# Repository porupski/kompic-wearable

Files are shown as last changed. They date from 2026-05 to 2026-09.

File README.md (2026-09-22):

# Kompic̄ &nbsp;·&nbsp; Mk1b

**Compact Open Multisensor Platform & Apparatus**

*/ˈkompitɕ/* — Croatian for "little computer" (and the word you'd only use for an actual friend, not a stranger).

A fully open-source, offline-first, ML-capable wrist-mounted sensor platform. The hardware collects. The firmware infers. You own everything.

> **Internal hardware version:** `iv8.0` — tracked in the docs to keep the PCBs matched across revisions.

Page: [https://porupski.github.io/kompic-wearable/](https://porupski.github.io/kompic-wearable/)

---

## What it is

Kompic̄ is a wrist-mounted sensor platform built around an **ESP32-S3** (dual-core, 8 MB PSRAM, 16 MB flash) with a sensor suite denser than any open-source watch, and enough on-device compute to run real neural networks on that data — sleep staging, sound classification, sensor fusion — all locally, all offline, all inspectable.

Currently on its second hardware revision, **Mk1b (`iv8.0`)**: all ten I²C sensors bring up clean, the AMOLED display and touch panel run a working LVGL interface, and GPS streams live fixes.

It is **not** a companion in the AI sense and **not** a phone accessory. It runs standalone. BLE is a capability, not a requirement. There is no cloud, no subscription, no account.

### Philosophy

- **Open source** — hardware (KiCad), firmware, ML models, and case design. Everything inspectable, modifiable, forkable.
- **Offline first** — works fully standalone. No phone, no cloud, no subscription.
- **Raw data access** — PPG waveforms, IMU streams, mic audio, environmental readings. Not just processed metrics.
- **ML-native** — the compute surplus exists specifically to run on-device inference.

---

## Hardware at a glance

| Domain | Detail |
|---|---|
| MCU | ESP32-S3 dual-core Xtensa LX7 @ 240 MHz, 8 MB PSRAM, 16 MB flash |
| Storage | MicroSD (128 GB+) |
| Connectivity | BLE 5.x |
| Display | 2.06" rectangular AMOLED, 45.6 × 37.3 mm glass, QSPI |
| PCBs | Two 1.0 mm 4-layer boards: main board + skin-facing daughter board |
| Case | Two-piece SLM titanium (Ti-6Al-4V), ~48 × 40 × 12 mm |
| Weight | 33 g watch body, 56 g with straps |
| Power | ~300 mAh LiPo, USB-C charging, fuel gauge |

### Sensor suite

| Sensor | Part | Measures |
|---|---|---|
| ❤️ Optical HR / SpO2 | MAX30101 | Heart rate, HRV, blood oxygen, PPG waveforms |
| 🏃 IMU | LSM6DSV16X | Accel, gyro, on-chip decision trees |
| 🔋 Fuel gauge | MAX17048G | Battery state-of-charge, cell voltage |
| 🌡️ Skin temperature | TMP117 | High-precision skin temp trending |
| 🧭 Magnetometer | LIS3MDLTR | Compass heading, magnetic anomaly |
| 🛰️ GPS | u-blox M10S | Position, velocity, atomic time sync |
| 🌍 Environmental | BME688 | Temp, pressure, humidity, VOC / air quality |
| 💡 Ambient light | VEML6030 | Lux level, display brightness |
| 🎤 MEMS microphone | MSM261DGT003 | Audio capture, noise level, sound classification |
| 📳 Haptics | ELV1411A + DRV2605L | Vibration patterns, alerts, smart wake |
| 🔦 Flashlight | White LED + BC847C driver | Utility light |
| 🚦 Status LED | RGB LED | Notification / mode indicator |

---

## Repository layout

```

kompic-wearable/
├── hardware/    KiCad schematics, PCB layout, production files   [CERN-OHL-S v2]
├── firmware/    ESP32-S3 dual-core firmware, ML models           [GPLv3]
├── case/        Onshape / 3D-printable case models               [CC BY-SA 4.0]
└── docs/        Documentation site (GitHub Pages) + images       [CC BY-SA 4.0]

```

---

## Project status

In active development. Hardware bring-up and verification underway for **Mk1b (`iv8.0`)**.

| Area | Status |
|---|---|
| Circuit + PCB | Mk1 done (schematics, power tree, KiCad source) - needs update to Mk1b |
| Fabrication + assembly | Mk1 done (JLCPCB process, BOM, production files) - needs update to Mk1b |
| Manual assembly | Planned |
| 3D models + case | Planned ([View on Onshape](https://cad.onshape.com/documents/2e7ed980a6b60d585006763f/w/61a5aff226ec4b8dea793e41/e/49d622626b42dd5951f83a04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)) |
| Firmware | In progress (I²C drivers, LVGL 9 display + touch UI, GPS UBX/NMEA parsing) |

Check the Development page for info on current stage of the project.

Documentation: **[https://porupski.github.io/kompic-wearable/](https://porupski.github.io/kompic-wearable/)**

---

## Author & License

Hardware, firmware, case, and webpage design by **Ivan Porupski**, 2026.

## License

Kompic̄ is released under three copyleft licenses, one per kind of material. All three keep the project open and require attribution — anyone may use, modify, build on, and even sell derivatives, **provided they keep their version equally open and credit the original author.**

| Part of the project | License | What it means in one line |
|---|---|---|
| **Hardware** (`/hardware`) | [CERN-OHL-S v2](https://ohwr.org/cern_ohl_s_v2.txt) | Make/modify/sell boards freely; distributed modifications must publish their full design files under the same license. |
| **Firmware** (`/firmware`) | [GPLv3](https://www.gnu.org/licenses/gpl-3.0.html) | Run/modify/redistribute freely; distributed modifications must publish full source under GPLv3. |
| **Docs & 3D / case** (`/docs`, `/case`) | [CC BY-SA 4.0](https://creativecommons.org/licenses/by-sa/4.0/) | Reuse/remix freely with credit; shared derivatives stay under CC BY-SA. |

GitHub displays **GPL-3.0** as the repository's headline license; the per-folder breakdown above is authoritative. See [`LICENSING.md`](LICENSING.md) for details.

**Copyright © 2026 Ivan Porupski.** Each contributor retains copyright on their own contributions; the whole project remains under the copyleft licenses above.

There is no separate commercial license and no contributor license agreement (CLA). Contributions are accepted under the same licenses as the files they touch (inbound = outbound).

---

## Contributing

Contributions are welcome. By submitting a contribution you agree it is licensed under the same license that already covers the file(s) you are changing (see table above). Keep copyright and license notices intact.

---

## Disclaimer

Kompic̄ is **not a medical device** and is not intended to diagnose, treat, or prevent any condition. All work with these electronics and lithium batteries is done at your own risk. The author and contributors are not liable for any direct, indirect, incidental, or consequential damages.

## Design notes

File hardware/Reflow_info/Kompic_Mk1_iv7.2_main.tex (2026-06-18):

\documentclass[11pt,a4paper]{article}
\usepackage[margin=20mm]{geometry}
\usepackage{graphicx}
\usepackage{booktabs}
\usepackage{array}
\usepackage{xcolor}
\usepackage{colortbl}
\usepackage{enumitem}
\usepackage{fancyhdr}
\usepackage{titlesec}
\usepackage{hyperref}
\usepackage{float}
\usepackage{eurosym}

% Colors
\definecolor{danger}{RGB}{180,30,30}
\definecolor{warning}{RGB}{200,120,0}
\definecolor{safe}{RGB}{30,120,30}
\definecolor{headerblue}{RGB}{30,60,110}
\definecolor{lightgray}{RGB}{240,240,240}
\definecolor{rowalt}{RGB}{248,248,248}

% Header/footer
\pagestyle{fancy}
\fancyhf{}
\fancyhead[L]{\small\textbf{Kompic Mk1 PCB iv7.2 — Reflow \& Assembly Reference}}
\fancyhead[R]{}
\fancyfoot[C]{\thepage}
\renewcommand{\headrulewidth}{0.4pt}

% Section styling
\titleformat{\section}{\Large\bfseries\color{headerblue}}{}{0em}{}[\vspace{-0.5em}\rule{\textwidth}{0.4pt}]
\titleformat{\subsection}{\large\bfseries}{}{0em}{}
\titleformat{\subsubsection}{\normalsize\bfseries}{}{0em}{}

% Danger/warning boxes
\newcommand{\dangerbox}[1]{\par\noindent\colorbox{danger!10}{\parbox{\dimexpr\textwidth-2\fboxsep}{%
\textcolor{danger}{\textbf{WARNING:}} #1}}\par\vspace{0.5em}}

\newcommand{\notebox}[1]{\par\noindent\colorbox{headerblue!8}{\parbox{\dimexpr\textwidth-2\fboxsep}{%
\textcolor{headerblue}{\textbf{NOTE:}} #1}}\par\vspace{0.5em}}

\setlength{\parindent}{0pt}
\setlength{\parskip}{0.4em}

\begin{document}

% ============================================================
% TITLE
% ============================================================
\begin{center}
{\LARGE\bfseries\color{headerblue} Kompic Mk1 PCB — Reflow \& Assembly Reference}\\[0.3em]
{\large by Ivan Porupski, 2026}
\end{center}

% ============================================================
% PAGE 1 — QUICK REFERENCE
% ============================================================
\section*{PAGE 1 — QUICK REFERENCE {\small(keep visible during reflow)}}

\subsection*{Step-by-Step Procedure}

\begin{enumerate}[nosep]
\item Verify baked paste on all pads; smear thin flux (NC-559-ASM) across pad areas — flux QFN/WSON center pads too. For the MEMS mic, flux pads \textbf{before} placing, keep flux out of the top port.
\item Place all ICs and connectors onto flux + baked paste (tweezers, magnification). \textbf{All parts go on now — single reflow pass.}
\item Photograph the populated board; \textbf{attach thermocouple} to board edge with kapton tape.
\item Place board on \textbf{cold} hot plate, run the profile below. Hands off once heating starts; let the cycle finish before handling.
\end{enumerate}

\subsubsection*{Reflow Profile}

\begin{figure}[H]
\centering
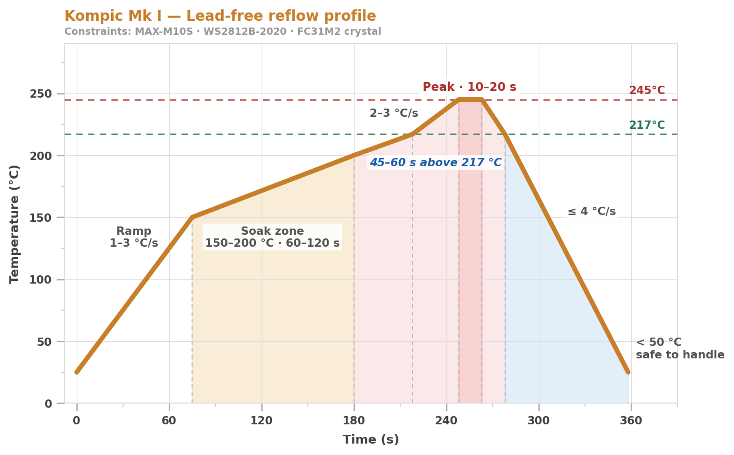
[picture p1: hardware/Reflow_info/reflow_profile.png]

\caption{\small Target reflow profile — binding constraints from MAX-M10S, WS2812B-2020, FC31M2 crystal.}
\end{figure}

\vspace{-0.5em}
\begin{table}[H]
\centering
\begin{tabular}{@{}ll@{}}
\toprule
\textbf{Phase} & \textbf{Target} \\
\midrule
Ramp to preheat & 1--3°C/s, 60--90s to reach 150°C \\
Soak & 150--200°C hold, 60--120s \\
Ramp to peak & 2--3°C/s \\
\rowcolor{danger!10} \textbf{Peak} & \textbf{245°C, hold 10--20s} \\
\rowcolor{danger!10} \textbf{Above 217°C total} & \textbf{45--60s} \\
Cooling & $\leq$ 4°C/s, hot plate off, natural cool \\
Safe to handle & Below 50--60°C \\
\bottomrule
\end{tabular}
\end{table}

\clearpage

\subsubsection*{During Heating — Rules}
\begin{itemize}[nosep]
\item \textbf{Hands off once heating starts.} No tapping, no nudging, no adjusting.
\item Below 217°C: if a part visibly shifts, you may carefully reposition with tweezers. This is a rescue, not routine.
\item Above 217°C (solder liquid): \textbf{\textcolor{danger}{DO NOT TOUCH ANYTHING.}} Surface tension self-centers parts.
\item If board gets bumped above 180°C: \textbf{let the cycle finish.} Never pull board off hot plate. Fix damage after cool-down.
\item Operate hot plate buttons with stable grip, controlled press, steady hand.
\end{itemize}

\subsubsection*{After Cooling}
\begin{enumerate}[nosep]
\item Visual inspection under magnification — every IC, every QFN edge, every pad
\item Compare against pre-reflow photo — check for shifted/rotated parts
\item Multimeter: resistance on every power rail to GND (3.2V, 1.8V, 5V, SYS, VBUS)
\item If all clear $\rightarrow$ initial power-on (see Page 2)
\item If short found $\rightarrow$ find and fix bridge before applying any power
\end{enumerate}

\subsection*{Floor Life — Bag Opening (all parts, single reflow)}

All MSL parts are placed in one pass, so open all moisture-sensitive bags on reflow day and reflow within their floor-life windows. Bake any part whose window was exceeded before placing.

\begin{table}[H]
\centering
\begin{tabular}{@{}llll@{}}
\toprule
\textbf{Part} & \textbf{MSL} & \textbf{Floor Life} & \textbf{Bake Recovery} \\
\midrule
ESP32-S3-WROOM-1U & 3 & $\sim$1 week at $<$30°C, $<$60\% RH & 125°C / 24hr \\
\rowcolor{danger!10} MAX-M10S & \textbf{4} & 72hr at $<$30°C, $<$60\% RH & 192hr @ 40°C, RH $<$5\% \\
\rowcolor{danger!10} VEML6030 & \textbf{4} & 72hr at $<$30°C, $<$60\% RH & 192hr @ 40°C, RH $<$5\% \\
\bottomrule
\end{tabular}
\end{table}

\dangerbox{Single reflow pass only. The board carries bottom-side components (notably the USB-C connector) that prevent a clean second hot-plate cycle — there is no second pass for any part. Every IC, including the MAX-M10S, must be placed and reflowed together. Plan placement so nothing is missed.}

% ============================================================
% PAGE 2 — BRING-UP SEQUENCE
% ============================================================
\newpage
\section*{PAGE 2 — BRING-UP SEQUENCE}

\subsection*{Initial Power-On}

\textbf{Current-limited LiPo test:}
\begin{itemize}[nosep]
\item 4$\times$ 200$\Omega$ 250mW resistors in parallel (= 50$\Omega$, 1W) in series with LiPo positive
\item Dead short draws 74mA max — nothing smokes
\item Measure voltage across board: $\sim$3.7V = no short, $\sim$0V = short present
\item ESP32 will NOT boot through this resistor (needs 300mA+) — this is shorts-only testing
\item Remove resistors for actual boot testing
\end{itemize}

\textbf{With USB power meter arrives:}
\begin{itemize}[nosep]
\item Power via USB-C through meter
\item Watch current draw in real time
\item BQ25619 boots first, brings up SYS rail, TPS62840 produces 3.2V
\item Normal idle current (no firmware): expect tens of mA
\item If current spikes to 1A+ immediately: unplug, find the short
\end{itemize}

\notebox{The TPS62840 is VSET-programmable. A 3.3V rail is possible; this board deliberately uses a \textbf{3.2V} rail, set by a \textbf{100k} VSET resistor (instead of 172k for 3.3V). All 3.3V-domain parts remain within spec at 3.2V.}

\subsection*{Verification Sequence}

\begin{enumerate}[nosep]
\item Check 3.2V rail with multimeter — TPS62840 working?
\item Check 1.8V rail — XC6206 working?
\item Connect USB-C, check if ESP32 enumerates as USB CDC device
\item If ESP32 alive $\rightarrow$ I2C bus scan on bus 1 and bus 2
\item Every device should respond at expected address:
\end{enumerate}

\textbf{Bus 1:} 0x10 (VEML6030), 0x1C (LIS3MDLTR), 0x48 (TMP117), 0x51 (PCF85063), 0x57 (MAX30101), 0x5A (CST9217), 0x6B (LSM6DSV16X), 0x76 (BME688)

\textbf{Bus 2:} 0x5A (DRV2605), 0x6A (BQ25619)

\notebox{The MAX-M10S GPS is \textbf{not on I2C} by default — it communicates over \textbf{UART1} (GPS-TX $\rightarrow$ GPIO17, GPS-RX $\rightarrow$ GPIO18). Verify it by opening the UART and confirming NMEA/UBX traffic, not via an I2C scan. (The M10S DDC/I2C interface at 0x42 exists as an option but is unused on this board.)}

\begin{enumerate}[nosep,start=6]
\item Missing I2C device = suspect bad solder joint on that IC
\item Open UART1 (GPIO17/18) and confirm the M10S streams NMEA/UBX — GPS solder-joint check
\item Test 5V boost (BQ25619 PMID) — enable via I2C, confirm 5V on rail
\end{enumerate}

% ============================================================
% PAGE 3 — HIDDEN PAD IC VERIFICATION
% ============================================================
\newpage
\section*{PAGE 3 — HIDDEN PAD IC VERIFICATION}

These ICs have pads entirely underneath — you cannot visually inspect joints.

\begin{table}[H]
\centering
\renewcommand{\arraystretch}{1.3}
\begin{tabular}{@{}p{3.2cm}p{3cm}p{8cm}@{}}
\toprule
\textbf{Part} & \textbf{Package} & \textbf{Verification Method} \\
\midrule
BQ25619 & WQFN-24 (4$\times$4mm) & Highest risk. Check I2C response @ 0x6A. Measure SYS rail voltage. Check for bridges between perimeter pads and center GND. \\
MAX-M10S & LCC-18 & Castellated + bottom pads. Verify by opening UART1 (GPIO17/18) and confirming NMEA/UBX output. No second reflow available — get it right first pass. \\
BME688 & LGA-8 & I2C response @ 0x76. Read chip ID register. \\
LSM6DSV16X & LGA-14 & I2C response @ 0x6B. Read WHO\_AM\_I register. \\
LIS3MDLTR & LGA-12 & I2C response @ 0x1C. Read WHO\_AM\_I register. \\
MSM261DGT003 & MEMS mic & No I2C — test by reading PDM data. Clock on GPIO47, data on GPIO48. \\
TMP117 & WDFN-6-EP (2$\times$2mm) & I2C response @ 0x48. Read temperature register ($\sim$room temp). \\
PCF85063ATL & DFN-10 & I2C response @ 0x51. Read seconds register (should increment). \\
\bottomrule
\end{tabular}
\end{table}

\dangerbox{For all hidden-pad ICs: before reflow, don't add extra paste on top of JLCPCB stencil paste. Just flux. Excess paste under QFN/LGA causes bridges.}

% ============================================================
% PAGE 4 — SOLDER & CONSUMABLES
% ============================================================
\newpage
\section*{PAGE 4 — SOLDER \& CONSUMABLES}

\subsection*{What's On The Board}

JLCPCB assembles 0402 passives using SAC305 lead-free paste at 255$\pm$5°C (economic assembly). No passive has a peak temp limit below 260°C — no concern.

JLCPCB also applies SAC305 solder paste to ALL remaining pads via stencil (verify in their gerber viewer that paste layer apertures exist for IC pads). Paste is baked (not reflowed) before shipping. Builder reflows these pads on the hot plate at 245°C in a single pass.

Solder jumpers are pre-connected with cuttable traces — no soldering needed during assembly. Cut trace to change default state.

\subsection*{Your Consumables}

\begin{table}[H]
\centering
\renewcommand{\arraystretch}{1.3}
\begin{tabular}{@{}p{3.5cm}p{3.5cm}p{1.8cm}p{5.5cm}@{}}
\toprule
\textbf{Item} & \textbf{Alloy} & \textbf{Melting} & \textbf{Use On This Board} \\
\midrule
NC-559-ASM flux & — & — & \textcolor{safe}{\textbf{YES}} — apply to baked paste, rework \\
Sn99.3/Cu0.7 wire 0.8mm & Lead-free & 227°C & \textcolor{safe}{\textbf{YES}} — hand solder, rework, bridges \\
SAC305 syringe paste & Sn96.5/Ag3.0/Cu0.5 & 217°C & \textcolor{safe}{\textbf{YES}} — backup paste, rework touch-up \\
Sn62.8/Pb36.8/Ag0.4 paste & \textcolor{danger}{\textbf{LEADED}} & 181°C & \textcolor{danger}{\textbf{DO NOT USE ON THIS BOARD}} \\
\bottomrule
\end{tabular}
\end{table}

\dangerbox{The board arrives with SAC305 (lead-free) paste from JLCPCB. Mixing leaded paste with lead-free creates a mixed alloy with unpredictable melting point (181--217°C range). Joints form weak grain boundaries and fail as intermittent connections. \textbf{Keep all solder on this board lead-free.}}

\notebox{Sn99.3/Cu0.7 wire and SAC305 paste are not identical alloys (wire has no silver, paste has 3\% silver). This is fine — the small composition difference is negligible during rework. Both are lead-free, both melt in the 217--227°C range.}

% ============================================================
% PAGE 5 — PRACTICE RUN
% ============================================================
\newpage
\section*{PAGE 5 — PRACTICE RUN \& TEMPERATURE CALIBRATION}

\subsection*{Before Your First Real Reflow}

\textbf{You must do at least one practice run.} Use a bare scrap board or one of your spare JLCPCB boards (no components).

\subsubsection*{Equipment Needed}
\begin{itemize}[nosep]
\item K-type thermocouple + reader ($\sim$\euro{}5--10) — \textbf{non-negotiable for 245°C ceiling with parts that die at 250°C}
\item Kapton tape to attach thermocouple to board surface
\end{itemize}

\subsubsection*{Procedure}
\begin{enumerate}[nosep]
\item Tape thermocouple tip flat against board surface, near center
\item Run your full reflow profile using hot plate buttons
\item Log thermocouple reading at each phase vs hot plate display reading
\item Calculate offset (e.g., hot plate says 245°C but board surface is actually 252°C $\rightarrow$ set hot plate to 238°C)
\item Run again with corrected settings, verify board surface hits 245°C $\pm$3°C
\item Note your hot plate button settings for each phase — these are your calibrated numbers
\end{enumerate}

\subsubsection*{What You're Calibrating}
\begin{itemize}[nosep]
\item Hot plate display accuracy (could be $\pm$10--15°C off)
\item Ramp rates (how fast does your specific plate heat and cool)
\item Cooling behavior (does it cool faster or slower than 4°C/s naturally)
\item Your button-pressing rhythm for each phase transition
\end{itemize}

\dangerbox{Without this calibration, you are guessing. A hot plate that reads 10°C low means you're actually hitting 255°C when you think you're at 245°C — and your M10S and WS2812B are over spec. With no second reflow available, a botched first pass is expensive — calibrate first.}

% ============================================================
% PAGE 6 — DAUGHTER PCB
% ============================================================
\newpage
\section*{PAGE 6 — DAUGHTER PCB REFLOW}

The daughter PCB (small round board) ships attached to the main PCB but should be reflowed separately.

\subsection*{Components on Daughter PCB}
\begin{itemize}[nosep]
\item MAX30101EFD+T (OLGA-14, 3.3$\times$5.6mm) — face down, HR/SpO2
\item TMP117AIDRVR (WDFN-6-EP, 2$\times$2mm) — skin temperature
\item DRV2605LDGSR (VSSOP-10) — haptic driver
\item Associated 0402 passives (JLCPCB assembled)
\end{itemize}

\subsection*{Profile}
Same as main board: 245°C peak, 45--60s above 217°C, $\leq$4°C/s cooling.

\subsection*{Risk Level}
Lower than main board. No MSL 4 parts, no WS2812B, no crystal. All three ICs tolerate 260°C. The 245°C profile gives generous margin. This is a straightforward reflow.

\subsection*{Inter-Board Connection}
After both PCBs are individually verified working, connect with 12 silicone wires (hand soldered to pads on each board).

% ============================================================
% PAGE 7 — REWORK PROCEDURES
% ============================================================
\newpage
\section*{PAGE 7 — REWORK PROCEDURES}

\subsection*{Solder Bridges (most common issue)}

\textbf{Method:} Soldering iron + flux + solder wick
\begin{itemize}[nosep]
\item Apply flux to bridged area
\item Press wick onto bridge with iron tip
\item Wick absorbs excess solder
\item Localized — only the affected pins experience thermal stress
\item This is always the first thing to try
\end{itemize}

\subsection*{Misaligned / Shifted IC}

\textbf{If visible pads} (castellated, gull-wing): reflow individual pins with iron, nudge into alignment with tweezers while last pin is still molten.

\textbf{If hidden pads} (QFN, LGA): must remove entirely. Use hot air rework station (controlled temp, focused nozzle). Pre-heat board on hot plate to 150°C, then hot air at 300--350°C on the IC until it lifts. Clean pads with wick + flux. Re-paste with SAC305 syringe, place new part, reflow locally.

\dangerbox{\textbf{Exception: MAX-M10S} — u-blox prohibits hot air. If M10S must be removed: pre-heat board on hot plate to 150°C, then use iron to release each castellated pad individually. Slow and tedious but possible for an LCC-18. Clean, re-paste, reflow locally.}

\subsection*{Dead IC (confirmed bad after electrical test)}

Same removal procedure as misaligned. Replace with spare from your doubles order. Localized rework only.

\dangerbox{There is \textbf{no second full reflow} on this board — bottom-side components (USB-C and others) prevent a clean second hot-plate cycle. All rework is \textbf{localized} (iron or focused hot air on the single failed part), never a whole-board re-reflow. Keep whole-board thermal cycles to the single production pass.}

% ============================================================
% PAGE 8 — COMPLETE COMPONENT REFLOW SPECS
% ============================================================
\newpage
\section*{PAGE 8 — COMPLETE COMPONENT REFLOW SPECIFICATIONS}

\subsection*{Binding Constraints Summary}

\begin{table}[H]
\centering
\begin{tabular}{@{}lll@{}}
\toprule
\textbf{Constraint} & \textbf{Value} & \textbf{Set By} \\
\midrule
Peak temperature & 245°C & MAX-M10S, WS2812B-2020 \\
Time above 217°C & 45--60s & MAX-M10S $\cap$ WS2812B-2020 \\
Time at peak ($\geq$240°C) & 10--20s & FC31M2 crystal \\
Max cooling rate & 4°C/s & MAX-M10S \\
\bottomrule
\end{tabular}
\end{table}

\subsection*{Full Component Table}

{\small
\begin{table}[H]
\centering
\renewcommand{\arraystretch}{1.15}
\begin{tabular}{@{}clllll@{}}
\toprule
\textbf{\#} & \textbf{Part} & \textbf{Package} & \textbf{MSL} & \textbf{Peak} & \textbf{Key Constraints} \\
\midrule
\rowcolor{danger!8}
1 & MAX-M10S-00B & LCC-18 & \textbf{4} & \textbf{245°C} & No hot air. Single reflow. No cleaning. \\
\rowcolor{danger!8}
2 & VEML6030 & — & \textbf{4} & 260°C & 72hr floor life. Bake if exposed. \\
\rowcolor{warning!8}
3 & ESP32-S3-WROOM-1U & Module & \textbf{3} & 235--250°C & Single reflow. Bake if open $>$1wk. \\
\rowcolor{danger!8}
4 & WS2812B-2020 & 2$\times$2mm & — & \textbf{245°C} & J-STD-020C. \\
5 & FC31M2-32.768kHz & SMD3215 & — & 260°C & 10s at peak. Cooling $\leq$6°C/s. \\
6 & Johanson 2450AT18A100E & Chip ant. & — & 260°C & 3 reflow cycles max. \\
7 & LSM6DSV16X & LGA-14 & — & 235--255°C & J-STD-020 (ST TN0018). \\
8 & LIS3MDLTR & LGA-12 & — & J-STD & J-STD-020. \\
9 & PCF85063ATL & DFN-10 & — & 260°C & Standard NXP. \\
10 & BME688 & LGA-8 & \textbf{1} & 260°C & 50$\mu$m min solder standoff. \\
11 & MSM261DGT003 & MEMS & — & 260°C & 5 reflow cycles OK. \\
12 & MAX30101EFD+T & OLGA-14 & — & 260°C & Max temp only stated. \\
13 & BQ25619RTWR & WQFN-24 & — & 260°C* & Assumed, TI QFN. \\
14 & TMP117AIDRVR & WDFN-6-EP & — & 260°C* & Assumed, TI WDFN. \\
15 & DRV2605LDGSR & VSSOP-10 & — & 260°C* & Assumed, TI VSSOP. \\
16 & TPD2E001DRLR & SOT-553 & — & 260°C* & Assumed, TI SOT. \\
17 & BSS138W & SOT-323 & — & 260°C* & Assumed, standard MOSFET. \\
18 & USB-C JS16T & 16-pin & — & 260$\pm$5°C & 60s $>$217°C, 5s $>$250°C. \\
\bottomrule
\end{tabular}
\end{table}
}
{\footnotesize *Not stated in datasheet — standard package assumption.}

\subsection*{MSL Handling Reference}

\begin{table}[H]
\centering
\begin{tabular}{@{}lll@{}}
\toprule
\textbf{MSL} & \textbf{Floor Life} & \textbf{Bake Recovery} \\
\midrule
1 & Unlimited & None needed \\
3 & $\sim$168hr (1 week) at $<$30°C, $<$60\% RH & 125°C / 24hr \\
4 & Per bag label ($\sim$72hr) at $<$30°C, $<$60\% RH & 192hr @ 40°C, RH $<$5\% \\
\bottomrule
\end{tabular}
\end{table}

\vfill

\subsection*{Notes}
\begin{itemize}[nosep]
\item Single reflow pass — bottom-side components (USB-C, etc.) preclude a second whole-board cycle. All parts, including MAX-M10S, go on together.
\item MAX-M10S communicates over \textbf{UART1} (GPIO17 TX / GPIO18 RX), not I2C. DDC/I2C @ 0x42 is available but unused.
\item All 0402 passives assembled and reflowed by JLCPCB at 255$\pm$5°C — their process, no passives at risk.
\item JLCPCB applies SAC305 solder paste to all remaining pads via stencil. Paste baked before shipping.
\item Pre-soldered 0402s re-melt during builder's reflow — board must be level and flat.
\item All solder on this board must be \textbf{lead-free}. Do not use leaded paste or wire.
\item Paste: SAC305 (Sn96.5/Ag3.0/Cu0.5), no-clean. Rework wire: Sn99.3/Cu0.7, 0.8mm. Flux: NC-559-ASM no-clean.
\item Core rail is \textbf{3.2V} via TPS62840 with a 100k VSET resistor (3.3V available with 172k; 3.2V chosen).
\item Boards are \textbf{1.0mm 4-layer}.
\end{itemize}

\vfill
\begin{center}\footnotesize
Kompic Mk1 — Reflow \& Assembly Reference \\
Revision iv7.0 \\
Ivan Porupski, 2026
\end{center}

\end{document}

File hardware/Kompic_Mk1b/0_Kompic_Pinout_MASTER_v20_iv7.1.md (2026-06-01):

# Smartwatch PCB — Unified Pinout (MASTER)
**ESP32-S3-WROOM-1U-N16R8 | CO5300 2.06" AMOLED + CST9217 Touch**
**Session v20 — 31 May 2026 — internal ref iv7.1**
*Single source of truth. Reconciled against the working bench driver (ground
truth), the current KiCad symbols/footprint, and the SLPIN/OLED_EN power
decision. Supersedes the dead Session-9 pinout and the wrong vendor display
schematic.*

---

# PART 1 — ESP32-S3 GPIO ASSIGNMENT

## Change history baked into this rev

| Signal | Old pin | Pin | Reason |
|---|---|-----|---|
| QSPI_CS | 46 | **10** | Working sketch drives CS on GPIO10 (FSPICS0 IOMUX) |
| MAX_INT | 10 | **7** | Displaced by CS; must stay on a clean RTC pin to wake |
| TimePulse | 7 | **46** | Gave up its RTC pin to MAX_INT; 1PPS needs no wake |
| TP-RST (touch) | 44 → 5 → **44** | **44** | Net back to 44 (east); freed GPIO5 for SCL_bus2 pairing |
| SCL_bus2 | 5 → 44 → **5** | **5** | Now west, paired beside SDA_bus2 (IO4) for routing |
| OLED_EN | 45 | **dropped** | Panel powered down via QSPI SLPIN (0x10), no GPIO |
| QSPI_TE | unwired | **45** | Reclaims the pin OLED_EN vacated |

> **Routing note (this rev):** SCL_bus2 and TP-RST were exchanged so both I2C
> buses sit as contiguous pairs — **bus 2 on IO4(SDA)/IO5(SCL), west edge**;
> **bus 1 on IO1(SDA)/IO2(SCL), east edge**. TP-RST (a driven output) takes the
> east boot-log pin GPIO44, which is boot-tolerant for a reset line.

> ⚠️ **OLED_EN drop is PROVISIONAL pending current measurement.** SLPIN
> (0x28 DISPOFF → 0x10 SLPIN) confirmed on the bench to blank the panel and
> wake cleanly, but panel sleep current was NOT yet measured (no meter on
> hand). If SLPIN standby current is too high for the battery budget, a
> hardware kill (FET on the panel supply, driven by a GPIO) returns — and TE
> loses GPIO45.

## Master Pinout Table

| GPIO | KiCad Label | Signal | IOMUX | RTC Wake | Boot Behavior |
|---|---|---|---|---|---|
| 0  | IO0  | DRV_EN | — | ✓ | **Strap (boot-mode), internal pull-UP only DURING reset.** Pull-up releases after boot — does NOT sustain enable at runtime. Drive as FW output. Jumper alt: pull EN at the DRV directly, freeing this pin. |
| 1  | IO1  | SDA (bus1) | — | ✓ | Clean. 5.1k→3V3. East edge |
| 2  | IO2  | SCL (bus1) | — | ✓ | Clean. 5.1k→3V3. East edge (paired with IO1) |
| 3  | IO3  | QSPI-RESET (DISP_RST) | — | — | **Strap: JTAG source-select. NO internal ESP pull.** No external resistor present — panel-side holds RST defined; FW drives it as output. Watch only the pre-init boot window if a cold-boot display fault ever appears. |
| 4  | IO4  | SDA_bus2 | — | ✓ | Clean. 5.1k→3V3. West edge |
| 5  | IO5  | SCL_bus2 | — | ✓ | Clean. 5.1k→3V3. West edge (paired with IO4). (was TP-RST) |
| 6  | IO6  | TP-INT_3V3 (touch INT) | — | ✓ | Clean. **Wake: tap.** West edge |
| 7  | IO7  | MAX_INT | — | ✓ | Clean. **Wake: PPG FIFO.** (was TimePulse) |
| 8  | IO8  | LSM_INT1 | — | ✓ | Clean. **Wake: raise-to-wake** |
| 9  | IO9  | QSPI-I2 (D2) | FSPIHD | ✓ | Clean. North edge |
| 10 | IO10 | QSPI_CS | FSPICS0 | ✓ | Clean. North edge. (was MAX_INT) |
| 11 | IO11 | QSPI-I0 (D0/MOSI) | FSPID | ✓ | Clean. North edge |
| 12 | IO12 | QSPI-CLK | FSPICLK | ✓ | Clean. North edge |
| 13 | IO13 | QSPI-I1 (D1/MISO) | FSPIQ | ✓ | Clean. North edge |
| 14 | IO14 | QSPI-I3 (D3) | FSPIWP | ✓ | Clean. North edge |
| 15 | IO15 | RTC_INT | — | ✓ | Clean. **Wake: alarm** |
| 16 | IO16 | BQ_BUTTON | — | ✓ | Clean. **Wake: button + ship-mode exit.** Dual-wire to BQ25619 QON |
| 17 | IO17 | M10-TX (→GPS RX) | U1TXD | ✓ | Clean |
| 18 | IO18 | M10-RX (←GPS TX) | U1RXD | ✓ | Clean |
| 19 | IO19 | D- | USB | — | Reserved (fixed USB) |
| 20 | IO20 | D+ | USB | — | Reserved (fixed USB) |
| 21 | IO21 | EC_SigA (encoder A) | — | ✓ | Clean. North edge. Crown encoder; wake-capable (bonus) |
| 35–37 | — | PSRAM (octal) | — | — | Unavailable (N16R8) |
| 38 | IO38 | SD_CLK | — | — | Clean (no RTC). East edge |
| 39 | IO39 | SD_CMD | — | — | Clean (no RTC). East edge |
| 40 | IO40 | SD_DAT0 | — | — | Clean (no RTC). East edge |
| 41 | IO41 | GPIO_FLASHLIGHT | — | — | Clean (MTDI), ext pull-down. East edge |
| 42 | IO42 | Sig_LED_Din (WS2812) | — | — | Clean (MTMS). East edge |
| 43 | TXD0 | EC_SigB (encoder B) | — | — | **Boot-log out ~3ms** — one spurious edge at boot, FW ignores pre-init. East edge |
| 44 | RXD0 | TP-RST_3V3 (touch reset) | — | — | **Boot-log RX.** Driven reset output — boot-log blip harmless. East edge. (was SCL_bus2) |
| 45 | IO45 | QSPI_TE | — | — | **Strap (VDD_SPI), internal pull-DOWN → LOW.** Panel-driven, NO external pull-up. Panel unpowered at boot → strap reads LOW correctly. North edge. (was OLED_EN) |
| 46 | IO46 | TimePulse | — | — | **Strap (boot-msg), internal pull-DOWN → LOW.** No pull-up at all; 1PPS idles low, GPS gated at boot → strap OK. North edge. (was QSPI_CS) |
| 47 | IO47 | Mic_CLK | — | — | Clean (no RTC), 3.3V domain on R8. North edge |
| 48 | IO48 | Mic_Dout | — | — | Clean (no RTC), 3.3V domain on R8. North edge |

## Physical edge grouping (footprint: antenna at SW, part rot 180°)

- **West (pads 1–14):** GND, 3V3, EN, SDA_bus2(4), SCL_bus2(5), TP-INT(6),
  MAX_INT(7), RTC_INT(15), BQ_BUTTON(16), M10-TX(17), M10-RX(18), LSM_INT1(8),
  D-(19), D+(20). → **I2C bus 2 paired here.**
- **North (pads 15–26):** QSPI-RESET(3), TimePulse(46), QSPI block (9,10,11,12,
  13,14), EC_SigA(21), Mic_CLK(47), Mic_Dout(48), QSPI_TE(45).
- **East (pads 27–40):** DRV_EN(0), SD(38/39/40), FLASHLIGHT(41), WS2812(42),
  EC_SigB(43/TXD0), TP-RST(44/RXD0), SCL(2), SDA(1), GND. → **I2C bus 1 paired
  here; encoder B + touch reset cluster here.**

## IOMUX

| Peripheral | GPIOs | Note |
|---|---|---|
| Display QSPI (SPI2/FSPI) | 9, 10, 11, 12, 13, 14 | CS on FSPICS0 (10) — full IOMUX |
| GPS UART (UART1) | 17, 18 | U1TXD / U1RXD direct IOMUX |

## Sleep Wake Sources (RTC GPIO, ≤21)

| GPIO | Signal | Trigger | Priority |
|---|---|---|---|
| 6  | TP-INT_3V3 | Tap to wake | Required |
| 7  | MAX_INT | PPG FIFO during sleep HR | Required |
| 8  | LSM_INT1 | Raise to wake | Required |
| 15 | RTC_INT | Alarm wake | Required |
| 16 | BQ_BUTTON | Button + ship-mode exit | **Required** |
| 21 | EC_SigA | Crown turn (optional) | Nice-to-have |

## Strapping / Boot-Sensitive Pin Audit

| GPIO | Strap role | Required @reset | Our signal | Idle state | OK? |
|---|---|---|---|---|-----|
| 0  | Boot mode | HIGH (int pull-up, boot-only) | DRV_EN | FW-driven output | ✓ |
| 3  | JTAG src  | none — NO int pull | QSPI_RESET | held by panel + FW output | ✓ |
| 45 | VDD_SPI | LOW (int pull-down) | QSPI_TE | LOW (no ext pull, panel off) | ✓ |
| 46 | Boot msg  | LOW (int pull-down) | TimePulse | LOW (no pull, GPS gated) | ✓ |
| 43 | U0TXD | boot-log out ~3ms | EC_SigB | — | ✓ blip harmless |
| 44 | U0RXD | boot-log RX | TP-RST (output) | driven | ✓ blip harmless on reset line |

## Signals NOT on a GPIO (poll / I2C / test pad only)

BQ_INT (poll via I2C bus 2 — no GPIO), BQ_STAT, SD_Cd, M10S_RST,
LSM_INT2, LIS_INT, LIS_DRDY, TMP_ALRT, VEML_INT.

## Critical Warnings

⚠️ **GPIO45 (QSPI_TE): NEVER add an external pull-up.** VDD_SPI strap, must
read LOW at reset. Panel drives TE but is unpowered at ESP boot, so the
internal pull-down sets the strap. An external pull-up breaks VDD_SPI
(flash/PSRAM voltage) selection.

⚠️ **GPIO46 (TimePulse): NEVER add an external pull-up.** Boot-msg strap,
must read LOW at reset. Currently has no pull at all — keep it that way.

⚠️ **GPIO0 (DRV_EN): internal pull-up is boot-only.** It does NOT hold the
haptic enabled at runtime — the pull-up releases after the ROM bootloader.
Drive GPIO0 as a firmware output to control DRV_EN, or use the jumper to pull
EN at the DRV directly (which frees this ESP pin).

⚠️ **GPIO3 (QSPI_RESET): JTAG-source strap, NO internal ESP pull, and NO
external resistor on this design.** RST is held defined by the panel side;
firmware drives GPIO3 as an output. Confirmed working from cold boot after
extended shelf storage. Only revisit if a cold-boot display fault appears.

⚠️ **GPIO7 (MAX_INT) is a wake source — keep it on a clean RTC pin.** Do not
relocate to 38–48 (no RTC, cannot wake).

⚠️ **NEVER put an I2C line on GPIO43 or GPIO44 (boot-log pins).** The ~3ms
boot-log activity would corrupt a live bus transaction. Only boot-tolerant
signals (encoder lines, driven resets) belong on 43/44 — which is exactly why
TP-RST (not SCL_bus2) lives on 44.

---

# PART 2 — AMOLED DISPLAY CONNECTOR

**CO5300 2.06" (PY206-W38-V2) | 24-pin Conn_02x12 (OK-14F024-04 receptacle)**
Traced from the PHYSICAL breakout (vendor schematic was wrong for this panel).
14 named pins; remainder GND / 3V3 / NC.

> ⚠️ Supersedes the old J1 (Conn_02x12_Counter_Clockwise). KiCad J1 redrawn
> to this layout — Side B numbered 24→13 (descending) to match the physical
> connector, so each table row shows the two pins that sit across from each
> other.

## Connector — physically opposite pins per row

| Side A pin | Signal | GPIO | ‖ | Side B pin | Signal | GPIO |
|:---:|---|:----:|:-:|:---:|---|:----:|
| 1  | QSPI_RESET (RST) | **3** | ‖ | 24 | GND | — |
| 2  | GND | — | ‖ | 23 | QSPI-I0 (D0/MOSI) | **11** |
| 3  | +3V3 | — | ‖ | 22 | GND | — |
| 4  | NC | — | ‖ | 21 | QSPI-CLK | **12** |
| 5  | +3V3 | — | ‖ | 20 | GND | — |
| 6  | +3V3 | — | ‖ | 19 | QSPI-I3 (D3) | **14** |
| 7  | GND | — | ‖ | 18 | NC | — |
| 8  | TP-RST_3V3 (touch reset) | **44** | ‖ | 17 | QSPI-I2 (D2) | **9** |
| 9  | TP-INT_3V3 (touch INT) | **6** | ‖ | 16 | QSPI_CS | **10** |
| 10 | SDA (bus1) | **1** | ‖ | 15 | QSPI-I1 (D1/MISO) | **13** |
| 11 | SCL (bus1) | **2** | ‖ | 14 | +3V3 | — |
| 12 | +3V3 | — | ‖ | 13 | QSPI_TE | **45** |

## Panel power — 3V3 ONLY

This panel has **no separate VBAT / boost-input pin**. Panel runs entirely
from **+3V3** (the multiple 3V3 pins above). There is no SYS/VBAT rail to the
display. The old "VBAT min 3.5V" note from the vendor schematic does NOT apply
to this panel — ignore it.

- Bench-confirmed working on 3V3.
- Watch for brownout at max brightness (boost works harder from 3V3 than from
  a higher rail) — first suspect if display glitches under high load.

## Power control — NO hardware enable pin

No OLED_EN pin exists on this panel. Display power-down is firmware-only:

- **Sleep:** `0x28` DISPOFF → `0x10` SLPIN (shuts OLED boost + source drivers)
- **Wake:** `0x11` SLPOUT → full re-init (COLMOD 0x77 etc.) → `0x29` DISPON → repaint

> ⚠️ Provisional until sleep current is measured (see Part 1 warning).

## Controller / interface facts (from working driver)

- Driver IC: **CO5300AF-51**, QSPI via SPI2/FSPI IOMUX.
- **COLMOD 0x77 (RGB888) mandatory** — RGB565 QIO lane mapping is broken on
  CO5300; pixels packed as 3 bytes R,G,B.
- Commands: instruction `0x02` (1-wire). Pixels: `0x32` (4-wire QIO), addr 0x003C00.
- Panel native 410 × 502, column offset 22.
- Touch: **CST9217**, I2C bus 1 @ **0x5A**, reg 0xD000, ACK 0xAB, 400kHz.

## Remaining verification

1. Connector mechanical position on the FPC ribbon edge — still tape-measure;
   refine via Onshape scan-and-trace (per display measurement workflow).
2. Confirm SLPIN sleep current once a meter is available (gates OLED_EN drop).

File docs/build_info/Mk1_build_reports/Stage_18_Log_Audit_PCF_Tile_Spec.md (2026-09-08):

# Stage 18 -- Log Audit, PCF I2C Contention, LVGL Tile Spec (Mk1b prep)

**Date:** 2026-08-27
**Board:** iv7.1 (Mk1 bench). Mk1b in fabrication; assembly plan documented below.
**Firmware baseline:** `iv7.1.f0.4.20` -> target `0.4.21+`.
**Status:** CLOSED 2026-08-28 at fw `0.4.24`. Log audit + PCF fix + tile spec + gesture + Mk1b delta plan + battery-management scoping all landed. Power refinement continues in Stage 19.

---

## 1. Session goals

The bench pipeline is now data-collection-ready. Real 5-min protocol runs
and PPG tuning wait a moment while three lighter items land:

**A. Log-level audit pass.** Apply `docs/build_info/reference_files/LOG_LEVEL_POLICY.md`
across the firmware. Move per-tick / per-row `ESP_LOGI` inside recording
loops down to `ESP_LOGD` so `LOGLEVEL WARN` on battery is genuinely quiet
without losing milestone events.

**B. PCF85063 I2C mutex timeout root-cause.** Stage 17 bench log showed
five sequential `W (321858) PCF85063: I2C mutex timeout` lines while
`TEMP_DUMP` was polling sensors on bus 0. The PCF driver's retry cadence
fights the sensor sweep. Understand the contention and pick a fix.

**C. LVGL tile mapping spec (Stage 17 §3.5).** Text-only, but weighted
toward Mk1b bring-up sequencing. The GPS coordinate tile is the day-1
must-have; the rest of the tile tree slots around it.

**Not in scope this stage:**
- Actual data collection (§A/B of Stage 18 rundown -- rolled forward).
- LVGL widget code (need panel to iterate against).
- Wrist-raise gesture (§3.4 -- next stage).

---

## 2. Plan

### 2.1 Log-level audit

Grep every ESP-IDF component for `ESP_LOGI` inside a `while ()` or
`for (;;)` block. Reclassify per the policy:

- Milestone events (mode entry / exit, session open / close) stay `INFO`.
- Per-tick / per-second status prints move to `DEBUG`.
- Retry / fallback paths move to `WARN`.
- `ERROR` reserved for operations that cannot complete.

Track the audit as a checklist in §4.1.

### 2.2 PCF85063 mutex contention

Read `pcf85063.c` and the RTC task's polling loop. Understand:

- What mutex is being taken (`g_i2c_mutex` on bus 0)?
- What holds it long enough to time out the PCF read (2000 ms suggests
  a long-sweep loop like `TEMP_DUMP` doing per-sensor reads back-to-back)?
- Is the PCF task's polling cadence too tight?

Candidate fixes in §4.2. Pick one, patch, log.

### 2.3 LVGL tile mapping spec + Mk1b bring-up plan

Deliver two artefacts in this document (§5):

1. **Tile tree.** Each tile: name, purpose, source data, primary widgets,
   how the encoder navigates to it.
2. **Mk1b assembly + firmware bring-up ordering.** GPS is the day-1
   target. Every intermediate flash checkpoint listed so the trip pack
   is a straight-line assembly + flash sequence.

---

## 3. Mk1b assembly plan (context)

Recorded here so future sessions do not lose the sequencing.

Ivan's plan for Mk1b once boards arrive:

1. **Reflow phase A:** all top-side components EXCEPT GPS, USB connector,
   and bottom-side components (DRV2605, SD holder). GPS chip is a
   single-unit, super-sensitive part saved for last -- see project memory
   `project-gps-chip-scarcity`.
2. **Bring-up A:** connect USB via test pads (not the connector). Verify
   every subsystem passes -- especially the **screen** (CO5300 QSPI +
   CST9217 touch). Screen was the Stage-16 blocker on iv7.1 and is the
   Mk1b acceptance gate. Also verify voltage rails, RTC, sensors, LSM,
   button, encoder, RGB, mic. Sensor suite must reach the same reliability
   iv7.1 currently shows.
3. **GPS pad check:** DMM probe the GPS footprint pads for +3V3, GND,
   TX/RX before soldering the chip. Any short kills the chip.
4. **Reflow phase B:** solder GPS, USB connector, then flip and solder
   the bottom components (DRV2605, SD, any other bottom-side parts).
5. **Bring-up B:** verify GPS UART traffic, DRV auto-cal (Stage 17
   retry helps here), SD mount.
6. **Trip pack.** From this point Ivan can iterate firmware only during
   travel; hardware is sealed.

For the firmware side, Mk1b bring-up needs:

- The `15_amoled_touch_test.ino` sketch, verbatim, as the first
  post-reflow-A flash. Confirms the receptacle footprint fix.
- The current iv7.1 ESP-IDF baseline (fw `0.4.20+`) with the display
  driver wired.
- A minimum-viable GPS tile that shows `lat, lon, fix, sats, HDOP`.
  This is the trip-ready deliverable.

---

## 4. Results

_(fill during session)_

### 4.1 Log audit checklist

Per-tick / per-second `ESP_LOGI` reclassified to `ESP_LOGD`:

- [x] `fc_modes_ppg_bcg.c:248` -- `[PPG_BCG] t=Xs bcg_bpm=...` (1 Hz status).
- [x] `fc_modes_lsm.c:144,148` -- `[BCG] t=Xs BPM=...` (1 Hz status).
- [x] `fc_modes_lsm.c:222` -- `STEPS t=Xs count=...` (1 Hz status).
- [x] `fc_modes_lsm.c:503` -- `[TAP-HB]` heartbeat (500 ms).
- [x] `fc_battery_test.c:328` -- `BLACKBOX #N` (per-sample).
- [x] `fc_battery_test.c:479` -- `BATT_TEST #N` (per-sample).

Deliberately kept at `INFO` (milestone / one-shot):

- `[BCG] active`, `[BCG] CSV closed`, `[BCG] exit -> STANDBY`.
- `[PPG_BCG] session start`, `start: pc_sync=YES ...`, `CSV closed`, `exit`.
- `STEPS session start`, `STEPS session end`.
- `MLC_COLLECT: LABEL_PICK phase`, `MLC label -> N`, `RECORDING label=N`,
  `MARK #N`, `RECORDING end`, `LABEL_PICK exit`, `mode exit`.
- `TAP_DBG start`, `[TAP-HOST] #N`, `[TAP-CHIP] SINGLE/DOUBLE cnt=N`,
  `[TAP-DBG] exit`.
- `shutdown watcher armed`, `shutdown commit at N ms`, `shutdown warn
  phase started`, `shutdown aborted`, `shutdown FIRE`, `shutdown warm-up`.
- All sensor-driver init / mode-config lines (BME, LSM, MAX, TMP, VEML,
  LIS, PCF, BQ). None fire inside a loop.
- `mode -> X (top)` from `field_capture.c` -- one line per encoder detent,
  a legit user action.

Effect on `LOGLEVEL WARN` (battery-only default): the recording loops
(BCG, PPG+BCG, STEPS, TAP heartbeat) go silent. Mode entry / exit
milestones still print at INFO. Only true warnings / errors survive at
WARN. Chatter drop is ~10x on the 5-min protocol.

### 4.2 PCF I2C mutex timeout root cause + fix

**Trace.** `task_rtc_fn` in `pcf85063.c` polls at 1 Hz and takes
`g_i2c_mutex` with a 50 ms timeout. `TEMP_DUMP` in `fc_cli.c` holds the
same mutex for the LSM die-temp read + MAX die-temp read each 500 ms
tick. Each read is a multi-register I2C transaction (~5-10 ms). The
window between mutex releases is not always <50 ms, so the RTC task
misses every second or third tick during `TEMP_DUMP` and every ~2 s
during a MULTI_LED PPG sweep.

**Fix.** Bumped the RTC task's mutex timeout to 300 ms (matches the
rest of the PCF driver, which already uses 300 ms for user-facing
reads) and dropped the miss log to `ESP_LOGD`. Rationale: a 300 ms
window is longer than any realistic bus-0 transaction, so a true
timeout still surfaces; expected contention during heavy sensor
sweeps stops spamming the console.

**Not fixed.** The underlying "TEMP_DUMP holds the bus per read" is
still there; it just no longer trips the timeout. If Stage 18 or later
adds heavier per-tick sensor sweeps, revisit -- either bump the PCF
timeout further, or teach `TEMP_DUMP` to release the mutex between
sensor reads (5x `take`/`release` per tick instead of 1x for 500 ms).

---

## 5. LVGL tile mapping spec (Stage 17 §3.5)

Documented here for Mk1b bring-up. No code lands until Mk1b hardware
arrives and the screen sketch verifies the footprint fix.

### 5.1 Top-level tile tree

Encoder rotation moves across top-level tiles horizontally. Encoder
click enters the tile (opens its detail view). Long-press-back or
double-tap-Z returns to top level.

| # | Tile | Purpose | Data source | Mk1b priority |
|--:|:---|:---|:---|:---|
| 0 | Home / clock | Big RTC time + date + battery %; icon strip for status | `broker_rtc`, `broker_battery` | Day 1 |
| 1 | **GPS** | lat, lon, fix status, sats, HDOP, altitude | `broker_gps` (`broker_gps_data_t` from `max_m10s`)| **Day 1** |
| 2 | Steps | Big step counter, session graph | `broker_steps` | Day 2 |
| 3 | Health | HR + SpO2 + skin temp (from PPG+BCG or standalone reads) | `broker_hr`, `broker_skin` | Day 2 |
| 4 | Environment | Air temp, RH, pressure, lux | `broker_env`, `broker_light` | Day 2 |
| 5 | Compass | Heading, calibration status | `broker_mag` | Day 2 |
| 6 | Motion / IMU | Acc / gyro live plot; tap counters | `broker_imu` | Day 3 |
| 7 | Recording | Enter FCM_* modes (MIC, PPG_BCG, MOT, ENV, LSM sub-menu, ...) | `field_capture` state | Day 3 |
| 8 | Settings | Brightness, log level, sync state, ship mode confirmation | `nvs_cfg` + system state | Day 3 |
| 9 | Flashlight | Torch on/off, brightness (encoder while active) | `flashlight` | Day 3 |

**Mk1b bring-up order.** Day 1 = tile 0 + tile 1. That is the trip
deliverable: the operator can see the time, battery level, and current
GPS coordinates. Day 2 onwards fills in the rest.

### 5.2 GPS tile spec (Day-1 deliverable)

The GPS tile has **two view modes**. Encoder click cycles between them
while the tile is open.

#### 5.2a "Under the hood" view (default when the tile opens)

Technical diagnostic view -- everything the operator needs to trust
the fix.

**Widgets:**

- Header: title "GPS" + fix status icon (red / yellow / green).
- Big rows: `lat`, `lon` with sign, six decimal digits.
- Sub-row: `alt` (metres), `sats N`, `HDOP D.D`, PDOP if the driver
  exposes it.
- Footer: last-fix age in seconds.
- **Raw console** at the bottom (scrolling text box, ~4 lines). Shows
  the last few NMEA / UBX sentences pulled by `max_m10s`. Mirrors the
  "raw console" pattern from the earlier prototype's GPS bring-up
  workflow -- the operator watches the sentences flow to confirm the
  antenna is actually receiving.

**Data update rate.** 1 Hz for the parsed values via `broker_gps_read()`.
The raw console appends per sentence, ring-buffered to the last N
lines (target N = 8; measure at bring-up).

**States:**

- `SEARCHING` -- broker `has_fix=false`, `sats > 0`. Yellow icon,
  "waiting" in the footer, sat count updates live.
- `LOCKED` -- broker `has_fix=true`. Green icon, lat / lon rows show
  values, footer prints "fix age Xs".
- `STALE` -- `has_fix=true` but `last_update_ms` older than
  `BROKER_GPS_TIMEOUT_MS`. Grey icon, values greyed out, footer
  "stale N s".

#### 5.2b "Photo" view

Commemorative photo shot. **The moment fixes; the numbers must survive
being photographed under sunlight and being cropped.**

**Layout:**

- Pure black background across the whole screen (LVGL: OLED off-pixel
  = zero draw; no dithering).
- **Very large white lat / lon** as the dominant elements, sized to
  fill the screen width to within the panel bezel. Each line one row.
  Six decimal digits, sign always shown, monospace face (LVGL Montserrat
  or the built-in mono) so digits don't jitter as they update.
- Time + date row above the lat / lon block, noticeably smaller
  (~30-40 %% of the coord row height). Format `YYYY-MM-DD HH:MM:SS UTC`.
- Nothing else -- no fix icon, no battery, no HDOP. Anything that
  photographs poorly is off. The idea is that the photo IS the proof;
  the numbers must be big and clean.

**Data update rate.** 1 Hz. No animation, no fade, no throb -- solid
white on solid black so the camera sensor does not have to hunt for
focus / exposure.

**Fix required?** No. The tile renders "no fix" in the coord positions
if the receiver is still searching. The intent is that Ivan opens the
tile only when he has a fix (he can confirm via the under-the-hood
view first), so the "no fix" case is rare and does not need a nice
fallback layout.

#### 5.2c Testing

Under a metal ceiling the antenna gets nothing. Bring-up outside once
the trip pack is sealed; interim testing may use `max_m10s` in "sim"
mode if the driver exposes one (verify at bring-up time). For photo
view specifically, verify: max coord font size on the CO5300 panel,
antialiasing quality, sunlight readability with the panel at full
brightness.

### 5.2d Plan B: fallback GPS tile on the Waveshare devboard

Documented so the pivot is a single day of firmware work if Mk1b
turns up with another screen fault. Waveshare ESP32-S3 dev board with
its built-in touchscreen, plus the (working) GPS module Ivan already
has soldered on the earlier prototype. Photo view only -- no
under-the-hood console, no other tiles. Deliverable: still a working
commemorative GPS photo. Details tracked in project memory
`project-photo-gps-plan-b`.

### 5.3 Home tile spec (Day-1 deliverable)

**Widgets:**

- Very large time (HH:MM in centred bold, ~120 pt).
- Below: date `YYYY-MM-DD`, day of week.
- Right edge: vertical status strip -- battery %%, USB / charging icon,
  GPS-fix dot, SD-card dot.

**Data update rate.** 1 Hz.

### 5.4 Encoder + tap-Z navigation

- **Encoder rotate** in top-level: move between tiles (horizontal
  swipe emulation).
- **Encoder click** in top-level: enter the tile (open the detail
  view). In a detail view: mode-specific action (start recording,
  reset counter, ...).
- **Tap-Z double** (LSM chip event): return to top level.
- **Button single click** in tiles: reserved for tile-local action.
- **Button hold 4 s**: ship mode (unchanged from Stage 17).

### 5.5 Refresh + performance targets

- LVGL tick: 5 ms.
- Tile-refresh cadence: 200 ms (matches broker poll cadence).
- No LVGL redraw during recording sessions to keep the SD write path
  fast (recording modes call `lvgl_port_lock` before entering to
  suspend the refresh task; unlock on exit).

### 5.6 What is NOT in Mk1b Day-1 scope

- Real-time signal plots (BCG waveform, PPG waveform). Day 2 at
  earliest.
- Notifications overlay (`ui_notif_overlay.h` exists but no producer
  wired). Day 3.
- Blue-light overlay (Day 2 tunable).
- Fusion / dead-reckoning overlay on GPS. Post-trip.

---

## 6. Next steps

**Immediate (Ivan bench, fw 0.4.21):**

- Flash and confirm: `LOGLEVEL WARN` on battery keeps the console
  quiet during a `FCM_PPG_BCG` session. Mode entry / exit lines still
  print. `LOGLEVEL INFO` restores per-second status.
- Verify `TEMP_DUMP` no longer prints five `PCF85063: I2C mutex
  timeout` lines in a row. A single occasional DEBUG log during a
  MULTI_LED sweep is expected and now hidden at INFO+.

**Rolls forward to a future stage:**

- Actual 5-min protocol run + PPG PA / SR tuning (was Stage 18 §A/B in
  the rundown; parked at Ivan's request).
- Wrist-raise gesture (§3.4 from Stage 17).
- LVGL tile *implementation* -- gated on Mk1b arrival.
- BQ25619 real telemetry -- gated on Mk1b hardware.

**Wrap** when Ivan is happy with the bench behaviour: run
`python docs/build_info/reference_files/make_archive.py stage-18-audit-tiles`
and close the stage.

---

## 7. Second batch (0.4.22) -- wrist gesture + Mk1b prep

Landed while Ivan verified `0.4.21` on the bench (2026-08-27 evening).

### 7.1 §3.4 wrist gesture wire-up

`lsm6dsv16x.c::task_imu_fn` now runs a simple LPF-on-Z-axis wrist detector:

- Every 20 ms tick, `s_az_lpf_g = 0.8 * s_az_lpf_g + 0.2 * (accel_z / 9.81)`.
  ~200 ms time constant -- fast enough for a wrist raise, slow enough to
  reject taps.
- Hysteresis bands: `>= +0.55 g` -> `WRIST_RAISE`, `<= -0.35 g` -> `WRIST_DOWN`.
  Between the bands the state is sticky (no publish).
- Publishes to `g_imu_gesture` via `data_broker.h`. Two counters
  (`s_gesture_changes`, `s_gesture_last_ms`) surface via new public
  accessors (`lsm6dsv16x_gesture_az_lpf_g`, `..._change_count`,
  `..._last_change_ms`) so the CLI can display + tune.

New CLI verb `GESTURE` in `fc_cli.c` dumps:

```
[GESTURE] current=WRIST_RAISE (1)  az_lpf=0.912 g  changes=4  last_change_age=1230 ms
```

Bench test convention: component side up = RAISE, upside down = DOWN.
Physical watch orientation on Mk1b may want a different axis -- adjust the
`WRIST_*_ON_G` thresholds in `lsm6dsv16x.c` after Mk1b bring-up if needed.
No `rgb_policy` coupling (deferred per Stage 17 §4.11).

### 7.2 AMOLED sketch audit (Mk1b bring-up)

`firmware/arduino/15_amoled_touch_test/15_amoled_touch_test.ino` reviewed
against every relevant memory rule -- all pass:

- Pin annotations line-by-line vs master pinout v20; TOUCH_RST 5 -> 44
  delta explicitly called out (GPIO5 is SCL_bus2 for BQ).
- Ship-mode handler present -- double-click on GPIO16 enters
  `enter_ship_mode()` via BQ25619 (matches `feedback-sketches-need-shipmode`).
- USB CDC guard note explicitly documents why `ARDUINO_USB_MODE == 1` is
  not needed (no TinyUSB use in this sketch -- matches `feedback-tinyusb-guard`).
- CO5300 driver details preserved from the standalone breakout: COLMOD
  0x77, instruction 0x02 for commands, opcode 0x32 for pixel writes.
- DISP_RST on GPIO3 (JTAG strap) noted as safe per master pinout v20.

**No sketch changes needed.** It flashes verbatim as the first post-
reflow-A verification on Mk1b.

### 7.3 iv7.1 -> Mk1b firmware delta plan

New reference at
`docs/build_info/reference_files/IV71_TO_MK1B_FIRMWARE_DELTA.md`. Ten
sections covering version bump, pin diffs, display + LVGL uncomment,
GPS enable, tile registry seed, rgb_policy note, shutdown, BQ, Day-1
bring-up checklist, and post-trip cleanup items.

Highlights:

- **Vbat ADC** moves off GPIO18 (iv7.1 prototype override, ADC2_CH7)
  onto whatever the Mk1b schematic wires (ADC1_CH8 default). Frees
  GPIO18 for its intended master-pinout use: GPS UART RX. See memory
  `project-vbat-on-gpio18`.
- **Display + LVGL** already exists as commented-out block in
  `main.c` (lines 32-34 and 115-124). Uncomment + wire tile registry.
- **GPS enable** in `boot_tasks.c` line 59 is a single un-comment;
  `max_m10s_init()` and `task_gps_fn()` are already implemented and
  the UART pins (TX=17, RX=18, PPS=46) match master pinout v20.

Version target for Mk1b line: `0.5.0` (fresh minor to make audit
grepping easy).

### 7.4 Firmware version

`0.4.21` -> `0.4.22`.

## 8. Third batch (0.4.23) -- bench findings from 0.4.22

### 8.1 GESTURE stuck at NONE (root cause)

`task_imu_fn` short-circuits when `broker_imu_get_enabled()` is false.
At boot only RTC / battery / haptic were always-on; the IMU task
looped without ever calling `gesture_update`, so `s_az_lpf_g` stayed
0.0. Fix: `boot_hw_init.c` now enables `broker_imu` alongside the
other always-on brokers. Cost is one 50 Hz I2C burst on bus 0 --
negligible next to any sensor mode and required for the gesture to
publish continuously.

### 8.2 GESTURE UX -- live log on every change

Ivan asked for a live monitor without polling `GESTURE` by hand. Added
an `ESP_LOGI(TAG, "[GESTURE] %s -> %s (az_lpf=%+.2f g)")` inside
`gesture_update` on every hysteresis transition. Naturally rate-limited
by the hysteresis + LPF -- flipping the board fires one line, not
spam. The `GESTURE` CLI dump is kept for one-shot inspection.

### 8.3 ws2812 mutex fix (RMT race)

`E rmt: rmt_tx_enable(768): channel not in init state` in a burst of
three pairs on `ppgbcg` entry. Root cause: `rgb_policy`'s esp_timer
callback (Core 0) and the field_capture task (Core 1) both call
`ws2812_push` beneath `ws2812_set_color`. Without serialisation, one
caller's `rmt_enable -> rmt_transmit -> rmt_tx_wait_all_done -> rmt_disable`
sequence gets tangled with the other's. Fix: added `s_tx_mutex` in
`ws2812.c` created in `ws2812_init()`, taken at the top of `ws2812_push`
with a 50 ms timeout and released at the bottom. Zero API change,
zero mode-code change.

### 8.4 "Unplug USB and re-hold" message wrong on uptime-cap fire

`fc_shutdown.c::watcher_ship_mode` is called from both the user 4 s
hold AND the 15 min autonomous uptime-cap fire. The old warn said
"unplug USB and re-hold to actually ship" -- correct for the user
path, misleading for the uptime cap (nobody held anything). Rewrote
to "Unplug USB to actually ship" -- neutral to both triggers. Same
recording-abort + LED-off behaviour otherwise.

### 8.5 GPS tile spec extended -- two view modes

Under Stage 18 §5.2, the GPS tile is now specified as two-mode:

- **Under-the-hood view** (default) -- fix status icon + lat/lon +
  alt + sats + HDOP + last-fix age + a scrolling raw-console pane at
  the bottom showing the last N NMEA / UBX sentences from `max_m10s`.
  Diagnostic view Ivan trusts before committing to a photo.
- **Photo view** -- pure black background, very large white lat/lon
  filling the screen width, smaller time+date row above. Nothing else.
  The output is meant to be photographed as commemorative proof of
  when + where the picture was taken.

Encoder click cycles between the two while the GPS tile is open.

### 8.6 Plan B for GPS-photo tile (fallback)

Documented in project memory `project-photo-gps-plan-b`. If Mk1b
turns up with another screen fault, Ivan pivots to a Waveshare ESP32-S3
touchscreen devboard running the (still working) GPS module from the
earlier prototype. Photo view only. Shelved unless triggered.

### 8.7 Firmware version

`0.4.22` -> `0.4.23`.

**Bench checklist for `0.4.23`:**

- Boot: expect `[GESTURE] NONE -> WRIST_RAISE (az_lpf=+0.9x g)` within
  a second (bench prototype sits component-side-up).
- Flip it: expect `[GESTURE] WRIST_RAISE -> WRIST_DOWN (az_lpf=-0.9x g)`.
- Flip back to raise, then park at 45 deg -- state should stay
  `WRIST_RAISE` (hysteresis holds it).
- `mode -> ppgbcg` (click): expect NO burst of `rmt:` errors before
  the "session start" line.
- Wait 15 min tethered: shutdown-fire message reads "Unplug USB to
  actually ship" instead of the old "and re-hold" wording.

---

## 9. Fourth batch (0.4.24) -- gesture polarity, BATT_TEST regression, RGB idle real-off

### 9.1 Gesture polarity flipped

Bench 2026-08-27: screen-up on the table reads `az_lpf ~ -0.9 g`, not
`+0.9 g`. Ivan's bench iv7.1 mounts the LSM with Z pointing away from
the panel face. Flipped `WRIST_RAISE_ON_G` to `-0.55 f` and
`WRIST_DOWN_ON_G` to `+0.35 f`, and swapped the comparison direction
in `gesture_update()`. Mk1b's enclosure may want the polarity flipped
again -- retune with the live `[GESTURE]` log after first bring-up.
Two-line change; no behavioural risk.

### 9.2 BATT_TEST regression fix

`0.4.23` enabled `broker_imu` at boot to make the gesture publish
continuously. That broke the "sensors default parked" assumption in
`run_battery_test_mode()`. Fix: call `park_all_modal_sensors()` at
BATT_TEST entry. The batt_test CSV now shows `sensors_on=0xC0`
(BAT + RTC only) as intended.

### 9.3 RGB idle -> real OFF

`rgb_policy.c::paint_scaled` now caches the last RGB and skips the
`ws2812_set_color` call when unchanged. Big win in the OFF phase
(25 s+ since activity): the previous code fired an RMT transmit every
50 ms writing `(0,0,0)` -- 20 pointless wakes/second. Now the phase
paints once on entry and stays silent. Same optimisation kicks in
during the solid preview (0..5 s) where colour does not change per
tick. Only the pulse and fade phases keep the tick active.

### 9.4 Firmware version

`0.4.23` -> `0.4.24`.

---

## 10. Battery-management roadmap

Ivan reports 2-3 hr runtime; wants double digits. Current baseline
average draw is roughly 70-150 mA depending on activity -- expected
wearable-idle should be 5-15 mA. This section is the map from where
we are to where we want to be, in dependency order.

### 10.1 Where we already are

| In place | Where |
|:---|:---|
| DFS 40..240 MHz + light-sleep | `boot_pm.c` |
| Modal sensors parked by default | `boot_hw_init.c` + `wake_sensors_for_mode()` |
| Recording mode wakes only what it needs | `fc_common.c::wake_sensors_for_mode()` |
| SD unmounts between rows in BATT_TEST | `run_battery_test_mode()` |
| VBUS-aware PM lock | `run_battery_test_mode()` (batt-test only) |
| RMT PM lock scoped per-transmit | `ws2812.c::ws2812_push()` |
| ws2812 skips repeat colours (Stage 18 §9.3) | `rgb_policy.c::paint_scaled()` |
| Boot uptime cap forces ship after 15 min | `fc_shutdown.c::SHDN_MAX_UPTIME_MS` |
| `BATT_TEST` mode + `BLACKBOX` telemetry logger | `fc_battery_test.c` |
| `PM_DUMP` CLI | `fc_cli.c` (needs `CONFIG_PM_PROFILING=y`) |

### 10.2 Unknown drainers -- measure before cutting

None of the below is worth guessing at. Overnight `BATT_TEST` run
produces the ground truth. The plan:

1. Ivan flashes `0.4.24`.
2. `BATT_TEST ON` + `REBOOT` + unplug USB.
3. Walk away. Wake up to a `/sd/data/battery/batt_XXXX.csv` with ~8600
   rows if the pack ran a full 24 h at 10 s cadence, fewer if it
   died earlier.
4. Plot `vbat_adc_mv` vs `t_ms` -- discharge curve. Plot `idle_pct`
   vs `t_ms` -- tells us how much of each 10 s window the CPU spent
   in light-sleep. High `idle_pct` (> 90 %%) means we are already
   close to the floor. Low `idle_pct` (< 50 %%) means something is
   keeping a PM lock and we can hunt it.
5. Also plot `cpu_mhz` -- if it hangs at 240 MHz, DFS is being
   defeated by a lock somewhere.

### 10.3 Likely culprits after 10.2 measurements

**If `idle_pct` is high but runtime is still short:**
- The floor is set by hardware quiescent -- LSM6DSV16X active+gyro,
  MAX30101 shutdown vs stop, VEML6030 active, BME688 continuous.
- Fix: audit each sensor's parked-state power draw against datasheet.
  Some drivers may not be putting the chip in real shutdown when the
  broker "disables" them.

**If `idle_pct` is low:**
- Something is holding a PM lock. `PM_DUMP` at various times reveals
  which one. Candidates in rough likelihood order:
  - `rgb_policy` esp_timer (fires every 50 ms) -- but the tick itself
    is short; only a lock issue if the timer callback grabs one.
  - USB-Serial-JTAG driver holding `NO_LIGHT_SLEEP` when nothing is
    plugged. `usb_serial_jtag_is_connected()` should be false; verify.
  - RMT (WS2812) rejigged in `0.4.10` but check again with `PM_DUMP`.
  - I2C0 / I2C1 drivers -- polling tasks (RTC, LSM, MAG, BME, VEML)
    each fire I2C which takes brief CPU-max locks.

### 10.4 Then, targeted cuts (in dependency order)

- **CPU freq cap** during idle STANDBY: DFS should already handle
  this, but if it does not, add an explicit `esp_pm_configure` pass
  to lower `CPU_MAX` during idle.
- **LSM ODR reduction**: the driver forces 240 Hz HP accel for tap.
  For non-recording idle, drop to 12.5 Hz. Wake back up on tap or
  on entering a mode that needs high ODR.
- **MAX30101 real shutdown**: the driver has `max30101_set_shutdown`
  -- confirm it is called on `broker_hr_set_enabled(false)`. Even in
  SpO2 mode the LEDs eat 20+ mA if the chip is not truly shut down.
- **Poll cadences**: BME688 and VEML6030 at their default rates each
  wake the CPU every few hundred ms. Slow them down when parked.
- **BME688 forced mode instead of continuous** when just showing air
  temperature (no gas conductivity).
- **Encoder pullups** left enabled in idle -- fine when the switch
  is open; on the ALPS EC05E in a detent position, one line is
  grounded, so a pull-up sources current continuously. Estimate
  ~10 uA; not a real problem. Leave alone.

### 10.5 "Battery test + BCG (no PPG)" mode -- design sketch

Ivan asked whether we can do a combined test: sleep -> read one BCG
sample burst -> log -> sleep. The physics:

- BCG needs ~1..15 Hz spectral energy. Detection wants at least 25 Hz
  samples so we can HP filter without aliasing.
- To sleep between samples we need bursts, not continuous streaming.
  Wake, capture 5 s of accel at 25 Hz (125 samples, ~10 s including
  wake latency), sleep 60 s, repeat. Every hour we get 60 samples.
- Beat detection on 5 s bursts is possible but noisy -- HR variance
  depends on posture, breathing, motion. Acceptable for "am I still
  alive over 12 hours" but not for HRV work.

Whether this is worth building depends on 10.2 measurements: if the
current baseline BCG-continuous drain is already close to the
"burst + sleep" projection (limited by MCU + LSM shutdown / wakeup
overhead), the burst mode buys little. Defer until after the drain
curve is in hand.

### 10.6 SD card power impact

Direct answer to Ivan's "is SD storage the problem": **not usually**,
if we play the cards right. The BATT_TEST loop already unmounts
between samples -- the card is inactive most of the time. During
recordings the card is mounted continuously and burst-writes; the
card typically pulls 50-100 mA during a write (~10 ms per row at
1 KB) and drops to ~2 mA between. So per-row fsync at 200 Hz would
be a disaster (card never sleeps); the current 1 Hz fsync in
`FCM_PPG_BCG` is fine.

For very long unattended sessions (hours): consider unmounting the
card between batches (BATT_TEST already does this). Never leave the
card mounted while the whole system is meant to be idle.

### 10.7 Tonight (overnight drain)

Single command sequence:

```
BATT_TEST ON
REBOOT
```

Then unplug USB, put the pack on the desk, walk away. The device
wakes at 10 s cadence, samples, writes, sleeps. Cyan LED blip on
each sample confirms it is alive. Wake up in the morning, plug the
USB back in, run `BATT_TEST OFF` + `REBOOT`, pull the SD card, and
plot `vbat_adc_mv` and `idle_pct` vs `t_ms`. Everything from Stage
18 §10.3 depends on that curve.

### 10.8 Gesture recording + MLC -- parked

Ivan's aside during this session:

- Wrist gesture as a full state-machine would be nice but is not a
  blocker; the accel-Z LPF is enough for wrist-off in `rgb_policy`.
- MLC-based classification would be great, but the earlier
  still-vs-walking recordings are unlabeled and Ivan will need to
  plot to identify them again. Doable but expensive without a
  screen.
- Button-as-marker for gesture-record sessions (start/end) with RGB
  feedback would be a self-contained tool. Slots into a later stage
  once the screen is up on Mk1b (so we can also display the
  recording state).

Parked. Revisit after Mk1b bring-up if the trip pack is stable.

---

## 11. First BATT_TEST snapshot (fw `0.4.24`, USB plugged)

Ivan flashed and ran a short USB-plugged snapshot to sanity-check the
telemetry pipeline before the overnight drain.

**Ammeter (USB plugged):**
- Non-BATT-mode standby: 105 mA
- BATT_TEST standby (fw 0.4.24): **94 mA**

Delta is the always-on IMU + boot polling settling down. Both numbers
are still far above the 5-15 mA wearable-idle target -- expected,
because the plugged-in `batt_test_vbus` PM lock holds
`NO_LIGHT_SLEEP` and stops light-sleep entering. On battery this lock
lifts; the drain baseline drops meaningfully.

**PM_DUMP after ~215 s of BATT_TEST (USB plugged):**

```
Name            Type            Active  Total_cnt  Time(us)     Time(%)
batt_test_vbus  NO_LIGHT_SLEEP  1       1          211 920 882  99 %
i2s_driver      APB_FREQ_MAX    0       0          0            0 %
sdmmc           APB_FREQ_MAX    0       23         217 432      1 %
rmt_0_0         CPU_FREQ_MAX    0       306        21 823       1 %
ws2812          APB_FREQ_MAX    0       306        24 564       1 %
i2c_driver      APB_FREQ_MAX    0       883        387 632      1 %
i2c_driver      APB_FREQ_MAX    0       291        188 091      1 %
rtos1           CPU_FREQ_MAX    0       213 600    30 624 211   15 %
rtos0           CPU_FREQ_MAX    1       222 578    33 341 338   16 %

Mode stats:
Mode      CPU_freq    Time(us)      Time(%)
SLEEP     40 M        2 450 508     1 %
APB_MIN   40 M        148 192 977   68 %
APB_MAX   80 M        526 188       0 %
CPU_MAX   240 M       64 074 478    29 %

light_sleep_counts: 100    light_sleep_reject_counts: 0
```

**Reading the dump:**

- `batt_test_vbus` NO_LIGHT_SLEEP at 99 % is the reason SLEEP mode is
  1 %. When USB unplugs this lock releases and SLEEP grows.
- `light_sleep_counts: 100` with zero rejects confirms the sleep path
  is proven -- when the lock lifts, sleep engages cleanly.
- DFS works: 68 % of active time at 40 MHz (APB_MIN), 29 % at 240 MHz.
- `rtos0` and `rtos1` account for the bulk of CPU_FREQ_MAX grabs
  (~30 % total). That is application-task pressure. Which tasks
  specifically -- Stage 19 with per-task profiling.
- `sdmmc` fires 23 times (matches sample count) for ~200 ms total
  -- ~10 ms per row. SD is not the drain culprit here.
- `rmt_0_0` and `ws2812` each fire 306 times, ~25 ms total -- the
  cyan blip is essentially free. Answer to Ivan's estimate ask:
  RGB is ~0.04 mAh across 3 hours. Rounding error.

**DRV state check.** DRV2605 is NOT in real shutdown -- it is in
`INTTRIG` mode (playback-ready), which draws ~0.5-1 mA continuously.
Real shutdown mode (STANDBY bit set or MODE=0x40) is ~5 uA. Toggling
between these on `haptic_play` boundaries is a Stage 19 win.

**LSM state check.** Currently 240 Hz HP accel + gyro for tap
detection + BCG. ~500-750 uA. Datasheet floor for
gesture-only paths: low-power mode 1 at 12.5 Hz accel-only -- 6.5 uA.
Not a rounding error; a real ~500 uA cut is available.

## 12. Small policy tweaks landed in `0.4.24` post-snapshot

- **BATT_TEST per-sample log restored to INFO** (was demoted to DEBUG
  in the Stage 18 log audit). During a drain test the operator wants
  vbat + idle_pct on every 10 s tick; that is not "chatter", that is
  the point. Reordered fields so `vbat=NNNNmV [CHG]` leads and the
  ISO timestamp trails. BLACKBOX telemetry stays at DEBUG (it is
  background instrumentation, not a live feed).

## 13. Wrap

Stage 18 closes at fw `0.4.24`.

- Data-collection pipeline (Stage 17 §3.1) verified twice more --
  `ppgbcg` still writes clean CSVs, notebook still loads.
- Log-level policy authored (`LOG_LEVEL_POLICY.md`), first audit pass
  landed, per-tick chatter reclassified.
- PCF I2C mutex timeout root-caused + fixed.
- LVGL tile mapping spec written with two-mode GPS view (under-the-
  hood + photo). Plan B (Waveshare fallback) documented in memory.
- Wrist gesture wired (LPF on accel-Z + hysteresis, polarity flipped
  for the bench prototype, live log on every transition).
- iv7.1 -> Mk1b firmware delta plan written.
- AMOLED touch-test sketch audited against every memory rule --
  passes as-is for Mk1b first-flash.
- Battery-management scoping done; overnight drain measurement is the
  gate on any code cuts.
- One PM_DUMP snapshot captured for baseline.

**Rolled forward to Stage 19:**

1. Overnight drain measurement (Ivan runs tonight; morning has the
   discharge curve + `idle_pct` over time).
2. `PM_DUMP` at multiple times during a drain to identify the
   `rtos0` / `rtos1` CPU_MAX holders.
3. Profiling infrastructure -- a real telemetry harness we can point
   at any future power-cut hypothesis.
4. `GESTURE ON`/`OFF` CLI + NVS -- gesture becomes opt-in, LSM stays
   in low-power mode by default.
5. DRV real shutdown between plays.
6. MAX30101 real shutdown between uses.
7. LSM low-power mode when tap + BCG are not needed.

**Archive command:**

```
python docs/build_info/reference_files/make_archive.py stage-18-audit-tiles
```

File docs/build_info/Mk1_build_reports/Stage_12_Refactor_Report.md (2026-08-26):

# Stage 12 -- field_capture refactor + ship-mode robustness + REC_AUDIO

Date: 2026-08-01
Firmware: iv7.1 (bench), fw baseline entering Stage 12 was 0.4.12
Build: `idf.py build` clean, binary `smartwatch.bin` = 0x8bcb0 bytes, 82% partition free.

## What changed

### 1. field_capture component split from one 3 877-line file into 8 files

Previous state: `components/field_capture/field_capture.c` was a 3 877-line
mega-file mixing the FCM state machine, every mode session, WAV/CSV writers,
battery-test mode, BLACKBOX telemetry, the CLI, and the shutdown watcher.

Split:

| File | Lines | Purpose |
|---|---:|---|
| `field_capture.c` | 268 | Orchestrator: `field_capture_init`, `task_field_capture_fn` FCM state machine, `field_capture_get_boot_seq` public getter. |
| `fc_common.c` | 315 | Shared globals (`s_mode`, `s_state`, `s_boot_seq`, ...), palette (`MODE_INFO`), LSM taxonomy helpers, button + encoder state machines, `wake_sensors_for_mode` / `park_all_modal_sensors`, `nvs_load` / `nvs_save_mode`, `ensure_sd` + `rtc_iso_now`, base RGB helpers. |
| `fc_recording.c` | 309 | WAV header + `wav_record_to`, `wav_write_meta_sidecar`, `csv_open` + `csv_row_env|motion|skin`, `debug_dump_mode`, `voice_annot_lead_in`, `run_recording_for_current_mode`, `run_alarm_firing`. |
| `fc_modes.c` | 526 | Compass (`run_mag_cal`, `run_compass`, `run_compass_or_cal`), ECG/QVAR (inline block + `run_ecg`, `run_ecg_session`), TEMP (`read_lsm_die_temp`, `read_max_die_temp`, `run_temp_session`, `run_temp_mode`), mode-signature LED animations (`rgb_compass_alt_red_blue`, `rgb_qvar_alt_yellow_purple`, `rgb_temp_warm_cycle`, `rgb_lsm_submenu_indicator`). |
| `fc_modes_lsm.c` | 530 | LSM-submenu modes: `run_bcg` / `run_bcg_mode`, `run_steps_mode`, `run_mlc_collect_mode`, `run_tap_dbg_mode`. |
| `fc_battery_test.c` | 490 | `run_battery_test_mode`, `task_blackbox_fn`, shared telemetry helpers `vbat_adc_ensure_init`/`vbat_adc_read_mv`, `esp_ts_ensure_init`/`esp_ts_read_c`, `idle_pct_sample`. |
| `fc_shutdown.c` | 221 | `watcher_ship_mode`, `task_shutdown_watcher_fn`, watcher globals `g_shutdown_hold_active` / `g_recording_active` / `g_watcher_press_reset_pending` / `g_batt_test_active`. |
| `fc_cli.c` | 702 | All `rtc_cli_*` handlers, dispatcher, `task_rtc_cli_fn`. |
| `fc_internal.h` | 228 | Shared extern declarations, constants, enums, `mode_info_t` typedef. Component-private -- not included by consumers of `field_capture.h`. |
| **total** | **3 589** | (was 3 877 in one file; the extra lines are file headers + `fc_internal.h` boilerplate.) |

`components/field_capture/CMakeLists.txt` extended to add the seven new
`.c` files to `SRCS`. `field_capture.h` (public API) is unchanged, so
`main.c` / `boot_tasks.c` / other consumers were not touched.

All static globals that cross file boundaries were promoted to non-static
and re-declared `extern` in `fc_internal.h`. No functional changes to any
state machine, mode, or CSV format -- byte-identical CSV output on rerun.

### 2. Ship-mode is now king

`bq25619_enter_ship_mode` (in `components/bq25619/bq25619.c`) previously
took the shared I2C mutex with a 300 ms timeout and silently returned
`ESP_ERR_TIMEOUT` on failure. If the DRV2605 was mid-buzz on the same
I2C bus 1 (e.g. during the 3-beep voice-annotation lead-in), the watcher's
ship-mode call could time out and the BATFET write never happened.

Change: `bq25619_enter_ship_mode` now retries the mutex take with a
three-attempt escalating budget (500 ms -> 1 500 ms -> 3 000 ms, ~5 s
worst case). If all three fail, it emits an `ESP_LOGE` "ship-mode ABORT"
so the failure is visible rather than silent.

`task_shutdown_watcher_fn` (in `fc_shutdown.c`) also gained release
debounce. Symptom that motivated it: a long press was interpreted as a
single click, a recording started, and ship-mode never fired. Root cause:
a momentary contact bounce mid-hold made the watcher see `!low` for one
5 ms poll cycle, aborting the hold state. Fix: `SHDN_RELEASE_MS = 80 ms`.
The watcher only treats the pin as "released" after it has stayed high
for 80 ms; short bounces are absorbed. If the fire threshold (4 s) is
reached mid-bounce, ship-mode fires anyway.

### 3. `REC_AUDIO ON|OFF` CLI command

New NVS knob `cfg_sys.rec_audio` (default ON). Toggle via serial
`REC_AUDIO ON` or `REC_AUDIO OFF`; no reboot needed, takes effect on the
next recording start. When OFF, `run_recording_for_current_mode` skips
the 3-beep + 5 s WAV voice-annotation pre-roll for `FCM_ENV / FCM_MOTION /
FCM_SKIN` recordings and jumps straight into the CSV loop.

Wired through:

- `nvs_cfg.h/.c`: `K_SYS_REC_AUDIO` key, `nvs_cfg_sys_get_rec_audio` /
  `nvs_cfg_sys_set_rec_audio`, boot printout line, default `true`.
- `fc_recording.c` `run_recording_for_current_mode`: gated `voice_annot_lead_in`
  + the annot WAV write on `nvs_cfg_sys_get_rec_audio()`.
- `fc_cli.c` `REC_AUDIO` handler + HELP text + `STATUS` + `NVS_PRINT` dump.

## What still needs to happen (handoff)

- **Verify on bench.** The refactor compiled clean but nothing has been
  flashed and physically driven through every mode. Suggested smoke path:
  boot, run `WHOAMI`, run `TEMP_DUMP`, enter each top-level mode + LSM
  submenu, verify `REC_AUDIO OFF` skips the 5 s pre-roll, verify 4 s
  hold trips ship-mode even mid-mic-annotation.
- **BQ25619 TS network** is still not populated on iv7.1. `TEMP_DUMP` prints
  `bq (BQ25619) = -- (TS network not populated on iv7.1)` for that reason.
  Once the thermistor divider is in place, add a `bq_die_temp` read to
  `rtc_cli_dump_temps` in `fc_cli.c`.
- **Bench-test bouncy button.** The 80 ms release debounce is a workaround
  for what looks like a dying encoder switch. Once a replacement lands,
  the debounce is harmless -- it eats bounces without any downside on a
  clean button.
- **BQ mutex retry budget review.** Escalating retries max out at ~5 s.
  Long enough for any legitimate in-flight I2C transaction on this system
  (drv2605 buzz sequence, TMP117 read, BQ polling) but if we ever add a
  driver that legitimately holds the mutex longer, ship-mode will log
  "mutex stuck" and abort -- which is loud but correct.

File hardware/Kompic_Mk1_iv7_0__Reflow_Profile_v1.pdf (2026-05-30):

Kompic Mk1 PCB — Reflow & Assembly Reference

by Ivan Porupski, 2026

PAGE 1 — QUICK REFERENCE (keep visible during reflow)

Step-by-Step Procedure

1. Verify baked paste on all pads; smear thin flux (NC-559-ASM) across pad areas — flux QFN/WSON center pads too. For the MEMS mic, flux pads before placing, keep flux out of the top port.
2. Place all ICs and connectors onto flux + baked paste (tweezers, magnification). All parts go on now — single reflow pass.
3. Photograph the populated board; attach thermocouple to board edge with kapton tape.
4. Place board on cold hot plate, run the profile below. Hands off once heating starts; let the cycle finish before handling.

Reflow Profile

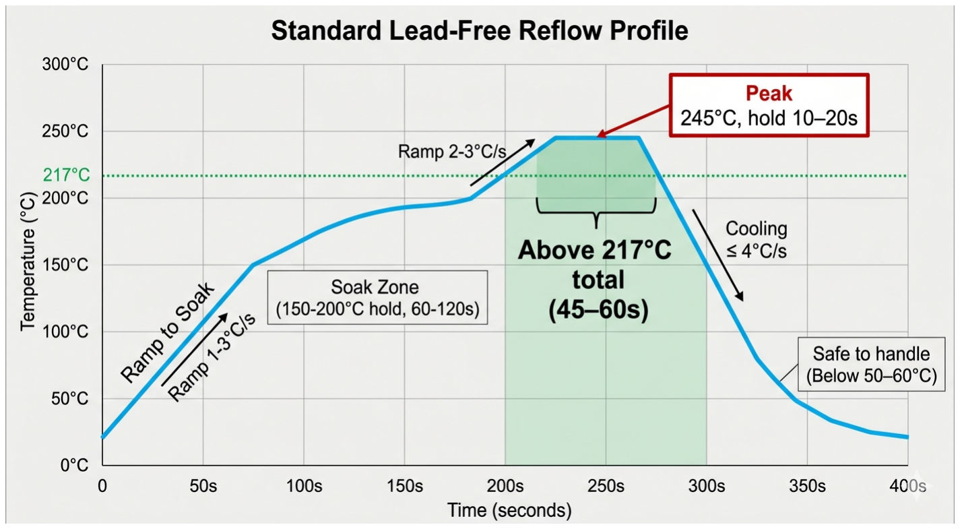
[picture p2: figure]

Figure 1: Target reflow profile — binding constraints from MAX-M10S, WS2812B-2020, FC31M2 crystal.

Phase | Target
Ramp to preheat | 1–3°C/s, 60–90s to reach 150°C
Soak | 150–200°C hold, 60–120s
Ramp to peak | 2–3°C/s
Peak | 245°C, hold 10–20s
Above 217°C total | 45–60s
Cooling | ≤ 4°C/s, hot plate off, natural cool
Safe to handle | Below 50–60°C

During Heating — Rules

- Hands off once heating starts. No tapping, no nudging, no adjusting.
- Below 217°C: if a part visibly shifts, you may carefully reposition with tweezers. This is a rescue, not routine.
- Above 217°C (solder liquid): DO NOT TOUCH ANYTHING. Surface tension self-centers parts.
- If board gets bumped above 180°C: let the cycle finish. Never pull board off hot plate. Fix damage after cool-down.
- Operate hot plate buttons with stable grip, controlled press, steady hand.

After Cooling

1. Visual inspection under magnification — every IC, every QFN edge, every pad
2. Compare against pre-reflow photo — check for shifted/rotated parts
3. Multimeter: resistance on every power rail to GND (3.2V, 1.8V, 5V, SYS, VBUS)
4. If all clear → initial power-on (see Page 2)
5. If short found → find and fix bridge before applying any power

Floor Life — Bag Opening (all parts, single reflow)

All MSL parts are placed in one pass, so open all moisture-sensitive bags on reflow day and reflow within their floor-life windows. Bake any part whose window was exceeded before placing.

Part | MSL | Floor Life | Bake Recovery
ESP32-S3-WROOM-1U | 3 | ∼1 week at <30°C, <60% RH | 125°C / 24hr
MAX-M10S | 4 | 72hr at <30°C, <60% RH | 192hr @ 40°C, RH <5%
VEML6030 | 4 | 72hr at <30°C, <60% RH | 192hr @ 40°C, RH <5%

WARNING: Single reflow pass only. The board carries bottom-side components (notably the USB-C connector) that prevent a clean second hot-plate cycle — there is no second pass for any part. Every IC, including the MAX-M10S, must be placed and reflowed together. Plan placement so nothing is missed.

## PAGE 2 — BRING-UP SEQUENCE

Initial Power-On

Current-limited LiPo test:
- 4× 200Ω 250mW resistors in parallel (= 50Ω, 1W) in series with LiPo positive
- Dead short draws 74mA max — nothing smokes
- Measure voltage across board: ∼3.7V = no short, ∼0V = short present
- ESP32 will NOT boot through this resistor (needs 300mA+) — this is shorts-only testing
- Remove resistors for actual boot testing

With USB power meter arrives:
- Power via USB-C through meter
- Watch current draw in real time
- BQ25619 boots first, brings up SYS rail, TPS62840 produces 3.2V
- Normal idle current (no firmware): expect tens of mA
- If current spikes to 1A+ immediately: unplug, find the short

NOTE: The TPS62840 is VSET-programmable. A 3.3V rail is possible; this board deliberately uses a 3.2V rail, set by a 100k VSET resistor (instead of 172k for 3.3V). All 3.3V-domain parts remain within spec at 3.2V.

Verification Sequence

1. Check 3.2V rail with multimeter — TPS62840 working?
2. Check 1.8V rail — XC6206 working?
3. Connect USB-C, check if ESP32 enumerates as USB CDC device
4. If ESP32 alive → I2C bus scan on bus 1 and bus 2
5. Every device should respond at expected address:

Bus 1: 0x10 (VEML6030), 0x1C (LIS3MDLTR), 0x48 (TMP117), 0x51 (PCF85063), 0x57 (MAX30101), 0x5A (CST9217), 0x6B (LSM6DSV16X), 0x76 (BME688)

Bus 2: 0x5A (DRV2605), 0x6A (BQ25619)

NOTE: The MAX-M10S GPS is not on I2C by default — it communicates over UART1 (GPS-TX → GPIO17, GPS-RX → GPIO18). Verify it by opening the UART and confirming NMEA/UBX traffic, not via an I2C scan. (The M10S DDC/I2C interface at 0x42 exists as an option but is unused on this board.)

6. Missing I2C device = suspect bad solder joint on that IC
7. Open UART1 (GPIO17/18) and confirm the M10S streams NMEA/UBX — GPS solder-joint check
8. Test 5V boost (BQ25619 PMID) — enable via I2C, confirm 5V on rail

## PAGE 3 — HIDDEN PAD IC VERIFICATION

These ICs have pads entirely underneath — you cannot visually inspect joints.

Part | Package | Verification Method
BQ25619 | WQFN-24 (4×4mm)

Highest risk. Check I2C response @ 0x6A. Measure SYS rail voltage. Check for bridges between
| | perimeter pads and center GND.
MAX-M10S | LCC-18 | Castellated + bottom pads. | Verify by
opening UART1 (GPIO17/18) and confirming NMEA/UBX output. No second reflow avail-
| | able — get it right first pass.
BME688 | LGA-8 | I2C response @ 0x76. Read chip ID register.
LSM6DSV16X | LGA-14 | I2C response @ 0x6B. Read WHO AM I regis-
| | ter.
LIS3MDLTR | LGA-12 | I2C response @ 0x1C. Read WHO AM I regis-
| | ter.
MSM261DGT003 | MEMS mic | No I2C — test by reading PDM data. Clock on
| | GPIO47, data on GPIO48.
TMP117 | WDFN-6-EP (2×2mm)

I2C response @ 0x48. Read temperature register
| | (∼room temp).
PCF85063ATL | DFN-10 | I2C response @ 0x51. Read seconds register
| | (should increment).

WARNING: For all hidden-pad ICs: before reflow, don’t add extra paste on top of JLCPCB stencil paste. Just flux. Excess paste under QFN/LGA causes bridges.

## PAGE 4 — SOLDER & CONSUMABLES

What’s On The Board

JLCPCB assembles 0402 passives using SAC305 lead-free paste at 255±5°C (economic assembly). No passive has a peak temp limit below 260°C — no concern.

JLCPCB also applies SAC305 solder paste to ALL remaining pads via stencil (verify in their gerber viewer that paste layer apertures exist for IC pads). Paste is baked (not reflowed) before shipping. Builder reflows these pads on the hot plate at 245°C in a single pass.

Solder jumpers are pre-connected with cuttable traces — no soldering needed during assembly. Cut trace to change default state.

Your Consumables

Item | Alloy | Melting | Use On This Board
NC-559-ASM flux | — | — | YES — apply to baked paste, re- work
Sn99.3/Cu0.7 | wire
0.8mm | Lead-free | 227°C | YES — hand solder, rework, bridges
SAC305 | syringe
paste | Sn96.5/Ag3.0/Cu0.5 | 217°C | YES — backup paste, rework touch-up
Sn62.8/Pb36.8/Ag0.4 paste | LEADED | 181°C | DO NOT USE ON THIS BOARD

WARNING: The board arrives with SAC305 (lead-free) paste from JLCPCB. Mixing leaded paste with lead-free creates a mixed alloy with unpredictable melting point (181–217°C range). Joints form weak grain boundaries and fail as intermittent connections. Keep all solder on this board lead-free.

NOTE: Sn99.3/Cu0.7 wire and SAC305 paste are not identical alloys (wire has no silver, paste has 3% silver). This is fine — the small composition difference is negligible during rework. Both are lead-free, both melt in the 217–227°C range.

## PAGE 5 — PRACTICE RUN & TEMPERATURE CALIBRATION

Before Your First Real Reflow

You must do at least one practice run. Use a bare scrap board or one of your spare JLCPCB boards (no components).

Equipment Needed

- K-type thermocouple + reader (∼e5–10) — non-negotiable for 245°C ceiling with parts that die at 250°C
- Kapton tape to attach thermocouple to board surface

Procedure

1. Tape thermocouple tip flat against board surface, near center
2. Run your full reflow profile using hot plate buttons
3. Log thermocouple reading at each phase vs hot plate display reading
4. Calculate offset (e.g., hot plate says 245°C but board surface is actually 252°C → set hot plate to 238°C)
5. Run again with corrected settings, verify board surface hits 245°C ±3°C
6. Note your hot plate button settings for each phase — these are your calibrated numbers

What You’re Calibrating

- Hot plate display accuracy (could be ±10–15°C off)
- Ramp rates (how fast does your specific plate heat and cool)
- Cooling behavior (does it cool faster or slower than 4°C/s naturally)
- Your button-pressing rhythm for each phase transition

WARNING: Without this calibration, you are guessing. A hot plate that reads 10°C low means you’re actually hitting 255°C when you think you’re at 245°C — and your M10S and WS2812B are over spec. With no second reflow available, a botched first pass is expensive — calibrate first.

## PAGE 6 — DAUGHTER PCB REFLOW

The daughter PCB (small round board) ships attached to the main PCB but should be reflowed separately.

Components on Daughter PCB

- MAX30101EFD+T (OLGA-14, 3.3×5.6mm) — face down, HR/SpO2
- TMP117AIDRVR (WDFN-6-EP, 2×2mm) — skin temperature
- DRV2605LDGSR (VSSOP-10) — haptic driver
- Associated 0402 passives (JLCPCB assembled)

Profile

Same as main board: 245°C peak, 45–60s above 217°C, ≤4°C/s cooling.

Risk Level

Lower than main board. No MSL 4 parts, no WS2812B, no crystal. All three ICs tolerate 260°C. The 245°C profile gives generous margin. This is a straightforward reflow.

Inter-Board Connection

After both PCBs are individually verified working, connect with 12 silicone wires (hand soldered to pads on each board).

## PAGE 7 — REWORK PROCEDURES

Solder Bridges (most common issue)

Method: Soldering iron + flux + solder wick
- Apply flux to bridged area
- Press wick onto bridge with iron tip
- Wick absorbs excess solder
- Localized — only the affected pins experience thermal stress
- This is always the first thing to try

Misaligned / Shifted IC

If visible pads (castellated, gull-wing): reflow individual pins with iron, nudge into alignment with tweezers while last pin is still molten.

If hidden pads (QFN, LGA): must remove entirely. Use hot air rework station (controlled temp, focused nozzle). Pre-heat board on hot plate to 150°C, then hot air at 300–350°C on the IC until it lifts. Clean pads with wick + flux. Re-paste with SAC305 syringe, place new part, reflow locally.

WARNING: Exception: MAX-M10S — u-blox prohibits hot air. If M10S must be removed: pre-heat board on hot plate to 150°C, then use iron to release each castellated pad individually. Slow and tedious but possible for an LCC-18. Clean, re-paste, reflow locally.

Dead IC (confirmed bad after electrical test)

Same removal procedure as misaligned. Replace with spare from your doubles order. Localized rework only.

WARNING: There is no second full reflow on this board — bottom-side components (USB-C and others) prevent a clean second hot-plate cycle. All rework is localized (iron or focused hot air on the single failed part), never a whole-board re-reflow. Keep whole-board thermal cycles to the single production pass.

## PAGE 8 — COMPLETE COMPONENT REFLOW SPECIFICA-TIONS

Binding Constraints Summary

Constraint | Value | Set By
Peak temperature | 245°C | MAX-M10S, WS2812B-2020
Time above 217°C | 45–60s | MAX-M10S ∩ WS2812B-2020
Time at peak (≥240°C) 10–20s | FC31M2 crystal
Max cooling rate | 4°C/s | MAX-M10S

Full Component Table

# | Part | Package | MSL | Peak | Key Constraints

1 | MAX-M10S-00B | LCC-18 | 4 | 245°C | No hot air. Single reflow. No cleaning.
2 | VEML6030 | — | 4 | 260°C | 72hr floor life. Bake if exposed.
3 | ESP32-S3-WROOM-1U | Module | 3 | 235–250°C | Single reflow. Bake if open >1wk.
4 | WS2812B-2020 | 2×2mm | — | 245°C | J-STD-020C.
5 | FC31M2-32.768kHz | SMD3215 | — | 260°C | 10s at peak. Cooling ≤6°C/s.
6 | Johanson 2450AT18A100E | Chip ant. | — | 260°C | 3 reflow cycles max.
7 | LSM6DSV16X | LGA-14 | — | 235–255°C | J-STD-020 (ST TN0018).
8 | LIS3MDLTR | LGA-12 | — | J-STD | J-STD-020.
9 | PCF85063ATL | DFN-10 | — | 260°C | Standard NXP.
10 | BME688 | LGA-8 | 1 | 260°C | 50µm min solder standoff.
11 | MSM261DGT003 | MEMS | — | 260°C | 5 reflow cycles OK.
12 | MAX30101EFD+T | OLGA-14 | — | 260°C | Max temp only stated.
13 | BQ25619RTWR | WQFN-24 | — | 260°C* | Assumed, TI QFN.
14 | TMP117AIDRVR | WDFN-6-EP | — | 260°C* | Assumed, TI WDFN.
15 | DRV2605LDGSR | VSSOP-10 | — | 260°C* | Assumed, TI VSSOP.
16 | TPD2E001DRLR | SOT-553 | — | 260°C* | Assumed, TI SOT.
17 | BSS138W | SOT-323 | — | 260°C* | Assumed, standard MOSFET.
18 | USB-C JS16T | 16-pin | — | 260±5°C | 60s >217°C, 5s >250°C.

*Not stated in datasheet — standard package assumption.

MSL Handling Reference

MSL | Floor Life | Bake Recovery
1 | Unlimited | None needed
3 | ∼168hr (1 week) at <30°C, <60% RH | 125°C / 24hr
4 | Per bag label (∼72hr) at <30°C, <60% RH | 192hr @ 40°C, RH <5%

Notes

- Single reflow pass — bottom-side components (USB-C, etc.) preclude a second whole-board cycle. All parts, including MAX-M10S, go on together.
- MAX-M10S communicates over UART1 (GPIO17 TX / GPIO18 RX), not I2C. DDC/I2C @ 0x42 is available but unused.
- All 0402 passives assembled and reflowed by JLCPCB at 255±5°C — their process, no passives at risk.
- JLCPCB applies SAC305 solder paste to all remaining pads via stencil. Paste baked before shipping.
- Pre-soldered 0402s re-melt during builder’s reflow — board must be level and flat.
- All solder on this board must be lead-free. Do not use leaded paste or wire.
- Paste: SAC305 (Sn96.5/Ag3.0/Cu0.5), no-clean. Rework wire: Sn99.3/Cu0.7, 0.8mm. Flux: NC-559-ASM no-clean.
- Core rail is 3.2V via TPS62840 with a 100k VSET resistor (3.3V available with 172k; 3.2V chosen).
- Boards are 1.0mm 4-layer.

Kompic Mk1 — Reflow & Assembly Reference Revision iv7.0
Ivan Porupski, 2026

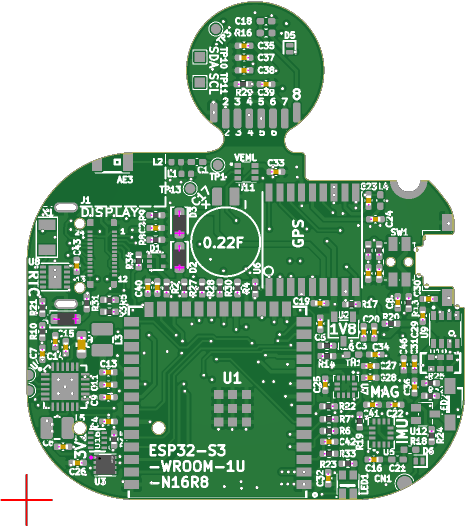
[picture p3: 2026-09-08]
hardware/Kompic_Mk1b/img/Top+null+SMT026082361633.png

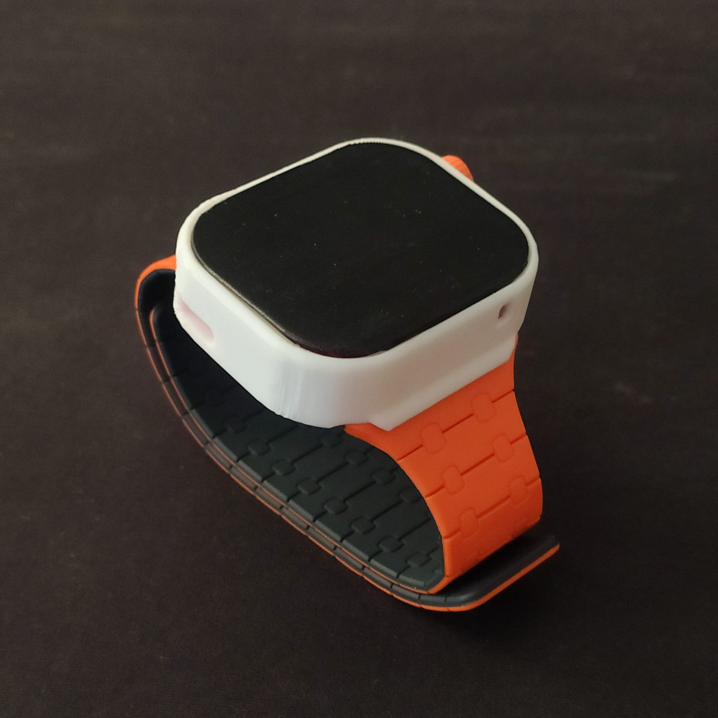
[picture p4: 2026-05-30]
docs/img/Kompic_3D_demo_Front_v1.jpeg

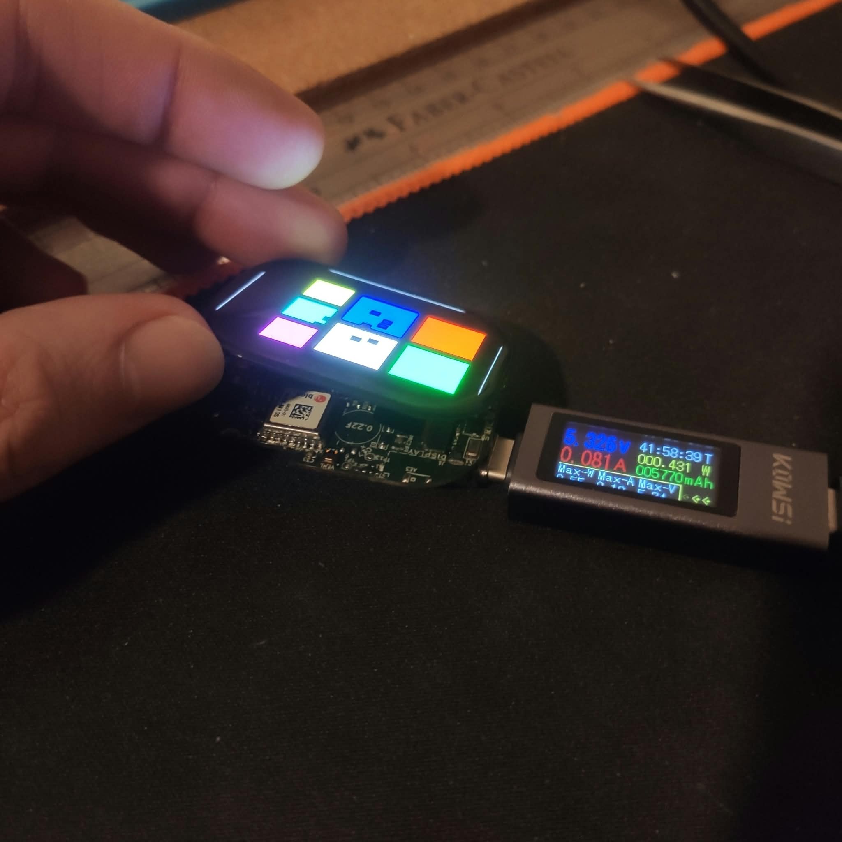
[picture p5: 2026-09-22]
docs/img/development/8_amoled_working.jpeg

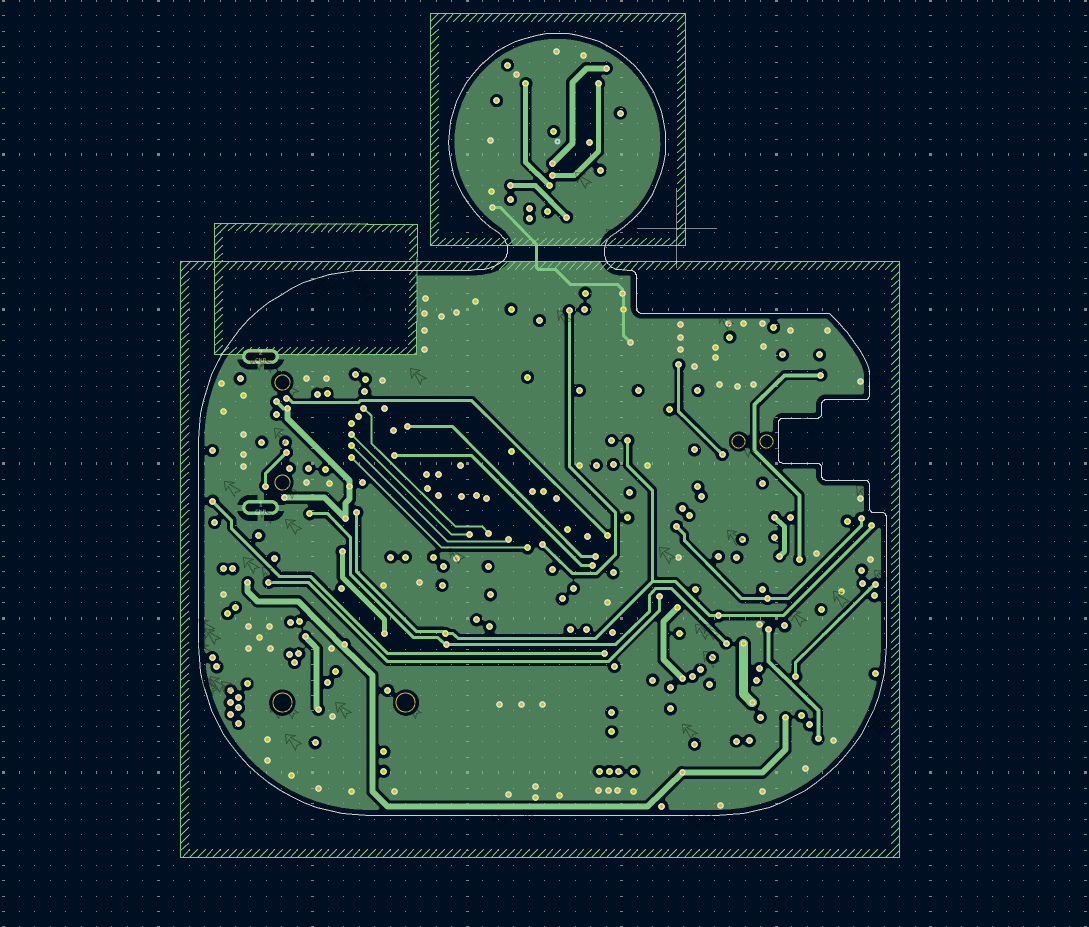
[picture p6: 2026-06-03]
docs/img/pcb_Kompic_Mk1_iv7.1_L2_gnd.png

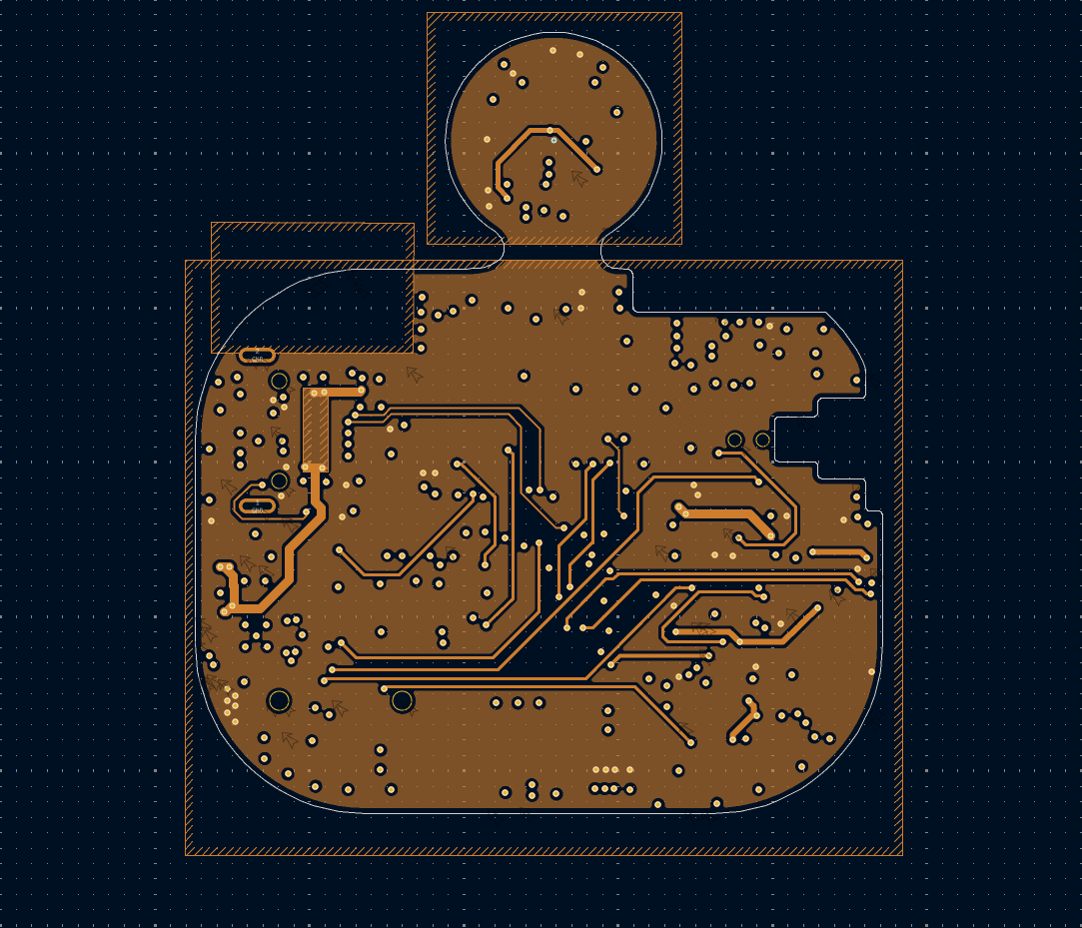
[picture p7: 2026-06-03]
docs/img/pcb_Kompic_Mk1_iv7.1_L3_power.png

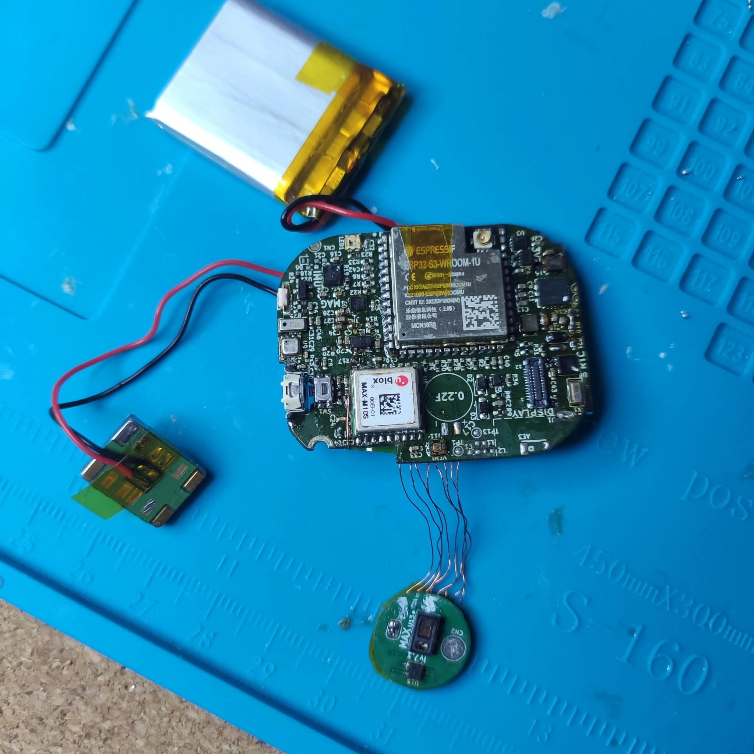
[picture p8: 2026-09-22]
docs/img/development/10_mk1b_layout_a.jpeg

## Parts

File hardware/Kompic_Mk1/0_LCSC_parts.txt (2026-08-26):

# Kompic Mk1 — LCSC Parts List
# Format: LCSC_ID  # PART_NAME                PACKAGE
# Lines starting with # are ignored by the import script.
# To exclude a part, comment it out.

C2859066   # MAX30101EFD+T              OLGA-14(3.3x5.6)
C527464    # DRV2605LDGSR               VSSOP-10
C478483    # LIS3MDLTR                  LGA-12(2x2)
C393941    # TF-PUSH (SD card slot)     SMD
C3664478   # BME688                     SMD-8P(3x3)
C21659     # XC6206P182MR (1.8V LDO)   SOT-23-3
C150526    # TPD2E001DRLR (ESD)         SOT-553-5
C132182    # VEML6030                   SMD-6P(2x2)
C4153167   # MAX-M10S-00B (GPS)         LCC-18(9.7x10.1)
C965555    # WS2812B-2020               SMD(2x2)
C5137195   # BWU.FL-IPEX1 (U.FL conn)  SMD
# C784388  # BWGNSCNX8-8W2 (GPS ant)   THT 8x8  — FAILS easyeda2kicad, manual footprint needed
C404360    # PCF85063ATL/1,118 (RTC)    DFN-10(2.6x2.6)
C5446      # XC6206P332MR (3.3V LDO)   SOT-23-3
C3013946   # ESP32-S3-WROOM-1U-N16R8   SMD(19.2x18)
C699536    # TMP117AIDRVR               WSON-6(2x2)
C2842180   # FC31M2-32.768 (crystal)   SMD3215-2P
C88527     # VLS252010HBX-2R2M (ind)   1008
C89334     # 2450AT18A100E (BLE ant)    1206
C48227730  # MSM261DGT003 (PDM mic)    LGA-6(2x4)
C115361    # SKSCLBE010 (button)        SMD(3.6x3.5)
C5267406   # LSM6DSV16XTR (IMU)        LGA-14(2.5x3)
C2864534   # BQ25619RTWR (charger)     WQFN-24(4x4)
C601698    # TJ-S4008SW4TGLCCW-A5 (LED) SMD(4x1.4)
C890266    # BSS138W (NMOS)             SOT-323
C49118447  # JS16T USB-C connector      SMD 16P
C113112    # LQW15AN27NJ00D (27nH ind) 0402
C98058     # LQW15AN2N7C00D (2.7nH ind) 0402
C5452416   # LQG15HS3N9B02D (3.9nH ind) 0402
C432937    # CGA2B2C0G1H470JT (47pF)   0402
C60133     # CC0402KRX7R9BB103 (10nF)  0402

# Mk1b
C2682616   # MAX17048G+T10 (fuel gauge)     TDFN-8(3x3)

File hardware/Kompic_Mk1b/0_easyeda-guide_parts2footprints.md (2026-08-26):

# LCSC → KiCad: Complete Library Setup Guide

**Goal:** Take a list of LCSC part numbers, generate KiCad symbols + footprints + 3D models, and set up a fully portable project-local library.

Tested with: easyeda2kicad v0.8.0, KiCad 9, Linux (Ubuntu/Fedora).

---

## 1. Environment Setup (one-time)

easyeda2kicad requires Python. Use a conda/mamba environment to keep it isolated.

```bash
# Create environment
mamba create -n pcb_dev python=3.11 -y
mamba activate pcb_dev

# Install easyeda2kicad
pip install easyeda2kicad
```

Verify:

```bash
easyeda2kicad --help
```

---

## 2. Project Structure

Inside your KiCad project folder, create a library directory:

```
MyProject/
├── MyProject.kicad_pro
├── MyProject.kicad_sch
├── MyProject.kicad_pcb
├── sym-lib-table
├── fp-lib-table
├── parts.txt                    ← your parts list
└── MyProject_library/           ← created by easyeda2kicad
    ├── MyProject.kicad_sym      ← all symbols
    ├── MyProject.pretty/        ← all footprints
    └── MyProject.3dshapes/      ← all 3D models (.wrl + .step)
```

Create the empty library folder:

```bash
mkdir MyProject_library
```

---

## 3. Parts List Format

Create `parts.txt` in the project root. One LCSC ID per line, comments with `#`:

```
C2859066   # MAX30101EFD+T              OLGA-14(3.3x5.6)
C527464    # DRV2605LDGSR               VSSOP-10
# C784388  # BWGNSCNX8-8W2 (GPS ant)   FAILS — manual footprint needed
C404360    # PCF85063ATL/1,118 (RTC)    DFN-10(2.6x2.6)
```

- Commented-out lines (starting with `#`) are skipped by the import script.
- Only the first field (LCSC ID) is used — the rest is for your reference.

---

## 4. Run the Import

Activate the environment, `cd` to the project folder, and run:

```bash
mamba activate pcb_dev
cd /path/to/MyProject

grep -v '^\s*#' parts.txt | awk '{print $1}' | while read id; do
  echo "=== Fetching $id ==="
  easyeda2kicad --full --lcsc_id "$id" --output ./MyProject_library/MyProject
done
```

**Replace `MyProject_library/MyProject` with your actual folder/prefix.**

### What to expect

- First part creates the `.kicad_sym`, `.pretty/`, and `.3dshapes/` inside the library folder.
- Subsequent parts append to the same symbol lib and add footprints/models.
- Parts sharing the same package footprint (e.g., two SOT-23-3 LDOs) will warn `footprint already in .pretty` — this is fine, the symbol still gets created.
- Some parts (unusual packages, antennas) may fail with `[ERROR] Failed to fetch data from EasyEDA API` — these need manual footprints.

### If you need to re-run (overwrite existing):

```bash
grep -v '^\s*#' parts.txt | awk '{print $1}' | while read id; do
  echo "=== Fetching $id ==="
  easyeda2kicad --full --overwrite --lcsc_id "$id" --output ./MyProject_library/MyProject
done
```

---

## 5. Fix 3D Model Paths

easyeda2kicad writes relative paths like `/MyProject_library/...` in footprint files. KiCad can't resolve these. We fix them to use a KiCad environment variable.

```bash
sed -i 's|"/MyProject_library/|"${MY_3D_LIB}/|g' ./MyProject_library/MyProject.pretty/*.kicad_mod
```

**Replace:**
- `MyProject_library` with your actual folder name
- `MY_3D_LIB` with your chosen KiCad environment variable name

Verify:

```bash
grep "model" ./MyProject_library/MyProject.pretty/*.kicad_mod | head -3
```

Should show paths like `${MY_3D_LIB}/MyProject.3dshapes/SOME-FOOTPRINT.wrl`.

---

## 6. Configure KiCad

### 6a. Add the environment variable for 3D models

In KiCad: **Preferences → Configure Paths → Add**

| Name | Path |
|---|---|
| `MY_3D_LIB` | `/full/path/to/MyProject/MyProject_library` |

This is what makes the `${MY_3D_LIB}` references in the footprints resolve to actual files.

### 6b. Add library tables

Edit `sym-lib-table` in the project root:

```
(sym_lib_table
  (lib (name "MyProject")(type "KiCad")(uri "${KIPRJDIR}/MyProject_library/MyProject.kicad_sym")(options "")(descr ""))
)
```

Edit `fp-lib-table` in the project root:

```
(fp_lib_table
  (lib (name "MyProject")(type "KiCad")(uri "${KIPRJDIR}/MyProject_library/MyProject.pretty")(options "")(descr ""))
)
```

**`${KIPRJDIR}` works fine for symbol and footprint paths** — it's only the 3D model paths inside `.kicad_mod` files that need the custom environment variable.

### 6c. Verify

1. Open KiCad → Preferences → Manage Symbol Libraries → Project tab → confirm `MyProject` entry exists
2. Preferences → Manage Footprint Libraries → Project tab → confirm `MyProject` entry exists
3. Place any symbol from the library in the schematic
4. Open Footprint Properties → 3D Models tab → confirm the model preview loads

---

## 7. Portability

To share or move the project:

1. Zip the entire project folder (library is inside it — symbols, footprints, 3D models all travel together)
2. On the new machine, the recipient must add the **same environment variable** in KiCad's Configure Paths, pointing to wherever they unzipped the library folder
3. `sym-lib-table` and `fp-lib-table` use `${KIPRJDIR}` so they work automatically

---

## Quick Reference — Kompic Mk1 Actual Commands

```bash
# Activate environment
mamba activate pcb_dev
cd ~/path/to/kompic-wearable/hardware/Kompic_Mk1b

# Import all parts
grep -v '^\s*#' parts.txt | awk '{print $1}' | while read id; do
  echo "=== Fetching $id ==="
  easyeda2kicad --full --lcsc_id "$id" --output ./Kompic_Mk1b_library/Kompic_Mk1b
done

# Fix 3D model paths
sed -i 's|"/Kompic_Mk1b_library/|"${KOMPIC_MK1B_LIB}/|g' ./Kompic_Mk1b_library/Kompic_Mk1b.pretty/*.kicad_mod

# KiCad Configure Paths:
#   KOMPIC_MK1B_LIB → ~/path/to/kompic-wearable/hardware/Kompic_Mk1b/Kompic_Mk1b_library
```

---

## Troubleshooting

| Problem | Fix |
|---|-----|
| 3D models don't load | Check Configure Paths env variable points to correct folder |
| `[ERROR] Failed to fetch` for a part | EasyEDA doesn't have this part — make footprint manually |
| `[WARNING] footprint already in .pretty` | Normal — two parts share same package. Symbol still created. |
| Models show in footprint editor but not 3D viewer | Close and reopen KiCad to clear cache |
| Want to update a single part | `easyeda2kicad --full --overwrite --lcsc_id CXXXXXX --output ./...` |

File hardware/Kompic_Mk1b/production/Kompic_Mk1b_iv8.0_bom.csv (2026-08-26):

Designator | Footprint | Quantity | Value | LCSC Part #
AE1 | GPS_Ceramic_Antenna_8x8mm_v1.0 | 1 | Ceramic GPS Antenna
AE3 | ANT-SMD_L3.2-W1.6 | 1 | 2450AT18A100E | C89334
BT1 | Battery_solder_terminals_v1 | 1 | LiPo 3,7V 380mAh
BT2 | DMS_3R3_224_supercap_feets_v1 | 1 | ML621 3.0V
C1 | 0402 | 1 | 1.0pF
C10 | 0603 | 1 | 47nF
C11, C13, C14, C2, C3, C46, C5, C6, C9 | 0402 | 9 | 10uF
C15, C22, C27, C35, C4 | 0402 | 5 | 4.7uF
C16, C19, C20, C25, C26, C28, C29, C30, C31, C32, C33, C38, C39, C40, C41, C43, C44, C45, C8 | 0402 | 19 | 100nF
C17 | DMS_3R3_224_supercap_feets_v1 | 1 | 0.22F 3.0V supercap
C23 | 0402 | 1 | 47pF
C24 | 0402 | 1 | 10nF
C34, C36, C37, C42, C47, C7 | 0402 | 6 | 1uF
CARD1 | TF-SMD_TF-PUSH | 1 | TF PUSH | C393941
D1 | SOT-553-5_L1.6-W1.2-P0.50-LS1.6-BR | 1 | TPD2E001DRLR | C150526
D2, D3, D4 | D_SOD-323 | 3 | 1N4148WS
J1 | Connector_b2b_OK-F024-04_v1 | 1 | Conn_02x12_OK-14F024-04_v1
J2 | Custom_8_pin_for_SmartWatch_v4-MB-straightline | 1 | MB Interface
J3 | Custom_8_pin_for_SmartWatch_v4-DB-semicircle | 1 | DB-Interface
L1 | 0402 | 1 | 2.7nH
L2 | 0402 | 1 | 3.9nH
L3, L5 | 1008 | 2 | 2.2uH
L4 | 0402 | 1 | 27nH, 5%
LED1 | LED-SMD_4P-L2.0-W2.0-TL_WS2812B-2020 | 1 | WS2812B-2020 | C965555
LED2 | LED-SMD_TJ-S4008SW4TGLCCW-A5 | 1 | TJ-S4008SW4TGLCCW-A5 | C601698
M1 | Battery_solder_terminals_v1 | 1 | ELV1411A
R1, R10, R13, R17, R2, R20, R24, R27, R28, R30, R31, R33, R34, R35, R36, R4 | 0402 | 16 | 10k
R14, R19, R21, R22, R29, R3, R5, R6, R7, R8, R9 | 0402 | 11 | 5k1
R15 | 0402 | 1 | 100k
R23 | 0402 | 1 | 33R
R25 | 0402 | 1 | 100R
R26 | 0402 | 1 | 33k
R32 | 0402 | 1 | 3k3
SW1 | KEY-SMD_4P-SKSCLXX010 | 1 | SKSCLBE010 | C115361
SW2 | SW-SMD_EC05E1220401-CUSTOM-ORIENT_v1 | 1 | EC05E1220401 | C116648
TH1 | 0402 | 1 | NTC 10k | C77131
TP1 | TestPoint_Pad_D1.0mm | 1 | 50R BLE sig
TP10 | TestPoint_Pad_1.0x1.0mm | 1 | SDA
TP11 | TestPoint_Pad_1.0x1.0mm | 1 | SCL
TP13 | TestPoint_Pad_D1.0mm | 1 | 50R BLE gnd
TP14 | TestPoint_Pad_D1.0mm | 1 | VEML_INT
TP15 | TestPoint_Pad_D1.0mm | 1 | BQ_STAT
TP17 | TestPoint_Pad_D1.0mm | 1 | SD_Cd
TP18 | TestPoint_Pad_D1.0mm | 1 | LIS_INT
TP19 | TestPoint_Pad_D1.0mm | 1 | LIS_DRDY
TP2 | TestPoint_Pad_D1.0mm | 1 | PMID_GOOD
TP20 | TestPoint_Pad_D1.0mm | 1 | LSM_INT2
TP21 | TestPoint_Pad_D1.0mm | 1 | M10S_RST
TP22 | TestPoint_Pad_D1.0mm | 1 | USB_D+
TP23 | TestPoint_Pad_D1.0mm | 1 | USB_D-
TP3 | TestPoint_Pad_D1.0mm | 1 | TMP_ALRT
TP8 | TestPoint_Pad_1.0x1.0mm | 1 | RGB_DO
U1 | WIRELM-SMD_ESP32-S3-WROOM-1U | 1 | ESP32-S3-WROOM-1U-N16R8 | C3013946
U10 | MIC-SMD_6P-L4.0-W2.0_LMD4020T261-OC3 | 1 | MSM261DGT003 | C48227730
U11 | SENSORS-SMD_VEML6030 | 1 | VEML6030 | C132182
U12 | SC-70-3_L2.0-W1.3-P0.65-LS2.1-BL | 1 | BSS138W_C890266 | C890266
U13 | OESIP-14_L5.6-W3.3-P0.80-TL | 1 | MAX30101EFD+T | C2859066
U14 | VSSOP-10_L3.0-W3.0-P0.50-LS4.9-BL | 1 | DRV2605LDGSR | C527464
U15 | WSON-6_L2.0-W2.0-P0.65-TL-EP | 1 | TMP117AIDRVR | C699536
U16 | VSON-8_L2.0-W1.5-P0.50-BL | 1 | TPS62840DLCR | C2071859
U2 | SOT-23-3_L2.9-W1.6-P1.90-LS2.8-BR | 1 | XC6206P182MR | C21659
U3 | TDFN-8_L2.0-W2.0-P0.50-BL-EP1.2 | 1 | MAX17048G+T10 | C2682616
U4 | WQFN-24_L4.0-W4.0-P0.50-TL-EP2.7 | 1 | BQ25619RTWR | C2864534
U5 | LGA-14_L3.0-W2.5-P0.50-BR | 1 | LSM6DSV16XTR | C5267406
U6 | SMD-18_L10.1-W9.7-P1.10-TL_SKG09F | 1 | MAX-M10S-00B | C4153167
U7 | LGA-12_L2.0-W2.0-P0.50-BL | 1 | LIS3MDLTR | C478483
U8 | DFN-10_L2.6-W2.6-P0.50-BL-EP | 1 | PCF85063ATL/1,118 | C404360
U9 | LGA-8_L3.0-W3.0-P0.80_BME688 | 1 | BME688_C3664478 | C3664478
USB1 | USB-C-SMD_JS16T-TYPE-C479-DWH2-FSQ | 1 | JS16T-TYPE-C479-DWH2-FSQ | C49118447
X1 | CRYSTAL-SMD_L3.2-W1.5-1 | 1 | FC31M2-32.768-NTLLLDT | C2842180

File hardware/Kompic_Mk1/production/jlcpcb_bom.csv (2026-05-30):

Comment | Designator | Footprint | LCSC Part #
1.0pF | C1 | 0402
100nF | C10, C16, C19, C20, C25, C26, C28, C29, C30, C31, C32, C33, C38, C39, C40, C41, C42, C43, C44, C45, C8 | 0402
10uF | C11, C13, C14, C2, C3, C5, C6, C9 | 0402
1uF | C15, C34, C36, C37, C7 | 0402
100pF | C18, C21 | 0402
4.7uF | C22, C27, C35, C4 | 0402
1N4148WS | D2, D3, D4 | D_SOD-323
10k | R1, R10, R13, R14, R17, R2, R20, R24, R27, R28, R30, R31, R33, R35, R36, R4 | 0402
5k1 | R12, R19, R21, R22, R29, R3, R5, R6, R7, R8, R9 | 0402
100k | R15 | 0402
470R | R16, R18 | 0402
47R | R23, R25, R26, R32 | 0402
NTC 10k | TH1 | 0402 | C77131
TPS62840DLCR | U16 | VSON-8_L2.0-W1.5-P0.50-BL | C2071859

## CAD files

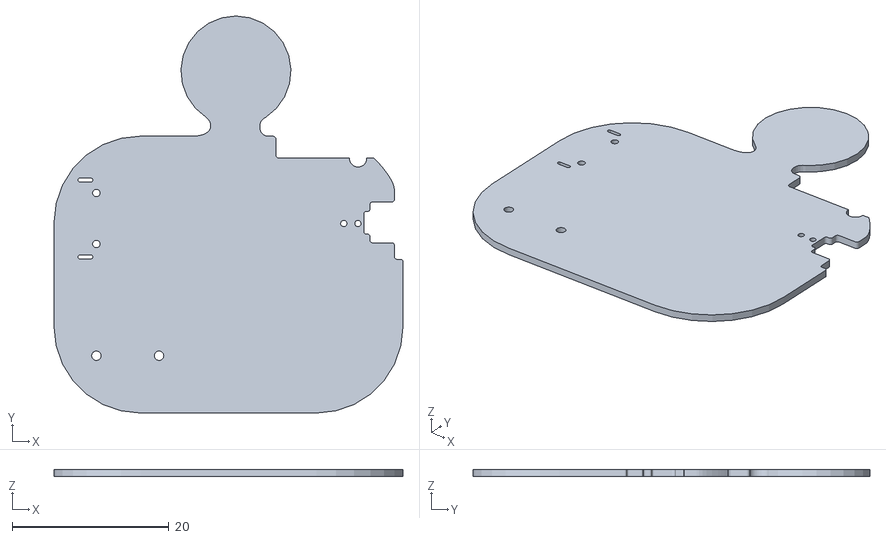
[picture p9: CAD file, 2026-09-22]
hardware/Kompic_Mk1b/Kompic_Mk1b_PCB_ONLY.stl
44.5 x 50.6 x 0.91

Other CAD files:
hardware/Kompic_Mk1b/Kompic_Mk1b_PCB_ONLY_remake.stl

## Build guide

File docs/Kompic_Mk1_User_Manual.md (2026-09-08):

# Kompic Mk1 -- Basic User Manual

**Hardware:** iv7.1 (Mk1 bench prototype). Mk1b PCB uses the same firmware.
**Firmware target:** `KOMPIC_FW_VERSION` in `firmware_version.h`.
**Status:** Pre-display baseline. The screen bring-up is deferred. All
interaction runs through the button, the rotary encoder, the RGB LED, and
the USB serial console.

---

## 1. What Kompic Mk1 does

Kompic Mk1 is a wrist-worn sensor node. The device records timestamped
data from onboard sensors to a microSD card. The user can also inspect
the state of the device on the USB serial console.

A single button, a rotary encoder, and a WS2812 RGB LED control the
device. The device runs as a "field capture" state machine with one
active mode at a time.

---

## 2. Controls and connectors

- **Button.** GPIO16. Doubles as the BQ25619 `/QON` line.
- **Rotary encoder.** ALPS EC05E with detent. A/B channels on GPIO21 /
  GPIO43. The encoder also holds an integrated push switch (not read
  by firmware today).
- **RGB LED.** WS2812 on GPIO42. One pixel.
- **Haptic actuator.** LRA driven by DRV2605L on I2C bus 1.
- **microSD holder.** SDMMC. The card holds a FAT32 filesystem.
- **USB-C port.** USB CDC serial console at 115200 baud. USB also
  powers the device and charges the battery through the BQ25619.

---

## 3. Start-up

Perform this sequence:

1. Connect USB or press the button for one second on a charged battery.
2. The BQ25619 pulls `/QON` low and powers the ESP32-S3.
3. The firmware boots. The RGB LED shows no light during the first
   ~500 ms.
4. The haptic actuator plays two short "click" pulses at the end of
   boot. The two clicks confirm every driver reached its init callback.
5. The device enters STANDBY in the last-used mode. The RGB LED begins
   the idle ladder (Section 6).

Expected cold-boot time: ~4 seconds from BQ25619 power-on to STANDBY.
The delay comes from the BQ25619 `/QON` timing, the ESP32-S3 boot ROM,
and the DRV2605 auto-calibration (2 s bench-verified settling).

---

## 4. Button gestures

The button uses a debounced state machine (`button_poll()` in
`fc_common.c`). The state machine emits three events:

| Gesture | Event | Effect |
|:---|:---|:---|
| Single click (< 1 second, no double)| `event = 1` | Confirm / enter mode / mark |
| Double click (< 350 ms gap) | `event = 2` | Mode-specific (see Section 7) |
| Long press (>= 4 seconds) | Ship mode | Drop the BATFET; power off |

**Timing rules:**

- `BTN_DEBOUNCE_MS = 30`. Sub-30 ms bounces do not count.
- `BTN_DOUBLE_GAP_MS = 350`. A second press within this window emits a
  double-click. A single-click event fires only after this window
  closes.
- `BTN_LONG_PRESS_MS = 1000`. A release past this window emits no
  click. The shutdown watcher owns the press from here.
- Press-edge haptic. Every confirmed press fires a `DRV_STRONG_CLICK`
  the moment the pin goes low. The haptic confirms the device received
  the press.

**Shutdown ladder** (see `SHDN_*` constants in `fc_shutdown.c`):

| Held for | Feedback |
|:---|:---|
| 0..200 ms | Nothing visible. Definitely a click. |
| 200..1000 ms  | RGB LED ramps dim red. Release still fires a click. |
| 1000..2000 ms | RGB LED continues to ramp. Release no longer clicks.  |
| 2000..3700 ms | Haptic warning click every 500 ms. |
| 3700..3950 ms | Sustained warm-up buzz (three clicks 80 ms apart). |
| >= 4000 ms | Long buzz. Fire ship mode. Drop BATFET if on battery. |

**Ship mode on USB.** The BATFET drop does not kill VDD when USB is
plugged. The firmware aborts any live recording and logs the event.
Charging continues. Unplug USB to complete the shutdown.

---

## 5. Rotary encoder

The encoder uses a polled detent-rest state machine
(`encoder_delta()`). The state machine emits one event per confirmed
detent transition, regardless of scroll speed.

- **Rotate one detent clockwise** -- move to the next mode.
- **Rotate one detent counter-clockwise** -- move to the previous mode.
- **Long, fast scroll** -- one event per detent. The state machine
  does not skip or double-count.

The integrated push switch inside the encoder is not read by firmware
today.

---

## 6. RGB LED behaviour

The `rgb_policy` component drives the WS2812. The policy uses a 50 ms
tick. The idle ladder runs when no mode owns the LED.

**Idle ladder (STANDBY, no charging, no low-battery):**

| Phase | Duration | Colour | Purpose |
|:---|:---|:---|:---|
| Preview | 5 s | Mode preview colour | Show the current mode. |
| Normal | 10 s | Dim white | Show the device is alive. |
| Fade | 10 s | Dim white -> black  | Prepare for the off phase. |
| Off | Until | Black | Zero draw between wakes. |
| | input | | |

**Priority overrides** (highest first):

1. **Battery alert.** Red pulse when the state of charge is below 15%.
2. **Charging.** Slow green pulse while `BQ_STATUS_PG = 1` and the
   charger is not `DONE`.
3. **Shutdown ramp.** Solid red from 200 ms of button hold. Intensity
   increases with held time. The ramp releases on button release
   below 4 seconds; the ramp goes to full red on fire.
4. **Mode preview.** The colour matches the current mode.

**Mode preview colours** (see `rgb_policy.c` mode table):

| Mode | Colour |
|:---|:---|
| STANDBY | White  |
| FCM_MIC | Blue |
| FCM_ENV | Green  |
| FCM_LSM | Yellow |
| FCM_PPG_BCG | Purple |
| FCM_COMPASS | Cyan |
| FCM_ECG | Orange |
| FCM_TEMP | Fire strobe |
| FCM_FLASHLIGHT | White (torch on) |
| FCM_ALARM | Amber  |
| FCM_USB_MSC | Cyan |

---

## 7. Modes

A "mode" is one recording target or one utility. The encoder selects
the mode. The button opens the mode for use.

| Mode | Purpose |
|:---|:---|
| FCM_MIC | PDM microphone capture (16 kHz mono). |
| FCM_ENV | BME688 air (temp / RH / pressure) + VEML6030 lux. |
| FCM_LSM | Gateway to the LSM6DSV16X submenu. |
| FCM_PPG_BCG | MAX30101 raw green + LSM6DSV16X accel at 200 Hz. |
| FCM_FLASHLIGHT | White torch on GPIO41. |
| FCM_ALARM | Set an RTC alarm through the CLI. |
| FCM_COMPASS | LIS3MDL magnetometer heading. |
| FCM_ECG | LSM6DSV16X Qvar electrostatic ECG at 480 Hz. |
| FCM_TEMP | Aggregate every onboard temperature source. |
| FCM_USB_MSC | Unmount SD then expose it to the host via USB MSC. |

LSM submenu entries (open from FCM_LSM):

| Submenu | Purpose |
|:---|:---|
| FCM_MOTION | Accel + gyro + magnetometer CSV. |
| FCM_BCG | Ballistocardiogram from the accel Z-axis. |
| FCM_STEPS | Embedded pedometer step counter. |
| FCM_MLC_COLLECT | Raw accel + gyro CSV for MLC training. |
| FCM_TAP_DBG | Host-side tap detector debug view. |

---

## 8. Recording

Each recording mode uses the same pattern:

1. Rotate the encoder to the mode. The RGB LED shows the preview
   colour for 5 seconds.
2. Click the button. The mode enters its RECORDING state. The RGB LED
   goes solid on the mode colour.
3. The firmware opens a CSV file on the SD card. The path is
   `/sd/data/<mode>/<mode>_NNNN.csv` where `NNNN` is a monotonic index.
4. Every CSV row carries an ISO-8601 UTC timestamp from the PCF85063A
   RTC and a `t_ms` millisecond-since-boot value.
5. Click the button again. The mode returns to STANDBY. The file
   closes cleanly.

**Durability rule.** Every row calls `fclose()` or `fsync()` before
returning. A power loss during a row loses at most one row. See
`feedback_sd_write_durable.md` for the incident that led to this rule.

---

## 9. Shutdown and the 15-minute uptime cap

Kompic has two paths to shutdown:

**Manual shutdown.** The user holds the button for 4 seconds. The
shutdown ladder in Section 4 fires. `watcher_ship_mode()` writes the
BQ25619 REG_MISC to disable the BATFET. The device dies within ~1
second on battery.

**Autonomous shutdown (uptime cap).** The firmware runs a 15-minute
damage-control timer (`SHDN_MAX_UPTIME_MS`). The timer fires the same
ship-mode path.

The timer resets on any of the following:

- A recording is active (`g_recording_active`).
- The battery test mode is active (`g_batt_test_active`).
- A button press begins (`button_poll` fresh-press edge).
- The encoder emits a confirmed detent.
- Any code calls `shutdown_watcher_kick()` (2026-09-08 addition).

The timer does not reset on serial console input alone. Send a `REBOOT`
or any input that reaches the button or encoder handlers to postpone
the cap.

**USB behaviour on uptime-cap fire.** The uptime cap fires while USB
is plugged. Before Ivan's 2026-09-08 fix, this dropped BATFET and
stopped charging. The current firmware detects the USB state through
the BQ25619 `power_good` flag. If USB is present, the firmware aborts
any live recording, logs the event, re-arms the deadline, and leaves
BATFET on. Charging continues until the operator unplugs the cable.

---

## 10. Charging behaviour

The BQ25619 handles charging. The firmware never writes to the
charge-enable path. The chip charges the battery whenever VBUS is
present and no fault is active.

The RGB LED shows a slow green pulse while charging (see Section 6).

**Ship mode and charging.** Ship mode writes `BATFET_DIS = 1`. The
BATFET disables. The battery cannot receive current from VBUS through
BATFET while `BATFET_DIS = 1`.

`BATFET_RST_WVBUS = 1` re-enables the BATFET on the next VBUS unplug.
This is the "unplug USB after ship + re-plug" recovery path.
`BATFET_RST_EN = 0` prevents a fresh VBUS insert from re-enabling the
BATFET on its own.

---

## 11. Serial console (USB CDC)

Connect USB. Open a serial terminal at 115200 baud. The device echoes
its command prompt. Type `HELP` for the current list.

Common verbs:

| Verb | Effect |
|:---|:---|
| `HELP` | List available commands. |
| `STATUS` | One-shot state dump. |
| `GET_TIME [-v]` | Read the RTC. |
| `SET_TIME <ISO>` | Write UTC to the RTC + NVS + PCF RAM_byte. |
| `RTC_DUMP` | Hex-dump of the PCF85063A registers. |
| `NVS_PRINT [ON|OFF]` | Toggle boot-time NVS printout. |
| `LOGLEVEL [level]` | Runtime log-level override. See Section 12. |
| `GESTURE` | Dump the wrist-gesture state. |
| `BATT_TEST [ON|OFF]` | Enter battery-test mode on next boot. |
| `BLACKBOX [ON|OFF]` | Background telemetry logger. |
| `REC_AUDIO [ON|OFF]` | 5-second voice annotation on selected modes. |
| `WHOAMI` | I2C sensor identification + broker `hw_alive` status. |
| `TEMP_DUMP` | Read every onboard temperature source. |
| `PM_DUMP` | Dump the PM lock inventory. |
| `RGB <r> <g> <b>`  | Bench-poke the WS2812. `RGB AUTO` releases. |
| `FS_LS [/sd/path]` | List an SD directory. |
| `FS_CAT </sd/path>` | Dump an SD file to the console. |
| `SHIPMODE` | Drop the BATFET now. |
| `REBOOT` | Clean software reset. |

---

## 12. Log-level policy

The firmware carries a runtime log-level policy (see `main.c`
Stage 17 §3.2 block).

Precedence:

1. An NVS-stored level (0..5) always wins.
2. Sentinel `0xFF` selects the auto policy.

Auto policy:

- USB CDC connected -- level `INFO`.
- USB CDC absent (battery-only) -- level `WARN`.

The `LOGLEVEL` verb changes the level at runtime. Values: `off`,
`error`, `warn`, `info`, `debug`, `verbose`, `auto`. `LOGLEVEL AUTO`
restores the sentinel.

The `WARN` default keeps the battery-only log quiet during a
protocol run. Mode-entry, mode-exit, session-open, and session-close
milestones stay at `INFO`. Per-tick status prints stay at `DEBUG`
after the Stage 18 audit. See `LOG_LEVEL_POLICY.md`.

---

## 13. Files on the SD card

Layout:

```
/sd/
  data/
    battery/    -- BATT_TEST CSVs and BLACKBOX telemetry.
    env/        -- FCM_ENV recordings.
    lsm/        -- LSM submenu recordings.
    mic/        -- FCM_MIC recordings (WAV).
    ppg_bcg/    -- FCM_PPG_BCG recordings.
    ...
```

Every CSV carries a header comment. The header includes the firmware
version (`fw=`), the hardware version (`hw=`), a boot sequence number
(`boot_seq=`), and the mode name. Downstream analysis groups by
these fields. The `battery_tag` NVS field is reserved for future
cell-provenance tagging (Stage 19 §7).

---

## 14. Boot log provenance

Every boot logs one banner from `main.c` and one line per driver
`_init()`. The pattern:

```
MAIN: KOMPIC hw=iv7.1 fw=0.4.18
BOOT_POWER: boot_logic v0.3.0
BROKER: driver v0.2.1
BME688: driver v0.2.0
BQ25619: driver v0.2.0
...
```

Any log capture identifies the source tree that produced it. The
per-driver version comes from `<NAME>_DRIVER_VERSION` at the top of
each driver's header. The umbrella `KOMPIC_FW_VERSION` bumps every
time any driver bumps.

---

## 15. Known limitations (pre-Mk1b)

- **Display.** The AMOLED receptacle footprint is mirrored on iv7.1.
  The panel is offline. Kompic runs headless until Mk1b arrives.
- **Touch.** The CST9217 shares the panel FPC. Touch is offline on
  iv7.1 for the same reason.
- **GPS.** The MAX-M10S is not populated on iv7.1. The GPS task is
  disabled at compile-time.
- **Cold-boot delay.** The device takes ~4 seconds from BQ25619 wake
  to STANDBY. The delay is BQ25619 QON timing + ESP boot ROM + DRV
  auto-cal settling. No firmware-only shortening is possible.
- **Battery runtime.** ~2.5 hours between charges at the Stage 18
  baseline. Stage 19 addresses the drain.

---

## 16. Where to look next

- `docs/build_info/Mk1_build_reports/` -- stage-by-stage engineering
  log. Every recent decision is there.
- `docs/build_info/reference_files/ASD-STE100_reference.md` -- writing
  style used in this manual.
- `docs/build_info/reference_files/LOG_LEVEL_POLICY.md` -- log-level
  classification.
- `docs/build_info/reference_files/IV71_TO_MK1B_FIRMWARE_DELTA.md` --
  firmware changes for Mk1b bring-up.
- `firmware/esp-idf/components/field_capture/firmware_version.h` --
  umbrella firmware version.

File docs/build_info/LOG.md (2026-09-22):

# LOG -- loose-ends journal

**Purpose.** Append-only chronological journal for stray observations,
half-baked ideas, and side-quest asks that don't yet belong in a
Stage_NN doc or a memory note. Everything here is a breadcrumb --
promote to a proper venue (Stage_NN, memory/*, ADR, dedicated doc)
when the item crosses the "actually a work item" threshold, and
leave a `-> promoted: <link>` note behind so the trail stays intact.

**Format.** Reverse-chronological date headers. Under each date,
bullets with:
  - The observation / ask itself (one sentence).
  - `source:` where it came from (convo mid-Stage-NN / commit hash /
    fw version / bench log line).
  - `owner:` where it'll be resolved (Stage_NN, memory slug, "TBD").

**Split rule.** When this file passes ~500 lines, split by year
(`LOG_2026.md`, `LOG_2027.md`). Not before. Weekly splits add
friction (which bucket does the Sunday-night item go in?), and
`git grep` across one file is easier than across twelve.

**Not for.** Real work items, driver docs, stage plans, memory
notes. Those all have proper homes. This is the "I noticed X"
scratchpad.

---

## 2026-09-15

- **Boot ordering feels off.** Ivan wants a rebuild starting from
  core things -> per-device boots -> UI up first so the user sees
  progress -> drv-final buzz for finish. Not this stage.
  `source:` convo mid-Stage-30. `owner:` Stage 30.6 or Stage 31.
- **UI is a frankenstein.** Per-tile duplication + parallel
  broker/refresh pipelines. Rebuild scheduled.
  `source:` convo mid-Stage-30 2026-09-15.
  `owner:` Stage 31 -- [[project_lvgl_foundations_rebuild_planned]].
- **Encoder dead on iv8.0 unit.** `ENC` verb shows cw=0 ccw=0 net=0
  during active rotation; polled loop is alive; hardware suspect.
  Ivan flashing Arduino field-demo sketch to A/B hw-vs-fw next week.
  `source:` bench log fw 0.4.71-4.74.
  `owner:` Stage 30.5 -- [[project_encoder_dead_on_iv80]].
- **I2C hw_fsm_reset crash under rapid sleep/wake stress.** Core 0
  stuck in `i2c_hw_fsm_reset` -> `vPortExitCritical` during a
  `max17048_read16` after ~6+ double-tap cycles. ESP-IDF v5.5.2
  legacy I2C driver latent issue, not Stage 30.
  `source:` crash log fw 0.4.68 + fw 0.4.73.
  `owner:` i2c_master API migration (Stage 22b groundwork) --
  [[project_i2c_hw_fsm_reset_crash]].
- **Landscape via MADCTL + SW-swap is double-transformed.** Rebuild
  or use LVGL SW rotation.
  `source:` bench log fw 0.4.73 -- Stage_30 §4.3a.
  `owner:` Stage 30.3b (LVGL SW rotation, path A/B in §4.3a).
- **Touch may not reset 30 s idle-sleep.** Ivan flagged
  "feels like 30 s and its done". CST9217 press-edge already calls
  `field_capture_kick_activity()` but he hasn't retested after
  fw 0.4.74's mutex fix. Verify next flash.
  `source:` convo 2026-09-15. `owner:` next bench pass.
- **Diag pattern still ON.** 6 colored squares + white band on the
  main screen from Stage 30.2 §4.2g. Remove once landscape lands
  and rendering stays stable.
  `source:` fc 0.4.70 -- ui_main_screen.c `UI_MAIN_DIAG_PATTERN`.
  `owner:` next Stage 30 batch (after landscape decision).
- **BROKER: rtc_read: mutex timeout** intermittent warning during
  active navigation. Isolated occurrence during Stage 30 close-out
  bench; not blocking. Likely RTC read timing out against I2C
  contention window under UI activity.
  `source:` bench log fw 0.4.74, `data_broker/*` (tag `BROKER`).
  `owner:` monitor -- promote if recurring.
- **FLASH CLI verb landed (fw 0.4.75).** `FLASH [ON|OFF|<0..100>]`
  bypasses FCM_FLASHLIGHT mode-cycle so the LED works while the
  encoder is dead. Direct wrap around `flashlight_set_brightness`.
  Ivan's "least code" bridge to demo readiness.
  `source:` convo 2026-09-15. `owner:` shipped.
- **Log-tag legend landed.** `docs/build_info/LOG_TAGS.md` --
  canonical list of every ESP_LOG TAG in the tree, grouped by
  subsystem. New components add their tag there in the same
  commit. Rule: [[feedback-log-line-taxonomy]].
  `source:` convo 2026-09-15. Two known drifts flagged:
  `co5300_panel` + `co5300_pio` (lowercase), `XD` (mystery).
- **`XD` mystery tag.** Grep finds `static const char *TAG = "XD"`
  somewhere; origin unknown, unclear which C file. Hunt on next
  opportunistic pass through that area.
  `source:` LOG_TAGS.md build 2026-09-15. `owner:` TBD.

## 2026-09-18

- **28 px data-row font shears on env tile (fw 0.4.79).** Header
  ("BME688 T/H/P/Gas") at UI_FONT_TITLE renders cleanly, but the
  5 data rows (same font, `theme_subtext` colour, subject-driven
  content) render with thin white outline, blur, italic-like shear
  and antialiasing artefacts. Same chronic shear class as main-
  clock italic. Possible contributors: partial-refresh strip
  boundary alignment, subtext colour interacting with sub-pixel
  rendering, subject-driven repaint vs. static content. Same
  bucket as the recurring main-clock italic issue; both need a
  proper render-pipeline audit at some point.
  `source:` bench log fw 0.4.79. `owner:` chronic display-render
  issue (grouped with main-clock italic).
- **Env-tile header should be chip-name only (not name + desc).**
  "BME688 T/H/P/Gas" is too wide at 28 px and overlaps the newly-
  larger switch. Just "BME688" fits cleanly. Same probably applies
  to every other sensor tile header (Stage 32 sweep). Small +
  cosmetic; deferred.
  `source:` convo 2026-09-18. `owner:` next env_tile touch.
- **Tile order reordered (System=0, Env=1) fw 0.4.80.** New
  workflow rule: the tile under active iteration moves to Col 1
  so bench access is one swipe-down; DEFAULT_TILE_COL=1 already
  auto-lands there. Codified as
  [[feedback_active_tile_at_col_1]].
  `source:` convo 2026-09-18. `owner:` shipped.
- **Stage 31.2 landed cleanly on fw 0.4.78.** Env tile now
  subject-bound; label content driven by ui_subjects drain timer
  at 200 ms cadence. But bench-invisible: the tile power switch is
  cropped by AMOLED corner arc so Ivan can't turn BME688 ON to see
  live values. Sensor tiles across the board still ignore the 15%
  corner-safe zone -- env is the first fix (0.4.79). Every other
  tile inherits the same pattern until Stage 32 sweep.
  `source:` bench log fw 0.4.78.
  `owner:` Stage 32 for the systemic sweep;
  env done opportunistically in 31.2b (fw 0.4.79).
- **CLI-parity for tile toggles pending.** Ivan wants
  `BME688 [ON|OFF|PARK]` (and per-sensor variants) so headless bench
  can drive the sensors without needing to hit a touchscreen switch.
  Skipping now that the switch is being made reachable in 0.4.79;
  promote if it comes back.
  `source:` convo 2026-09-18. `owner:` TBD, small verb per sensor.
- **i2c_hw_fsm_reset crash: fourth instance.** fw 0.4.78 same
  backtrace (bq25619_read_reg -> i2c_hw_fsm_reset -> IRQ WDT),
  triggered mid-navigation ("swipe slower" per Ivan). Not going to
  keep logging fresh instances -- the pattern is confirmed. Root
  fix is [[project_i2c_hw_fsm_reset_crash]] i2c_master migration.
  `source:` bench log fw 0.4.78.
- **Stage 31.4a bench findings + polish items (fw 0.4.85).**
  - GPS tile subject-bound + robust status line: works well.
    "no data -- check antenna/wiring" and "acquiring..."
    variants tested by having chip silent.
  - **ATOMIC SYNC button not pressable at all** on env-run
    bench. Not blocking (needs GPS fix to be useful anyway,
    which needs bench hw fix). Suspect: button style /
    z-order / disabled-state stuck. Investigate when GPS is
    actually alive. `owner:` post-hw-fix bench pass.
  - **Switch responsiveness slightly finicky** system-wide
    -- occasional missed tap, sometimes double-fire from a
    single tap. Not new to 31.4a; probably CST9217 debounce
    or LVGL indev tuning. Batch with other UI polish later.
    `owner:` polish sweep during Stage 33 (`ui_notif_overlay` /
    shutdown_overlay pass).
  - Tile registry TILE_NAMES in fc_cli.c is stale (reflects
    old order pre-reorder). Cosmetic; TILE `<n>` still works.
    `owner:` next fc_cli touch.
- **Stage 31.3 = DONE fw 0.4.83.** Drawer opens + closes cleanly
  via unified cb_main_gesture; GPS sub-tile still works; alarm
  still works. Stage 31 rollup in Stage_31 doc §10-11.
  `source:` bench log fw 0.4.83. `owner:` shipped.
- **MAX-M10S wiring: 2 pins wrong on this Mk1b unit.** Manual
  §4.1.4 review: VIO_SEL was GND (forces 1V8 mode on a 3V3
  design), should FLOAT for 3V3. SAFEBOOT_N was tied to 3V3
  (undefined + fights internal 1kΩ to TIMEPULSE), should
  FLOAT. Ivan bench-fixing now. Correct wiring durably captured
  in [[project_max_m10s_wiring]]. Earlier hallucination from
  Claude was the source of both errors -- apologies.
  `source:` MAX-M10S Integration Manual review 2026-09-18.
  `owner:` Ivan bench fix, then Stage 31.4 to exercise.
- **GPS integration manual review complete.** Driver-side is
  fine (no "wake up" command needed, chip auto-acquires on
  power). Firmware issue is unlikely; more likely the wiring
  errors above + antenna. Diagnostic adds recommended for
  31.4: UBX-MON-RF (antenna status), UBX-NAV-PVT (fix
  telemetry), UBX-NAV-SAT (per-sat C/N0), dynamic model
  CLI verb (wrist/pedestrian/etc). Details in Stage_31 §11.
  `source:` PDF review agent 2026-09-18.
- **LVGL 9 gesture routing gotcha (worth remembering).**
  `LV_OBJ_FLAG_GESTURE_BUBBLE` is a DEFAULT flag on every
  non-screen object (`lv_obj.c:593`). Gesture dispatch walks
  UP the parent chain while the flag is set, firing on the
  first object WITHOUT it. Only screens lack the flag by
  default. So event cbs registered on any non-screen object
  for `LV_EVENT_GESTURE` receive NOTHING unless you explicitly
  clear `GESTURE_BUBBLE` on the object. Bit us on Stage 31.3
  drawer close (two flash cycles chasing a phantom guard bug).
  `source:` bench log fw 0.4.81/0.4.82 + LVGL source dive
  (lv_indev.c:1781, lv_obj.c:593). `owner:` reference; may
  save future memory if it recurs.
- **31.3 drawer opens but won't close (fw 0.4.81) -> hotfix
  in 0.4.82.** Swipe-up opens drawer cleanly (slide anim
  visible, main under drawer). Swipe-down on Env row 0 doesn't
  close it -- 0.4.82 rewrites the sub-tile guard to use explicit
  tile_registry.subtile_handle comparison instead of
  `lv_obj_get_y > 0` (which may be racy vs. tileview's gesture
  handler timing), plus adds an ENTRY LOGD so we can bench-trace
  every dispatch. `source:` bench log fw 0.4.81.
  `owner:` Stage_31 §9.3b.
- **i2c crash: 5th instance.** GPS-nav-triggered but same
  `bq25619_read_reg -> i2c_hw_fsm_reset` backtrace. Not going
  to log further instances -- pattern is fully confirmed.
  Real fix stays i2c_master API migration; escalating from
  "eventual" to "blocker for stress-tolerance" since it now
  fires on every meaningful bench session.
  `source:` bench log fw 0.4.81.
- **Encoder registered rotations mid-fiddle on fw 0.4.77.** `FIELD:
  mode -> alarm/compass/alarm/fl (top)` fired during unplanned
  handling; polled loop is picking up detents when it wants to. So
  firmware IS reading the pin toggles, root cause is at the wire /
  contact level (intermittent open). Arduino sketch A/B still worth
  doing but hardware-suspect list now clearly narrows to soldering
  or a partial-lift on the encoder's shield-pin. `source:` bench
  log fw 0.4.77. `owner:` -- [[project_encoder_dead_on_iv80]]
  (memory needs update: FW confirmed alive when it registers;
  swap suspect to solder joint / wire fatigue).
- **fw 0.4.77 sleep-skip prophylactic: didn't help this crash.**
  Second bench cycle crashed after ~10 s awake activity (2 swipes +
  1 double-tap ignore), no sleep in the trigger sequence. Confirms
  the crash isn't sleep-triggered per se -- it's cumulative bus
  stress under fast UI navigation. Sleep-skip stays landed (still
  reduces unnecessary bus load when panel is off), but it's clearly
  not the right knob. Real fix stays i2c_master API migration.
  `source:` bench log fw 0.4.77. `owner:` --
  [[project_i2c_hw_fsm_reset_crash]].
- **Blue-light overlay reads too-dark orange on DARK theme.** On
  LIGHT theme the amber tint looks correct; on DARK it renders as a
  muddy dark orange because the overlay opacity + blend was tuned
  against the light bg. Needs per-theme opacity or a different blend
  mode for DARK. Not blocking, do next time we're in
  `light_tile_create_overlay()`.
  `source:` bench log fw 0.4.76 (Stage 31.1 verify pass).
  `owner:` opportunistic when touching light_tile.
- **Italic/shear on main-screen time + battery still recurring.**
  Random, intermittent, transient -- classic display refresh quirk.
  Not caused by Stage 31.1 (labels only changed text-color inheritance).
  Present since Stage 29 / 30 full-frame render. Ivan flag: "at
  earliest convenience when along the way; not blocking but kinda
  critical". `source:` bench log fw 0.4.76.
  `owner:` next display-touching stage; candidate root causes: LVGL
  partial-refresh strip boundary + font atlas alignment.
- **Stage 31.1 plumbing verified on fw 0.4.76.** `PANE_STYLE: init: 5
  pane styles created` fires once at boot; `PANE_STYLE:
  reapply_theme: theme=DARK -- 5 styles updated, screen invalidated`
  fires at UI init. Main + settings render clean; swipes responsive;
  tile titles noticeably crisper (side-effect of centralising
  pad/radius on style_pane_root). Visual DARK<->LIGHT toggle test
  incomplete -- see i2c crash below.
  `source:` bench log fw 0.4.76. `owner:` promoted to Stage_31 §9.1.
- **i2c_hw_fsm_reset crash: third instance.** IRQ WDT on Core 0 mid-
  navigation after ~3 swipes + 2 double-tap sleep/wake cycles + 3
  more swipes. Victim this time: bq25619_read_reg (task_battery_fn),
  not max17048. Same backtrace shape as 0.4.68 / 0.4.73. Confirms
  this is bus-level (any I2C reader can be the victim), not a per-
  driver bug. Escalation: bump priority of i2c_master API migration.
  `source:` bench log fw 0.4.76. `owner:` --
  [[project_i2c_hw_fsm_reset_crash]] (memory updated with third data
  point).

---

## 2026-09-16

- **Boot-mode force-hardcode landed as stopgap.** `field_capture.c`:
  right after `nvs_load()`, `s_mode = FCM_FLASHLIGHT; s_in_submenu =
  false;` -- does NOT call `nvs_save_mode()` so persisted mode is
  untouched. Only there because encoder is dead and there's no other
  way to select a mode. Delete this block once the encoder is fixed;
  device will resume remembering mode normally.
  `source:` convo 2026-09-16. `owner:` revert after
  [[project_encoder_dead_on_iv80]] resolves.

---

I (4464) BOOT_DISP: boot_logic v0.4.1
I (4465) BOOT_DISP: CST9217 ACK @ 0x5A -- display module present
I (4466) co5300_pio: co5300_panel_io ready (queue=8, chunk=32768B, cs=10)
I (4466) co5300_panel: co5300_panel v0.1.3 created (rst=3, rotate90=0)
I (5156) BOOT_DISP: CO5300 ready (410x502 logical, brightness ~80%)
E (5376) gpio: gpio_install_isr_service(530): GPIO isr service already installed
I (5376) CST9217: CST9217 init OK @ 0x5A, boot=220489 us
I (5377) BOOT_DISP: CST9217 touch ready (task_touch_fn will run on Core 0)
I (5377) MAIN: display ready
I (5377) LVGL_DISP: lvgl_ui_display v0.2.5 (force_no_panel=0)
I (5378) LVGL: Starting LVGL task
I (5451) LVGL_DISP: LVGL touch indev bound to g_touch_q
I (5452) LVGL_DISP: LVGL up -- panel=CO5300 touch=CST9217 strip=410x60 px (73800 B x2)
I (5453) APP_NVS: UI settings loaded: theme=0 bright=20 bluelit=0 autobr=0
I (5453) UI_BROKER: UI settings queue created
I (5453) UI_SUBJ: init: env(5) + gps(9 str + 2 int) subjects created; g_env_q + g_gps_q up
I (5454) PANE_STYLE: init: 5 pane styles created (root/drawer/row/card/subtext)
I (5463) STATUS_BAR: Status bar init OK — 5 dots
I (5470) MAIN_SCR: DIAG pattern on: 6 squares R G B W Y C (L->R) + white band
I (5471) MAIN_SCR: Main screen built
E (5502) temperature_sensor: temperature_sensor_install(136): Already installed
I (5502) SYS_TILE: Internal temp sensor: ESP_ERR_INVALID_STATE (already owned by esp_ts_ensure_init, tile shows N/A)
I (5503) SYS_TILE: System tile init OK
I (5536) ENV_TILE: BME688 tile init OK
I (5554) HEALTH_TILE: MAX30101 tile init OK
I (5562) HAPTIC_TILE: haptic_tile_init
I (5588) HAPTIC_TILE: DRV2605 tile init OK
I (5593) LIGHT_TILE: light_tile_init
I (5615) LIGHT_TILE: VEML6030 tile init OK
I (5636) GPS_TILE: MAX-M10S tile init OK (subject-bound, normal + photo views)
I (5650) GPS_TILE: GPS sub-tile init OK
I (5659) RTC_TILE: PCF85063A tile init OK
I (5677) COMPASS_TILE: LIS3MDLTR tile init OK
I (5686) IMU_TILE: imu_tile_init
I (5708) SETTINGS_SCR: Settings screen built — 9 tiles, start col 1
I (5723) ALARM_TILE: Alarm screen built (3 slots, lazy overlay)
I (5723) UI_NAV: Main screen registered
I (5723) UI_NAV: Settings drawer registered (gestures dispatch via main cb)
I (5723) UI_NAV: Alarm screen registered
I (5724) DISP_SLEEP: Display sleep init OK
I (5727) SHUTDOWN_OVL: Shutdown overlay init OK (lv_layer_sys)
I (5729) LIGHT_TILE: Blue-light overlay created on lv_layer_top()
I (5732) LVGL_UI: Initial tile status update complete (9 tiles)
I (5733) PANE_STYLE: reapply_theme: theme=DARK -- 5 styles updated, screen invalidated
I (5737) LVGL_UI: UI init complete - 9 tiles + alarm screen, theme=DARK, brightness=20%
I (5737) UI_SUBJ: start_drain: LVGL drain timer running (200 ms)
I (5837) LVGL_DISP: screens built (theme=0 bright=20%)
I (5838) CST9217: Task started on Core 0
I (5838) LVGL_DISP: LVGL tasks up -- UI_REFRESH + SETTINGS_SAVER + TOUCH
I (5838) BOOT_TASKS: Creating 16 tasks...
I (5838) BME688: Task started on Core 0
I (5839) LSM6DSV16X: Task started on Core 0
I (5839) LIS3MDL: Task started on Core 0
I (5839) LIS3MDL: Calibration task started on Core 0
I (5839) TMP117: Task started on Core 0
I (5840) VEML6030: Task started on Core 0
I (5840) BQ25619: Task started on Core 0
I (5841) PCF85063: Task started on Core 0
I (5842) HAPTIC: Haptic task started (Core 0)
I (5844) ALARM: Alarm task started (1 Hz poll, Stage C active)
I (5845) MAX_M10S: Task started on Core 0
I (5845) FIELD: driver v0.3.2
I (5846) FC_SHDN: shutdown watcher armed: hold 4000 ms to ship (buzz warn at 2000 ms). auto-shdn cap = 30 min (1800 s).
I (5846) BOOT_TASKS: All tasks created:
I (5865) BOOT_TASKS:   Core 0: ENV | IMU | MAG | MAG_CAL | HR | SKIN | LIGHT | BAT | RTC | HAPTIC | ALARM | GPS
I (5866) BOOT_TASKS:   Core 1: FIELD_CAPTURE
I (5866) BOOT_TASKS:   Unpinned: SHUTDOWN_WATCHER (priority double-click ship mode) | RTC_CLI (stdin SET_TIME/GET_TIME)
I (5866) MAIN: Phase 2 boot complete - field_capture running on Core 1
I (5867) main_task: Returned from app_main()
I (5846) FC_BATT: BLACKBOX: disabled by NVS flag -- task exiting
I (5868) FC_COMMON: boot_seq=221 restored mode=usb (submenu=0)
I (5868) SDCARD: Mounting SDMMC 1-bit at /sd (CLK=38 CMD=39 DAT0=40)
I (5928) SDCARD: Card mounted: name=SDABC, capacity=59645 MiB
I (5939) FC_COMMON: SD mounted (59542 MiB free)
I (5939) FIELD: field_capture_init OK (mode=fl boot_seq=221)

[RTC] Boot-time state:
  [RTC] 2026-09-18T23:52:25 UTC
  Commands:
    AUTOSHDN [<min>|OFF]             auto-shutdown minutes (0/OFF = perma-on, default 120, reboot to apply)
    BATT_TEST [ON|OFF]               enter battery-test mode on next boot (no arg = state)
    BLACKBOX [ON|OFF]                background telemetry logger (reboot to start/stop)
    BLACKBOX_CADENCE <s>             sample cadence in seconds (default 10, range 1..3600)
    BQ [EN|BOOST [ON|OFF] | SHIPMODE] BQ25619 command surface (no arg = dump)
    DISP [ON|OFF]                    CO5300 panel sleep/wake (batt-test tool; no arg = state)
    ENC [RESET]                      encoder status + reg dump (RESET = zero counters)
    FLASH [ON|OFF|<0..100>]          flashlight LED (bypass encoder; no arg = show state)
    FS_CAT </sd/path>                dump a file to console
    FS_LS [/sd/path]                 list SD directory
    FUEL                             MAX17048 VERSION + VCELL + fuel % (needs cell attached)
    GESTURE                          dump wrist-gesture state + LPF value
    GET_TIME [-v]                    read RTC now (-v also dumps NVS + RAM_byte)
    GPS_DYNMODEL [PORT|STAT|PED|AUTO|SEA|AIR1|AIR2|AIR4|WRIST|BIKE]  set MAX-M10S dynamic model (no arg = show)
    GPS_MONRF                        dump UBX-MON-RF snapshot (antenna status, noise, AGC)
    GPS_VIEW [normal|photo|toggle]   switch GPS tile between telemetry + photo layouts (no arg = state)
    HAPTIC [EN|PLAY <n>|CAL|SWEEP START|STOP|UI [<n>]]  (no arg = dump)
    HELP                             this list
    LIGHT [EN|AUTO|BLUE [ON|OFF] | BR [<0..100>]]       (no arg = dump)
    LOGLEVEL [OFF|E|W|I|D|V|AUTO]    runtime esp_log level (no arg = show current)
    LVGL_FORCE [ON|OFF]              force LVGL up on next boot even without a panel (no arg = state)
    LVGL_SCREENSHOT                  capture active screen -> /sd/lvgl_fb/*.png
    NVS                              dump every persisted NVS record (on-demand)
    NVS_PRINT [ON|OFF]               toggle boot-time NVS printout (no arg = dump)
    PM_DUMP                          dump PM lock inventory now
    REBOOT                           esp_restart() -- clean SW reset
    REC_AUDIO [ON|OFF]               5 s voice annotation before ENV/MOTION/SKIN (no arg = state)
    RGB <r> <g> <b> | AUTO           bench-poke WS2812 / release override (no arg = dump)
    RTC                              PCF85063A status + register dump
    RTC_DUMP                         hex dump of all 18 PCF85063A registers
    SET_TIME YYYY-MM-DDTHH:MM:SS     write UTC + persist to NVS + PCF RAM_byte
    SHIPMODE                         drop BATFET now (escape when button stuck)
    STATUS                           one-shot state dump (uptime, sensors, batt, heap)
    TEMP_DUMP                        read every onboard temp source (waits for stable, non-zero)
    TILE [list | <n> | <name>]       jump tileview to a tile (bench-testable under LVGL_FORCE)
    TOUCH                            dump CST9217 touch state (last x/y, event count, pressed)
    WHOAMI                           I2C sensor identification + hw_alive status
I (13106) UI_NAV: → Settings (drawer opens)
[GPS] MON-RF: no snapshot yet -- either MON-RF not enabled
             or chip is silent (check antenna/wiring first).
I (60479) FIELD: [DISP] reason=idle-timeout (30000 ms idle)
I (60479) BOOT_DISP: sleep -- panel to DISPOFF+SLPIN
Guru Meditation Error: Core  0 panic'ed (Interrupt wdt timeout on CPU0). 

Core  0 register dump:
PC      : 0x400559d5  PS      : 0x00060234  A0      : 0x8037875f  A1      : 0x3fc9ec60  
--- 0x400559d5: _xtos_set_intlevel in ROM
A2      : 0x00060223  A3      : 0x00000001  A4      : 0x00060221  A5      : 0x00000000  
A6      : 0x60027000  A7      : 0x00000000  A8      : 0x00000000  A9      : 0x3fc9ec10  
A10     : 0x3c140b28  A11     : 0xffffffff  A12     : 0x3fc9ec58  A13     : 0x00060023  
A14     : 0x00000001  A15     : 0x0000cdcd  SAR     : 0x0000001e  EXCCAUSE: 0x00000005  
EXCVADDR: 0x00000000  LBEG    : 0x40056f5c  LEND    : 0x40056f72  LCOUNT  : 0xffffffff  
--- 0x40056f5c: memcpy in ROM
--- 0x40056f72: memcpy in ROM
Core  0 was running in ISR context:
EPC1    : 0x40041a6b  EPC2    : 0x400559e0  EPC3    : 0x00000000  EPC4    : 0x400559d5
--- 0x40041a6b: ets_delay_us in ROM
--- 0x400559e0: _xtos_set_intlevel in ROM
--- 0x400559d5: _xtos_set_intlevel in ROM

Backtrace: 0x400559d2:0x3fc9ec60 0x4037875c:0x3fc9ec70 0x4037805d:0x3fc9ec90 0x4037875c:0x3fccfdb0 0x403824be:0x3fccfdc0 0x4208b36e:0x3fccfde0 0x4208b559:0x3fccfe00 0x4208c69b:0x3fccfe60 0x4207340e:0x3fccfea0 0x42073476:0x3fccfed0 0x42012b97:0x3fccff00 0x40382141:0x3fccff40
--- 0x400559d2: _xtos_set_intlevel in ROM
--- 0x4037875c: vPortClearInterruptMaskFromISR at /home/ivan/.espressif/v5.5.2/esp-idf/components/freertos/FreeRTOS-Kernel/portable/xtensa/include/freertos/portmacro.h:560
--- (inlined by) esp_pm_impl_isr_hook at /home/ivan/.espressif/v5.5.2/esp-idf/components/esp_pm/pm_impl.c:1077
--- 0x4037805d: _xt_lowint1 at /home/ivan/.espressif/v5.5.2/esp-idf/components/xtensa/xtensa_vectors.S:1240
--- 0x4037875c: vPortClearInterruptMaskFromISR at /home/ivan/.espressif/v5.5.2/esp-idf/components/freertos/FreeRTOS-Kernel/portable/xtensa/include/freertos/portmacro.h:560
--- (inlined by) esp_pm_impl_isr_hook at /home/ivan/.espressif/v5.5.2/esp-idf/components/esp_pm/pm_impl.c:1077
--- 0x403824be: vPortClearInterruptMaskFromISR at /home/ivan/.espressif/v5.5.2/esp-idf/components/freertos/FreeRTOS-Kernel/portable/xtensa/include/freertos/portmacro.h:560
--- (inlined by) vPortExitCritical at /home/ivan/.espressif/v5.5.2/esp-idf/components/freertos/FreeRTOS-Kernel/portable/xtensa/port.c:514
--- 0x4208b36e: i2c_hw_disable at /home/ivan/.espressif/v5.5.2/esp-idf/components/driver/i2c/i2c.c:266
--- 0x4208b559: i2c_hw_fsm_reset at /home/ivan/.espressif/v5.5.2/esp-idf/components/driver/i2c/i2c.c:726
--- 0x4208c69b: i2c_master_cmd_begin at /home/ivan/.espressif/v5.5.2/esp-idf/components/driver/i2c/i2c.c:1648
--- 0x4207340e: max17048_read16 at /home/ivan/Projekti/Elektronika/Kompic-Wearable/kompic-wearable/firmware/esp-idf/components/max17048/max17048.c:45
--- 0x42073476: max17048_read_soc_pct100 at /home/ivan/Projekti/Elektronika/Kompic-Wearable/kompic-wearable/firmware/esp-idf/components/max17048/max17048.c:66
--- 0x42012b97: task_battery_fn at /home/ivan/Projekti/Elektronika/Kompic-Wearable/kompic-wearable/firmware/esp-idf/components/bq25619/bq25619.c:391
--- 0x40382141: vPortTaskWrapper at /home/ivan/.espressif/v5.5.2/esp-idf/components/freertos/FreeRTOS-Kernel/portable/xtensa/port.c:139

Core  1 register dump:
PC      : 0x4037bd26  PS      : 0x00060434  A0      : 0x8037f4f0  A1      : 0x3fca9770  
--- 0x4037bd26: esp_cpu_wait_for_intr at /home/ivan/.espressif/v5.5.2/esp-idf/components/esp_hw_support/cpu.c:64
A2      : 0x00060423  A3      : 0x00000000  A4      : 0x00060420  A5      : 0x3fca96a0  
A6      : 0x00060820  A7      : 0x3fca995c  A8      : 0x8037935d  A9      : 0x3fca9730  
A10     : 0x3fc9e028  A11     : 0x3fca9760  A12     : 0x00060820  A13     : 0x00060423  
A14     : 0x60023000  A15     : 0x0000abab  SAR     : 0x0000001d  EXCCAUSE: 0x00000005  
EXCVADDR: 0x00000000  LBEG    : 0x00000000  LEND    : 0x00000000  LCOUNT  : 0x00000000  

Backtrace: 0x4037bd23:0x3fca9770 0x4037f4ed:0x3fca9790 0x40381208:0x3fca97b0 0x40384c92:0x3fca97d0 0x40382141:0x3fca97f0
--- 0x4037bd23: xt_utils_wait_for_intr at /home/ivan/.espressif/v5.5.2/esp-idf/components/xtensa/include/xt_utils.h:82
--- (inlined by) esp_cpu_wait_for_intr at /home/ivan/.espressif/v5.5.2/esp-idf/components/esp_hw_support/cpu.c:55
--- 0x4037f4ed: esp_pm_impl_waiti at /home/ivan/.espressif/v5.5.2/esp-idf/components/esp_pm/pm_impl.c:1087
--- 0x40381208: esp_vApplicationIdleHook at /home/ivan/.espressif/v5.5.2/esp-idf/components/esp_system/freertos_hooks.c:56
--- 0x40384c92: prvIdleTask at /home/ivan/.espressif/v5.5.2/esp-idf/components/freertos/FreeRTOS-Kernel/tasks.c:4350
--- 0x40382141: vPortTaskWrapper at /home/ivan/.espressif/v5.5.2/esp-idf/components/freertos/FreeRTOS-Kernel/portable/xtensa/port.c:139

ELF file SHA256: cb90fa04d

Rebooting...
ESP-ROM:esp32s3-20210327
Build:Mar 27 2021
rst:0xc (RTC_SW_CPU_RST),boot:0x2f (SPI_FAST_FLASH_BOOT)
Saved PC:0x403813e5
--- 0x403813e5: esp_restart_noos at /home/ivan/.espressif/v5.5.2/esp-idf/components/esp_system/port/soc/esp32s3/system_internal.c:164
SPIWP:0xee
mode:DIO, clock div:1
load:0x3fce2820,len:0x173c
load:0x403c8700,len:0xe80
--- 0x403c8700: _stext at ??:?
load:0x403cb700,len:0x31cc
entry 0x403c8948
--- 0x403c8948: call_start_cpu0 at /home/ivan/.espressif/v5.5.2/esp-idf/components/bootloader/subproject/main/bootloader_start.c:25
I (24) boot: ESP-IDF v5.5.2-dirty 2nd stage bootloader
I (24) boot: compile time Sep 10 2026 21:17:19
I (24) boot: Multicore bootloader
I (25) boot: chip revision: v0.2
I (25) boot: efuse block revision: v1.3

Okay, so it managed to flash even tho you got cut off.

crashed when i tryed to type gps_dynmode after gps_monrf. Ok so bench is immanent blocker for this.
what is crashing i2c again? we are still missing the button for dynmode

I (35052) BOOT_DISP: sleep -- panel to DISPOFF+SLPIN
I (109209) MAX_M10S: DYNMODEL -> AIR<1G (6) queued to UART
[GPS] DYNMODEL <- AIR<1G (6) : ESP_OK
      watch DEBUG log for UBX-ACK-NAK if not supported.
[GPS] DYNMODEL = AIR<1G (6)

Also, if safeboot is held high, would that keep the chip off? I think i floated everything, vcc and vio to 3v3, only safeboot is left high at 3v3. or would the chip show signs of life even if safeboot held high?

seems to work fine when not core panicking. Pick up where you left, close stage 31 after i flash and confirm, and prepare 32md file for a fresh session

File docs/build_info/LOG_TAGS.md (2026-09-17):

# LOG_TAGS -- canonical log-tag legend

**Date opened:**  2026-09-15
**Date closed:**  (open -- living reference)
**Status:**       OPEN

**Purpose.** Every `ESP_LOGx` and CLI `printf` line in this firmware
carries an ALL_CAPS component tag so `git grep <TAG>` locates the
origin in one hop. This file is the authoritative list. Per
[[feedback-log-line-taxonomy]], when a new component lands, add its
tag here in the same commit. Existing lines migrate opportunistically,
never in a mass-rename pass.

**Format.** Tag ↔ source component ↔ one-line purpose. Grouped by
subsystem for scan-ability, not alphabetically.

---

## Core / boot / app layer

| Tag | Source | Purpose |
| --- | --- | --- |
| BOOT_HW | boot_logic/boot_hw_init.c | Always-on hardware bring-up (I2C, sensors, BQ). |
| BOOT_DISP | boot_logic/boot_display.c | Display + panel_io + panel init, sleep/wake. |
| BOOT_TASKS  | boot_logic/boot_tasks.c | FreeRTOS task spawning. |
| BOOT_PM | boot_logic/boot_pm.c | Power-management lock inventory dump. |
| BOOT_POWER  | boot_logic/boot_power.c | Reset-reason + wakeup source classification. |
| APP | app_core/* (post-Stage-34.1 rename) | Main mode state machine + FCM_* dispatch. |
| FIELD | field_capture/field_capture.c | LEGACY -- migrating to APP. |
| FC_COMMON | field_capture/fc_common.c | Button + encoder polled state machines. |
| FC_MODES | field_capture/fc_modes.c | Recording modes (ENV, MOT, QVAR, etc.). |
| FC_MODES_LSM| field_capture/fc_modes_lsm.c | LSM submenu recording paths. |
| FC_REC | field_capture/fc_rec.c | CSV recording plumbing. |
| FC_SHDN | field_capture/fc_shutdown.c | Shutdown watcher + auto-shdn timer. |
| FC_BATT | field_capture/fc_battery_test.c | Battery-test mode CSV logger. |
| FC_PPG_BCG  | field_capture/fc_ppg_bcg.c | PPG+BCG combined recording. |
| FC_CLI | field_capture/fc_cli.c | USB-CDC command surface. |
| APP_NVS | app_nvs/* | NVS flash init + partition mount. |
| NVS_CFG | nvs_cfg/* | Per-driver NVS config load/save. |

## Data + UI infrastructure

| Tag | Source | Purpose |
| --- | --- | --- |
| BROKER | data_broker/* | Cross-core sensor data-flow bus. |
| UI_BROKER | ui_broker/* | UI-side settings + state channels. |
| UI_NAV | lvgl_ui/ui_navigation.c | Screen + gesture routing. |
| LVGL_UI | lvgl_ui/lvgl_ui.c | Top-level LVGL init + tile registry. |
| LVGL_DISP | lvgl_ui/lvgl_ui_display.c | LVGL port + display setup. |
| LVGL_SHOT | lvgl_ui/lvgl_ui_screenshot.c | Frame-buffer PNG capture. |

## Screens + tiles

| Tag | Source | Purpose |
| --- | --- | --- |
| MAIN_SCR | lvgl_ui/ui_main_screen.c | Watch-face + clock + battery. |
| STATUS_BAR | lvgl_ui/ui_status_bar.c | 5-dot state row. |
| SETTINGS_SCR  | lvgl_ui/ui_settings_screen.c | Tileview + settings screen. |
| ALARM_TILE | lvgl_ui/alarm_screen.c | Alarm slot overlay. |
| NOTIF_OVL | lvgl_ui/notification_overlay.c | Toasts / overlays. |
| SHUTDOWN_OVL  | lvgl_ui/shutdown_overlay.c | Shutdown-hold LED-mirror overlay. |
| DISP_SLEEP | lvgl_ui/display_sleep.c | Panel sleep/wake helpers. |
| HEALTH_TILE | lvgl_ui/health_tile.c | MAX30101 PPG tile. |
| HAPTIC_TILE | lvgl_ui/haptic_tile.c | DRV2605 haptic tile. |
| LIGHT_TILE | lvgl_ui/light_tile.c | VEML6030 ambient-light tile. |
| BAT_TILE | lvgl_ui/battery_tile.c | BQ25619 + MAX17048 tile. |
| SYS_TILE | lvgl_ui/system_tile.c | Heap + uptime + die-temp tile. |
| GPS_TILE | lvgl_ui/gps_tile.c | MAX-M10S GPS tile. |
| RTC_TILE | lvgl_ui/rtc_tile.c | PCF85063 clock tile. |
| ENV_TILE | lvgl_ui/env_tile.c | BME688 environment tile. |
| COMPASS_TILE  | lvgl_ui/compass_tile.c | LIS3MDL compass tile. |
| IMU_TILE | lvgl_ui/imu_tile.c | LSM6DSV16X IMU tile. |

## Drivers

| Tag | Source | Purpose |
| --- | --- | --- |
| BQ25619 | bq25619/bq25619.c | Charger IC. |
| BQ_CMD | bq25619/bq25619_cmd.c | BQ CLI surface. |
| MAX17048 | max17048/max17048.c | Fuel gauge. |
| BME688 | bme688/* | Env sensor. |
| LSM6DSV16X | lsm6dsv16x/* | 6-axis IMU. |
| LSM_EMB | lsm6dsv16x/lsm_embedded.c | LSM MLC / embedded funcs. |
| LIS3MDL | lis3mdl/* | Magnetometer. |
| VEML6030 | veml6030/veml6030.c | Light sensor. |
| VEML_CMD | veml6030/veml6030_cmd.c | VEML CLI surface. |
| TMP117 | tmp117/* | Skin temp sensor. |
| MAX30101 | max30101/* | PPG (heart-rate LEDs). |
| MAX_M10S | max_m10s/* | GPS. |
| PCF85063 | pcf85063/pcf85063.c | RTC. |
| PCF_CMD | pcf85063/pcf85063_cmd.c | PCF CLI surface. |
| DRV2605 | drv2605/drv2605.c | Haptic driver. |
| DRV_CMD | drv2605/drv2605_cmd.c | DRV CLI surface. |
| HAPTIC_TILE | drv2605/haptic_tile.c | (Owned by drv2605 comp.) |
| WS2812 | ws2812/ws2812.c | RGB LED. |
| WS2812_CMD | ws2812/ws2812_cmd.c | RGB CLI surface. |
| RGB_POLICY | rgb_policy/* | LED colour policy. |
| FLASHLIGHT | flashlight/* | LEDC-PWM flashlight. |
| CST9217 | cst9217/* | Touch controller. |
| MIC_PDM | mic_pdm/* | PDM microphone. |
| SDCARD | sdcard/* | SD host / mount. |
| USB_MSC | usb_msc/* | USB mass-storage. |
| ALARM | alarm/* | Alarm task. |
| ENCODER | encoder/encoder.c | Rotary encoder driver. |
| ENC_CMD | encoder/encoder_cmd.c | Encoder CLI surface. |
| FUSION | fusion/* | Sensor fusion (mag+IMU). |

## Panels (Stage 30 additions)

| Tag | Source | Purpose |
| --- | --- | --- |
| co5300_panel | co5300/co5300_panel.c | CO5300 esp_lcd panel wrapper. **Non-conforming (lowercase)** -- rename to `CO5300_PANEL` next time this file is edited. |
| co5300_pio | co5300/co5300_panel_io.c | CO5300 custom panel_io. **Non-conforming** -- rename to `CO5300_PIO`. |

## Known-drifting / TBD

| Tag  | Note |
| ---- | ---- |
| XD | Mystery tag surfaced by grep. Origin unknown; hunt on next opportunistic pass. |
| FIELD | Legacy; migrates to `APP` when field_capture -> app_core rename lands (Stage 34.1). |

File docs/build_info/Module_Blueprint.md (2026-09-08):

# Kompic Mk1 — Self-contained Module Blueprint

**Purpose.** Every hardware capability (sensor, actuator, LED, panel, radio,
audio path, ...) in this firmware is a **self-contained module** that exposes
the *same set of core functions* to two UIs at once:

- **CLI** (`fc_cli.c` verbs typed over USB-Serial-JTAG).
- **Screen** (LVGL tile + touch + eventually encoder click).

Both UIs are thin wrappers over the module's **command surface** — no logic
lives in the CLI dispatcher or the tile event handler that could not be
reached from the other side. Turning the flashlight on by tapping the button
on the LIGHT tile and typing `LIGHT ON` at the CLI hit the same
`flashlight_cmd_set(true)` code path.

**Why this discipline.**

- The bench is headless most of the time (iv7.1 display dead; Mk1b in fab).
  Every module must be testable via CLI alone — see
  `feedback_cli_first_testability.md`.
- Duplication (a tile that writes NVS directly, a CLI verb that writes NVS
  directly) is the #1 cause of two-way bugs: one path forgets to publish, or
  clamps differently, or persists to a slightly different key. Command
  surface is the single truth.
- Future outlets are cheap to add: a BLE app, a preset button, a scripted
  test rig — each is another thin wrapper over the same surface.

This document specifies the file layout, the command-surface contract, the
persistence + broker patterns, and the drop-in checklist for a new module.
Existing modules pre-date this blueprint; they will be migrated
opportunistically per `feedback_group_work_by_venue.md`, not in one big
sweep.

---

## 1. What counts as a module

One module = one hardware capability the user can meaningfully address.
Examples:

| Module | Capability | Primary I/O |
|:---|:---|:---|
| `bq25619` | Battery charger + BATFET | I2C0 |
| `veml6030`| Ambient light + backlight auto | I2C0 |
| `drv2605` | Haptic driver | I2C0 |
| `max_m10s`| GNSS receiver | UART + 1PPS GPIO |
| `co5300`  | AMOLED display panel | QSPI |
| `cst9217` | Capacitive touch controller | I2C0 + INT GPIO |
| `ws2812`  | Status LED strip | RMT peripheral |
| `sdcard`  | Micro-SD storage | SDMMC |
| `mic_pdm` | PDM microphone | I2S |
| `pcf85063`| Battery-backed RTC | I2C0 |

Meta-modules (that own no hardware directly) still fit the pattern:

- `alarm`  — schedules haptic + notification events.
- `nvs_cfg` — system-wide flags (`batt_test`, `blackbox`, `lvgl_force`, ...).

---

## 2. File layout per module

```
components/<module>/
├── CMakeLists.txt
├── <module>.h          Public API — driver primitives + task fn + broker glue.
├── <module>.c          Driver implementation. Owns the hardware, publishes to
│                       data_broker, may spawn a task.
├── <module>_cmd.h      Command surface (THIS BLUEPRINT).  Same set of
│                       operations exposed to CLI + tile + any future outlet.
├── <module>_cmd.c      Command surface implementation. Thin — every command
│                       forwards to the driver or NVS, then returns.
├── <module>_tile.h     LVGL tile descriptor + tile-specific helpers.
├── <module>_tile.c     LVGL widgets. Event handlers call *_cmd_* functions;
│                       they DO NOT talk to the driver directly.
└── <module>_tests.c    (optional) Bench harness reachable via `TEST <module>`
                        CLI verb once the test infra lands.
```

**Naming.** `<module>_cmd_<verb>()`. Verb is lower_snake_case matching the CLI
token (`bq_cmd_ship_mode`, `light_cmd_auto_brightness_set`,
`gps_cmd_atomic_sync`). This keeps grep-ability high — one grep for
`<module>_cmd_` lists every operation the module supports.

---

## 3. Command surface — the contract

Every module MUST expose at least these categories in `<module>_cmd.h`:

| Category | Signature shape | Purpose |
|:---|:---|:---|
| **enable**  | `esp_err_t X_cmd_enable_set(bool on)` | Power on/off, task start/stop, sensor arm/disarm. |
| | `bool X_cmd_enable_get(void)` | Live state (matches what STATUS + tile widget show).|
| **config**  | `esp_err_t X_cmd_<field>_set(T value)` | One setter per user-facing config field. |
| | `T X_cmd_<field>_get(void)` | One getter per field. Return the currently ACTIVE |
| | | value, not the requested one, if they differ. |
| **action**  | `esp_err_t X_cmd_<action>(void)` | One-shot verbs: `calibrate`, `sync`, `reset`, |
| | | `zero_height`, `dump_regs`, `ship_mode`, ... |
| **dump** | `void X_cmd_dump(fc_print_fn print)` | Human-readable state dump. Uses the caller-supplied |
| | | `print(const char *fmt, ...)` so the same routine |
| | | feeds either serial or an LVGL text area. |
| **status**  | `void X_cmd_status_summary(char *out, | One-liner for the global STATUS printout. |
| | size_t max)` | |

Return-code convention:

- `ESP_OK` — command accepted, state updated.
- `ESP_ERR_INVALID_ARG` — parse / range failure at the command boundary.
- `ESP_ERR_INVALID_STATE` — hardware not present, prerequisite unmet.
- `ESP_ERR_NOT_SUPPORTED` — command exists but not implemented on this HW.
- other `esp_err_t` — passed through from driver.

**No LVGL types in `<module>_cmd.h`.** The command surface is UI-agnostic;
adding an outlet must not require touching the surface. LVGL includes live
only in `<module>_tile.c`.

**No CLI parsing in `<module>_cmd.c`.** All arg parsing (string → int, ON/OFF
→ bool) happens in the CLI dispatcher. The command surface takes typed
arguments only.

---

## 4. Persistence — NVS pattern

If a config field must survive reboot:

1. `nvs_cfg.c` gets the key + getter + setter (unless the value is bulky, in
   which case the module opens its own NVS namespace).
2. `<module>_cmd_<field>_set(value)` writes NVS first, then applies to the
   driver. If the driver reject fails, the NVS write is left intact (next
   boot will retry the apply).
3. `<module>` init reads NVS on boot and pushes the value into the driver.
4. No other code writes to that key. CLI verb and tile handler both call
   `<module>_cmd_<field>_set()`.

See `nvs_cfg_sys_get/set_batt_test()` for the canonical shape.

---

## 5. Broker publish pattern (Blueprint 4)

Modules that produce continuous data (sensors) publish to `data_broker`:

- Driver task calls `broker_<module>_write(&payload)` once per acquisition
  cycle.
- Consumers (`_tile.c` refresh, `field_capture` CSV writers, `_cmd_status_*`
  routines) read via `broker_<module>_read(&out)`.
- `broker_<module>_hw_alive()` / `_get_status()` expose lifecycle state.
- The command surface never sits between driver → broker; it operates on
  the driver directly.

---

## 6. Two-outlet dispatch — concrete shape

### 6.1 CLI dispatch (`fc_cli.c`)

```c
if (startswith_ci(line, "LIGHT")) {
    const char *arg = line + 5;
    while (*arg == ' ' || *arg == '\t') arg++;

    if (*arg == 0 || startswith_ci(arg, "STATUS")) {
        light_cmd_dump(printf_wrapper);
        return;
    }
    if (startswith_ci(arg, "ON"))  { light_cmd_enable_set(true);  return; }
    if (startswith_ci(arg, "OFF")) { light_cmd_enable_set(false); return; }
    if (startswith_ci(arg, "AUTO")) {
        light_cmd_auto_brightness_set(true);
        return;
    }
    // ...
}
```

Rule of thumb: the CLI block is a parse-forward-print sandwich, never
> ~30 lines. Anything longer signals that logic is leaking into the CLI
that should live in `_cmd.c`.

### 6.2 Tile event dispatch (`<module>_tile.c`)

```c
static void cb_power_toggle(lv_event_t *e)
{
    lv_obj_t *sw = lv_event_get_target(e);
    bool desired = lv_obj_has_state(sw, LV_STATE_CHECKED);
    esp_err_t r = light_cmd_enable_set(desired);
    if (r != ESP_OK) {
        // revert the switch visually so the widget mirrors reality
        lv_obj_clear_state(sw, LV_STATE_CHECKED);
        ESP_LOGW(TAG, "light enable rejected: %s", esp_err_to_name(r));
    }
}
```

The tile does not touch NVS, does not touch the driver, does not know about
the broker beyond reading through it for display. Every user-initiated
mutation goes through a `_cmd_` call.

### 6.3 Preset-button / future outlet

A preset button on the case wired to a GPIO would end up as:

```c
static void isr_preset_pressed(void *arg) {
    // ISR-safe: queue a request, the handler task calls
    // <module>_cmd_<action>() on the desired module.
}
```

Same surface. No changes to CLI, no changes to tile.

---

## 7. Global registration

- **CLI verb table**: `fc_cli.c` `rtc_cli_handle_line()` dispatcher. One
  `if (startswith_ci(...))` block per module. Update HELP + STATUS in the
  same edit (see `feedback_group_work_by_venue.md`).
- **Tile registry**: `components/lvgl_ui/tile_registry.c`. One line, one
  `&<module>_tile_desc` pointer. See `tile_registry.h` for the descriptor
  contract.
- **Task table**: `components/boot_logic/boot_tasks.c` for sensor tasks;
  LVGL-side tasks live in `lvgl_ui_display_start_tasks()`. Gate on hardware
  presence at spawn time.

---

## 8. Checklist — adding a new self-contained module `<X>`

1. `mkdir components/<X>/` and add `CMakeLists.txt`.
2. Driver: `<X>.h` + `<X>.c` — hardware primitives, task fn, broker publish
   if applicable. Version macro `<X>_DRIVER_VERSION` at top of `<X>.h`.
3. Command surface: `<X>_cmd.h` + `<X>_cmd.c` covering the categories in §3.
4. Broker glue: `broker_<X>_read/write/get_status/hw_alive/get_enabled/
   set_enabled` in `data_broker.{c,h}` (if a sensor).
5. NVS keys (if any): `nvs_cfg_sys_get/set_<X>_<field>()` in `nvs_cfg.{c,h}`
   OR own namespace in `<X>_cmd.c`.
6. Tile: `<X>_tile.h` + `<X>_tile.c` — exports `const tile_desc_t <X>_tile_desc`.
   Widgets call `<X>_cmd_*()` only. Tile lives in `components/<X>/`, not
   `components/lvgl_ui/`.
7. Register in `components/lvgl_ui/tile_registry.c` (`#include "<X>_tile.h"`,
   add pointer to `s_tiles[]`).
8. Register in `components/boot_logic/boot_tasks.c` if a task is needed
   (or `lvgl_ui_display_start_tasks()` for display-side tasks).
9. Register CLI verb in `components/field_capture/fc_cli.c`:
   - dispatcher block (parse → `_cmd_*()` → print)
   - HELP line
   - STATUS line (via `<X>_cmd_status_summary()` if the state fits on one row)
10. Update REQUIRES in whichever component's `CMakeLists.txt` needs to link
    against `<X>`.
11. Boot bring-up: add `<X>_init()` call in `boot_hw_init.c` (or
    equivalent phase). Boot log should print `<X>: driver v<version>` as
    the first line.
12. Provenance banners: driver `_init` first line uses `<X>_DRIVER_VERSION`;
    bump `KOMPIC_FW_VERSION` in `firmware_version.h`.
13. Test from the bench headless: `<VERB> STATUS` and each mutation returns
    a meaningful reply. If LVGL is up, `TILE <name>` reaches the widget too.

---

## 9. Migration status (2026-09-08)

None of the 10 tile modules yet expose `<X>_cmd.h` as specified. They all
directly touch broker + NVS + hardware from their tile event handlers.
This works today but violates §6.2 and creates the CLI/tile drift risk.

Migration approach:

- **No big-bang refactor.** Group per-venue: when a stage touches a module's
  files for another reason, extract its `_cmd.c` in the same pass. See
  `feedback_group_work_by_venue.md`.
- **New modules ship compliant.** From this blueprint's date forward,
  reviewers will bounce a PR that adds a module without a `_cmd.h`.
- **Priority migration order** (based on user-facing frequency):
  1. `bq25619` (SHIPMODE + batt_test already partially command-shaped in `nvs_cfg`).
  2. `veml6030` (backlight + auto-brightness — highest touch traffic).
  3. `pcf85063` (SET_TIME + GET_TIME + `rtc_cli_*` -- already close to shape).
  4. `drv2605` (haptic effect picker).
  5. Rest — as they get touched.

Track migration progress in each stage's `§8 Next steps` block.

---

## 10. Anti-patterns

- Tile event handler that writes NVS. → Move to `_cmd_<field>_set()`.
- CLI verb that computes a threshold before calling driver. → Move
  computation into `_cmd_*()`, keep CLI parse-only.
- Broker read inside `_cmd_*()`. → Broker is a data channel, `_cmd_*` is a
  control channel. If the command needs data, take it as an argument or
  read the driver's own state, not the broker snapshot.
- Two modules touching each other's NVS keys directly. → Add a
  `<other>_cmd_*` call.
- `<module>_tile.c` including anything from another `<module2>_tile.c`. →
  Cross-tile calls must go through the command surface, not through UI.

---

## References

- `feedback_cli_first_testability.md` — every module must be reachable via
  CLI on a headless bench.
- `feedback_group_work_by_venue.md` — migration bundling.
- `feedback_stage_log_workflow.md` — session cadence around stage docs.
- `components/lvgl_ui/tile_registry.h` — tile descriptor contract used in §7.
- `components/nvs_cfg/nvs_cfg.h` — NVS pattern used in §4.
- `components/field_capture/fc_cli.c` — CLI dispatcher used in §6.1.

This document supersedes the folkloric "Blueprint 3 §5 / Blueprint 5 §7"
references scattered through the codebase — those were a personal shorthand
never committed anywhere. The tile-descriptor + registry contract that they
implicitly named lives in `tile_registry.h`; the module-surface contract
that they *didn't* name lives here.

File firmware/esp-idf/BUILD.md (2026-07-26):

# Kompic Mk I firmware — build, flash, serial

**Target chip:** ESP32-S3 (WROOM-1U-N16R8: 16 MB flash / 8 MB octal PSRAM).
**Repo path:** `firmware/esp-idf/`
**Hardware baseline:** iv7.1.
**Latest fw:** `KOMPIC_FW_VERSION` in `components/field_capture/firmware_version.h`.

---

## 1. One-time environment setup

```
# Install ESP-IDF v5.5.2 under ~/.espressif/ once (see esp-idf docs).
# Then set up a shell alias:
echo 'alias get_idf=". $HOME/.espressif/v5.5.2/esp-idf/export.sh"' >> ~/.bashrc
```

## 2. Per-terminal setup

```
get_idf
cd firmware/esp-idf
```

## 3. Common commands

```
idf.py menuconfig                        # Kconfig UI (same as the VS Code cog icon)
idf.py build                             # compile
idf.py -p /dev/ttyACM0 flash monitor     # flash + serial monitor (Ctrl-] to exit)
idf.py fullclean                         # wipe build/ and managed_components/
idf.py set-target esp32s3                # only if switching chip family
```

**VS Code ESP-IDF toolbar missing?** Open **`firmware/esp-idf/`** as the workspace root. The extension only detects the project when `CMakeLists.txt` + `sdkconfig` sit at the workspace root.

---

## 4. Required menuconfig settings

**Set once after `idf.py set-target esp32s3`, then verify with `grep -E "^CONFIG_(FATFS_LFN|PM|FREERTOS|TINYUSB)" sdkconfig`.**

### 4.1 Board-level

| Path | Setting |
|---|---|
| Serial flasher config → Flash size | **16 MB, QIO, 80 MHz** |
| Partition Table → Custom | **`partitions.csv`** |
| Component config → ESP System Settings → CPU frequency | **240 MHz** |
| Component config → ESP PSRAM → SPI RAM support | **ON, mode Octal, 80 MHz** |
| Component config → FreeRTOS → Kernel → `configTICK_RATE_HZ` | **1000** |
| Component config → FAT Filesystem support → Long filename support | **Long filename buffer in heap** (mandatory — default 8.3 rejects `s0058_r0001_annot.wav`-style names) |

### 4.2 LVGL fonts (for display path; safe even without display)

| Path | Setting |
|---|---|
| Component config → LVGL configuration → Font Usage → Enable built-in fonts | **Monaco 8 through 48** (all sizes on) |

### 4.3 Power management (fw ≥ 0.4.2)

| Path | Setting | Kconfig symbol |
|---|---|---|
| Component config → Power Management → Support for power management | **ON** | `CONFIG_PM_ENABLE=y` |
| Power Management → Enable DFS at startup | **ON** | `CONFIG_PM_DFS_INIT_AUTO=y` |
| Power Management → Put lightsleep-related functions in IRAM | **ON** | `CONFIG_PM_SLP_IRAM_OPT=y` |
| Power Management → Enable profiling counters for PM locks | **ON** | `CONFIG_PM_PROFILING=y` |
| FreeRTOS → Kernel → configUSE_TICKLESS_IDLE | **ON** | `CONFIG_FREERTOS_USE_TICKLESS_IDLE=y` |
| FreeRTOS → Kernel → Idle tick count threshold before entering sleep | **3** | `CONFIG_FREERTOS_IDLE_TIME_BEFORE_SLEEP=3` |
| FreeRTOS → Kernel → Enable FreeRTOS to collect run time stats | **ON** | `CONFIG_FREERTOS_GENERATE_RUN_TIME_STATS=y` |
| FreeRTOS → Kernel → configRUN_TIME_COUNTER_TYPE | **uint32_t** | `CONFIG_FREERTOS_RUN_TIME_COUNTER_TYPE_U32=y` |

### 4.4 USB Mass Storage (Stage 11 Item A, ≥ 0.3.0)

Applied via `sdkconfig.defaults` on first build after the managed component pulls in.

| Path | Setting | Kconfig symbol |
|---|---|---|
| Component config → TinyUSB Stack → TinyUSB task priority | **5** | `CONFIG_TINYUSB_TASK_PRIORITY=5` |
| TinyUSB Stack → TinyUSB Classes → USB MSC | **ON** | `CONFIG_TINYUSB_MSC_ENABLED=y` |
| TinyUSB Stack → TinyUSB Classes → MSC → USB MSC FIFO size | **4096** | `CONFIG_TINYUSB_MSC_BUFSIZE=4096` |
| TinyUSB Stack → TinyUSB Classes → USB Serial (CDC-ACM) | **OFF** | `# CONFIG_TINYUSB_CDC_ENABLED is not set` |

### 4.5 What NOT to touch

- **Component config → ESP System Settings → Channel for console output** must stay **UART0**.
- **… → Channel for console secondary output** must stay **USB Serial/JTAG**.
- These two keep `esptool` + `idf.py monitor` working on every boot except while USB MSC mode is active.

---

## 5. Partition table

`partitions.csv` in this directory. 16 MB layout:

```
nvs      16 KB   sensor cal, UI, NVS-command-state
otadata   8 KB   (reserved for future OTA)
factory   3 MB   main app
storage  ~12 MB  spiffs/data reserved
```

Not usually touched. If you change it, run `idf.py fullclean` first.

---

## 6. SD card durability rule (mandatory)

Any code that writes to SD **must** guarantee per-row durability. `fflush()` alone leaves 0-byte files on power loss.

- **Pattern A** (< 10 Hz writers): `fopen("a")` + write + `fclose` per row.
- **Pattern B** (≥ 10 Hz writers): keep open, `fflush()` + `fsync(fileno(f))` per row.

Rule and both patterns documented at the top of `components/field_capture/field_capture.c`. See also memory `[[feedback-sd-write-durable]]`.

---

## 7. Serial CLI (USB-Serial-JTAG @ 115200)

Reachable via `idf.py monitor` or any serial terminal. Case-insensitive. Line-terminated (`\n` or `\r`). Type `HELP` any time to reprint this list.

### 7.1 Time

```
GET_TIME [-v]                    read RTC now (-v also dumps NVS + RAM_byte)
SET_TIME YYYY-MM-DDTHH:MM:SS     write UTC + persist to NVS + PCF RAM_byte (0x03)
RTC_DUMP                         hex dump of all 18 PCF85063A registers
```

### 7.2 NVS config

```
NVS_PRINT [ON|OFF]               toggle boot-time NVS printout (no arg = dump)
BATT_TEST [ON|OFF]               enter battery-test mode on next boot (no arg = state)
BLACKBOX [ON|OFF]                background telemetry logger (reboot to start/stop)
BLACKBOX_CADENCE <s>             blackbox sample cadence (default 10 s, range 1..3600)
```

### 7.3 Diagnostics

```
HELP                             re-print this command list
STATUS                           one-shot state dump (uptime, sensors, batt, heap, NVS)
WHOAMI                           I2C sensor identification + hw_alive status per chip
PM_DUMP                          dump PM lock inventory now (identical to boot dump)
```

### 7.4 Filesystem (SD)

```
FS_LS [/sd/path]                 list SD directory contents (default /sd)
FS_CAT </sd/path>                dump a file to console (capped at 32 KB)
```

### 7.5 Control

```
RGB <r> <g> <b> | RGB AUTO       bench-poke WS2812 (0..255) / release manual override
SHIPMODE                         drop BATFET (button-stuck escape). USB unplug needed to finish.
REBOOT                           esp_restart() -- clean SW reset
```

---

## 8. Modes (top-level encoder cycle)

Scroll encoder to select, click to enter. Colours are the standby-LED indicator.

| Mode | Colour | Purpose |
|---|---|---|
| MIC | red | 30 s mono WAV @ 16 kHz |
| ENV | green | BME688 + VEML6030 CSV |
| SKIN | pink | MAX30101 PPG + TMP117 CSV |
| FLASHLIGHT | white | encoder = brightness while ON |
| ALARM | purple | DRV wake-alarm test |
| COMPASS | magenta alt | LIS3MDL heading (10 s figure-8 cal on first press) |
| ECG | yellow/purple alt | LSM6DSV16X QVAR touch |
| TEMP | fire strobe | all onboard temp sensors printed 1 Hz |
| LSM | yellow | gateway to LSM submenu (click to enter) |
| USB_MSC | cyan | click → SD becomes USB drive to host. Click again OR unplug USB → esp_restart(). See `components/usb_msc/` |

**LSM submenu:** MOTION → BCG → STEPS → MLC_COLLECT → TAP_DBG. Click enters, tap-Z-double OR button-double exits.

---

## 9. NVS-flagged battery-run modes

Both toggled via serial and applied on next reboot.

- **BATT_TEST** — replaces FCM with a fixed-cadence power-baseline logger. Every 10 s: `/sd/data/battery/batt_<boot_seq>.csv`, one row: `t_ms, iso_utc, soc_temp_c, batt_mv, batt_pct, charging, vbat_adc_mv, heap_free_kb, cpu_mhz, sensors_on, idle_pct`. 15-min uptime cap disabled. Sensors parked. Escape: `SHIPMODE` or `REBOOT` via serial.
- **BLACKBOX** — background telemetry that runs alongside normal FCM. Every `bb_cadence_s` seconds (default 10): `/sd/data/blackbox/bb_<boot_seq>.csv` with ~35 columns covering every broker + system state. Self-exits if `batt_test` is on. See report §BLACKBOX for column schema.

---

## 10. Bench routine (per-change)

1. Read the roadmap item / handoff.
2. Change code, `idf.py build`.
3. Flash + monitor: `idf.py -p /dev/ttyACM0 flash monitor`.
4. Verify boot log (PM banner, NVS dump, hw_alive lines).
5. Run the relevant mode; verify against bench expectations.
6. Snapshot the source: `python3 hardware/Reflow_info/reference_files/make_archive.py <label>`.
7. Bump the touched driver's `_DRIVER_VERSION` (PATCH) + `KOMPIC_FW_VERSION` in `firmware_version.h`.
8. Commit is Ivan's ([[feedback-commits]]).

---

## 11. Vbat ADC hack (temporary, iv7.1)

Between screen data pads on GPIO9 (ADC1_CH8) — 5k1-5k1 divider from Vbat to GND, optional 100 nF to GND. Read via `vbat_adc_read_mv()` in `field_capture.c`. TEMPORARY: remove when the screen returns to the FPC OR when mk2's BQ25896 lands with its integrated VBAT ADC.

```
Vbat ── 5k1 ─┬── GPIO9 ─── (opt 100 nF) ── GND
             │
            5k1
             │
            GND
```

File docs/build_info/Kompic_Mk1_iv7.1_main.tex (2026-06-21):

\documentclass[11pt,a4paper]{article}
\usepackage[margin=20mm]{geometry}
\usepackage{graphicx}
\usepackage{booktabs}
\usepackage{array}
\usepackage{xcolor}
\usepackage{colortbl}
\usepackage{enumitem}
\usepackage{fancyhdr}
\usepackage{titlesec}
\usepackage{hyperref}
\usepackage{float}
\usepackage{eurosym}

% Colors
\definecolor{danger}{RGB}{180,30,30}
\definecolor{warning}{RGB}{200,120,0}
\definecolor{safe}{RGB}{30,120,30}
\definecolor{headerblue}{RGB}{30,60,110}
\definecolor{lightgray}{RGB}{240,240,240}
\definecolor{rowalt}{RGB}{248,248,248}

% Header/footer
\pagestyle{fancy}
\fancyhf{}
\fancyhead[L]{\small\textbf{Kompic Mk1 PCB iv7.2 — Reflow \& Assembly Reference}}
\fancyhead[R]{}
\fancyfoot[C]{\thepage}
\renewcommand{\headrulewidth}{0.4pt}

% Section styling
\titleformat{\section}{\Large\bfseries\color{headerblue}}{}{0em}{}[\vspace{-0.5em}\rule{\textwidth}{0.4pt}]
\titleformat{\subsection}{\large\bfseries}{}{0em}{}
\titleformat{\subsubsection}{\normalsize\bfseries}{}{0em}{}

% Danger/warning boxes
\newcommand{\dangerbox}[1]{\par\noindent\colorbox{danger!10}{\parbox{\dimexpr\textwidth-2\fboxsep}{%
\textcolor{danger}{\textbf{WARNING:}} #1}}\par\vspace{0.5em}}

\newcommand{\notebox}[1]{\par\noindent\colorbox{headerblue!8}{\parbox{\dimexpr\textwidth-2\fboxsep}{%
\textcolor{headerblue}{\textbf{NOTE:}} #1}}\par\vspace{0.5em}}

\setlength{\parindent}{0pt}
\setlength{\parskip}{0.4em}

\begin{document}

% ============================================================
% TITLE
% ============================================================
\begin{center}
{\LARGE\bfseries\color{headerblue} Kompic Mk1 PCB — Reflow \& Assembly Reference}\\[0.3em]
{\large by Ivan Porupski, 2026}
\end{center}

% ============================================================
% PAGE 1 — QUICK REFERENCE
% ============================================================
\section*{PAGE 1 — QUICK REFERENCE {\small(keep visible during reflow)}}

\subsection*{Step-by-Step Procedure}

\begin{enumerate}[nosep]
\item Verify baked paste on all pads; smear thin flux (NC-559-ASM) across pad areas — flux QFN/WSON center pads too. For the MEMS mic, flux pads \textbf{before} placing, keep flux out of the top port.
\item Place all ICs and connectors onto flux + baked paste (tweezers, magnification). \textbf{All parts go on now — single reflow pass.}
\item Photograph the populated board; \textbf{attach thermocouple} to board edge with kapton tape.
\item Place board on \textbf{cold} hot plate, run the profile below. Hands off once heating starts; let the cycle finish before handling.
\end{enumerate}

\subsubsection*{Reflow Profile}

\begin{figure}[H]
\centering

\caption{\small Target reflow profile — binding constraints from MAX-M10S, WS2812B-2020, FC31M2 crystal.}
\end{figure}

\vspace{-0.5em}
\begin{table}[H]
\centering
\begin{tabular}{@{}ll@{}}
\toprule
\textbf{Phase} & \textbf{Target} \\
\midrule
Ramp to preheat & 1--3°C/s, 60--90s to reach 150°C \\
Soak & 150--200°C hold, 60--120s \\
Ramp to peak & 2--3°C/s \\
\rowcolor{danger!10} \textbf{Peak} & \textbf{245°C, hold 10--20s} \\
\rowcolor{danger!10} \textbf{Above 217°C total} & \textbf{45--60s} \\
Cooling & $\leq$ 4°C/s, hot plate off, natural cool \\
Safe to handle & Below 50--60°C \\
\bottomrule
\end{tabular}
\end{table}

\clearpage

\subsubsection*{During Heating — Rules}
\begin{itemize}[nosep]
\item \textbf{Hands off once heating starts.} No tapping, no nudging, no adjusting.
\item Below 217°C: if a part visibly shifts, you may carefully reposition with tweezers. This is a rescue, not routine.
\item Above 217°C (solder liquid): \textbf{\textcolor{danger}{DO NOT TOUCH ANYTHING.}} Surface tension self-centers parts.
\item If board gets bumped above 180°C: \textbf{let the cycle finish.} Never pull board off hot plate. Fix damage after cool-down.
\item Operate hot plate buttons with stable grip, controlled press, steady hand.
\end{itemize}

\subsubsection*{After Cooling}
\begin{enumerate}[nosep]
\item Visual inspection under magnification — every IC, every QFN edge, every pad
\item Compare against pre-reflow photo — check for shifted/rotated parts
\item Multimeter: resistance on every power rail to GND (3.2V, 1.8V, 5V, SYS, VBUS)
\item If all clear $\rightarrow$ initial power-on (see Page 2)
\item If short found $\rightarrow$ find and fix bridge before applying any power
\end{enumerate}

\subsection*{Floor Life — Bag Opening (all parts, single reflow)}

All MSL parts are placed in one pass, so open all moisture-sensitive bags on reflow day and reflow within their floor-life windows. Bake any part whose window was exceeded before placing.

\begin{table}[H]
\centering
\begin{tabular}{@{}llll@{}}
\toprule
\textbf{Part} & \textbf{MSL} & \textbf{Floor Life} & \textbf{Bake Recovery} \\
\midrule
ESP32-S3-WROOM-1U & 3 & $\sim$1 week at $<$30°C, $<$60\% RH & 125°C / 24hr \\
\rowcolor{danger!10} MAX-M10S & \textbf{4} & 72hr at $<$30°C, $<$60\% RH & 192hr @ 40°C, RH $<$5\% \\
\rowcolor{danger!10} VEML6030 & \textbf{4} & 72hr at $<$30°C, $<$60\% RH & 192hr @ 40°C, RH $<$5\% \\
\bottomrule
\end{tabular}
\end{table}

\dangerbox{Single reflow pass only. The board carries bottom-side components (notably the USB-C connector) that prevent a clean second hot-plate cycle — there is no second pass for any part. Every IC, including the MAX-M10S, must be placed and reflowed together. Plan placement so nothing is missed.}

% ============================================================
% PAGE 2 — BRING-UP SEQUENCE
% ============================================================
\newpage
\section*{PAGE 2 — BRING-UP SEQUENCE}

\subsection*{Initial Power-On}

\textbf{Current-limited LiPo test:}
\begin{itemize}[nosep]
\item 4$\times$ 200$\Omega$ 250mW resistors in parallel (= 50$\Omega$, 1W) in series with LiPo positive
\item Dead short draws 74mA max — nothing smokes
\item Measure voltage across board: $\sim$3.7V = no short, $\sim$0V = short present
\item ESP32 will NOT boot through this resistor (needs 300mA+) — this is shorts-only testing
\item Remove resistors for actual boot testing
\end{itemize}

\textbf{With USB power meter arrives:}
\begin{itemize}[nosep]
\item Power via USB-C through meter
\item Watch current draw in real time
\item BQ25619 boots first, brings up SYS rail, TPS62840 produces 3.2V
\item Normal idle current (no firmware): expect tens of mA
\item Stage-2 board (charger + RTC + bus 1 sensors + mic + WS2812 + USB-C, no display / GPS / daughter): \textbf{$\sim$100--120 mA} observed on USB-C with the stage-2 smoke sketch running (ESP32 active, sensors initialised, flashlight breathe loop). Use as ballpark, not a hard pass/fail.
\item If current spikes to 1A+ immediately: unplug, find the short
\end{itemize}

\notebox{The TPS62840 is VSET-programmable. A 3.3V rail is possible; this board deliberately uses a \textbf{3.2V} rail, set by a \textbf{100k} VSET resistor (instead of 172k for 3.3V). All 3.3V-domain parts remain within spec at 3.2V.}

\subsection*{Verification Sequence}

\begin{enumerate}[nosep]
\item Check 3.2V rail with multimeter — TPS62840 working?
\item Check 1.8V rail — XC6206 working?
\item Connect USB-C, check if ESP32 enumerates as USB CDC device
\item If ESP32 alive $\rightarrow$ I2C bus scan on bus 1 and bus 2
\item Every device should respond at expected address:
\end{enumerate}

\textbf{Bus 1:} 0x10 (VEML6030), 0x1C (LIS3MDLTR), 0x48 (TMP117), 0x51 (PCF85063), 0x57 (MAX30101), 0x5A (CST9217), 0x6B (LSM6DSV16X), 0x76 (BME688)

\textbf{Bus 2:} 0x5A (DRV2605), 0x6A (BQ25619)

\notebox{The MAX-M10S GPS is \textbf{not on I2C} by default — it communicates over \textbf{UART1} (GPS-TX $\rightarrow$ GPIO17, GPS-RX $\rightarrow$ GPIO18). Verify it by opening the UART and confirming NMEA/UBX traffic, not via an I2C scan. (The M10S DDC/I2C interface at 0x42 exists as an option but is unused on this board.)}

\begin{enumerate}[nosep,start=6]
\item Missing I2C device = suspect bad solder joint on that IC
\item Open UART1 (GPIO17/18) and confirm the M10S streams NMEA/UBX — GPS solder-joint check
\item Test 5V boost (BQ25619 PMID) — enable via I2C, confirm 5V on rail
\end{enumerate}

% ============================================================
% PAGE 3 — HIDDEN PAD IC VERIFICATION
% ============================================================
\newpage
\section*{PAGE 3 — HIDDEN PAD IC VERIFICATION}

These ICs have pads entirely underneath — you cannot visually inspect joints.

\begin{table}[H]
\centering
\renewcommand{\arraystretch}{1.3}
\begin{tabular}{@{}p{3.2cm}p{3cm}p{8cm}@{}}
\toprule
\textbf{Part} & \textbf{Package} & \textbf{Verification Method} \\
\midrule
BQ25619 & WQFN-24 (4$\times$4mm) & Highest risk. Check I2C response @ 0x6A. Measure SYS rail voltage. Check for bridges between perimeter pads and center GND. \\
MAX-M10S & LCC-18 & Castellated + bottom pads. Verify by opening UART1 (GPIO17/18) and confirming NMEA/UBX output. No second reflow available — get it right first pass. \\
BME688 & LGA-8 & I2C response @ 0x76. Read chip ID register. \\
LSM6DSV16X & LGA-14 & I2C response @ 0x6B. Read WHO\_AM\_I register. \\
LIS3MDLTR & LGA-12 & I2C response @ 0x1C. Read WHO\_AM\_I register. \\
MSM261DGT003 & MEMS mic & No I2C — test by reading PDM data. Clock on GPIO47, data on GPIO48. \\
TMP117 & WDFN-6-EP (2$\times$2mm) & I2C response @ 0x48. Read temperature register ($\sim$room temp). \\
PCF85063ATL & DFN-10 & I2C response @ 0x51. Read seconds register (should increment). \\
\bottomrule
\end{tabular}
\end{table}

\dangerbox{For all hidden-pad ICs: before reflow, don't add extra paste on top of JLCPCB stencil paste. Just flux. Excess paste under QFN/LGA causes bridges.}

% ============================================================
% PAGE 4 — SOLDER & CONSUMABLES
% ============================================================
\newpage
\section*{PAGE 4 — SOLDER \& CONSUMABLES}

\subsection*{What's On The Board}

JLCPCB assembles 0402 passives using SAC305 lead-free paste at 255$\pm$5°C (economic assembly). No passive has a peak temp limit below 260°C — no concern.

JLCPCB also applies SAC305 solder paste to ALL remaining pads via stencil (verify in their gerber viewer that paste layer apertures exist for IC pads). Paste is baked (not reflowed) before shipping. Builder reflows these pads on the hot plate at 245°C in a single pass.

Solder jumpers are pre-connected with cuttable traces — no soldering needed during assembly. Cut trace to change default state.

\subsection*{Your Consumables}

\begin{table}[H]
\centering
\renewcommand{\arraystretch}{1.3}
\begin{tabular}{@{}p{3.5cm}p{3.5cm}p{1.8cm}p{5.5cm}@{}}
\toprule
\textbf{Item} & \textbf{Alloy} & \textbf{Melting} & \textbf{Use On This Board} \\
\midrule
NC-559-ASM flux & — & — & \textcolor{safe}{\textbf{YES}} — apply to baked paste, rework \\
Sn99.3/Cu0.7 wire 0.8mm & Lead-free & 227°C & \textcolor{safe}{\textbf{YES}} — hand solder, rework, bridges \\
SAC305 syringe paste & Sn96.5/Ag3.0/Cu0.5 & 217°C & \textcolor{safe}{\textbf{YES}} — backup paste, rework touch-up \\
Sn62.8/Pb36.8/Ag0.4 paste & \textcolor{danger}{\textbf{LEADED}} & 181°C & \textcolor{danger}{\textbf{DO NOT USE ON THIS BOARD}} \\
\bottomrule
\end{tabular}
\end{table}

\dangerbox{The board arrives with SAC305 (lead-free) paste from JLCPCB. Mixing leaded paste with lead-free creates a mixed alloy with unpredictable melting point (181--217°C range). Joints form weak grain boundaries and fail as intermittent connections. \textbf{Keep all solder on this board lead-free.}}

\notebox{Sn99.3/Cu0.7 wire and SAC305 paste are not identical alloys (wire has no silver, paste has 3\% silver). This is fine — the small composition difference is negligible during rework. Both are lead-free, both melt in the 217--227°C range.}

\notebox{\textbf{Dire-straits fallback (prototype only, observed on Mk I iv7.1):} when lead-free SAC305 syringe paste cannot be obtained in time (this build waited 50+ days for delivery), a 50:50 mix of KEK flux + leaded paste (Sn62.8/Pb36.8/Ag0.4) applied \emph{only} to hidden center pads (QFN/LGA/DFN EP) reflows acceptably under the standard 245°C profile. Mixed-alloy boundaries form at those joints, against the absolute warning above --- on this first board every joint held through up to $\sim$6 rework cycles. This is a \textbf{prototype-only} workaround; long-term thermal-fatigue characteristics are unknown. The dangerbox stands as the production rule. Treat this note as the "if you must" caveat, not as permission.}

% ============================================================
% PAGE 5 — PRACTICE RUN
% ============================================================
\newpage
\section*{PAGE 5 — PRACTICE RUN \& TEMPERATURE CALIBRATION}

\subsection*{Before Your First Real Reflow}

\textbf{You must do at least one practice run.} Use a bare scrap board or one of your spare JLCPCB boards (no components).

\subsubsection*{Equipment Needed}
\begin{itemize}[nosep]
\item K-type thermocouple + reader ($\sim$\euro{}5--10) — \textbf{non-negotiable for 245°C ceiling with parts that die at 250°C}
\item Kapton tape to attach thermocouple to board surface
\end{itemize}

\subsubsection*{Procedure}
\begin{enumerate}[nosep]
\item Tape thermocouple tip flat against board surface, near center
\item Run your full reflow profile using hot plate buttons
\item Log thermocouple reading at each phase vs hot plate display reading
\item Calculate offset (e.g., hot plate says 245°C but board surface is actually 252°C $\rightarrow$ set hot plate to 238°C)
\item Run again with corrected settings, verify board surface hits 245°C $\pm$3°C
\item Note your hot plate button settings for each phase — these are your calibrated numbers
\end{enumerate}

\subsubsection*{What You're Calibrating}
\begin{itemize}[nosep]
\item Hot plate display accuracy (could be $\pm$10--15°C off)
\item Ramp rates (how fast does your specific plate heat and cool)
\item Cooling behavior (does it cool faster or slower than 4°C/s naturally)
\item Your button-pressing rhythm for each phase transition
\end{itemize}

\dangerbox{Without this calibration, you are guessing. A hot plate that reads 10°C low means you're actually hitting 255°C when you think you're at 245°C — and your M10S and WS2812B are over spec. With no second reflow available, a botched first pass is expensive — calibrate first.}

% ============================================================
% PAGE 6 — DAUGHTER PCB
% ============================================================
\newpage
\section*{PAGE 6 — DAUGHTER PCB REFLOW}

The daughter PCB (small round board) ships attached to the main PCB but should be reflowed separately.

\subsection*{Components on Daughter PCB}
\begin{itemize}[nosep]
\item MAX30101EFD+T (OLGA-14, 3.3$\times$5.6mm) — face down, HR/SpO2
\item TMP117AIDRVR (WDFN-6-EP, 2$\times$2mm) — skin temperature
\item DRV2605LDGSR (VSSOP-10) — haptic driver
\item Associated 0402 passives (JLCPCB assembled)
\end{itemize}

\subsection*{Profile}
Same as main board: 245°C peak, 45--60s above 217°C, $\leq$4°C/s cooling.

\subsection*{Risk Level}
Lower than main board. No MSL 4 parts, no WS2812B, no crystal. All three ICs tolerate 260°C. The 245°C profile gives generous margin. This is a straightforward reflow.

\subsection*{Inter-Board Connection}
After both PCBs are individually verified working, connect with 12 silicone wires (hand soldered to pads on each board).

% ============================================================
% PAGE 7 — REWORK PROCEDURES
% ============================================================
\newpage
\section*{PAGE 7 — REWORK PROCEDURES}

\subsection*{Solder Bridges (most common issue)}

\textbf{Method:} Soldering iron + flux + solder wick
\begin{itemize}[nosep]
\item Apply flux to bridged area
\item Press wick onto bridge with iron tip
\item Wick absorbs excess solder
\item Localized — only the affected pins experience thermal stress
\item This is always the first thing to try
\end{itemize}

\subsection*{Misaligned / Shifted IC}

\textbf{If visible pads} (castellated, gull-wing): reflow individual pins with iron, nudge into alignment with tweezers while last pin is still molten.

\textbf{If hidden pads} (QFN, LGA): must remove entirely. Use hot air rework station (controlled temp, focused nozzle). Pre-heat board on hot plate to 150°C, then hot air at 300--350°C on the IC until it lifts. Clean pads with wick + flux. Re-paste with SAC305 syringe, place new part, reflow locally.

\dangerbox{\textbf{Exception: MAX-M10S} — u-blox prohibits hot air. If M10S must be removed: pre-heat board on hot plate to 150°C, then use iron to release each castellated pad individually. Slow and tedious but possible for an LCC-18. Clean, re-paste, reflow locally.}

\subsection*{Dead IC (confirmed bad after electrical test)}

Same removal procedure as misaligned. Replace with spare from your doubles order. Localized rework only.

\dangerbox{There is \textbf{no second full reflow} on this board — bottom-side components (USB-C and others) prevent a clean second hot-plate cycle. All rework is \textbf{localized} (iron or focused hot air on the single failed part), never a whole-board re-reflow. Keep whole-board thermal cycles to the single production pass.}

% ============================================================
% PAGE 8 — COMPLETE COMPONENT REFLOW SPECS
% ============================================================
\newpage
\section*{PAGE 8 — COMPLETE COMPONENT REFLOW SPECIFICATIONS}

\subsection*{Binding Constraints Summary}

\begin{table}[H]
\centering
\begin{tabular}{@{}lll@{}}
\toprule
\textbf{Constraint} & \textbf{Value} & \textbf{Set By} \\
\midrule
Peak temperature & 245°C & MAX-M10S, WS2812B-2020 \\
Time above 217°C & 45--60s & MAX-M10S $\cap$ WS2812B-2020 \\
Time at peak ($\geq$240°C) & 10--20s & FC31M2 crystal \\
Max cooling rate & 4°C/s & MAX-M10S \\
\bottomrule
\end{tabular}
\end{table}

\subsection*{Full Component Table}

{\small
\begin{table}[H]
\centering
\renewcommand{\arraystretch}{1.15}
\begin{tabular}{@{}clllll@{}}
\toprule
\textbf{\#} & \textbf{Part} & \textbf{Package} & \textbf{MSL} & \textbf{Peak} & \textbf{Key Constraints} \\
\midrule
\rowcolor{danger!8}
1 & MAX-M10S-00B & LCC-18 & \textbf{4} & \textbf{245°C} & No hot air. Single reflow. No cleaning. \\
\rowcolor{danger!8}
2 & VEML6030 & — & \textbf{4} & 260°C & 72hr floor life. Bake if exposed. \\
\rowcolor{warning!8}
3 & ESP32-S3-WROOM-1U & Module & \textbf{3} & 235--250°C & Single reflow. Bake if open $>$1wk. \\
\rowcolor{danger!8}
4 & WS2812B-2020 & 2$\times$2mm & — & \textbf{245°C} & J-STD-020C. \\
5 & FC31M2-32.768kHz & SMD3215 & — & 260°C & 10s at peak. Cooling $\leq$6°C/s. \\
6 & Johanson 2450AT18A100E & Chip ant. & — & 260°C & 3 reflow cycles max. \\
7 & LSM6DSV16X & LGA-14 & — & 235--255°C & J-STD-020 (ST TN0018). \\
8 & LIS3MDLTR & LGA-12 & — & J-STD & J-STD-020. \\
9 & PCF85063ATL & DFN-10 & — & 260°C & Standard NXP. \\
10 & BME688 & LGA-8 & \textbf{1} & 260°C & 50$\mu$m min solder standoff. \\
11 & MSM261DGT003 & MEMS & — & 260°C & 5 reflow cycles OK. \\
12 & MAX30101EFD+T & OLGA-14 & — & 260°C & Max temp only stated. \\
13 & BQ25619RTWR & WQFN-24 & — & 260°C* & Assumed, TI QFN. \\
14 & TMP117AIDRVR & WDFN-6-EP & — & 260°C* & Assumed, TI WDFN. \\
15 & DRV2605LDGSR & VSSOP-10 & — & 260°C* & Assumed, TI VSSOP. \\
16 & TPD2E001DRLR & SOT-553 & — & 260°C* & Assumed, TI SOT. \\
17 & BSS138W & SOT-323 & — & 260°C* & Assumed, standard MOSFET. \\
18 & USB-C JS16T & 16-pin & — & 260$\pm$5°C & 60s $>$217°C, 5s $>$250°C. \\
\bottomrule
\end{tabular}
\end{table}
}
{\footnotesize *Not stated in datasheet — standard package assumption.}

\subsection*{MSL Handling Reference}

\begin{table}[H]
\centering
\begin{tabular}{@{}lll@{}}
\toprule
\textbf{MSL} & \textbf{Floor Life} & \textbf{Bake Recovery} \\
\midrule
1 & Unlimited & None needed \\
3 & $\sim$168hr (1 week) at $<$30°C, $<$60\% RH & 125°C / 24hr \\
4 & Per bag label ($\sim$72hr) at $<$30°C, $<$60\% RH & 192hr @ 40°C, RH $<$5\% \\
\bottomrule
\end{tabular}
\end{table}

\vfill

\subsection*{Notes}
\begin{itemize}[nosep]
\item Single reflow pass — bottom-side components (USB-C, etc.) preclude a second whole-board cycle. All parts, including MAX-M10S, go on together.
\item MAX-M10S communicates over \textbf{UART1} (GPIO17 TX / GPIO18 RX), not I2C. DDC/I2C @ 0x42 is available but unused.
\item All 0402 passives assembled and reflowed by JLCPCB at 255$\pm$5°C — their process, no passives at risk.
\item JLCPCB applies SAC305 solder paste to all remaining pads via stencil. Paste baked before shipping.
\item Pre-soldered 0402s re-melt during builder's reflow — board must be level and flat.
\item All solder on this board must be \textbf{lead-free}. Do not use leaded paste or wire.
\item Paste: SAC305 (Sn96.5/Ag3.0/Cu0.5), no-clean. Rework wire: Sn99.3/Cu0.7, 0.8mm. Flux: NC-559-ASM no-clean.
\item Core rail is \textbf{3.2V} via TPS62840 with a 100k VSET resistor (3.3V available with 172k; 3.2V chosen).
\item Boards are \textbf{1.0mm 4-layer}.
\end{itemize}

\vfill
\begin{center}\footnotesize
Kompic Mk1 — Reflow \& Assembly Reference \\
Revision iv7.0 \\
Ivan Porupski, 2026
\end{center}

% ============================================================
% PAGE 9 — STAGED (PROTOTYPE) BUILD
% ============================================================
\newpage
\section*{PAGE 9 — STAGED BUILD (prototype workflow, alternative to single-pass)}

\notebox{The prescribed flow is still \textbf{single reflow pass} (Pages 1--8). This page documents the \emph{prototype} flow used on the very first board, where confidence in each subsystem was built incrementally. If you are reproducing this build from scratch and want to de-risk one ring at a time, follow these stages. Each stage has a matching smoke-test sketch under \texttt{firmware/test/}.}

\subsection*{Stage 1 — Core (hot plate reflow)}

Minimal population required to boot the ESP32 and confirm both I2C buses are healthy.

\textbf{On board this stage:}
\begin{itemize}[nosep]
\item ESP32-S3-WROOM-1U-N16R8
\item BQ25619RTWR charger (bus 2 @ 0x6A)
\item TPS62840 3.2 V buck (100k VSET)
\item XC6206 1.8 V LDO
\item Flashlight LED + FET driver (GPIO41) with external pull-down
\item User button (BQ\_QON $\leftrightarrow$ GPIO16)
\item PCF85063ATL RTC (bus 1 @ 0x51) + FC31M2-32.768 kHz crystal + load caps
\item All JLCPCB-assembled 0402 passives (top and bottom)
\end{itemize}

\textbf{Excluded for this stage:} USB-C connector (bottom side — keep clear so the board can still hot-plate cleanly), all bus-1 sensors, mic, WS2812, daughter PCB, display connector, GPS.

\textbf{Reflow:} Full hot-plate profile per Page 1 (245°C peak, 45--60 s above 217°C). Single pass on the hot plate is uncomplicated here because the bottom side is empty.

\textbf{Power:} No USB-C yet — apply external 5 V to VBUS pad through a current-limited bench supply, or directly to SYS for a bypass test. \dangerbox{Never inject 5 V on a powered USB-C pad after stage 2 — the absent ESD diode on a missing USB-C JS16T is fine here because the connector itself isn't yet present.}

\textbf{Verification sketch:} \texttt{firmware/test/1\_smoke\_test\_mk1\_reflow1/1\_smoke\_test\_mk1\_reflow1.ino}

\textbf{Pass criteria:} ESP32 enumerates as USB CDC over the programming header (or external USB-UART, since USB-C is not yet on the board); BQ25619 ACKs at 0x6A with sane STATUS/PART/FAULT; PCF85063A ACKs at 0x51 with OS bit clear (oscillator running); button toggles the flashlight; flashlight LEDC breathe visible.

\subsection*{Stage 2 — Sensing + USB-C (hot air, no more hot-plate cycles)}

\textbf{Added this stage:}
\begin{itemize}[nosep]
\item USB-C JS16T receptacle (bottom side) + TPD2E001 ESD
\item VEML6030 ambient light sensor (bus 1 @ 0x10)
\item LIS3MDLTR magnetometer (bus 1 @ 0x1C)
\item LSM6DSV16X IMU (bus 1 @ 0x6B)
\item BME688 environmental sensor (bus 1 @ 0x76)
\item MSM261DGT003 PDM microphone (I2S: CLK GPIO47, DATA GPIO48)
\item WS2812B-2020 signal LED (one-wire DIN @ GPIO42)
\end{itemize}

\textbf{Why hot air from here on:} the USB-C JS16T is bottom-side. Once it is placed, the board can no longer be put face-down on the hot plate without melting it; equally, face-up reflow risks reflowing the USB-C joints uncontrolled. \textbf{Stage 2 closes the hot-plate window for this board.} All further additions are localised hot-air or iron rework.

\textbf{Procedure:}
\begin{enumerate}[nosep]
\item Flux all stage-2 pads. For the MEMS mic, flux pads \emph{before} placing and keep flux out of the top port.
\item Place all stage-2 ICs and the USB-C connector. Bottom-side USB-C should be done last with the board flipped on a holder, hot air at 300--350°C, focused nozzle, generous flux. Watch the mic and the QFN/LGA islands on the top side for any heat that telegraphs through.
\item Reflow each top-side IC locally with focused hot air. Don't park hot air on the WS2812 — its 245°C ceiling is a tight box even at the IC scale.
\end{enumerate}

\textbf{Electrical pre-checks (before powering):}
\begin{itemize}[nosep]
\item Multimeter continuity / resistance: VBUS-to-GND, 3V3-to-GND, 1V8-to-GND $\rightarrow$ no shorts.
\item SDA/SCL (both buses) to GND $\rightarrow$ no shorts; bus 1 SDA $\leftrightarrow$ SCL not shorted; bus 2 SDA $\leftrightarrow$ SCL not shorted.
\item Plug into USB-C through an inline current meter (USB-C power meter, USB tester, or bench supply set to 5 V with current limit).
\item Expected steady-state draw: \textbf{$\sim$100--120 mA} with the stage-2 smoke sketch running. Above $\sim$300 mA at idle, or any visible smoke / smell, $\rightarrow$ unplug immediately and inspect.
\end{itemize}

\textbf{Verification sketch:} \texttt{firmware/test/2\_smoke\_test\_mk1\_hotair/2\_smoke\_test\_mk1\_hotair.ino}

\textbf{Pass criteria:} I2C scan returns the full expected stage-2 set --- \mbox{bus 1 = \{0x10, 0x1C, 0x51, 0x6B, 0x76\}} and \mbox{bus 2 = \{0x6A\}}; each chip's WHO\_AM\_I / chip-ID matches; WS2812 colour walk is visible; PDM mic returns non-zero samples; the 1 Hz round-robin loop continues to print live values from every device without dropouts. Missing addresses point at suspect solder joints on that specific chip.

\subsection*{Stage 3 — Daughter PCB + storage (hot air / iron)}

\textbf{Added this stage:}
\begin{itemize}[nosep]
\item Micro-SD card slot + associated routing
\item Daughter PCB (small round board), reflowed \emph{separately} on the hot plate per Page 6: MAX30101 (bus 1 @ 0x57), TMP117 (bus 1 @ 0x48), DRV2605 (bus 2 @ 0x5A)
\item 12 silicone wires hand-soldered between main PCB and daughter PCB
\end{itemize}

\textbf{Procedure:} reflow the daughter PCB on its own (full profile, no constraints from the main board), verify it standalone with a small bench fixture, then connect to the main board via the 12 inter-board wires. Hot-air or iron the SD card slot onto the main board.

\textbf{Pass criteria:} I2C scan now also shows 0x48, 0x57 on bus 1 and 0x5A on bus 2; SD card mounts and writes a test file; DRV2605 buzzes when triggered.

\subsection*{Stage 4 — Display + touch}

\textbf{Added this stage:}
\begin{itemize}[nosep]
\item CO5300 2.06" AMOLED + CST9217 capacitive touch on the 24-pin FPC
\item OK-14F024-04 receptacle (J1) mated to the display ribbon
\end{itemize}

\textbf{Procedure:} the receptacle is hand-soldered or hot-air'd to the main board. Display panel mates to the connector --- no reflow on the panel itself. CST9217 lives on the display assembly (bus 1 @ 0x5A), so it only joins the I2C scan once the panel is plugged in.

\textbf{Pass criteria:} CO5300 driver brings the panel up at COLMOD 0x77 (RGB888) via QSPI on the SPI2/FSPI IOMUX pins; CST9217 ACKs at 0x5A and reports touch events; panel survives a sleep cycle (DISPOFF 0x28 $\rightarrow$ SLPIN 0x10 $\rightarrow$ SLPOUT 0x11 + re-init $\rightarrow$ DISPON 0x29).

\subsection*{Stage 5 — GPS (MAX-M10S, deliberate last)}

\textbf{Added this stage:}
\begin{itemize}[nosep]
\item u-blox MAX-M10S-00B (LCC-18, MSL 4) --- soldered first
\item Johanson 2450AT18A100E (or equivalent) chip antenna --- soldered \emph{after} the M10S is on and verified
\end{itemize}

\textbf{Why last in this prototype flow:} the MAX-M10S has the tightest constraints on the board (245°C peak, no hot air, no cleaning, MSL 4). On the prescribed single-pass workflow it sits in the same reflow as everything else. In this staged workflow, the hot-plate window has been closed by stage 2 --- so the M10S goes on by hand, via the iron-on-castellation procedure from Page 7:

\begin{enumerate}[nosep]
\item Bake the M10S per its floor-life recovery (192 hr @ 40°C, RH $<$ 5\%) if its MSL window has been exceeded since opening the bag.
\item Pre-heat the main board on the hot plate to 150°C (well below all the stage-2 parts' reflow points, USB-C handles this fine).
\item Pre-tin each castellated pad on the M10S footprint with a tiny SAC305 solder bump using the iron + flux.
\item Place the M10S, then reflow each castellation locally with the iron + flux + Sn99.3/Cu0.7 wire. Slow and tedious but well within tolerance for an LCC-18 with exposed castellations.
\item No solvents, no clean --- M10S datasheet forbids cleaning.
\item \textbf{Verify the M10S electrically before placing the antenna:} open UART1 (GPIO17/18) at 9600 baud, confirm NMEA / UBX traffic, and check no shorts on the antenna pad. The antenna goes on \emph{after} the M10S is confirmed alive --- placing it earlier risks reworking the M10S with the chip antenna already in the heat zone (the Johanson chip antenna tolerates standard SMD reflow but should not see repeated rework cycles).
\item \textbf{Hand-solder the antenna last:} iron + flux + Sn99.3/Cu0.7 wire on the two antenna pads. Keep the iron contact $<$ 3 s per pad. After it is on, confirm the GPS still streams NMEA, then observe time-to-first-fix outdoors (cold-start can be several minutes).
\end{enumerate}

\dangerbox{This is the \emph{prototype} accommodation. The intended production workflow is the single-pass reflow on Pages 1--8, where MAX-M10S goes through the controlled hot-plate profile with everything else. Iron-on-castellations is a fallback and adds risk --- expect to use a spare M10S if the first attempt cooks an internal joint.}

\textbf{Pass criteria:} open UART1 (GPIO17 TX / GPIO18 RX) at 9600 baud and confirm NMEA / UBX traffic streaming from the M10S; 1PPS edge visible on GPIO46 once a fix is obtained.

\subsection*{Stage Summary}

{\small
\begin{table}[H]
\centering
\renewcommand{\arraystretch}{1.2}
\begin{tabular}{@{}cp{3.2cm}p{4.0cm}p{3.4cm}p{3.4cm}@{}}
\toprule
\textbf{Stage} & \textbf{Process} & \textbf{Adds} & \textbf{New I2C} & \textbf{Smoke sketch} \\
\midrule
1 & Hot plate (full profile)          & Core + RTC                                 & 0x51 (b1), 0x6A (b2)         & 1\_smoke\_test\_mk1\_reflow1 \\
2 & Hot air (closes hot-plate window) & USB-C + bus-1 sensors + mic + WS2812       & 0x10, 0x1C, 0x6B, 0x76 (b1)  & 2\_smoke\_test\_mk1\_hotair  \\
3 & Hot air / iron + separate reflow  & SD + daughter PCB                          & 0x48, 0x57 (b1), 0x5A (b2)   & --- (per-chip tests) \\
4 & Hand solder + mate                & Display panel + touch                      & 0x5A (b1)                    & --- (display driver) \\
5 & Iron on castellations             & MAX-M10S + antenna                         & --- (UART1, not I2C)         & --- (NMEA dump) \\
\bottomrule
\end{tabular}
\end{table}
}

\notebox{If you are reproducing the prototype flow: keep a written log of what current the board draws at each stage with each smoke sketch running. Drift in that idle figure stage-over-stage is the cheapest early warning of a marginal joint.}

\end{document}

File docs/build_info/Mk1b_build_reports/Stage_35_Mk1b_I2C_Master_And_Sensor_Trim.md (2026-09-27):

# Stage 35 -- Mk1b sensor-surface trim + I2C master API migration

**Date opened:** 2026-09-27
**Date closed:** 2026-09-27
**Board:** Mk1b iv8.0.
**Firmware baseline:** 0.4.88 (post Stage 31 GPS UART TX fix appendum).
**Firmware close:** 0.4.91 (whole binary on `driver/i2c_master.h`).
**Status:** CLOSED. Chronic `bq25619_read_reg -> i2c_hw_fsm_reset ->
IRQ WDT` panic that plagued fw 0.4.68..0.4.89 is gone -- 10 min of
bench nav + sleep/wake stress + CLI hammering with zero crashes.
Stage 32 (tile subject sweep) and Stage 33 (structural finish) are
unblocked.

**Companion refs:**
- `Stage_31_Mk1b_LVGL_Foundations_Rebuild.md` §11 appendum -- GPS UART
  TX fix that landed on the same fw baseline.
- Auto-memory [[project_i2c_hw_fsm_reset_crash]] -- 6+ instances since
  fw 0.4.68; documented root fix is exactly this stage's work.
- ESP-IDF v5.5 `driver/i2c_master.h` API docs.

---

## 1. Why this stage exists

Two problems came due at the same time; solving them in one stage is
cheaper than doing them separately.

**Problem A -- chronic I2C panic.** Since roughly fw 0.4.68 (Stage 29),
the watch has been panicking under any hot-navigation stress with the
same stack trace every time: `bq25619_read_reg -> i2c_hw_fsm_reset ->
IRQ WDT`. The chronic memory has been counting instances until Stage
31 gave up counting past 6. `feedback_flash_per_checkpoint` sessions
keep running into it. `bq25619` sleep-skip prophylactics reduced
exposure but never fixed the root: the legacy `driver/i2c.h`
cmd-link driver's hardware FSM can enter an unrecoverable state when
short bursts contend on a busy bus. The documented fix is migrating
to the ESP-IDF v5.x `driver/i2c_master.h` API, which manages the FSM
internally.

**Problem B -- too many sensors we don't use.** Ivan's day-to-day
needs are: RTC, encoder + button, BQ25619, MAX17048, screen, touch,
haptic, RGB LED, flashlight, BME688 (env), LSM6DSV16X (LSM/IMU), and
MAX-M10S (GPS). The current firmware also boots MAX30101 (PPG),
VEML6030 (light), LIS3MDL (compass), and TMP117 (skin temp). None of
those four are actively used for anything Ivan is currently building,
and each adds init cost, task cost, and I2C bus traffic.

**Why they combine well.** Migrating a sensor to `i2c_master` costs
30-60 minutes per driver. Migrating four drivers we're about to stub
anyway is pure waste. Do the stub pass first; migrate what's left.

---

## 2. Scope

Three batches, dependency-ordered. Each is one flash-checkpoint per
[[feedback_flash_per_checkpoint]].

- **35.1** -- Sensor surface trim (stub the four unused sensors).
- **35.2** -- I2C master migration, Bus 1 (BQ + MAX17048 + DRV2605).
  Crash-fix batch. Success gate is "no more `i2c_hw_fsm_reset`
  panics under nav stress."
- **35.3** -- I2C master migration, Bus 0 (PCF85063 + BME688 +
  LSM6DSV16X + CST9217 touch). Consistency batch; also expected to
  cure occasional touch freezes.

---

## 3. Batch 35.1 -- Sensor surface trim

### What lands

- `boot_logic/boot_hw_init.c`: delete `max30101_init`, `veml6030_init`,
  `lis3mdl_init`, `tmp117_init` calls in `bringup_bus0`. One-line
  comment at each site: `// STUBBED Stage 35 -- see Stage_35 doc`.
- `boot_logic/boot_tasks.c`: delete `task_hr`, `task_light`, `task_mag`,
  `task_mag_cal`, `task_skin` task-creation entries.
- `lvgl_ui/tile_registry.c`: drop `health_tile_desc`, `light_tile_desc`,
  `compass_tile_desc` entries. Registry becomes 6 tiles (system, gps,
  env, haptic, rtc, imu).
- `field_capture/fc_cli.c`: the `HR`, `LIGHT`, `LIS3MDL/COMPASS`, and
  `TEMP_DUMP` verbs stay in the dispatcher but print
  `"<verb>: stubbed at Stage 35 -- sensor not in current build"`
  and return `ESP_OK`. Keeps CLI discoverability.
- `firmware_version.h`: 0.4.88 -> 0.4.89.
- Data-broker fields untouched; consumers already handle
  `hw_alive == false`.

### What is NOT deleted

- Component folders (`max30101/`, `veml6030/`, `lis3mdl/`, `tmp117/`)
  and their CMakeLists.txt. They still build; only boot-time
  activation goes away. Un-stubbing later is a few lines.
- Tile source files (`health_tile.c`, `light_tile.c`, `compass_tile.c`).
  They still compile; they're just no longer registered.
- `broker_hr_*`, `broker_light_*`, `broker_mag_*`, `broker_skin_*`
  functions. Sentinel state is a valid state.

### Success gate

1. Boot log shows 6 tile init lines, not 9. No `HR:`, `LIGHT:`,
   `MAG:`, `SKIN:` `Task started` lines.
2. `STATUS` output covers the 12 kept sensors only.
3. All 6 tiles reachable via tileview navigation; drawer still works.
4. Stubbed CLI verbs print the stub notice.
5. Boot time same or faster than 0.4.88.

### Effort

3-4 files touched, ~150-200 lines net removed. Half a session.
Flash + verify before starting 35.2.

---

## 4. Batch 35.2 -- I2C master migration, Bus 1 (crash fix)

### What lands

- `boot_logic/boot_hw_init.c`:
  - `bringup_bus1()` -> `i2c_new_master_bus` (replaces
    `i2c_param_config` + `i2c_driver_install`). Stores the handle
    in a new module-scope `g_i2c1_bus_handle`.
  - `i2c_probe()` helper rewritten around `i2c_master_probe`.
  - `g_i2c2_mutex` kept -- the mutex solves atomicity for the
    battery task's read burst; the new API solves FSM state.
    Orthogonal concerns.
- `bq25619/bq25619.c`:
  - Add `static i2c_master_dev_handle_t s_bq_dev;`.
  - `bq25619_init` adds itself to the bus via
    `i2c_master_bus_add_device` (100 kHz, 7-bit addr 0x6B).
  - `bq25619_read_reg` -> `i2c_master_transmit_receive(s_bq_dev,
    &reg, 1, val, 1, 20 /*ms*/)`.
  - `bq25619_write_reg` (if present) -> `i2c_master_transmit`.
- `max17048/max17048.c`: same pattern.
- `drv2605/drv2605.c` + `drv2605/haptic.c`: same pattern; auto-cal
  loop becomes a sequence of `_transmit_receive` calls.
- CMakeLists for each affected component: replace `driver` REQUIRES
  entry with `esp_driver_i2c`.
- `firmware_version.h`: 0.4.89 -> 0.4.90.

### Success gate

1. **Primary metric:** run the known-crash reproducer (rapid drawer
   swipe up/down for ~30 s while battery task ticks). Zero panic in
   5 min = pass. Signature `bq25619_read_reg -> i2c_hw_fsm_reset ->
   IRQ WDT` does not appear.
2. Battery % on main screen updates ~1 Hz.
3. Haptic still buzzes on encoder click.
4. `SHIPMODE` from CLI works (BQ write path).
5. Boot log: `BQ25619: hw alive`, `MAX17048: hw alive`,
   `DRV2605: cal OK, boot buzz queued` -- all present.

### Effort

4 files heavily touched, ~300-400 lines. One session. Bench cycle
probably 2 flashes (first pass will miss a CMake REQUIRES or an
unused-driver-symbol residue).

---

## 5. Batch 35.3 -- I2C master migration, Bus 0 (stability)

### What lands

- `boot_logic/boot_hw_init.c` `bringup_bus0()` -> `i2c_new_master_bus`
  for Bus 0. Handle in `g_i2c0_bus_handle`. `g_i2c_mutex` stays.
- `pcf85063/pcf85063.c`: device handle + `_transmit_receive` for the
  7-byte time burst read; `_transmit` for the write path.
- `bme688/bme688_drv.c`: the Bosch BME68X managed component takes
  I2C callback function pointers with a legacy signature. Rewrite the
  callback internals to use the new API; keep the outer signature.
  Fallback: if pointer-arithmetic tangles up, keep BME688 on legacy
  for one more stage and log a Stage 36 follow-up.
- `lsm6dsv16x/lsm6dsv16x.c`: already uses `i2c_master_write_read_device`
  (semi-modern). Straight rename to the new API + device-handle
  bookkeeping.
- `cst9217/cst9217.c` (touch): device handle + `_transmit_receive` for
  the ISR-driven touch-point read.
- CMakeLists REQUIRES: `driver` -> `esp_driver_i2c` for each.
- `firmware_version.h`: 0.4.90 -> 0.4.91.

### Success gate

1. Boot: RTC / BME688 / LSM / touch all `hw alive`.
2. Touch feels the same or better -- no freeze after ~5 min heavy nav.
3. Env values populate on env_tile.
4. Encoder + button still work (encoder is GPIO -- sanity regression).
5. RTC time survives reboot.
6. `grep -rn '#include "driver/i2c.h"' firmware/esp-idf/` returns
   nothing.

### Effort

5 files heavily touched, ~400-500 lines. One session (possibly two
if BME688 callback shape needs work).

---

## 6. Non-goals

- Deleting the stubbed-out component folders. They stay buildable.
- Changing the enable/disable policy for kept sensors.
- Diagnosing "GPS load every ~1 s + signal-strength dip" that Ivan
  mentioned -- separate future work, requires outdoor bench per
  [[project_max_m10s_wiring]].
- Stage 32 tile subject sweep, Stage 33 structural finish, Stage 34
  field_capture rename -- still queued.
- Migrating `mic_pdm` (I2S/PDM, not I2C -- unrelated).

---

## 7. Definition of done

1. Firmware 0.4.91 boots cleanly with 6 tiles + 12 sensors.
2. 30 min bench soak with periodic random taps: zero
   `i2c_hw_fsm_reset` in the log.
3. Auto-memory [[project_i2c_hw_fsm_reset_crash]] updated with
   "resolved at Stage 35, fw 0.4.91."
4. Archive `stage35_close_i2c_master_and_trim` created.

---

## 8. Non-goals for _outside_ Stage 35

_(sensor un-stub schedule, if any)_

- MAX30101: possibly Stage 36 or later once PPG use case surfaces.
- LIS3MDL: only if a heading-holds-north tile ships.
- VEML6030: only if auto-brightness ships.
- TMP117: only if a skin-temp readout matters.

None are firm plans; the point of the stub is that we don't burn
budget on features we're not using.

---

## 9. Bench log

_(populated as each batch lands, per [[feedback_stage_log_workflow]])_

### 9.1 -- Batch 35.1 flash (fw 0.4.89, 2026-09-27)

- Boot log confirms: 7-task Core-0 lineup (ENV / IMU / BAT / RTC /
  HAPTIC / ALARM / GPS), `MAG/HR/SKIN/LIGHT stubbed, see Stage 35`.
- 6 tiles registered + drawer nav works.
- `WHOAMI` still probes all chips via raw I2C -- LIS3MDL / MAX30101 /
  TMP117 read back their IDs, VEML6030 ACKs; `hw_alive=0` on all four.
- Chronic `bq25619_read_reg -> i2c_hw_fsm_reset` STILL FIRES on quick
  swipe (as expected -- 35.1 doesn't touch the crash site, just shrinks
  surface for the 35.2/35.3 migration).

**Batch status:** LANDED + verified. Ready for 35.2.

### 9.2 -- Batch 35.2 flash (fw 0.4.90, 2026-09-27)

- Attempted flash aborted at boot: `check_i2c_driver_conflict` fires
  in a global constructor before `app_main`. ESP-IDF v5.5.2 forbids
  legacy `driver/i2c.h` + new `driver/i2c_master.h` in the same binary.
  Bus-1-only migration is impossible; had to do Bus 0 in the same
  cycle.
- No bench state to log; batch 35.2 stayed on-disk as a stepping stone
  to 35.3.

**Batch status:** LANDED but non-bootable in isolation. Superseded by
35.3 which completes the whole-binary migration.

### 9.3 -- Batch 35.3 flash (fw 0.4.91, 2026-09-27)

- **Boot clean.** No `check_i2c_driver_conflict` abort; both buses
  come up on `i2c_master API, per-device speed` (400 kHz, per-device).
  All 12 kept-alive sensors report `hw_alive: YES`.
- **PM lock inventory** shows the new API is installing per-bus
  `I2C_0` and `I2C_1` NO_LIGHT_SLEEP locks (as expected -- old legacy
  driver installed a single global lock instead).
- **The crash is gone.** ~10 minutes of nav + drawer swipes + sleep/
  wake cycles + `GPS_PING` / `STATUS` / `HELP` verb spam -- zero
  `bq25619_read_reg -> i2c_hw_fsm_reset` panics. Watch stays running.
- **CST9217 mutex timeouts** appear under very rapid GPS sub-tile
  swiping (`W (63477) CST9217: I2C mutex timeout in task path --
  dropping report`, 3-4 in a row). Non-fatal -- touch task just drops
  those reports and self-heals; not a crash, not the old FSM issue.
  Root cause is the GPS sub-tile flooding I2C traffic + the 50 ms
  touch mutex timeout being tight; noted for a follow-up bump-timeout
  or per-tile throttle. Not a Stage 35 blocker.
- **Regressions checked:**
  - Battery % updates on drawer + main screen.
  - Encoder click -> haptic buzz.
  - Touch double-tap wakes from sleep.
  - Env / IMU tiles populate live data.
  - RTC time persists (0x51 alive, `[RTC] 2026-09-27T08:15:06 UTC`).
  - Drawer open / close via swipe.
  - `SHIPMODE` verb path exercised (BQ WRITE via new API).
- **Ripple:** first-boot NVS bumped `last_fw` 0.4.89 -> 0.4.91.

**Batch status:** LANDED + fully verified. **Stage 35 = DONE.**

### 9.4 -- Notes for Stage 36+

- CST9217 mutex timeout under GPS-sub-tile swipe stress: consider
  bumping the 50 ms budget or de-noising the sub-tile refresh cadence.
- GPS chip is talking two-way (`ack_ack=1`, `mon_rf=611`) but
  `GPS_PING` never sees a MON-VER response (`mon_ver=0`). SNR is
  low (17-21 dBHz, bursty on/off). Separate GPS debug stage --
  the fresh-session prompt is filed as
  `docs/build_info/Mk1b_build_reports/Stage_36_Mk1b_GPS_Signal_Debug_PROMPT.md`.

---

## 10. References

- `Stage_31_Mk1b_LVGL_Foundations_Rebuild.md` §11 appendum.
- ESP-IDF v5.5 `driver/i2c_master.h` header and its docstring examples.
- ESP-IDF v5.5 migration guide: legacy `driver/i2c.h` -> `driver/i2c_master.h`.
- Auto-memory:
  [[project_i2c_hw_fsm_reset_crash]],
  [[project_kompic_mk1]],
  [[project_mk1b_arrived]],
  [[feedback_flash_per_checkpoint]],
  [[feedback_group_work_by_venue]],
  [[feedback_stage_log_workflow]],
  [[feedback_mk1b_stage_naming]],
  [[feedback_commits]],
  [[feedback_md_frontmatter_convention]].

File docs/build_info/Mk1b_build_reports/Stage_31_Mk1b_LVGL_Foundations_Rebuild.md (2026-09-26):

# Stage 31 -- Mk1b LVGL foundations rebuild (batch 1)

**Date opened:** 2026-09-14
**Date closed:** 2026-09-18
**Board:** Mk1b iv8.0.
**Firmware baseline:** 0.4.75 (Stage 30 close).
**Firmware close:**   0.4.87 (Stage 31.4b + MODE cycle button).
**Status:** CLOSED. All four batches landed + bench-verified:
- 31.1 shared pane style flyweight
- 31.2 subject scaffold + env_tile pilot (+ 31.2b corner-safe redo)
- 31.3 settings drawer as sibling pane (+ 31.3b/c iterations)
- 31.4a GPS tile subject conversion + robust status-first layout
- 31.4b UBX-CFG-VALSET + MON-RF diagnostic + GPS_DYNMODEL CLI
       + on-tile MODE cycle button (PED->WRIST->AUTO->AIR1G).
GPS chip firmware side complete; further GPS work waits on Ivan's
bench hardware fix (VIO_SEL float + SAFEBOOT_N float) then real
antenna. Stage 32 (bulk tile subject sweep) picks up in a fresh
session -- see `Stage_32_Mk1b_Tile_Subject_Sweep.md`.

**Companion refs:**
`docs/build_info/reference_files/lvgl_9/LVGL9_Kompic_Architecture.md`
(architecture spec derived from the LVGL 9 PDF + smartwatch demo +
current-code map). `docs/build_info/reference_files/lvgl_9/
LVGL9_Reference.md` (API cheat-sheet). Every batch below points into
the architecture spec by §.

---

## 1. Why this stage exists

Stage 30 fixes the plumbing (Espressif's port, DMA overlap, sane
partial-refresh again). That unlocks the *shape* work: our current
UI is a mixed-model patchwork -- three top-level screens with
`lv_scr_load_anim`, per-widget style calls, per-tile `apply_theme`
fan-out, a 200 ms polled `update()` per tile that reads a custom
broker. The LVGL 9 smartwatch demo shows a materially cleaner shape,
and LVGL 9 gives us first-class `lv_subject_t` widget bindings that
delete the poll loop entirely.

Analysis and target shape live in `LVGL9_Kompic_Architecture.md`.
That doc identifies **10 migration batches** spanning three stages:

| Stage | Batches | Theme |
|---|---|---|
| **31 (this)** | 31.1 -- 31.4 | Foundations trio + first pilot tile |
| **32** | 32.1 -- 32.4 | Bulk tile -> subject conversion (7 tiles) |
| **33** | 33.1 -- 33.3 | Alarm drawer + overlay polish + apply_theme sweep + `ui_navigation.c` delete |

Each batch is Opus-sized (~one session's worth of code + one bench
flash cycle). Full rebuild wall-clock ~2-4 weeks.

**Nothing here changes hardware behavior.** All changes are UI-side.
Sensor drivers, CLI, boot, sleep -- untouched.

---

## 2. Stage 31 scope

Four batches, dependency-ordered. Each locks in one foundational
piece so later stages can lean on it.

- **31.1** -- shared pane style scaffold (theme lives in ONE place)
- **31.2** -- `ui_subjects.c` scaffold + Env tile as pilot
- **31.3** -- `ui_animations.c` + settings drawer as a sibling pane
- **31.4** -- GPS tile subject conversion (largest, worst-case proof)

31.1 and 31.2 are independent -- can flash in either order. 31.3
depends on 31.1 (drawer pane needs a shared style). 31.4 depends on
31.2 (subject infra must exist before we convert tiles).

Rationale + close-second alternatives per batch below.

---

## 3. Batch 31.1 -- Shared pane style + theme swap

**Goal:** replace per-widget theme-tracked style calls with one
`static lv_style_t` per pane; theme swap mutates the style once,
LVGL invalidates automatically. Architecture spec §2.2, §5.3.

### What lands

- New file: `firmware/esp-idf/components/lvgl_ui/ui_pane_styles.c/h`
  - Exposes `style_pane_root`, `style_pane_drawer`, `style_row`,
    `style_card` as `lv_style_t` module-scope objects.
  - `kw_ui_pane_styles_init()` -- idempotent one-shot init from
    `theme_bg()`, `theme_text()`, etc. (adds flex layout, radius,
    padding).
  - `kw_ui_pane_styles_reapply_theme()` -- mutates each style's
    theme-tracked props with the current `g_ui_theme` and calls
    `lv_obj_invalidate(lv_screen_active())`.
- Modified: `ui_main_screen.c` -- swap outer container to use
  `style_pane_root`; drop per-widget bg/text-color calls that duplicate
  what the style now carries.
- Modified: `lvgl_ui.c` `apply_ui_theme()` -- call
  `kw_ui_pane_styles_reapply_theme()` instead of per-tile fan-out.
- **Kept as-is:** per-tile `apply_theme()` callbacks. They still fire
  and set the same colors (no-op after the style change lands). Deletion
  happens in Stage 33.3 after every tile is migrated.

### Why this is the right choice

The demo pattern (§2.2) is unambiguous: every satellite pane holds a
`static lv_style_t main_style` that carries theme colors + layout +
radius. Any object added to the pane inherits without a single
per-widget style call. Adopting this pattern:

- **Deletes theme fan-out entirely** once every tile is migrated
  (Stage 33 finish line).
- **Cuts per-tile boilerplate** -- typical tile has 3-8 widgets each
  with an `lv_obj_set_style_text_color` + `_bg_color` in
  `apply_theme()`. Shared style: zero.
- **Fixes theme-switch races** -- current fan-out iterates tiles in
  registry order; if a tile is mid-update on Core 1 the writes may
  land out-of-order. Shared style + `lv_obj_invalidate` is one
  atomic op from the LVGL task.

**Close-second: skip and go straight to subjects (31.2 first).**
Rejected because the pilot in 31.2 will create new widgets that
should use the shared style from day one. Doing 31.1 first means
env_tile's rewrite in 31.2 lands in the correct final form.

**Close-second: adopt LVGL's default theme instead of a custom
palette.** Rejected because our palette (Space Grotesk + our dark/
light with named accents) is already good and matches Stage 29's
crispness work. LVGL's default theme is generic material and we'd
lose brand.

**Close-second: use `lv_theme_t` (a first-class theme object) instead
of shared styles.** Rejected because `lv_theme_t` is applied to a
whole display and re-applied on every widget creation -- deep, opaque,
harder to reason about mid-render. Shared styles are 20 lines and
transparent.

### Success gate

1. `apply_ui_theme(DARK)` and `apply_ui_theme(LIGHT)` both cause the
   main screen bg + text color to switch within one refresh.
2. Tile bodies still theme-track (via their surviving `apply_theme`
   cbs -- transitional).
3. No LVGL warnings or asserts about invalidated regions overlapping.
4. `STATUS` still readable; CLI theme verb still works.

### Effort

New file + 2 modified files. ~300-400 lines touched. One session.

---

## 4. Batch 31.2 -- Subject scaffold + Env tile pilot

**Goal:** stand up `lv_subject_t` infra + convert one tile to the
new pattern. Prove that widget bindings work under our threading
model. Architecture spec §1.6, §5.4, §6.

### What lands

- New file: `firmware/esp-idf/components/lvgl_ui/ui_subjects.c/h`
  - Subject singletons: initially `subj_temp_c` (int),
    `subj_rh_pct` (int), `subj_pressure_hpa` (int),
    `subj_iaq` (int), `subj_env_status` (int).
  - Publish queues (mirrors of what env producer already emits or
    creates them): `g_env_q` if not already present in bme688.
  - `kw_ui_subjects_init(void)` -- initialises every subject with
    a sentinel value ("--").
  - `kw_ui_subjects_start_drain(void)` -- `lv_timer_create(cb,
    200, NULL)` on the LVGL task; cb drains all queues under lock
    and calls `lv_subject_set_*`.
- Modified: `env_tile.c` -- `env_tile_init()` uses
  `lv_label_bind_text(lbl, &subj_temp_c, "%d °C")` etc.
  `env_tile_update()` **becomes no-op** (kept for registry
  compatibility until Stage 33 registry cleanup).
- Modified: `bme688` producer task (or wherever env samples are
  currently pushed to the broker) -- `xQueueOverwrite(g_env_q, &sample)`
  instead of / in addition to the old broker path.
- Modified: `lvgl_ui_display.c` `boot_screens()` -- calls
  `kw_ui_subjects_init()` + `kw_ui_subjects_start_drain()` after
  `ui_broker_init()`.

### Why this is the right choice

Two structural wins:

1. **Deletes `update()` on env_tile.** Widget stays live-updating
   without any per-tile polling code. Extended across all 11 tiles
   this deletes ~4.5k LOC of `update()` + `broker_*_read()` scaffolding.
2. **Formalises the threading contract.** Producers (any core, any
   task) push to a queue; the drain timer runs on the LVGL task and
   is the ONLY caller of `lv_subject_set_*`. Removes an entire class
   of thread-safety mistakes.

**Env is the correct pilot** because:

- Smallest sensor tile (367 LOC).
- Stable sensor (BME688 owned + working for months, no bring-up debt).
- All-numeric outputs (temp/RH/pressure/IAQ) -- exercises the
  `lv_label_bind_text(int_fmt)` binding fully.
- No user input, no toggles, no gestures -- pure display. Isolates
  the subject pattern from confounders.

**Close-second: battery_tile (176 LOC) as pilot.** Smallest of all
tiles. Rejected because battery pulls from MAX17048 which has some
Stage 30 flux (bq/mpf division per [[project_bq_no_vbat_adc]]);
touching it while the fuel-gauge story is still settling is asking
for a false-positive regression.

**Close-second: gps_tile as pilot (proves worst case first).**
Rejected because gps_tile is 680 LOC with toggles, gestures, sub-
tile, and photo-view. It IS the worst case, but that's the wrong
call for the pilot -- pilot's job is to isolate the pattern change
so any regression is unambiguously about subjects. GPS is Batch
31.4 (foundations-proof-under-load), which is the right slot for it.

**Close-second: replace the old broker in one shot.** Rejected.
The broker also handles settings save (async NVS queue) which is
orthogonal to sensor data flow. Keeping the broker while migrating
sensor flow means we can retire the sensor-broker functions
opportunistically per venue [[feedback_group_work_by_venue]] without
a stop-the-world rewrite.

**Close-second: publish direct-from-producer with `lvgl_port_lock`.**
Rejected. Producer tasks would spend most of their time waiting for
the LVGL mutex (LVGL flush can hold it for a full frame). The
queue + drain-timer pattern decouples the producer's rate from LVGL's
frame rate.

### Success gate

1. Env tile temp/RH/pressure/IAQ labels update every 200 ms with
   real sensor data.
2. No LVGL asserts about mutex ownership or invalidated observers.
3. Theme swap still recolors env_tile text (via style_pane_root
   inheritance from 31.1 + surviving `env_tile_apply_theme` no-op).
4. `STATUS TEMP` (or equivalent CLI verb) reads
   `lv_subject_get_int(&subj_temp_c)` and matches the on-screen value.
5. Sensor producer task doesn't block or slow down (bench: watch
   `TOP` CLI for cpu-per-task, compare pre/post).

### Effort

New file + 2-3 modified files. ~400-600 lines touched. One session.
The trickiest part is auditing the current env producer path so the
queue doesn't get double-pushed.

---

## 5. Batch 31.3 -- Animation module + settings sibling drawer

**Goal:** replace `lv_scr_load_anim(settings)` with a slide-down
sibling-pane drawer. Introduce the reusable animation module.
Architecture spec §5.2, §5.5, §6.5.

### What lands

- New file: `firmware/esp-idf/components/lvgl_ui/ui_animations.c/h`
  - `kw_ui_animate_slide_in(obj, lv_dir_t from, dur_ms, delay_ms)`
  - `kw_ui_animate_slide_out(obj, lv_dir_t to, dur_ms, delay_ms)`
  - `kw_ui_animate_opa(obj, target_opa, dur_ms, delay_ms)`
  - Path defaults to `lv_anim_path_ease_out` for in / `_ease_in`
    for out.
- Modified: `ui_settings_screen.c` -- pane is created ONCE at boot
  as a child of `lv_screen_active()`, positioned via
  `style_pane_drawer`'s `translate_y = -LCD_V_RES`. Its tileview is
  built as before; only the parent changes.
- Modified: `ui_navigation.c` -- the settings branch of the state
  machine deletes; replaced by:
  - `main_screen` gesture cb: on swipe-up, call
    `kw_ui_animate_slide_in(settings_pane, LV_DIR_BOTTOM, 400, 0)`.
  - `settings_pane` gesture cb: on swipe-down from the top-most
    tile, `kw_ui_animate_slide_out(settings_pane, LV_DIR_TOP, 400, 0)`.
- Modified: `ui_main_screen.c` + `ui_settings_screen.c` gesture cbs
  wired directly on the panes (not centrally in ui_navigation).
- **NOT DONE this stage:** the alarm branch of `lv_scr_load_anim`
  stays. Alarm becomes a sibling pane in Stage 33.1. `ui_navigation.c`
  survives (shrunk) until then.

### Why this is the right choice

**The demo's sibling-pane pattern is objectively better for drawers**
(§2.1, §2.3):

- **Overlap during transition** -- home stays visible while settings
  slides down over it. `lv_scr_load_anim` swaps the entire active
  screen; you can't see the source and destination simultaneously.
  For a "drawer opens" affordance that's exactly wrong.
- **No screen reload cost** -- the tileview + all tile children stay
  built. Reopening the drawer is instant; today it's a full-screen
  reload every time.
- **Simpler cancellation** -- swipe-down mid-open just reverses the
  animation; screen-load doesn't cancel.

**Settings goes first (not alarm) even though alarm is smaller**
because settings exercises `LV_OBJ_FLAG_GESTURE_BUBBLE` interaction
with the tileview -- vertical swipes must escape the tileview to
reach the pane's cb for drawer-close. This is the tricky bit; getting
it right on settings makes alarm trivial. Alarm has no tileview so
it's a strictly-easier case; deferring it to Stage 33.1 loses nothing.

**Close-second: keep `lv_scr_load_anim` and just polish the
transition timing.** Rejected -- see "overlap during transition"
above. The affordance mismatch isn't a polish issue, it's structural.

**Close-second: use `lv_tileview` at the root with home / settings /
alarm as tiles.** Rejected. Settings is *itself* a tileview; nested
tileviews confuse gesture routing. Also alarm isn't gesture-reachable
in the target design (it comes from an event, not a swipe).

**Close-second: build the pane on-demand instead of at boot.**
Rejected -- reopen latency goes back up. RAM cost of always-resident
tileview + 9 tiles is ~100 KB, well within budget on PSRAM.

**Close-second: land ui_animations.c in a separate batch first.**
Considered. The reason to bundle: 31.3 is the first venue that
needs the module. Landing an unused module is dead weight until it
has a consumer.

### Success gate

1. Swipe-up on main -> settings drawer slides down; both visible
   mid-animation.
2. Swipe-down at settings root (top tile, y=0) -> drawer slides
   back up; home visible underneath as it moves.
3. Tileview horizontal swipes still navigate between tiles
   (bubble flag correct).
4. Vertical swipes on non-top tiles do NOT close the drawer (tileview
   consumes them for tile-nav, which is correct).
5. Alarm swipe-right path (unchanged this stage) still works via
   surviving `ui_navigation.c` code.

### Effort

1 new file + 3 modified. ~500-800 lines touched. One session. Bubble-
flag debug may add a bench cycle if we get the flag wrong first try.

---

## 6. Batch 31.4 -- GPS tile subject conversion (worst-case)

**Goal:** prove the subject pattern under the hardest tile. If GPS
converts cleanly, every other tile is easier. Architecture spec §5.7.

### What lands

- Extend `ui_subjects.c/h` -- add:
  - `subj_gps_sats` (int), `subj_gps_hdop_10x` (int),
    `subj_gps_utc_str` (string), `subj_gps_date_str` (string),
    `subj_gps_lat_str` (string), `subj_gps_lon_str` (string),
    `subj_gps_alt_m` (int), `subj_gps_speed_kmh_10x` (int),
    `subj_gps_status` (int), `subj_gps_power` (int, two-way toggle).
  - Drain timer already exists from 31.2; add a GPS branch to its cb.
- Modified: `gps_tile.c` -- `gps_tile_init()` binds labels + LED +
  power switch via `lv_label_bind_text` + `lv_obj_bind_flag_if_eq` +
  `lv_obj_bind_checked`. `gps_tile_update()` becomes no-op.
  Sub-tile (raw NMEA) similarly bound.
  Photo-view: `gps_tile_cmd_view_set()` stays as CLI/button surface;
  internal impl uses `lv_obj_bind_flag_if_eq` on
  `LV_OBJ_FLAG_HIDDEN` against a new `subj_gps_photo_view` int
  subject.
- Modified: `max_m10s` producer -- push `gps_sample_t` to `g_gps_q`;
  drain cb formats the strings.
- **Kept:** the `g_gps_sync_requested` flag pattern for the ATOMIC
  SYNC button -- that's a fire-and-forget command to Core 0, not
  observable state. Button `LV_EVENT_CLICKED` cb writes the flag.

### Why this is the right choice

GPS tile is the biggest (680 LOC) and hits every subject-binding
edge case:

- **9 read-only value labels** -- exercises int, string, and formatted-
  int label bindings.
- **1 LED bound to a multi-state status** -- exercises
  `lv_obj_bind_flag_if_eq` with reference values.
- **1 two-way toggle switch** -- exercises `lv_obj_bind_checked`
  with a subject that both the UI (user tap) and a producer
  (driver state confirmation) can publish. This is where the
  re-entrancy guard `s_syncing` in gps_tile.c today lives; the
  bind_checked pattern replaces it structurally.
- **1 conditional-visibility container** (photo view) -- exercises
  `lv_obj_bind_flag_if_eq` on `LV_OBJ_FLAG_HIDDEN`.
- **1 fire-and-forget command button** -- shows the correct pattern
  for "not an observable, a command": stay with event cb + flag.

If GPS converts cleanly under these five patterns, IMU / compass /
health / haptic / light / battery / system / RTC / alarm are all
subsets or trivial variants. The mesh-of-patterns audit here is
what makes Stage 32 low-risk.

**Close-second: convert IMU next (369 LOC, similar sensor shape).**
Rejected. IMU tile is similar to env -- lots of labels, no toggles,
no photo-view. Converting IMU proves nothing env didn't. GPS
stress-tests toggle re-entrancy which is the class of subtle bug
worth catching before doing it 7 more times.

**Close-second: convert compass_tile (387 LOC).** Rejected for the
same reason. Compass has one clever bit (bearing arc) but no
toggles.

**Close-second: convert system_tile (290 LOC).** Rejected because
system_tile pulls from NVS and uptime -- neither is producer-task-
driven so the drain pattern isn't exercised the same way. Not a
representative test.

### Success gate

1. GPS tile: all 9 value labels track live NMEA (visible with sky-
   view; static "--" indoors).
2. Power toggle: tap on-screen -> driver enable succeeds -> switch
   stays checked (no re-entrancy oscillation). CLI `GPS_POWER OFF`
   -> subject flips to 0 -> switch un-checks on next drain.
3. Status LED color tracks acquiring / online / offline correctly.
4. Photo view toggle via both the on-tile button and
   `GPS_VIEW photo` CLI verb -- both flip `subj_gps_photo_view` and
   the container's HIDDEN flag follows.
5. ATOMIC SYNC button still triggers Core 0 NTP sync (flag path
   unchanged).

### Effort

1 modified subjects file + 1 modified 680-line tile + 1 modified
producer. ~700-900 lines touched. One session -- possibly two if
the `lv_obj_bind_checked` two-way path has a subtle bug we don't
catch on bench first try.

---

## 7. Non-goals for Stage 31

- Converting IMU / compass / health / haptic / light / battery / system /
  RTC to subjects -- Stage 32 territory.
- Alarm as sibling pane / deleting `ui_navigation.c` -- Stage 33.1.
- Deleting per-tile `apply_theme()` cbs -- Stage 33.3 (once all
  tiles migrated).
- Replacing shutdown overlay with `lv_msgbox` -- Stage 33.2.
- Encoder tile redesign per [[project_encoder_tile_redesign]] -- still
  its own future stage.
- CLI submenu restructure per [[project_cli_submenus]] -- unrelated
  surface.
- Recording writer datetime migration per
  [[feedback_recording_datetime_opportunistic]] -- unrelated surface.

---

## 8. Definition of done for Stage 31

1. `ui_pane_styles.c` in place; `apply_ui_theme()` mutates ONE style
   set and calls `lv_obj_invalidate`; main-screen theme swap works
   without per-tile fan-out.
2. `ui_subjects.c` in place; drain timer running on LVGL task;
   env_tile fully subject-bound with `env_tile_update()` a no-op.
3. `ui_animations.c` in place; settings drawer is a root-sibling
   pane; swipe-up opens it with over-home animation; swipe-down
   closes it.
4. gps_tile fully subject-bound (labels + LED + power toggle +
   photo view); `gps_tile_update()` is a no-op.
5. No regression in: boot, sensor sampling, sleep, charging, CLI,
   theme swap, alarm ring, notification popup, tile navigation.

---

## 9. Bench log (fill in as each batch lands)

*(populated as we go, per [[feedback_stage_log_workflow]])*

### 9.1 -- Batch 31.1 flash (fw 0.4.76)

**What landed:**
- `ui_pane_styles.{c,h}` -- 5 shared LVGL styles
  (pane_root / pane_drawer / row / card / subtext). Init once at boot,
  reapply mutates theme-tracked props and invalidates active screen.
- `lvgl_ui.c` -- `kw_ui_pane_styles_init()` at top of `lvgl_ui_init()`;
  `kw_ui_pane_styles_reapply_theme()` at top of `apply_ui_theme()`
  (before the surviving per-tile fan-out).
- `ui_main_screen.c` -- `s_screen` uses `style_pane_root`; time +
  battery labels inherit text colour; date label wears `style_subtext`.
  Docstring updated (main is no longer "always DARK").
- `ui_settings_screen.c` -- `s_screen` + `s_tileview` use
  `style_pane_root`. Per-tile bg writes retained (Stage 33.3 sweep).
- ESP_LOG tiers seeded per new practice:
  `PANE_STYLE` LOGI on init + on each reapply,
  LOGD per property block, LOGV per screen-invalidate.

**What to watch on flash:**
1. Boot completes -- `PANE_STYLE: init: 5 pane styles created` line
   appears once before the tile boot loop.
2. Main screen renders identically to fw 0.4.75 on DARK theme
   (anthracite bg, off-white time, dim date, off-white battery).
3. Swipe up -> settings tile view. Pick System tile, toggle theme.
   Expected: LIGHT bg = warm ivory; DARK bg = anthracite; on LIGHT
   theme labels on main-screen are DARK ink (not invisible off-white).
   Log line `PANE_STYLE: reapply_theme: theme=LIGHT -- 5 styles
   updated, screen invalidated` per swap.
4. No LVGL warnings about invalidated regions, no assert about
   style not initialised, no CST9217 touch-freeze.
5. `STATUS` verb still works.

**If something's off, useful escalation:**
- Flip PANE_STYLE to DEBUG at boot -- add
  `esp_log_level_set("PANE_STYLE", ESP_LOG_DEBUG)` in
  `app_main` (main.c) or from `LOGLVL` CLI once wired -- to see the
  colour hex values written on each reapply.
- Flip to VERBOSE if the invalidate itself is suspect.

**Bench verdict (2026-09-18, fw 0.4.76):**
- Plumbing PASS: both `PANE_STYLE` log lines fire as designed
  (init once at boot; reapply once at UI init frame). No LVGL
  asserts, no un-initialised-style warnings.
- Visual PASS on DARK theme: main + settings identical to fw 0.4.75.
  Bonus: tile titles crisper than before (side-effect of centralising
  pad/radius on `style_pane_root`).
- Swipe responsiveness: good, possibly slightly better than 0.4.75.
- DARK<->LIGHT visual swap NOT yet verified -- Core 0 IRQ-WDT panic
  in `bq25619_read_reg` (i2c_hw_fsm_reset) killed the bench before
  Ivan could reach the theme toggle. Same signature as
  [[project_i2c_hw_fsm_reset_crash]], third recurrence
  (fw 0.4.68 / 0.4.73 / 0.4.76). PRE-EXISTING, not caused by 31.1.
- Deferred: theme-toggle visual check to a fast-path bench (swipe
  straight to System tile, toggle, watch for `theme=LIGHT` reapply
  log) or push once i2c_master API migration lands.

**Bench verdict (2026-09-18 pass 2, fw 0.4.76):**
- Visual DARK<->LIGHT toggle PASS on second bench: four clean reapply
  lines captured (LIGHT / DARK / LIGHT / DARK), no visual glitches,
  swap latency imperceptible.
- No I2C crash this run (crash appears non-deterministic across
  sleep/wake cycle counts).

**Batch status:** LANDED + fully verified (plumbing + visual).

---

### 9.1a -- BQ25619 prophylactic (fw 0.4.77)

Small preventive patch riding this stage's flash cycle -- see
[[project_i2c_hw_fsm_reset_crash]]. Not a fix (real fix = i2c_master
API migration), just reduces exposure:

- `bq25619.c` `task_battery_fn`: skip poll when `g_display_sleep`
  is true. Cached broker value stays visible on wake.
- `bq25619` CMakeLists: adds `boot_logic` to REQUIRES so the flag
  extern resolves.

**Watch on flash of fw 0.4.77:**
1. `BQ25619` still logs "Task started" at boot.
2. After 30 s idle-timeout sleep: no crash, no BQ log noise. At
   DEBUG level the `poll skipped: display asleep` line ticks 1 Hz.
3. On double-tap wake: poll resumes; battery % on main screen
   updates within ~1-2 s (fresh read).
4. Repeat sleep/wake stress; crashes should be less frequent
   (probabilistic, not eliminated).

**Bench verdict (2026-09-18, fw 0.4.77):**
- Sleep-skip landed cleanly, no build regression.
- I2C crash STILL fires under mid-navigation stress (not
  sleep/wake related as originally hypothesised) -- sleep-skip
  helps only for the "sleeping bus" case, not "hot navigation".
  Kept landed (harmless prophylactic), root fix remains
  i2c_master API migration. Log lines see 2026-09-18 LOG.md.
- ENC verb registered rotation mid-fiddle -- confirms firmware
  path is alive when signals arrive; encoder hw is intermittent-
  contact not fully dead. Memory + LOG updated.

---
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

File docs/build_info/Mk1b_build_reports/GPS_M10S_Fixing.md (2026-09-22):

---
Date opened: 2026-09-18
Date closed: 2026-09-20
Status: RESOLVED — 18b/c sketch defaults had RX/TX inverted relative to the master pinout; wiring GPS TX→GPIO18 and GPS RX→GPIO17 (per master pinout IOMUX: U1RXD on 18, U1TXD on 17) produces a clean ~289-370 B/s NMEA stream on the Mk1b. No bodge required.
---

# MAX-M10S GPS UART Silence — Debug Findings & Next Steps
Kompic Mk1 / Mk1b, ESP32-S3-WROOM-1U-N16R8
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

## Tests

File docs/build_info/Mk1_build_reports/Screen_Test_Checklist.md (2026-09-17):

# Screen Test Checklist — visual verification blocked until Mk1b PCB lands

**Purpose.** Every LVGL / display / touch item that could not be
verified headless during Stages 21-2X. Working blind against the CST9217
probe NAK on iv7.1, so anything past "the LVGL state moves" waits for
Mk1b to actually see pixels.

**How to use.** When Mk1b lands and boots, walk this file top-to-bottom.
Tick each row. Any surprise gets logged into the "Findings" column with
a Stage-XX pointer for the follow-up fix.

**Living doc.** New items land at the top of each subsection as later
stages (23 + 24 + ...) introduce more UI surface. Do not rearrange —
Ivan should recognise the row order from stage to stage.

---

## 0. Sanity — boot + no-regression pass

- [ ] Default boot: `LVGL_FORCE OFF`, no panel forced, sensors + CLI + shutdown all behave exactly as iv7.1 headless. STATUS shows `display = PRESENT (CO5300 up)  touch = CST9217 up`.
- [ ] Boot log includes `BOOT_DISP: CST9217 detected (0xAB @ 0xD000) -- display module present` and `CO5300 ready` and `CST9217 touch ready`.
- [ ] `LVGL_DISP` log line reports `panel=CO5300 touch=CST9217 buf=55920 B (40 rows × 466 px × 3B)`.
- [ ] `task_ui` appears in FreeRTOS task list; no watchdog trips in the first hour.

---

## 1. Display path (Stage 22 §4.1b)

- [ ] First frame ever renders. Boot animation / main screen visible.
- [ ] **RGB byte order** — draw a pure-red rectangle (via `TILE 4` after a photo-view swap, or a bench-only `SCREEN_FILL R G B` if we ever add one). Verify red = red, not blue. If swapped, add a byte-swap loop in `lvgl_flush_cb` before `co5300_write_pixels`.
- [ ] **Window addressing** — partial-refresh strips land in the correct panel region (top-left of a drawn area matches expected coords). If off, verify `co5300_set_window` handles column offset correctly.
- [ ] **Column offset** (`CO5300_COL_OFFSET = 22`) — left edge of every widget starts at logical x=0, not x=22. If widgets appear cut off on the right, offset is being applied twice.
- [ ] **Full-frame refresh** works when a tile switch invalidates the whole screen.
- [ ] **Backlight fade** — `backlight_set_brightness(0)` produces visible dark, `100` visible bright, linear in between.
- [ ] No tearing during 200 ms refresh cycle at normal panel activity.

## 2. Font legibility (all tiles)

- [ ] Every widget label readable at wrist-viewing distance.
- [ ] Data-row alignment consistent (Sats/HDOP/Time/Date/LAT/LON/ALT all left-aligned to the same x).
- [ ] Photo view (§4.6) — Montserrat_30 at wrist distance for lat/lon. If unreadable, upgrade to `LV_FONT_MONTSERRAT_48` (+50 KB) or JetBrainsMono (+40 KB, true monospace). Track in Stage 25 candidates.

## 3. Touch (Stage 22 §4.2)

- [ ] Single tap on empty tile area registers (`TOUCH` CLI verb shows event count increment).
- [ ] Coordinates in expected range: 0..410 X, 0..502 Y. If out of range, CST9217 report parsing in `cst9217.c` needs the actual datasheet vs the assumed CST816S layout (see `cst9217.h` layout comment).
- [ ] Tap on the ATOMIC SYNC button in the GPS tile fires the sync request (`g_gps_sync_requested = true`, log line "Atomic sync requested").
- [ ] Tap on the PHOTO button in the GPS tile swaps to photo view. Tap anywhere on photo returns to normal. Verify tap-to-exit doesn't require a specific spot.
- [ ] Tap on the power-toggle switch flips broker enable state.
- [ ] Long-press vs single-tap discrimination (if we ever wire long-press for encoder-less nav). CST9217 gesture bits are unverified — don't act on them yet.

## 4. Per-tile visual check (walk through all 10)

For each tile: swipe/encoder to it, verify layout, verify widget values match `STATUS` / broker snapshot.

- [ ] `system` (default) — clock + date + battery status strip.
- [ ] `gps` — telemetry view + PHOTO button; sub-tile swipe-up shows NMEA.
- [ ] `rtc` — UTC + local + date + uptime + GPS sync timestamp.
- [ ] `env` — temp / humidity / pressure / altitude / delta height. ZERO HEIGHT button.
- [ ] `compass` — needle rotation matches heading; CALIBRATE button.
- [ ] `imu` — accel XYZ + gyro XYZ + roll/pitch + temp columns.
- [ ] `light` — lux + auto-brightness + brightness slider + blue-light filter toggle.
- [ ] `haptic` — LED + effect roller + IMU CAL + SET FREQ buttons.
- [ ] `health` — LED + BPM + signal bar + SpO2 + finger-detect. **PPG only — no ECG on Kompic** (`feedback_no_ecg_on_kompic.md`).
- [ ] ~~`ecg`~~ — **stub tile, delete during Stage 23/24 cleanup** (NO ECG on Kompic).
- [ ] `alarm` (standalone, not in tileview) — swipe-right from main.

## 5. Photo view (Stage 22 §4.6)

- [ ] Enter photo via PHOTO button OR `GPS_VIEW PHOTO` OR `TILE gps` + button.
- [ ] Black background actually black (LV_OPA_COVER holds).
- [ ] Lat/lon rows large + centred; decimal points visually aligned (or acceptable given proportional font).
- [ ] Time+date row above readable at Montserrat_16.
- [ ] Sat count + ALT row at bottom.
- [ ] "tap to exit" hint visible but subdued.
- [ ] Tap anywhere on photo returns to normal. Verify normal view rebuilds cleanly (no orphan widgets, no bg colour bleed).

## 6. Navigation (Stage 22 gestures + Stage 23 encoder)

- [ ] Swipe up from main → settings tileview.
- [ ] Swipe down from settings → main.
- [ ] Swipe right from main → alarm screen.
- [ ] Swipe left from alarm → main.
- [ ] Tileview horizontal swipe navigates through 10 tiles.
- [ ] Encoder rotate → tileview column changes (**Stage 23 §2**).
- [ ] Encoder click → per-tile action (**Stage 23 §2**). First user: GPS tile click = `gps_tile_cmd_view_toggle()`.

## 7. LVGL_SCREENSHOT (Stage 23 §3)

- [ ] `LVGL_SCREENSHOT` verb dumps to `/sd/lvgl_fb/s<seq>.png` (or `.rgb`).
- [ ] PNG opens on laptop, matches what's on the panel.
- [ ] Consecutive screenshots go into rotating session files, not overwriting.

## 8. Long-running / stress

- [ ] Overnight: LVGL side up + tile refresh at 200 ms + touch idle. No memory leak (heap free doesn't drift down).
- [ ] Battery drain with LVGL on vs LVGL off (compare against the Stage 23 batt_test baseline).
- [ ] Sleep behaviour — does the panel dim / go to sleep after idle? (Depends on `ui_lock_screen.c` state machine + `backlight_set_brightness`.)

## 9. Regression checks (must still work post-Mk1b)

- [ ] All CLI verbs unchanged.
- [ ] `LVGL_FORCE ON` on Mk1b (redundant but shouldn't break anything — should just override the probe).
- [ ] `SHIPMODE` still drops BATFET.
- [ ] Double-click power button still triggers ship mode.
- [ ] SD write path unaffected (recording still lands rows).

---

## Findings log (fill during Mk1b bring-up)

| Date | Row | Finding | Fix / Stage |
|:-----|:----|:---|:---|
| | | | |

---

## References

- `docs/build_info/Mk1_build_reports/Stage_22_LVGL_Binding.md` — where each item was landed blind.
- `docs/build_info/Module_Blueprint.md` — the two-outlet contract these visual checks validate.
- `docs/build_info/reference_files/IV71_TO_MK1B_FIRMWARE_DELTA.md` — Mk1b delta plan.

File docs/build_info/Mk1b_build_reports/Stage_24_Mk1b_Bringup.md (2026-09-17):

# Stage 24 -- Mk1b iv8.0 bring-up

**Date opened:** 2026-09-10
**Date closed:** 2026-09-10 (same day)
**Board:** Mk1b PCB (iv8.0) -- first physical board on Ivan's bench; iv7.1 retired.
**Firmware baseline:** `iv7.1.f0.4.31` (Stage 23 close) -> shipped at `0.4.32`.
**Status:** CLOSED. Bring-up complete through Milestone C step 10
(display dark -- panel + touch alive but ESP-IDF integration still
skewed). Landscape / MAX17048 / GPS follow-through carries to Stage 25.

---

## 0. Scope

Bring Mk1b iv8.0 up from bare PCB to fully-functional wearable, in the
assembly order Ivan will physically follow. Every fw feature Stage 23
left pending queues in behind the bring-up milestones so we're not
blocked on iv7.1 side quests when hardware verification demands
attention.

**Rules of engagement (Mk1b-specific):**
  - **Topside first, USB-wired, no case.** Verify every topside
    component works before flipping to the bottom side. iv7.1 taught us:
    soldering both sides then debugging is a nightmare.
  - **GPS reflow deferred within topside.** GPS is the single-chip
    hardest reflow (BGA-adjacent, big thermal mass). Do it LAST on
    topside so failures elsewhere don't waste the GPS chip.
  - **USB pigtail for early boots.** Use the four test pads (VBUS/GND/
    D+/D-) near the receptacle, per `pre_fab_checklist.md §4`. Solder
    wires from a sacrificial USB-C cable straight to the pads. Only
    populate the actual USB-C receptacle after everything else on top
    is verified.
  - **Battery stays disconnected during bring-up.** No permanent
    battery pack until the BQ + BATFET path is verified. Ship-mode
    false-trips would be a real headache mid-bring-up.
  - **`feedback_flash_per_checkpoint.md` still applies.** Each hardware
    milestone gets a firmware verification pass before moving on.

---

## 1. Assembly plan (Ivan's physical order)

### 1.1 Phase A -- Topside (excluding GPS)

Solder + verify in this order:

1. **Power path first.** BQ25619 charger, TPS62840 buck, XC6206 LDO
   (with the F-LDO-1 swap fix applied), decoupling caps, TS thermistor
   divider.
   - Bench check: apply 5 V to VBUS pigtail, verify 3V3 and 1V8 rails
     come up. Verify SYS = ~3.6-4.2 V (BQ SYS regulation) when no
     battery.
   - **Do NOT populate MAX30101 or LIS3MDL until this step passes.**
     F-VIO-1 / F-LDO-1 both killed sensors last time.

2. **ESP32-S3 + PSRAM + flash.** Populate the SoC, PSRAM, external QSPI
   flash. Solder USB-C pigtail wires to the four test pads.
   - Bench check: `esptool.py chip_id` succeeds over USB-CDC-JTAG.
     Flash the current fw (`iv7.1.f0.4.31`) as a first pass to get a
     live boot log even without sensors.

3. **I2C bus 0 sensors (topside batch).** BME688, LSM6DSV16X, LIS3MDL,
   VEML6030, MAX30101, TMP117, PCF85063A, CST9217 (touch).
   - Bench check: `WHOAMI` prints each chip ACK + WHO_AM_I match. Any
     NAK = a soldering issue on THAT sensor's pin group; no need to
     disturb others.

4. **I2C bus 1 sensors.** DRV2605L (haptic), BQ25619 (already up from
   step 1 but confirm addressable on I2C), MAX17048 fuel gauge.
   - Bench check: `HAPTIC PLAY 14` fires the LRA. `BQ` prints register
     dump. MAX17048 shows up in `WHOAMI` at 0x36.

5. **SD card slot + SDMMC.** Solder the µSD receptacle. Insert card.
   - Bench check: `FS_LS` lists card contents.

6. **WS2812 LED + haptic motor + flashlight LED.** Small stuff.
   - Bench check: `RGB 255 0 0` red, `RGB 0 255 0` green,
     `RGB 0 0 255` blue.

7. **Encoder.** Wheel + click switch.
   - Bench check: `TILE list` output plus rotate encoder and verify
     rotation events land in the log.

**Milestone A gate:** every topside component listed above passes its
bench check. `STATUS` shows all sensor_status = OK. Flash log has zero
WARN except the known deprecation notice.

### 1.2 Phase B -- GPS reflow (last on topside)

8. **MAX-M10S GPS module.** Reflow it on top with hot air. Big thermal
   mass, LGA-adjacent -- last so failures don't waste the chip.
   - Bench check: on next boot, `GPS_VIEW normal` shows fix data
     populating within ~30-60 s under open sky.

**Milestone B gate:** GPS reports valid fix (fix quality ≥ 2, sat count
> 4). RTC gets synced via `pcf85063_cmd_sync_utc()` when GPS fix is
valid.

### 1.3 Phase C -- Bottom side

9. **Bottom-side ICs.** Any additional bottom-side passives (MAX17048
   already on top with BQ per pinout).

10. **Display (CO5300 AMOLED) + FPC connector.** The F-DISP-1 mirror
    fix should have landed in Mk1b -- verify FPC pin 1 lands where it
    should physically (per `pre_fab_checklist.md §1`) BEFORE inserting
    the panel.
    - Bench check: `LVGL_FORCE` OFF (default) + reboot. `STATUS` shows
      `display = PRESENT (CO5300 up) touch = CST9217 up`. All 10 tiles
      render on the panel.

**Milestone C gate:** panel lights up, touch works, all tiles render.
`Screen_Test_Checklist.md` walked top-to-bottom.

### 1.4 Phase D -- Enclosure + battery

11. Battery pack connected via BAT+ / BAT- pads.
12. Encoder click gesture routing (double-click ship-mode).
13. Enclosure assembly.

**Milestone D gate:** unplug USB. Watch runs on battery for at least
one full charge cycle without incident.

---

## 2. Firmware companion work (interleaved with assembly)

Batches queue behind milestones so Ivan's not blocked waiting on code
between soldering sessions. Each batch is
`feedback_flash_per_checkpoint.md`-sized.

### 2.1 During Phase A -- immediately useful for bench diagnosis

- **§2.1a HELP sorted alphabetically.** Auto-sort the CLI verb list at
  print time. Small change in `rtc_cli_print_help()` -- collect lines
  into a static array, sort, print.
- **§2.1b `SCREEN [main|settings|ROTATE]` verb.** Programmatic screen
  switch for bench screenshot flow. Adds a rotate hook that
  reconfigures the CO5300 MADCTL register + LVGL orientation. Panel is
  landscape 410x502 -- iv7.1 was hardcoded 466x466 portrait, Mk1b
  should default to the true orientation.

### 2.2 During Phase B -- unblocked by GPS being present

- **§2.2 Dual-time display + timezone LUT.** Feature request from Ivan
  2026-09-10.
  - Default reference zone: **Central European Time (UTC+1, HR/SLO)**.
  - GPS provides UTC + lat/lon.
  - Small country/timezone LUT keyed on lat/lon boundaries returns an
    offset. If not in LUT, use UTC (or last known).
  - Watch face shows local time in large font, CET in small below (or
    vice versa), toggleable via `TIME_MODE [single|dual]` verb
    (NVS-persisted, default = dual).
  - If no GPS ever, show CET only.
  - `SET_TIME` continues to write UTC to the RTC. Display layer
    applies the offset. `RTC` verb still shows UTC + `valid=1`.

### 2.3 During Phase C -- after display is up

- **§2.3a ECG cleanup.** Delete `qvar_ecg`, `ecg_tile`, `tile_registry`
  ECG entry. NO ECG per [[feedback_no_ecg_on_kompic]].
- **§2.3b Font upgrade for GPS photo view.** Montserrat_48 or
  JetBrainsMono for the big time+coord display on the GPS tile.
- **§2.3c PNG compression for LVGL_SCREENSHOT.** miniz deflate; file
  drops ~640 KB → ~150 KB.

### 2.4 During Phase D -- final polish

- **§2.4a `ws2812_cmd.{c,h}` cmd surface + rgb_policy audit.**
- **§2.4b Encoder tile + cmd surface** per
  [[project_encoder_tile_redesign]]. Test-ground layout: rotation
  speed, click count, button response.
- **§2.4c I2C_NUM_0/1 migration to `driver/i2c_master.h`** across all
  10 drivers. Kills the boot deprecation warning.
- **§2.4d SDMMC PM lock chase** (Stage 23 §5.8): 79% APB_FREQ_MAX hold
  in normal operation. First real battery-life move since Stage 17.

---

## 3. Snags encountered during bring-up (and how they were fixed)

### §3.1 USB serial not appearing (`/dev/ttyACM*` absent)

**Symptom:** `idf.py monitor` scanned all `/dev/ttyS*`, found nothing.
No USB device visible in `lsusb` either.

**Root cause:** D+ and D- traces on the Mk1b PCB were shorted together.
With both differential lines shorted, the USB PHY can never drive valid
J/K states; host sees nothing.

**Fix:** Traced and separated the short on the bench. USB enumerated
immediately as `303a:1001 USB JTAG/serial debug unit`.

### §3.2 Board crashing every ~29 seconds after USB fixed

**Symptom:** dmesg showed the board enumerating, then disconnecting,
then re-enumerating, on a ~29 s cycle. Arduino serial monitor caught
only the single line `I (679) esp_psram: SPI SRAM memory test OK`
before losing the port.

**Root cause:** DRV2605 haptic driver was not installed on the Mk1b
board at this point. The firmware drives GPIO0 (DRV_EN) HIGH at boot
and then tries to I2C-init the DRV2605. Without the chip, the I2C
transaction hangs until the task watchdog fires (~30 s default). The
watchdog reset causes the USB re-enumeration cycle.

**Secondary observation:** Without DRV2605, the board drew only 18 mA
with the RGB LED running, because DRV_EN HIGH was floating into
something that enabled the LED path unexpectedly. After DRV2605 was
installed, quiescent draw settled at 60 mA (no SD card, no daughter
board, no battery -- expected).

**Fix:** Installed DRV2605. Board booted to completion.

### §3.3 idf.py monitor dropping connection after boot

**Symptom:** After the watchdog issue was resolved, the board booted
fully but `idf_monitor` disconnected ~2 s after the last boot log line.
PM stats showed `SLEEP 40MHz: 92%` -- the board was spending almost all
time in light sleep.

**Root cause:** `CONFIG_USJ_NO_AUTO_LS_ON_CONNECTION` was not set. The
USB-JTAG/Serial peripheral has no power-management lock on the
connection by default, so the board enters light sleep and powers down
the USB PHY, dropping the monitor connection.

**Fix:** Added `CONFIG_USJ_NO_AUTO_LS_ON_CONNECTION=y` to both
`sdkconfig` and `sdkconfig.defaults`. The next boot's PM inventory
confirmed: `usb_serial_jtag NO_LIGHT_SLEEP: Active 100%` and
`light_sleep_counts: 0`.

### §3.4 esptool RTS/DTR error blocking idf.py flash

**Symptom:** After editing `sdkconfig`, `idf.py flash` failed with
`OSError: [Errno 71] Protocol error` at
`fcntl.ioctl(TIOCMBIC, TIOCM_RTS_str)`. The Linux `cdc_acm` driver
rejects modem-control ioctls on this CDC-ACM device.

**Root cause:** esptool's `default_reset` strategy opens the serial
port and immediately tries to clear RTS to set up the reset pulse. The
kernel returns `EPROTO` because the ESP32-S3 USB-JTAG CDC-ACM interface
doesn't support modem-control signals. This happened before even
`--before=no_reset` could take effect, because pyserial sets RTS state
inside `Serial.open()`.

**Fix:** Used OpenOCD (already present in the IDF toolchain at
`~/.espressif/tools/openocd-esp32/`) for the flash that carried the
`USJ_NO_AUTO_LS_ON_CONNECTION` change:

```
openocd -f board/esp32s3-builtin.cfg \
  -c "program_esp build/smartwatch.bin 0x10000 verify reset exit"
```

After that firmware landed, `idf.py flash` works normally (esptool can
now do the USB reset handshake without timing out on a sleeping board).

**Note:** `Warn: [esp32s3.cpu1] Unexpected OCD_ID = 00000000` appeared
during the OpenOCD session. This is expected behaviour when CPU1 is in
sleep or not yet examined; OpenOCD correctly proceeds on CPU0.

### §3.5 LSM6DSV16X and BQ25619 not responding on first WHOAMI

**Symptom:** First full boot showed `I2C_ERR` for both LSM6DSV16X
(0x6B, I2C0) and BQ25619 (0x6A, I2C1). All other sensors ACKed.

**Root cause:** Cold joints from initial reflow. Both chips physically
present but not making reliable I2C contact.

**Fix:** Reseated both chips. Both ACKed on the next boot. During the
reseating attempt, a solder bridge briefly caused a 500 mA draw with
the ESP32 heating up -- power was disconnected immediately, the bridge
was found and removed, and the board recovered without damage.

### §3.6 BQ25619 TS NTC junction correction

The TS NTC thermistor junction feeding BQ25619's temperature sense
input had a PCB-level wiring error that caused incorrect readings. Ivan
corrected the junction on the bench. With no battery attached the TS
pin now reads 0 V, which is correct (NTC divider collapses to 0 when
the battery connector is open).

### §3.7 CST9217 probe returning 0xFF -- display not initialised

**Symptom:** `boot_display.c` probe logged
`CST9217 signature mismatch: 0xFF (want 0xAB)`, causing
`no CO5300 module -- skipping display bring-up`. Display remained dark
and firmware ran headless even with the display FPC connected.

**Root cause:** `touch_module_present()` called `cst9217_probe_ack()`
directly without issuing the GPIO44 hardware reset pulse first. The
CST9217 powers up in an undefined state and only returns `0xAB` at
register `0xD000` after receiving a reset pulse (GPIO44 LOW ≥5 ms, then
HIGH, 50 ms settle). Without the reset it ACKs on I2C but returns
`0xFF` from all registers. The `cst9217_init()` full init path does
the reset correctly; the lightweight presence-probe path did not.

**Code fix:**
  - `cst9217_hw_reset()` in `cst9217.c` renamed from `static` to public
    `cst9217_reset()` and declared in `cst9217.h`.
  - `touch_module_present()` in `boot_display.c` now calls
    `cst9217_reset()` before `cst9217_probe_ack()`.

**Status at stage close:** Fix is in tree but not yet flashed/verified
-- this is the first item for Stage 25 §1.

---

## 4. End-of-stage hardware status

| Chip | Bus | Address | Status |
|---|-----|---|---|
| BME688 | I2C0 | 0x76 | OK |
| LSM6DSV16X | I2C0 | 0x6B | OK (after reseat) |
| LIS3MDL | I2C0 | 0x1C | OK |
| VEML6030 | I2C0 | 0x10 | OK |
| PCF85063A | I2C0 | 0x51 | OK (OSC stop flag cleared on first boot) |
| CST9217 | I2C0 | 0x5A | ACKs but returns 0xFF -- probe fix in tree, not flashed |
| MAX17048 (fuel gauge) | I2C1 | 0x36 | Not yet in firmware -- Stage 25 |
| DRV2605 | I2C1 | 0x5A | OK (auto-cal FAIL STATUS=0xEC -- deferred) |
| BQ25619 | I2C1 | 0x6A | OK (after reseat; TS NTC junction corrected) |
| CO5300 display | QSPI | -- | Not initialised (blocked by CST9217 probe) |
| MAX30101 | I2C0 | 0x57 | Not present (daughter board not assembled) |
| TMP117 | I2C0 | 0x48 | Not present (daughter board not assembled) |
| SD card | SDMMC | -- | Not inserted |
| GPS (MAX-M10S) | -- | -- | Soldered; not yet exercised |

**Quiescent draw:** ~60 mA at 5 V USB, no battery, no daughter board,
no SD. (Mk1/iv7.1 at comparable configuration was ~100 mA; difference
accounts for missing DRV2605 standby + missing SD + missing
encoder/button hardware.)

**DRV2605 auto-cal:** Consistently fails with `STATUS=0xEC` (OVER_TEMP
flag set, which is a known false flag during cold LRA auto-cal without
motor or with wrong coil parameters). The driver init completes and
haptic is functional; cal parameters should be tuned once the motor is
connected and the LRA profile confirmed.

---

## 5. Firmware side quests landed during bring-up

### 5.0 Side-quests landed while Ivan was assembling (fw 0.4.32)

Batch executed 2026-09-10 while Mk1b topside soldering was in progress.
All firmware-only; no hardware needed. Ivan flashed 0.4.32 to Mk1b once
topside step 2 (ESP32-S3 + PSRAM + flash + USB pigtail) was complete.

**Landed:**

- **§2.1a HELP alphabetical sort** -- verbs live in a static array in
  fc_cli.c and `qsort()` runs at print time, so new verbs can be added
  anywhere and always print in order.
- **§2.4a WS2812 cmd surface + rgb_policy fix.** New
  `components/ws2812/ws2812_cmd.{c,h}`: `set_rgb`, `auto`, `dump`,
  `status_summary`. RGB CLI verb refolded through the surface. **The
  real bug that made iv7.1's LED dark:** `rgb_policy_init()` was
  defined but never called at boot -- no animation timer ever started,
  so `rgb_policy_preview_start()` was a no-op forever. Fix in
  `boot_hw_init.c` (called right after `ws2812_init`).
- **§2.3a ECG cleanup.** Deleted `components/qvar_ecg/` (dead stub
  component -- no callers), `ecg_tile.{c,h}`, tile_registry ECG entry,
  and dead `#include "qvar_ecg.h"` in fc_modes.c. FCM_ECG mode + inline
  QVAR electrostatic sensing in fc_modes.c untouched (that's Ivan's
  non-medical use of the QVAR channel, per
  [[feedback_no_ecg_on_kompic]]).
- **Encoder cmd surface (Stage 24 §2.4b partial).** New
  `components/encoder/encoder_cmd.{c,h}` with `reset`, `dump`,
  `status_summary`. Wired via a `encoder_note_detent()` hook in
  encoder.c that the polled state machine in fc_common.c calls on every
  emitted detent -- so the ENC CLI verb sees live CW/CCW counts +
  rotation speed (dps EMA) even though the PCNT driver path is
  dormant. New `ENC [RESET]` CLI verb. **Encoder TILE deferred** until
  Mk1b display is up (needs LVGL tile registration).

---

## 6. Testing strategy notes

- **Every milestone A/B/C/D has a CLI-verifiable gate** so the headless
  workflow Stage 23 built keeps paying off through bring-up.
- `Screen_Test_Checklist.md` becomes the authoritative panel-side
  verification list once Phase C starts -- populate it as tiles come up.
- **Compare Mk1b behaviour to iv7.1 baseline** at every step. Any new
  regression = something Mk1b-specific (BOM difference, layout change,
  ...); any behaviour that matches iv7.1 = fw carry-over, potentially
  fixable in fw alone.

---

## 7. Next steps → Stage 25 scope

Stage 25 goal: **display alive, GPS tile on screen** (Mk1b Day-1
deliverable per project milestone).

### §25.1 CST9217 reset-before-probe (already coded, needs flash + verify)

Flash the `cst9217_reset()` change and confirm the boot log shows:
`CST9217 detected (0xAB @ 0xD000) -- display module present` then
CO5300 init completing.

If CST9217 probe still fails after the reset fix, investigate:
  - FPC connector seating (pin 1 orientation)
  - GPIO44 pull state during boot (any other driver claiming GPIO44?)
  - Whether Mk1b RST line in the FPC is actually wired to GPIO44

### §25.2 CO5300 display bring-up verification

Once CST9217 probes OK, CO5300 QSPI init should run. Verify:
  - Display lights up (white flash or LVGL splash during init)
  - `boot_display_is_present()` returns true
  - LVGL stack starts on Core 1
  - At least one tile renders on the panel

### §25.3 MAX17048 fuel gauge driver integration

MAX17048 is fitted on I2C1 alongside BQ25619 (fixed address 0x36).
Stage 25 work:
  - Write driver (component `max17048/`)
  - Add to `boot_hw_init` I2C scan
  - Add `WHOAMI` row and CLI verb
  - Wire SOC% reading into the battery tile and `STATUS` dump

### §25.4 GPS tile on screen (Day-1 milestone)

With display alive, wire the GPS task back in (`task_gps_fn` is
currently commented out in `boot_tasks.c`) and verify the GPS
coordinate tile renders and updates on the panel. This is the
trip-readiness gate.

### §25.5 DRV2605 auto-cal (opportunistic)

Once the motor is properly connected on Mk1b, re-run `HAPTIC CAL` via
CLI and confirm STATUS clears. If it persists, adjust the LRA profile
parameters in `haptic_tile.c` to match the actual motor (resonant
frequency, rated voltage, drive time).

---

## References

  - `Stage_23_Cmd_Surface_Encoder_Screenshot.md` -- previous stage,
    closed 2026-09-10.
  - `Stage_25_Mk1b_Display_GPS_Fuel.md` -- follow-on stage, tracks the
    Stage 24 §7 items above.
  - `Module_Blueprint.md` -- module command-surface contract.
  - `Screen_Test_Checklist.md` -- visual verification list.
  - `Mk1b_build_reports/pre_fab_checklist.md` -- physical verification
    before Gerber (already applied to iv8.0).
  - `Mk1b_build_reports/Mk1b_fix_list.md` -- every iv7.1 fix folded
    into iv8.0. Cross-reference during bring-up when a fault mode looks
    familiar.
  - `Mk1b_build_reports/Mk1b_schematic_audit_iv8.0.md` -- current
    schematic sign-off.
  - Auto-memory `MEMORY.md` -- especially [[project_mk1b_arrived]],
    [[project_mk1b_assembly]], [[project_mk1_shelved]],
    [[project_iv71_display_dead]], and
    [[feedback_mk1b_stage_naming]].

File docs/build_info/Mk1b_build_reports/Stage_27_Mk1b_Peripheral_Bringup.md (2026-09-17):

# Stage 27 -- Mk1b peripheral bring-up (antenna, encoder, button, motor, SD)

**Date opened:** 2026-09-11
**Board:** Mk1b iv8.0 (physical unit on Ivan's bench).
**Firmware baseline:** `0.4.44` (Stage 26 close, BQ25619 replaced,
charging + battery-run verified).
**Status:** OPEN.

---

## 1. Why this stage exists

Stage 26 closed with the charge path healthy (fresh BQ25619 + working
MAX17048 fuel gauge) and the on-board sensor set stable. The remaining
gap between "bench board" and "wearable" is a set of five physical
peripherals that either aren't installed yet or aren't proven alive:

  1. **GPS antenna** -- module was reflowed in Stage 24 Phase B but
     never produced a byte on UART1 (`18_max_m10s_gps_test_mk1b`
     printed `[STAT] 5000 ms: 0 B` across multiple cycles + zero
     UBX-MON-VER replies). Silent chip needs a rework / continuity /
     power investigation regardless of whether the antenna is
     attached.
  2. **Encoder** (ALPS EC05E) -- not yet installed. Bring-up gate is
     the polled detent state machine in `fc_common.c`, exposed via
     the `ENC` CLI verb.
  3. **Button** -- dual-wired to BQ25619 `/QON` (GPIO16). Missing on
     the current unit; without it, ship-mode entry has to come from
     the `SHIPMODE` CLI verb.
  4. **Haptic motor** (ELV1411A LRA) -- not yet installed. DRV2605
     boots with `auto-cal FAIL STATUS=0xEC` every session because
     there's no motor to calibrate against. Motor install unblocks
     auto-cal.
  5. **SD card slot** -- physical slot is on the board; no card
     inserted yet. `FS_LS /sd` should list files once a card is in.

None of these need new firmware. Each has a driver already; Stage 27
is a hardware + verification stage under
[[feedback_cli_first_testability]] and
[[feedback_flash_per_checkpoint]] -- one peripheral per bench session,
CLI-verify each before moving on.

Once all five are alive and CLI-verifiable, Mk1b hardware bring-up is
functionally done. Firmware work continues from the desk (no bench
required) except for cases where a firmware change specifically needs
observation.

---

## 2. Plan (bench sessions, strictly one peripheral per session)

Each session ends with a `WHOAMI` / peripheral-specific CLI dump that
confirms the peripheral is alive, and a note added to §4 (below) with
what worked / what didn't.

### 2.1 GPS -- MAX-M10S alive-check (before antenna)

**Pre-antenna investigation first** because the chip was silent in
Stage 26 §4.0. The antenna install is downstream of "does the module
respond to UART commands at all".

Bench steps:

  1. Continuity + power check on the M10S module:
     - VCC pin -> should be 3V2 (TPS62840 output).
     - GND -> continuity to GND.
     - UART TX (module pin) -> ESP GPIO18 (RX).
     - UART RX (module pin) -> ESP GPIO17 (TX).
     - 1PPS -> ESP GPIO46.
     - BACKUP pin -> should have a small cap / RTC-backup source per
       schematic; verify it's not floating.
  2. Reflow the module with hot air if any pin looks marginal
     (Stage 24 Phase B was "single reflow, saved for last"; a second
     pass with fresh flux is cheap).
  3. Flash `18_max_m10s_gps_test_mk1b` again post-rework. Success =
     any NMEA line at all in the log, or a UBX-MON-VER reply
     (SW/HW version strings printed by the sketch's frame decoder).
  4. Antenna install (mechanical) once the chip is confirmed alive.
  5. Outdoor test: valid fix in 30-60 s. RTC auto-sync via
     `pcf85063_cmd_sync_utc()` on first fix.

Success gate: `GPS_VIEW normal` CLI verb shows fix data populating;
boot-time `MAX-M10S UART1 OK` line already reads correctly.

### 2.2 Encoder -- ALPS EC05E install + polled state machine

Bench steps:

  1. Solder encoder onto the encoder footprint.
  2. Wire check: encoder A, B, and click pins land on the ESP GPIOs
     per master pinout v20.
  3. Reboot. `ENC` CLI verb should now:
     - Print current CW/CCW counts (starts at 0).
     - Update as Ivan rotates the wheel.
     - Rotation-speed EMA (`dps`) should track physical speed.
  4. `ENC RESET` zeros counters (already implemented at Stage 23 §2.4b).

Reminder: encoder is polled per [[feedback_encoder_polling]] -- ISR-
based path oscillates +1/-1 because settle bounce lands >15 ms after
the leading edge. The state machine in `fc_common.c` is authoritative.

Success gate: rotate the wheel five detents clockwise; `ENC` verb
shows `cw=5 ccw=0`. Reset. Rotate five counter-clockwise; `cw=0 ccw=5`.

### 2.3 Button -- GPIO16 dual-wired to BQ25619 /QON

Bench steps:

  1. Solder the tactile switch onto the button footprint.
  2. Verify: GPIO16 pulls low on press, releases high (ESP internal
     pullup provides ~45 kΩ up; verify with DMM).
  3. Reboot with USB attached. Boot log confirms shutdown watcher
     armed (already prints today).
  4. Single-press -> log line `BTN single (ignored in test sketch)`
     equivalent in firmware -- the fc_shutdown.c poller distinguishes
     click / long-hold; verify a short press does NOT enter ship
     mode.
  5. Double-click -> ship mode entry (per
     [[feedback_sketches_need_shipmode]] and Stage 20 timing).
  6. 4-second hold -> ship mode entry via long-hold ladder (Stage 17
     timing).

Success gate: single press produces a haptic-style click without
firing ship mode; a proper long-hold or double-click drops BATFET
after the buzz warning at 2 s.

### 2.4 Haptic -- ELV1411A LRA install + DRV2605 auto-cal

Bench steps:

  1. Solder the LRA to the motor pads.
  2. Reboot. Auto-cal should transition from
     `STATUS=0xEC` (fail without motor) to a cleaner result -- exact
     STATUS bits depend on how well the ELV1411A matches the current
     LRA profile in `haptic_tile.c`.
  3. If auto-cal still fails: tune the LRA profile parameters
     (resonant freq, rated voltage, drive time) per the ELV1411A
     datasheet.
  4. `HAPTIC PLAY 14` (or another ROM effect) should produce a felt
     click.

Success gate: `HAPTIC PLAY 14` fires a visible / audible / felt
buzz; boot log shows `DRV2605 auto-cal OK` (or a documented
persistent-fail with the motor still playing effects cleanly).

### 2.5 SD card -- insert + FS_LS

Bench steps:

  1. Insert a formatted µSD card (FAT32, ≤ 32 GB) per
     [[feedback_suspect_cheap_sd_cards]].
  2. Reboot. Boot log should now show `SDCARD: sdcard_init OK` +
     `Mounting SDMMC` succeeding, not the current
     `sdmmc_init_ocr ... 0x107` timeout.
  3. `FS_LS /sd` lists whatever is on the card (may be empty on a
     freshly-formatted card).
  4. `BLACKBOX ON`, reboot, verify blackbox CSV rows land on the SD
     with per-row `fsync` per [[feedback_sd_write_durable]].

Success gate: `WHOAMI` shows `SD card mounted=1 cap=NNN MiB
free=NNN MiB`.

---

## 3. Non-goals for Stage 27

  - Display / touch / LVGL polish (blocked on display mating, which
    itself waits on completing the topside populated first).
  - Broker channel for MAX17048 SOC + battery tile update (needs the
    cell to soak for a discharge curve before the tile refresh
    contract is stable).
  - Landscape + font-sharpness + blue-light filter (all deferred from
    Stage 26 §5).
  - MLC training / recording durability audit / audio annotation
    tuning (all firmware polish, land after Stage 27 closes).

---

## 4. Bench log (fill in as each peripheral is installed)

### §4.1 Full topside populated + daughterboard transplant (fw 0.4.44)

Bench session 2026-09-11: Ivan installed the GPS antenna, RTC backup
cell, GPS supercap, tactile button, encoder wheel, and haptic motor,
then transplanted the daughterboard from the retired Mk1 unit
(MAX30101 + TMP117). All done headless per
[[feedback_cli_first_testability]] with the panel deferred until the
enclosure is ready.

**All 10 I2C chips ACK on `WHOAMI`:**

| Bus | Addr | Chip | Status |
|-----|---|---|---|
| I2C0 | 0x51 | PCF85063A | OK |
| I2C0 | 0x76 | BME688 | OK |
| I2C0 | 0x6B | LSM6DSV16X | OK |
| I2C0 | 0x1C | LIS3MDL | OK |
| I2C0 | 0x57 | MAX30101 | OK (daughterboard) |
| I2C0 | 0x48 | TMP117 | OK (daughterboard) |
| I2C0 | 0x10 | VEML6030 | OK |
| I2C1 | 0x6A | BQ25619 | OK |
| I2C1 | 0x5A | DRV2605 | OK |
| I2C1 | 0x36 | MAX17048 | OK (VERSION=0x0012, prod_rev=0x2) |

**Peripherals verified end-to-end:**
  - **Encoder**: wired, `ENC` verb counts CW/CCW cleanly.
  - **Motor**: LRA installed; `DRV2605 auto-cal PASS in 1050 ms` (was
    persistent FAIL STATUS=0xEC without the motor).
  - **Charging**: 300 mA into cell with USB, board holds on battery on
    USB unplug (verified Stage 26 §4.4 after BQ swap).
  - **Fuel gauge**: `FUEL` returns VCELL + SOC without crashing.
  - **RGB**: fades per policy, bright on encoder detent.

**Headless quiescent draw: 35 mA** with all sensors present + fuel
gauge + GPS + haptic + RGB (idle, no charging, USB power). Battery-
life estimate: 24-48 h on a ~350 mAh cell.

**Deferred still (§2.5 SD card):** slot present, no card inserted --
`sdcard_init` still shows the expected `sdmmc_init_ocr ... 0x107`
timeout with an empty slot.

### §4.2 GPS silence -- MAX-M10S UART chip-side investigation needed

Sketch `18_max_m10s_gps_test_mk1b` flashed to the fully-populated Mk1b.
Result across multiple 5-second poll cycles:

```
[STAT] 5000 ms: 0 B  (0 NMEA, 0 UBX)   PPS edges=0
[POLL] -> UBX-MON-VER (class=0x0A id=0x04)
[STAT] 5000 ms: 0 B  (0 NMEA, 0 UBX)   PPS edges=0
```

**Being indoors doesn't cause this.** MAX-M10S emits NMEA sentences at
1 Hz on power-up regardless of antenna or fix (fields are empty until
a fix, but the sentences themselves stream). UBX-MON-VER poll requires
no fix and just returns the firmware/hardware version string. Both at
zero = module isn't responding at all.

**Chip-side possibilities (not sketch-side; the sketch is proven on
UART1 + I2C1 addressing):**

  1. VCC not reaching the module -- measure VCC pin on M10S with DMM;
     expect 3V2 (TPS62840 output rail).
  2. TX / RX orientation swapped somewhere between ESP GPIO17/18 and
     the module pads.
  3. V_BCKP (backup) rail issue -- u-blox modules can refuse to start
     if the backup line is shorted or held low. Ivan added a GPS
     supercap; if the supercap is shorted or mis-wired, this bites.
  4. Reset / SAFEBOOT pin held asserted.
  5. Module fried during reflow (Stage 24 Phase B was a single-pass
     hot-air reflow; possible cold silicon damage).

**Board draw jumped 35 mA -> 45 mA once the ESP-IDF firmware enabled
UART1 to the M10S**, so the module IS drawing some current (+10 mA is
plausible for a silent-but-powered M10S). That's soft evidence the
chip has VCC. The silence is UART-specific.

**Action queued for §2.1 GPS session next time Ivan has iron on the
bench:** measure VCC + V_BCKP on the module, DMM continuity check on
TX/RX pair, scope on module TX pin during boot to look for the
power-on NMEA burst. If nothing, hot-air reflow with fresh flux.
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

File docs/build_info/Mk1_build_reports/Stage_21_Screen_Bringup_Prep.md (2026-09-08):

# Stage 21 -- Screen Bring-up Prep (Mk1b arrival + GPS Day-1)

**Date opened:** 2026-09-08
**Board:** iv7.1 (Mk1 bench); Mk1b PCB in fab, screen test breakout received and pins cross-referenced -- pinout for the Mk1b display should be correct.
**Firmware baseline:** `iv7.1.f0.4.26` -> target `0.5.0` on Mk1b, `0.4.27+` on iv7.1.
**Status:** OPEN. Coding starts once the plan below is agreed.

---

## 1. Close-outs and defers

### 1.1 Stage 20 CLOSED at `0.4.26`

Bench flash landed. Ivan: "so much better now. sure there's still the
5 s wait, but at least the button is super responsive." The 5 s cold-
boot delay is BQ25619 QON wake + ESP cold boot + firmware init; not a
firmware-only fix (see Stage 20 §6.3 -- parked with the possible wins
listed).

- Press-edge haptic (0.4.25) confirmed firing.
- BATFET_DLY clear + BATFET_RST_WVBUS set (0.4.26) took ship-mode
  latency from ~9 s to ~1 s. Bench-verified.
- I2C mutex extern fix (0.4.26) puts BQ back on bus 1 alongside DRV.

Archive when convenient:

```
python docs/build_info/reference_files/make_archive.py stage-20-button-responsiveness
```

### 1.2 Stage 19 DEFERRED (parked, not cancelled)

Power-management refinement is a large, multi-week piece of work (park/
idle/off vocab, boot policy rewrite, profiling infra, per-driver park
helpers, CLI reorg). It is orthogonal to Mk1b bring-up and to the GPS
Day-1 deliverable. Deferring the whole thing.

- The Stage-11 -> Stage-18 ~17 mAh regression stays measured but
  unfixed. Runtime target is post-trip work.
- `battery_tag` NVS key (Stage 19 §7) also deferred; current `fw=`
  grouping is good enough.
- Stage 19 doc stays OPEN so the fresh-chat prompt at the top still
  fires cleanly when we come back to it.

Rationale: the trip needs a screen + GPS. Adding ~500 uA of gesture
drain or 30 % `rtos0/1` CPU_MAX doesn't matter if the operator can't
read a coordinate.

### 1.3 Everything else that was floating

- LVGL tile spec (Stage 18 §5): DONE, doc-only, ready to implement.
- Wrist gesture (Stage 18 §7.1, §9.1): landed, stays as-is.
- iv7.1 -> Mk1b delta plan (`docs/build_info/reference_files/`): DONE,
  Stage 21 executes against it.
- AMOLED touch sketch (`arduino/15_amoled_touch_test/`): audited,
  ready as first post-reflow-A flash on Mk1b.
- Photo-GPS Plan B (Waveshare fallback): dormant, only triggers if
  Mk1b screen fails after reflow-A.

---
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

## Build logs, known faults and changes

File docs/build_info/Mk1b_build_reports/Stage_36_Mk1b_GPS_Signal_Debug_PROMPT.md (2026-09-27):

# Stage 36 -- Mk1b GPS signal / GPS_PING debug (fresh-session prompt)

**Date opened:** 2026-09-27
**Board:** Mk1b iv8.0.
**Firmware baseline:** 0.4.91 (Stage 35 close: i2c_master migration
complete, sensor surface trimmed).
**Status:** OPEN, queued.

Paste the "**Prompt for a fresh Claude instance**" section below into a
new session's first message.

---

## Symptoms (from Stage 35 close bench, fw 0.4.91)

- Chip is talking two-way. Boot log shows `MAX-M10S init OK
  (dynmodel=PED, MON-RF on)`, and background counters accumulate:
  `total=612  mon_ver=0  mon_rf=611  nav_timeutc=0  ack_ack=1
  ack_nak=0`.
- MON-RF snapshot is stable: `antStatus=OK(2)  antPower=ON(1)
  noise/ms=64-65  AGC count=3534 (~43%)`. Antenna not shorted, not
  open, chip is powering it, RF frontend AGC is mid-range.
- SNR is bad and bursty. `GPS_SNR` reports `sats_with_snr=0
  max CN0=0` most of the time; when signal does appear it peaks
  at **17-21 dBHz** and only for ~2 s at a time before dropping
  back to noise for another ~2 s. Never enough continuous signal
  for a fix.
- `GPS_PING` (UBX-MON-VER poll) consistently reports "NO
  UBX-MON-VER response in 1000 ms" -- even though every other UBX
  path works (`ack_ack` increments, MON-RF frames pour in). Only
  MON-VER never comes back. `mon_ver=0` in the UBX counter dump.

## Hardware context

- Chip: u-blox MAX-M10S GNSS module.
- Antenna: chip antenna (small ceramic), passive.
- Antenna is covered by ~1 mm of clear epoxy on the assembled Mk1b.
  Visible through the epoxy. Ivan is skeptical this is the problem
  but can't rule it out.
- UART is verified working: `uart_wait_tx_done()` fix landed in
  Stage 31 appendum, MON-RF proves TX+RX are healthy end-to-end.
- VIO_SEL floats (3V3 mode), SAFEBOOT_N floats (per
  `project_max_m10s_wiring`).
- 1PPS on GPIO46, wired but not exercised by current firmware.

## Two suspects, one investigation

### Suspect A -- GPS_PING is broken, not the chip

Every UBX message class works EXCEPT MON-VER. Three hypotheses
(inherited from the 2026-09-23 Gemini session, filed in
Stage 31 §11 GPS appendum -- read that first):

1. **Poll frame checksum wrong** -- the 8-byte MON-VER poll is
   `B5 62 0A 04 00 00 0E 34`. Verify the two Fletcher checksum
   bytes are actually `0x0E 0x34` on the wire, not
   pre-computed against the wrong header.
2. **Dispatcher not routing MON-VER back to our handler** --
   check `max_m10s_feed_ubx_byte()` -- confirm the branch for
   class `0x0A` id `0x04` calls `handle_ubx_mon_ver()`. Watch
   with a DEBUG log at the top of the branch to see if it's
   even being entered when a response arrives.
3. **Response length guard too strict** -- `handle_ubx_mon_ver()`
   likely rejects payloads shorter than 40 bytes. u-blox MAX-M10S
   returns a MON-VER of exactly 40 (SW+HW versions) or 40+30*N
   (with N extension strings). If our chip's firmware ships with
   fewer extensions, we might drop a valid response. Relax to
   `len >= 10`.

Do all three before concluding the chip's MON-VER is broken.
The pinpoint tool would be a logic-analyzer capture of the
UART lines during a `GPS_PING`. Failing that: temp-add a
verbose-hex dump of every UBX byte received in a 1 s window
after the poll goes out.

### Suspect B -- Antenna / RF path is starving the fix

Even if PING gets fixed, the signal-strength story is bad on its
own merit. Numbers to interpret:

- **17-21 dBHz** max CN0: fix requires ~25 dBHz sustained on
  4+ satellites for cold start, ~30+ dBHz for reliable tracking.
  We are below that floor. GPS chips will NEVER get a fix from
  17-21 dBHz signals -- they can't decode the ephemeris.
- **Bursty on/off**: 2 s on, 2 s off pattern suggests either
  (a) antenna tuned wrong (satellite drifts in/out of resonance
  peak as it moves through the sky), (b) severe multi-path
  from nearby metal, or (c) self-noise from another peripheral
  (worst offender is usually the display QSPI clock or
  switched-mode power supply harmonics).
- **AGC count 3534 (~43%)**: the AGC control word is 0..8191.
  Mid-range means the frontend is neither cranked to max gain
  (nothing to receive) nor pinned at min gain (RF overload).
  It's what "quiet RF environment with some noise" looks like.
  For reference: strong open-sky signal usually pushes AGC
  DOWN (~10-25%); heavy jamming pushes it UP (~80%+). 43%
  says the chip is not being blinded, but signal is weak.
- **noise/ms 64-65**: u-blox integer noise metric. Anything
  under ~150 is a clean environment. Our value is clean.
  So no local interference -- the antenna just isn't picking
  up the sky.

Bottom line: with clean noise + mid AGC + no CN0, the story is
**"antenna cannot see the sky well enough"**. Chip is fine.
Epoxy covering + small chip antenna + indoor testing all
compound.

## What to try, in order

1. **Fix GPS_PING first** (Suspect A). Without a working
   MON-VER poll we can't ask the chip for its firmware version
   or run other pokes. Cheap wins there. Follow the three leads
   in Stage 31 §11 appendum.
2. **Bench-test outdoors** with the current build. Take the
   watch outside with clear sky for 5-10 minutes. If CN0
   climbs past 30 dBHz on any satellite, the epoxy + tiny
   antenna are just marginal -- workable but poor. If CN0
   stays 17-21 dBHz outdoors, the antenna installation is
   broken (impedance-mismatched, detuned by epoxy, ground
   plane wrong, or the antenna itself is bad).
3. **If outdoors doesn't help:**
   - Try a temporary flying-wire active antenna (u-blox ANN-MB
     is the standard bench antenna). Rules out chip-antenna-
     specific problems. If SNR jumps to 40+ dBHz with an
     active antenna, the on-board chip antenna is the culprit.
   - Measure the antenna's return loss / VSWR at 1.575 GHz
     if you have a VNA. Detuning by epoxy is measurable.
   - Consider a Mk2 respin with a proper GPS antenna
     footprint (larger ceramic patch, ground plane sized
     per antenna datasheet).
4. **Do NOT chase self-noise until 2 and 3 have been done.**
   Noise/ms is already low; adding shielding is expensive and
   unlikely to help.

## Files to read on the way in

- `firmware/esp-idf/components/max_m10s/max_m10s.c` (driver
  proper, feed_ubx_byte / handle_ubx_mon_ver / ubx_send_*)
- `firmware/esp-idf/components/max_m10s/max_m10s.h` (public API,
  including UBX class/id defines)
- `firmware/esp-idf/components/field_capture/fc_cli.c` (GPS_PING,
  GPS_SNR, GPS_MONRF, GPS_UBX_STATS, GPS_DYNMODEL verbs)
- `docs/build_info/Mk1b_build_reports/Stage_31_Mk1b_LVGL_Foundations_Rebuild.md`
  §11 "2026-09-23" appendum (GPS UART TX close + the three
  GPS_PING debug leads)
- `docs/build_info/Mk1b_build_reports/GPS_M10S_Fixing.md` (full
  diagnostic trail from the pin-swap saga)
- `docs/build_info/reference_files/datasheets/` -- check for
  MAX-M10S Integration Manual + Interface Description PDFs.
  If missing, u-blox document numbers are UBX-20035208 (Data
  Sheet), UBX-20053088 (Integration Manual), UBX-19035940
  (Interface Description).

## Auto-memory to consult

- `project_max_m10s_wiring` -- VIO_SEL / SAFEBOOT_N conventions.
- `project_mk1b_arrived` -- board rev context.
- `project_photo_gps_plan_b` -- fallback external-GPS plan if
  Mk1b GPS never delivers a fix in a reasonable timeframe.

---

## Prompt for a fresh Claude instance

Copy-paste the block below verbatim into a new session's first message.

```
Continue GPS debug on Mk1b iv8.0, fw 0.4.91 baseline.

Read the full context here:
  docs/build_info/Mk1b_build_reports/Stage_36_Mk1b_GPS_Signal_Debug_PROMPT.md

Two problems to disentangle in order:
  1) GPS_PING (UBX-MON-VER poll) never gets a response, even though
     every other UBX path works (mon_rf=611+, ack_ack=1, mon_ver=0).
     Three hypotheses inherited from the 2026-09-23 Gemini session
     already filed in Stage 31 §11 appendum -- read that first.
     Fix GPS_PING before any deeper GPS work.
  2) SNR peaks at 17-21 dBHz and bursts on/off in 2 s cycles;
     AGC ~43%, noise/ms ~65, ant OK. Below the ~25 dBHz floor
     needed for a fix. Interpretation + suggested bench sequence
     is in §"Suspect B" of the Stage 36 prompt.

Follow the "What to try, in order" list. Don't chase self-noise
until the outdoor bench + swap-antenna checks are done -- noise
metrics say the RF environment is quiet.

Boot logs, tile behavior, and the exact CN0/AGC/noise numbers
observed on the Stage 35 close bench are in §"Symptoms" of the
Stage 36 prompt file.

Open Stage_36_Mk1b_GPS_Signal_Debug.md as the working stage doc
(use the frontmatter convention per feedback_md_frontmatter_convention).
```

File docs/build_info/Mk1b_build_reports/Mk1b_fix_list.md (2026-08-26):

# Mk1b iv8.0 — Fix Application Log

**Rev:** Mk1b iv8.0
**Started:** 2026-08-22
**Log updated:** 2026-08-22 (fix application pass 2 — restructured circuit-side / PCB-side)
**Scope:** Same PCB, same BOM (all named ICs). JLCPCB assembles **0402 passives only**. Ivan hand-solders every IC on arrival — the "part-by-part heat-gun rework" cycle is dead. Mk1b is a single clean build pass.
**Goal:** Fold every bench-proven iv7.1 fix into the board itself, unblock the display, pull in the MAX17048 fuel gauge. Full Mk2 industrial-design pass stays deferred.

Legend: ✓ done · ✗ closed as N/A / bad-advice · ⚠ open · → deferred to Mk2

---

## Motivation — the six iv7.1 blockers

- **F-DISP-1** AMOLED FPC receptacle mirrored (display bring-up impossible on iv7.1)
- **F-FLASH-1** BSS138W die-level leak → BC847C swap
- **F-VIO-1** LSM/BME/mic VDDIO on +1V8 back-fed the rail via ESD clamps
- **F-LDO-1** XC6206 library symbol Vin/Vout swap delivered **2.8 V (backfed 3V3 through the reversed LDO) into a 1V8-rated pin**, killing a MAX30101. Not a 3V3-rail-health issue — 3V3 was fine.
- **F-FLASH-2** Flashlight FET wired source-follower (LED could never conduct)
- **F-BQ-1** BQ25619 R12 (5k1 to +3V3 on /QON) trapped ship mode

---

# PART A — CIRCUIT-SIDE (schematic / BOM / component values / net topology)

## A.1 Power — BQ25619 / TPS62840 / XC6206

| ID | Fix | Status | Note |
|---|---|---|---|
| F-BQ-1 | R12 = DNP | ✓ | BQ internal 200 kΩ pull to V_BAT is enough |
| F-BQ-2 | C15 REGN 1 µF → 4.7 µF | ✓ | 4.7 µF exact — 10 µF is off-datasheet, no upside |
| F-BQ-3 | C10 BTST 100 nF → 47 nF | ✓ | Applied |
| F-BQ-4 | R10 PMID_GOOD reroute | ✗ | Closed — PMID_GOOD is a bare pad in your schematic, no R10 exists |
| F-BQ-5 | PSEL to GND | ✓ | Confirmed |
| F-BQ-6 | BATSNS to BAT+ | ✓ | Confirmed direct to LiPo+ |
| F-BQ-7 | JP1 audit | ✗ | Closed — JP1 is PGND↔GND local star ground, not SYS↔BAT bridge |
| F-BQ-8 | /INT to GND | ✓ | Tied |
| F-BQ-9 | TS thermistor 5.36k / 31.6k → 5.1k / 30k (E24) | ✓ | Trip points shift ~2-3 °C in the safer direction. Topology: REGN → R14 (5.1k) → TS_node → R26 (30k) ∥ NTC 10k → GND |
| F-TPS-1 | MODE tied GND (power-save) | ✓ | |
| F-TPS-2 | STOP tied GND | ✓ | |
| F-LDO-1 | XC6206 symbol Vin/Vout fixed | ✓ | Fixed in schematic. Library-side refresh deferred to Mk2 (XC6206 moved position in library since last touch). Failure-mode reminder in header. |

## A.2 ESP32-S3

| ID | Fix | Status | Note |
|---|---|---|---|
| F-ESP-1 | EN RC: R33 10 k series + cap → GND | ✓ | Cap bumped 100 nF → **1 µF** for 10 ms brown-out ride-through, matches datasheet |
| F-ESP-2 | Master pinout v20 GPIO assignments unchanged | ✓ | Firmware is stable against this pinout |

## A.3 Sensor VDD / VDDIO domain split

| ID | Fix | Status | Note |
|---|---|---|---|
| F-VIO-1 | LSM6DSV16X | ✓ | **Everything on 3V3 except VDD which stays on 1V8.** 3V3 to pin 5 VDDIO, pin 1 SDO/SA0 (address bit), pin 10 OCS_Aux (unused, HIGH), R19 5k1 CS pull-up. VDD 1V8 within spec (1.71-3.6 V). |
| F-VIO-2 | BME688 | ✓ | VDDIO 3V3, VDD 1V8 |
| F-VIO-3 | MSM261DGT003 mic | ✓ | Whole VDD on 3V3 (spec min 3.3 V — cannot run on 1V8) |
| F-VIO-4 | +1V8 rail kept | ✓ | MAX30101 V+ demands 1V8; sensors that support 1V8 VDD run there for rail savings, VDDIO always on 3V3 |
| F-VIO-5 | **LIS3MDL both VDD and VDDIO on 3V3** | ✓ | Both rails 3V3, 10 µF + 100 nF decoupling. LIS spec VDD_min = 1.9 V and XC6206P182 output can drop to 1.764 V worst-case — LIS is the outlier that must not run on 1V8 |
| F-MIC-1 | Mic decoupling 100 nF + 10 µF | ✓ | C46 10 µF added |

## A.4 Flashlight

| ID | Fix | Status | Note |
|---|---|---|---|
| F-FLASH-1 | BSS138W → BC847C | ✓ | Drop-in SOT-23. Vetted low-leakage FET returns in Mk2. |
| F-FLASH-2 | Redraw as low-side switch | ✓ | +5V → R25(100R) → LED → BC847C collector → emitter → GND |
| F-FLASH-3 | R_base (R32) → 3 kΩ | ✓ | β_forced ~125 at 100 mA LED — comfortable saturation |
| F-FLASH-4 | R26 47 Ω restored | ✗ | Closed — with BC847C + R25=100R, R26 as series is redundant. R26 designator now the TS-network 30k (F-BQ-9). |
| F-FLASH-5 | R24 base pull-down 10 k | ✓ | **Keep at 10 k** — guaranteed-OFF at boot when GPIO41 is Hi-Z. Waste when ON is 70 µA, negligible |

## A.5 SD — electrical (pull-ups, decoupling values)

| ID | Fix | Status | Note |
|---|---|---|---|
| F-SD-1 | CLK pull-up 10 k populated | ✓ | R34 = 10 k to 3V3 |
| F-SD-3 | Pull-ups on CLK/CMD/DAT0/DAT1/DAT2/DAT3 | ✓ | **All four DAT + CMD + CLK at 10 k to 3V3.** SD spec allows 10-100 kΩ; 10 k is standard and reliable at ESP32-S3 SDMMC speeds. Stage_8 §7's "5.1k default" recommendation is closed as **bad advice for this design** — over-specified for a use case that runs 1-bit at ~20 MHz. |
| F-SD-2 (electrical part) | Bulk decoupling 1 µF + 100 nF at SD socket | ✓ | C47 1 µF added; placement note in B.2 |
| — | 1-bit vs 4-bit SDMMC throughput (ESP32-S3) | — | 1-bit ≈ 2 MB/s sustained write, 4-bit ≈ 8-10 MB/s. Sensor logging at kB/s → 1-bit plenty |

## A.6 Fuel gauge — Mk2 pull-in

| ID | Item | Status | Note |
|---|---|---|---|
| P-FG-1 | **MAX17048G+T10** fuel gauge, TDFN-8, I²C 0x36 on bus 1, ~€1 | ⚠ | Wiring: VDD on BAT+ (pre-regulator, direct LiPo), 0.1 µF decoupling close to VDD, ALRT unconnected. Also serves as the Vbat-sense replacement — no ADC divider on Mk1b. Not yet placed in schematic. |

## A.7 AMOLED connector — schematic side

| ID | Fix | Status | Note |
|---|---|---|---|
| F-DISP-1a | Connector **symbol** pin mirroring | ✓ | Symbol pin 13 now = GND net, pin 1 now = 3V3 net (matches the physical FPC). PCB verification pending — see B.1. |

## A.8 Closed / deferred — circuit side

| ID | Item | Status | Note |
|---|---|---|---|
| F-USB-1 | Wire both D+/D- pairs | ✗ | **Fake news** — both pairs were already wired correctly on iv7.1. USB failure was a physically loose / broken receptacle from bench abuse, not schematic |
| F-QVAR-1 | Series AC-coupling caps | ✗ | QVAR path depopulated / deprecated |
| F-QVAR-2 | 10 MΩ body-bias resistor | ✗ | Same |
| F-VBAT-1 | Vbat divider to ADC1 pin | ✗ | No divider on Mk1b — MAX17048 (P-FG-1) replaces it. ADC-based Vbat returns in Mk2 with BQ25896-with-ADC |
| F-MAG-1 | Relocate LIS away from LRA | ✗ | Fake news — dead-channel was rework-magnetization, not LRA proximity. Location fine. (See F-DOC-1 for degauss procedure note) |

---

# PART B — PCB-SIDE (footprint / layout / silk / mechanical / documentation)

## B.1 AMOLED receptacle — footprint / PCB verification

| ID | Fix | Status | Note |
|---|---|---|---|
| F-DISP-1b | Verify netlist maps correctly to physical FPC after PCB update-from-schematic | ⚠ | Symbol pin-mirroring done (A.7). After updating the PCB from the schematic, physically lay the CO5300 FPC across the footprint contacts-down and verify pin 1 (3V3), pin 13 (GND), pin 24 lands where expected. |
| F-DISP-2 | Re-audit ordered part suffix (T vs B contact-face variant) | ⚠ | Pin exact suffix in BOM once verified |
| F-DISP-3 | Pin-1 silkscreen dot next to J1 | ⚠ | Also covered by general F-ASM-1 |
| F-DISP-4 | Test-pads on 14 named display nets adjacent to J1 | ⚠ | QSPI ×6, TP-SDA/SCL/INT/RST, DISP_RST, TE, +3V3, GND — lets us DMM-verify the pinout before mating the panel |

Sketch `firmware/arduino/15_amoled_touch_test/15_amoled_touch_test.ino` is preserved and will be Mk1b's first-flash for display bring-up.

## B.2 SD layout

| ID | Fix | Status | Note |
|---|---|---|---|
| F-SD-2 (PCB part) | 1 µF X7R + 100 nF placed on same face as SD socket, close to socket VDD pin | ⚠ | Component values added in A.5; placement pending during layout |
| F-SD-4 | Continuous GND under SDMMC bus + stitching vias | ⚠ | Check during routing |
| F-SD-5 | Route DAT3 to a real GPIO | ✗ | Closed — no free GPIO |
| F-SD-6 | Molex 472192001 flip-up socket (same footprint) | → | Deferred to Mk2 |

## B.3 Assembly rules — silk / pad extension / BOM notes

| ID | Rule | Status | Note |
|---|---|---|---|
| F-ASM-1 | **Pin-1 silkscreen dot** on every FPC and every QFN/LGA | ⚠ | Highest ROI item — would have caught F-DISP-1 on iv7.1 |
| F-ASM-2 | Perimeter pad extension 0.4-0.5 mm outward on LGA/DFN parts (LSM, LIS, BME, TPS62840, XC6206) | ⚠ | Enables hot-air rework to catch pads from outside |
| F-ASM-3 | BOM note: `ESDALCL5-1BM2 reads OC in DMM diode mode when healthy` | ⚠ | Cheap doc-only step |

## B.4 Case bond — Mk2 cheap pull-in

| ID | Item | Status | Note |
|---|---|---|---|
| P-CASE-1 | 2×2 mm bare-copper GND pad where the future titanium case shell will contact | ⚠ | Costs nothing on the PCB, future-proofs the case bond |

## B.5 Closed / deferred — PCB side

| ID | Item | Status | Note |
|---|---|---|---|
| F-USB-2 | Reinforced / mid-mount USB-C footprint | → | Deferred to Mk2. iv7.1's port fatigue was rework-cycle induced, not the footprint per se — the "no more heat-gun abuse" build discipline addresses the underlying cause |

## B.6 Documentation / procedural

| ID | Item | Status | Note |
|---|---|---|---|
| F-ASM-4 | **Pre-fab checklist file** — mandate physical FPC / polar-part lay across every KiCad footprint before Gerber export | ⚠ | Highest-priority process fix. Seed with F-DISP-1 as the founding case study |
| F-DOC-1 | Magnetometer degauss procedure | ✓ (note-only) | **Fix for stuck / saturated LIS channel**: rotate a small magnet in a circular pattern near the LIS, then slowly withdraw the magnet away from the board while continuing to rotate it. Decays magnetic bias in the sensor's core below the reset threshold. |

---

# Assembly note

JLCPCB assembles 0402 passives only. All ICs (ESP32-S3-WROOM-1U, BQ25619, TPS62840, XC6206, MAX-M10S, MAX30101, LSM6DSV16X, LIS3MDLTR, BME688, TMP117, PCF85063A, DRV2605L, MSM261DGT003, MAX17048, BC847C, USB-C, SD socket, receptacle J1, WS2812B-2020) hand-soldered by Ivan on arrival in a single clean build pass — no more part-by-part rework cycles.

BOM must be split clean: `JLC-assembles` (0402 R/C only) vs `Ivan-hand-solders` (everything else). No mixed-tier parts.

---

# Remaining actions before Gerber export (ordered by priority)

1. ⚠ **P-FG-1** — MAX17048 fuel gauge placed and wired (VDD on BAT+, 0.1 µF decoupling, ALRT NC, I²C bus 1). *Circuit-side, not yet drawn.*
2. ⚠ **F-DISP-1b** — after PCB update-from-schematic, physically lay CO5300 FPC across footprint contacts-down and verify the netlist.
3. ⚠ **F-DISP-3, F-DISP-4** — pin-1 silk dot at J1, test-pads on 14 named display nets.
4. ⚠ **F-ASM-4** — seed the pre-fab checklist file with F-DISP-1 as founding case study.
5. ⚠ **F-ASM-1** — silk pin-1 dots on every FPC / QFN / LGA (this closes F-DISP-3 by rule).
6. ⚠ **P-CASE-1** — case-to-GND bond pad.
7. ⚠ **F-ASM-2, F-ASM-3** — perimeter pad extensions + ESD-diode BOM note.
8. ⚠ **F-SD-2 (PCB part), F-SD-4** — bulk cap placement + SD GND-plane / stitching-via check.

Everything else in Part A is done or explicitly closed.

Go.

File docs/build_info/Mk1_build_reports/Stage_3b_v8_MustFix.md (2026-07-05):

# v8 PCB Must-Fix List — Kompic Mk

**Created:** 2026-06-29
**Scope:** Forward-looking. Every PCB-level change that needs to land in the next board revision (whether that's Mk I v8 or Mk II v8), distilled from Stages 1–3 build reports plus the 2026-06-29 desk session.

This is the PCB designer's bench plan. Bench-actionable items on the iv7.1 prototype live in `Bench_Plan_iv7.1.md`. The SD-specific rescue plan is `SDMMC_Rescue_Plan_iv7.1.md`.

**Items are tagged:**
- **[CRITICAL]** = bug that breaks the board, must fix or v8 will fail in the same way.
- **[IMPROVEMENT]** = quality-of-life / robustness, strongly recommended but not strictly blocking.
- **[NEW]** = added feature / part that wasn't on iv7.1.

---

## Section 1 — Schematic library / pinout bugs (CRITICAL)

These are silent failures. ERC won't catch any of them because the connectivity is internally consistent — it just doesn't match the physical chip.

### 1.1 [CRITICAL] XC6206P182MR symbol pin swap

**Origin:** Stage 3 § 4.8.
**Bug:** Library symbol `Kompic_Mk1:XC6206P182MR` has Vin / Vout pin names swapped. Pin 2 is labeled "Vin" but on the datasheet it's Vout; pin 3 is labeled "Vout" but the datasheet says Vin.
**Consequence on iv7.1:** the +1V8 rail was driven backwards into the chip. Rail measured 2.3–2.6 V (internal ESD diodes leaking) instead of 1.8 V. Killed the MAX30101.
**Fix for v8:** edit the symbol so pin 2 = Vout, pin 3 = Vin. Re-run ERC. Verify against the SOT-23-3 datasheet pinout before fab.
**Owner:** library file under `hardware/Kompic_Mk1/Kompic_Mk1_library/`.

### 1.2 [CRITICAL] LSM6DSV16X and BME688 VDDIO routing

**Origin:** Stage 3 § 4.9.
**Bug:** Both chips' VDDIO / Vdd_IO pins are routed to +1V8, but the I²C bus they sit on runs at +3V3. The chips' I/O ESD clamps go to VDDIO, not VDD, so each SDA/SCL line back-feeds current from +3V3 through the chip into the +1V8 rail. With three chips × multiple I/O pins, the cumulative back-feed prevented the LDO from regulating, settled the rail at ~`3V3 − Vf` ≈ 2.3–2.8 V. Contributed to MAX30101 overvoltage death.
**Consequence on iv7.1:** bench-fixed by cutting the +1V8 trace at C29 and jumpering the affected branch to +3V3. LSM/BME/mic now run entirely on +3V3.
**Fix for v8:** in `4_Air_Sensors.kicad_sch` and `3_Space_Time_Sensors.kicad_sch`, route VDDIO of LSM6DSV16X and BME688 to +3V3. The rule going forward: **VDDIO matches the bus voltage. VDD is free to be lower.** Audit every chip with a separate VDDIO pin against this rule before fab.
**Note:** LIS3MDLTR is correctly wired on iv7.1; no change needed.
**Reference:** datasheets in `firmware/docs/datasheets/`: `lsm6dsv16x.pdf` Table 2 p. 11, `bst-bme688-ds000.pdf`, `lis3mdl.pdf` Table 7 p. 8.

### 1.3 [CRITICAL] PDM mic VDD voltage

**Origin:** Stage 3 § 4.9 (carried into rework, same family of issue).
**Bug:** MSM261DGT003 VDD min spec is 3.3 V (or 3.6 V depending on rev). iv7.1 routed it to +1V8.
**Consequence on iv7.1:** mic was operating below VDD min before the C29 cut moved it to +3V3.
**Fix for v8:** mic VDD on +3V3 net by design, no jumpering required.

---

## Section 2 — Schematic topology bugs (CRITICAL)

### 2.1 [CRITICAL] Flashlight FET source-follower → low-side switch

**Origin:** Stage 3 § 4.2.
**Bug:** `5_Lights.kicad_sch` has the BSS138W wired as a source follower. With GPIO41 at 3.2 V, the FET's source pinches at ~1.5–2.0 V — below the LED's V_f. The LED can never light no matter how good the FET is.
**Consequence on iv7.1:** bench-fixed with two cuts + two jumpers (LED moved from FET source to drain side, FET source jumpered to GND). Lost R26 during probing — restocking needed in `Bench_Plan_iv7.1.md` § 1.4.
**Fix for v8:** redraw the FET symbol so source is on the GND rail. Standard low-side switch topology:
```
+5 V → R25 → R26 → LED_anode → LED_cathode → FET_drain → FET_source → GND
```

### 2.2 [CRITICAL] USB-C both-side D+/D- routing

**Origin:** 2026-07-05 bench session (Stage 4 Build Report § 2.5).
**Bug:** Iv7.1's USB-C connector only wires *one* D+/D- pair to the ESP32-S3 (GPIO19/20). USB-C is reversible only if either both A-side and B-side D+/D- pairs are wired, or a CC-controlled mux switches between them. Iv7.1 has neither → one plug orientation enumerates cleanly, the other produces `device descriptor read/64, error -71` in dmesg because the ESP is looking at floating pads instead of the cable's data lines.
**Consequence on iv7.1:** minor annoyance; work around by always plugging the cable the correct way. But this cost half a bench session diagnosing what looked like a firmware/USB-PHY hang.
**Fix for v8:** wire both D+/D- pairs — either directly (tie A6↔B6 and A7↔B7, works if you don't need USB 3 sideband channels) or through a CC-based orientation mux (TS3USB221, PI3USB102, etc.). Either approach makes the cable truly reversible.

### 2.3 [CRITICAL] BQ25619 /QON pull-up routing (R12)

**Origin:** Stage 3 § 8.1.
**Bug:** R12 (5.1 kΩ) pulls /QON to +3V3. When ship mode drops BATFET, +3V3 collapses and R12 becomes a hard pull-DOWN — holds /QON LOW, BQ trips t_SHIPMODE after 0.9–1.3 s, BATFET re-enables, board wakes itself. Ship mode unusable without lifting R12.
**Consequence on iv7.1:** R12 lifted by hand. BQ's own internal 200 kΩ to V_BAT (pin 12) is sufficient — same topology as TI's EVM reference design.
**Fix for v8:** **mark R12 as DNP** in the schematic, leave the footprint as a depopulated placeholder. Don't reroute to V_BAT or SYS — the internal 200 kΩ is the manufacturer-intended pull.

---

## Section 3 — SDMMC bus design (mostly IMPROVEMENT after 2026-07-05)

> **Reclassified 2026-07-05:** the iv7.1 SDMMC bus is functional as designed. See `Stage_4_Build_Report.md`. Items 3.1 / 3.2 / 3.4 / 3.5 / 3.6 / 3.7 below are demoted from CRITICAL to IMPROVEMENT — good practice for margin, not required for function. Item 3.3 (CLK pull-up populated by BOM) remains CRITICAL because the empty footprint required a Stage 3 bench bodge.

**Origin:** Stage 3 § 4.1 + 2026-06-29 desk session (both retracted 2026-07-05).
**Original framing (retained for context):** Even with short traces (CLK = 6 mm, CMD/DAT0 = 15 mm) and DAT1/DAT2 pull-ups populated, SDMMC 1-bit init failed deterministically on iv7.1. Best diagnosis points at insufficient VDD decoupling at the socket, plus possible ground-return discontinuity under the ESP module.
**Corrected framing (2026-07-05):** the failures were card-side (dying 64 GB Kodak AliExpress SDXC + exFAT filesystem), not bus-side. 65/65 PASSes on a 32 GB SDHC msdos card at 400 kHz through 20 MHz with original iv7.1 wiring. Auto-memory: `feedback_suspect_cheap_sd_cards.md`.

### 3.1 [IMPROVEMENT] VDD decoupling on the SD socket

**Bug:** iv7.1 has 100 nF decoupling but on the **opposite face** of the PCB from the socket, ~2–3 mm away across via stack. For the card's 50–100 mA transients during data-block reads, that's effectively no decoupling at SDMMC speeds.
**Fix for v8:** **1 µF X7R + 100 nF ceramic, both on the same face as the SD socket, vias to plane *adjacent* to the cap pads, not 2–3 mm away.**

### 3.2 [IMPROVEMENT] Default pull-up values

**Bug:** iv7.1 defaults to 10 kΩ pull-ups on CLK / CMD / DAT0. Spec allows 10–100 kΩ for legacy mode, but every real-world SDMMC layout above ~1 MHz uses 4.7 kΩ.
**Fix for v8:** **default 4.7 kΩ pull-ups on CLK / CMD / DAT0.** Leave 10 kΩ on DAT1/2/3 (weak pull-up for noise immunity, lines are unused in 1-bit mode).

### 3.3 [CRITICAL] CLK pull-up footprint populated by BOM

**Bug:** iv7.1 CLK pull-up footprint was empty (Stage 3 bench-fixed by hand-soldering a 10 kΩ in).
**Fix for v8:** populate the CLK pull-up in the BOM, not as a "to be added in rework" item.

### 3.4 [IMPROVEMENT] Ground plane continuity ESP ↔ SD socket

**Bug:** SD socket sits under the ESP module on iv7.1. Return current path may have to cross plane discontinuities (modulator cavity, USB-C shell vicinity, antenna keepout). Ringing on CLK / CMD is consistent with high return-loop inductance.
**Fix for v8:** **continuous ground plane between ESP and SD socket.** Stitching via fence along both sides of the SDMMC bus traces. No moats, no slots, no plane cutouts in the bus area.

### 3.5 [IMPROVEMENT] CLK series-R footprint (DNP)

**Fix for v8:** add a 22–47 Ω series-R footprint on CLK between the ESP and the socket, defaulted DNP (0 Ω jumper or omitted at first fab). Belt-and-suspenders for signal integrity once HS speeds are wanted. Damps overshoot at the load without slowing the rise materially.

### 3.6 [IMPROVEMENT] DAT3 routing / CS provisioning

**Bug:** iv7.1 leaves DAT3 floating. With no DAT3 routed, the rescue path "fall back to SPI mode" requires a GPIO0 / DRV_EN sacrifice to get a CS pin (Stage 3 § 4.1 Plan B).
**Fix for v8:** **route DAT3 to a real GPIO** with no strapping conflicts. This unlocks both 4-bit SDMMC (if ever wanted) and SPI fallback without bodge wires. Even if SPI is never used, the option-value is worth one GPIO.

### 3.7 [NEW] Replace push-push socket with Molex 472192001 (flip type)

**Origin:** 2026-06-30 session.
**Bug:** iv7.1 uses a push-push microSD socket. Push-push sockets have notoriously variable contact spring impedance (50 mΩ to a few Ω depending on insertion cycle / oxidation), which contributes parasitic capacitance and contact noise to an already-marginal SDMMC bus. They also have a ~14 × 15 mm plan footprint that's larger than needed since the watch case won't expose an SD slot anyway — card insertion is service-only, push-push eject ergonomics are wasted.
**Part:** Molex **472192001** (LCSC **C164170**). Hinged-lid microSD socket: lid flips open, card slides in under it, lid clicks closed.
**Why it's an upgrade:**
- Plan footprint ~12 × 11 mm vs ~14 × 15 mm push-push — frees board area.
- Lower profile than push-push, helps the watch sandwich.
- Hinged contacts: firmer / less variable than push-push spring tabs. May also help SDMMC signal integrity by reducing contact-impedance variability.
- 8-pin microSD standard, identical pin assignment — zero firmware impact.
**Trade-off:** card change requires opening the case (acceptable since the case has no SD slot exposed anyway). Hinge can fatigue after ~thousands of cycles, irrelevant for "factory load + occasional service" use.
**Fix for v8:** swap the socket in `5_Lights.kicad_sch` (or wherever the SD subsheet lives) for the Molex 472192001 footprint. Verify pad pitch against the datasheet before fab.

---

## Section 4 — Power architecture (NEW + CRITICAL)

### 4.1 [NEW] MAX17048G+T10 fuel gauge

**Origin:** discovered in 2026-06-28 chat — BQ25619 datasheet § 20.13 extract confirms no VBAT readback on the BQ. Without a fuel gauge, the host has no way to compute SoC.
**Part:** MAX17048G+T10 (LCSC stocks it in TDFN-8). Voltage-only ModelGauge m5 fuel gauge, no sense resistor needed.
**Fix for v8:** add to BOM. Wiring:
- I²C address 0x36 (7-bit). Place on bus 2 alongside BQ25619 — keeps all battery-related telemetry on one bus.
- **VDD = battery positive (pre-regulator, 2.5–4.5 V tap). Not off 3V2.**
- 0.1 µF decoupling at VDD, single 0402.
- ALRT pin left unconnected (no spare GPIOs, polling SOC is fine for this use case).
- No other passives.

**Footprint:** TDFN-8 is hand-solderable. Room budget: tighten BOM silkscreen refs (R10–R15 etc.) per Ivan's plan to free a small patch.

### 4.2 [IMPROVEMENT] BQ25619 TS network

**Origin:** Stage 2 § 4.5.
**Bug:** iv7.1 uses 10k + 10k NTC divider. Doesn't match TI's recommended R_T1 = 5.36 kΩ + R_T2 = 31.6 kΩ for the BQ25618/19 JEITA thresholds. Bench workaround: `TS_IGNORE=1` in firmware.
**Fix for v8:** R_T1 = 5.36 kΩ (E96) and R_T2 = 31.6 kΩ (E96). JEITA thresholds will land at nominal temperatures. Drop `TS_IGNORE=1` from firmware once correct network is in place.

### 4.3 [IMPROVEMENT] Mic decoupling per datasheet

**Origin:** Stage 2 § 6.6.
**Fix for v8:** MSM261DGT003 datasheet calls for 100 nF + 10 µF near the mic VDD pin. iv7.1 layout may be missing the 10 µF. Verify and add for v8.

---

## Section 5 — DRV2605L / haptic (CRITICAL + IMPROVEMENT)

### 5.1 [CRITICAL — process] ESD precaution on DRV pads

**Origin:** 2026-06-29 conclusion. DRV silicon degraded — OC threshold collapsed to ~28 mA (one-tenth of spec). Most plausible cause is ESD during rework.
**Fix for v8 / process:** no schematic change required. Add a process note: **DRV2605L pads need standard ESD precautions during hand-rework** (grounded iron, mat, wrist strap). Should have been the rule on iv7.1 too, but documenting it explicitly is the lesson.
**Optional [IMPROVEMENT]:** add a TVS array on the DRV's OUT± outputs to clamp ESD on the LRA-side traces. ELV1411A is on the wrist, easy ESD entry vector. Costs two SOD-882 parts.

---

## Section 6 — Flashlight residual leakage (IMPROVEMENT)

**Origin:** Stage 3 § 8.3.
**Bug:** BSS138W I_DSS leakage (1–25 µA typical) is enough to forward-bias the LED into visible glow when GPIO is LOW.
**Fix options for v8 (pick one):**
- **Bleed resistor** 1–10 kΩ across the LED (anode-to-cathode). Cheapest. Any sub-µA leakage drops across the bleed, doesn't make LED visible. Adds a few µA load at full duty.
- **Lower-leakage FET** (DMG3414U or similar, I_DSS <100 nA). Direct swap, same package. More expensive part.
- **Switch high-side with a PMOS instead of low-side with NMOS.** Gate off pulls drain *and* source to +5V; no path through LED. Most robust but inverts gate logic — `digitalWrite(HIGH)` would mean OFF.

Recommend bleed-resistor approach for v8 — simplest, no logic inversion, gives a fully-off LED.

---

## Section 7 — Carry-forward from earlier reports (IMPROVEMENT)

These items were flagged across the build reports but aren't critical fail-modes. Bundling here so v8 schematic review can sweep them.

### 7.1 PDM CLK voltage-domain mismatch

**Origin:** Stage 2 § 6.7 / PDM extract W1.
**Bug:** 3.3 V GPIO into a 1.8 V-rail device (per the iv7.1 wiring). After the C29 rework the mic is now on 3V3 so the issue is gone for this board, but v8 should design the mic on 3V3 from day one (per § 1.3) with no domain mismatch.

### 7.2 LSM6DSV16X INT1 → GPIO8 wake-from-sleep not yet exercised

**Origin:** Stage 2 § 6.4.
**Status:** firmware-side todo, not v8 schematic change. Listed here so it's not forgotten.

### 7.3 LIS3MDL hard-iron offset calibration

**Origin:** Stage 2 § 6.3 / Stage 3 § 4.7.
**Status:** firmware-side todo (figure-8 swing, persist OFFSET_X/Y/Z_REG to NVS). Not v8 schematic change.

### 7.4 ESDALCL5-1BM2 BOM note

**Origin:** Stage 3 § 4.3.
**Fix:** add a BOM line note on the ESDALCL5-1BM2: "healthy reads OC in DMM diode mode (bidirectional 5 V TVS; DMM test voltage is below breakdown)." Prevents the next assembler from desoldering all five "diodes" during bring-up under the misapprehension that they're broken.

---

## Section 8 — Architectural questions for v8 scope decision

These aren't bugs — they're open questions Ivan is weighing for whether v8 is "Mk I v8" (minimal-change patch of iv7.1) or "Mk II v8" (clean-sheet re-architecture).

### 8.1 Decompose ESP32-S3-WROOM-1U → ESP32-S3 core + PSRAM + crystal + antenna network

**Trade-off:** module is plug-and-play (RF cert pre-done) but takes board area and gives no design flexibility. Discrete approach lets the RF section be tuned but requires RF cert work and good layout discipline.
**Ivan's current call:** low priority for the next revision; attempt is optional, certification can wait.

### 8.2 Mk I patch vs Mk II clean-sheet

**Status:** undecided. If v8 is "Mk I patched," only critical bugs above need fixing. If v8 is "Mk II clean-sheet," every item here gets reconsidered against the new architecture, and the v8 doc itself gets re-scoped.

---

## Section 9 — Footprint design rule: extend perimeter pads outward

**Origin:** 2026-06-30 session, generalized from the Stages 1–3 rework experience.

**Bug:** EasyEDA's auto-converted footprints follow JEDEC standard — pads sized tight to the package body, optimized for high-density automated assembly. On iv7.1 this meant the LGA / DFN parts (LSM6DSV16X, LIS3MDLTR, BME688, TPS62840, XC6206) have pads entirely *under* the chip body. Three real costs:
1. **Smaller pad area → smaller paste volume → higher cold-joint risk.** Especially with the manual-paste fallback (50:50 lead-free + leaded on hidden pads).
2. **No probe point** during bring-up. The reason BQ25619 was easy to debug in Stage 3 was that its WQFN-24 leads stick out past the body — the LSM/LIS/BME/TPS could not be probed at all without lifting the chip.
3. **No visible fillet** under magnification — joint quality has to be inferred from electrical behavior, not visual inspection.

**Fix for v8:** **manually edit every footprint after EasyEDA → KiCad import to extend perimeter pads outward from the package body.** Direction is **outward only** (toward board edge), never inward. Standard extension by part class:

| Part class | Extend? | How much |
|---|---|---|
| QFN / WQFN with already-exposed leads (BQ25619 style) | already done | n/a |
| LGA with hidden pads (LSM6DSV16X, LIS3MDLTR, BME688) | **yes, extend** | 0.4–0.5 mm outward |
| DFN with hidden pads (TPS62840, XC6206, PCF85063A) | **yes, extend** | 0.4–0.5 mm outward |
| Fine-pitch (≤0.4 mm pitch) chips | extend small | 0.2–0.3 mm — bridge risk past that |
| Center thermal pads (QFN bellies) | leave standard | thermal connection only, no probe value |
| 0402 passives | **leave standard** | extension causes tombstoning during reflow (asymmetric thermal mass) |
| 0603 / 0805 passives | optional small extension | 0.1–0.2 mm OK, low tombstone risk |

**Wins per Stage-3 lessons:**
- More paste flow per pad → less cold-joint risk (matches the dire-straits paste workflow we keep falling back to).
- Probe access for the LGA/DFN parts that were un-debuggable on iv7.1.
- Better visual inspection of solder fillet at the package edge.
- Larger pad mass = better thermal anchor + less mechanical stress concentration.

**Don't apply** to: center thermal pads, 0402 passives, anything finer than 0.4 mm pitch (judgment call per part).

## Section 10 — 3D model housekeeping

EasyEDA-derived STEP/WRL models carry small "EasyEDA" branding visible in the 3D viewer. Acceptable for this personal / educational project — keep the models as-is. If v8 ever moves toward commercial review, swap the chip-specific models for manufacturer-sourced STEP (ST, TI, Bosch all host them) and use KiCad's built-in 3D library for generic passives.

## Section 11 — Update log

| Date | Item | Status |
|---|---|---|
| 2026-06-29 | Initial draft, post-2026-06-29 desk session | Captured all known critical bugs from Stages 1–3 + new conclusions (DRV chip damage, SDMMC regression, MAX17048G add). |
| 2026-06-30 | Added § 3.7 (Molex 472192001 flip SD socket), § 9 (footprint pad-extension design rule + per-part table), § 10 (EasyEDA 3D model branding note). Renumbered update log → § 11. | — |
| 2026-07-05 | § 3 SDMMC items 3.1/3.2/3.4/3.5/3.6/3.7 demoted CRITICAL → IMPROVEMENT after Stage 4 verification. 3.3 still CRITICAL (empty CLK pull-up footprint). Added new § 2.2 CRITICAL: USB-C both-side D+/D- routing (iv7.1 wires only one, breaks reversibility). Renumbered BQ /QON to § 2.3. | See `Stage_4_Build_Report.md`. |

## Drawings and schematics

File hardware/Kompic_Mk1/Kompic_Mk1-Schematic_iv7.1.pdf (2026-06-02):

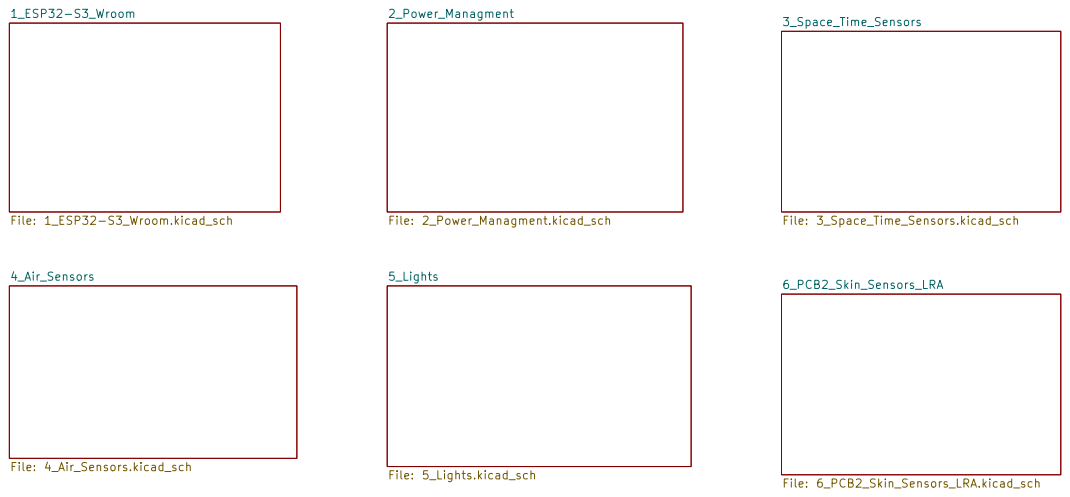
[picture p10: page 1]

Size: A4 | Rev: iv7.1
KiCad E.D.A. 10.0.3 | Id: 1/7

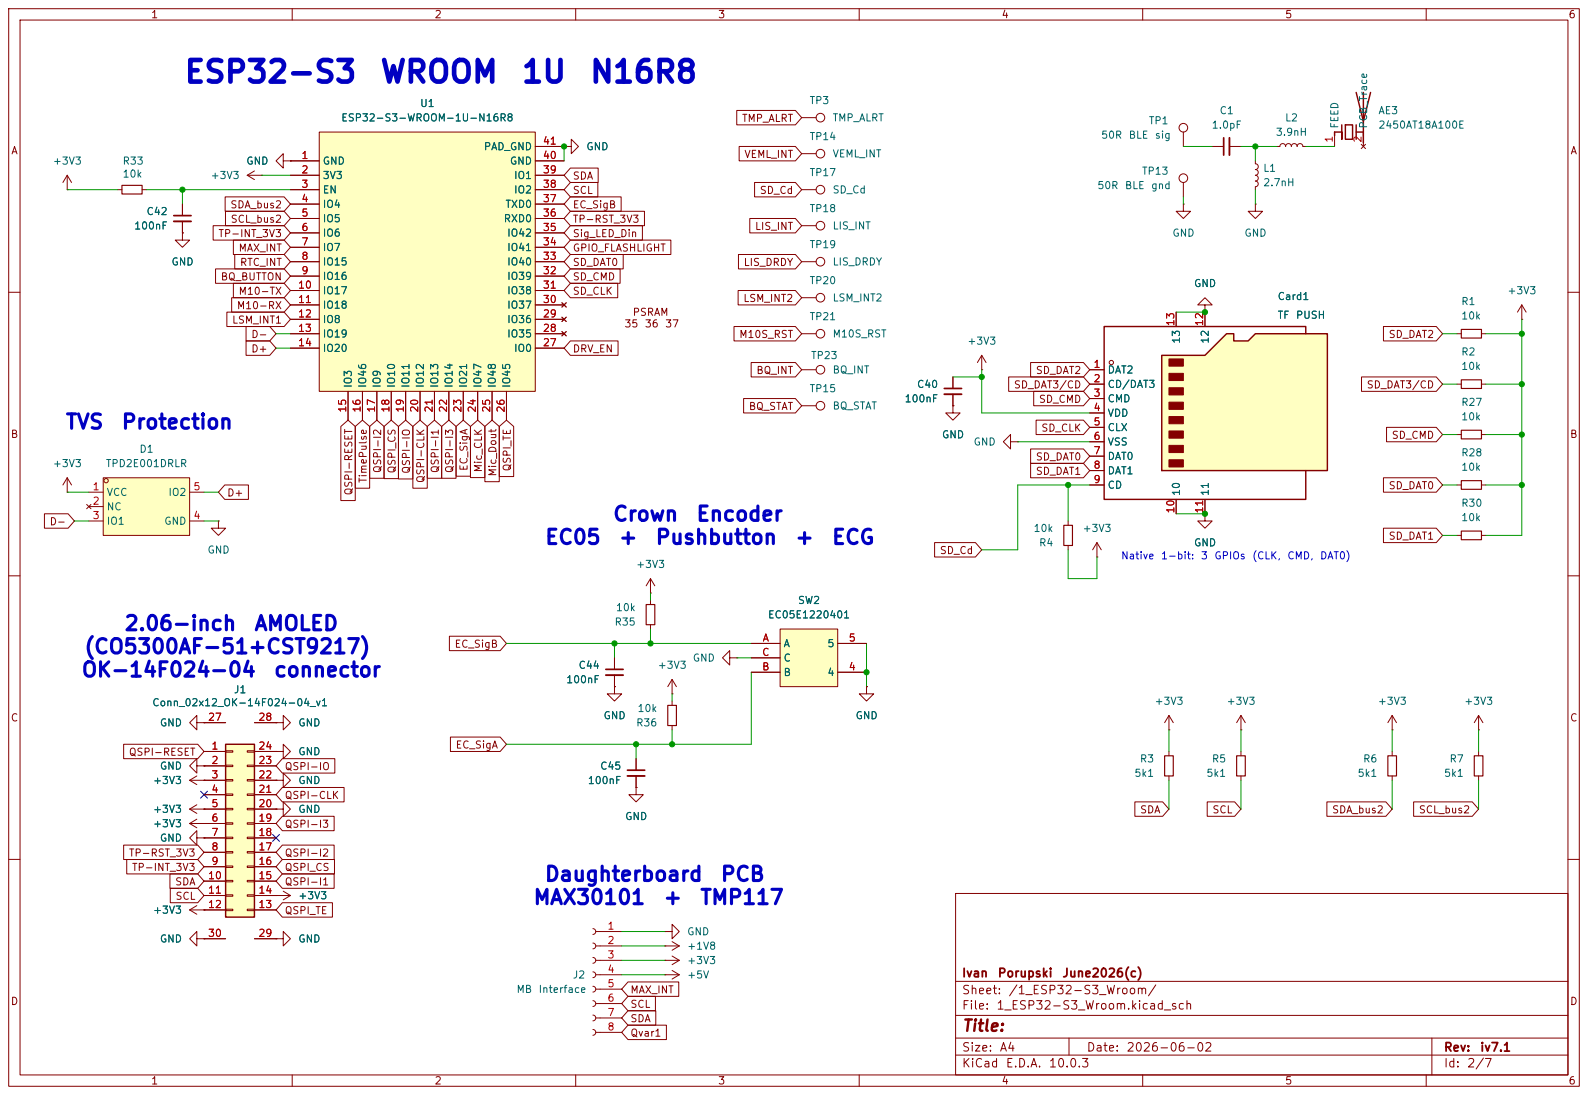
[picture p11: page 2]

Native 1-bit: 3 GPIOs (CLK, CMD, DAT0)

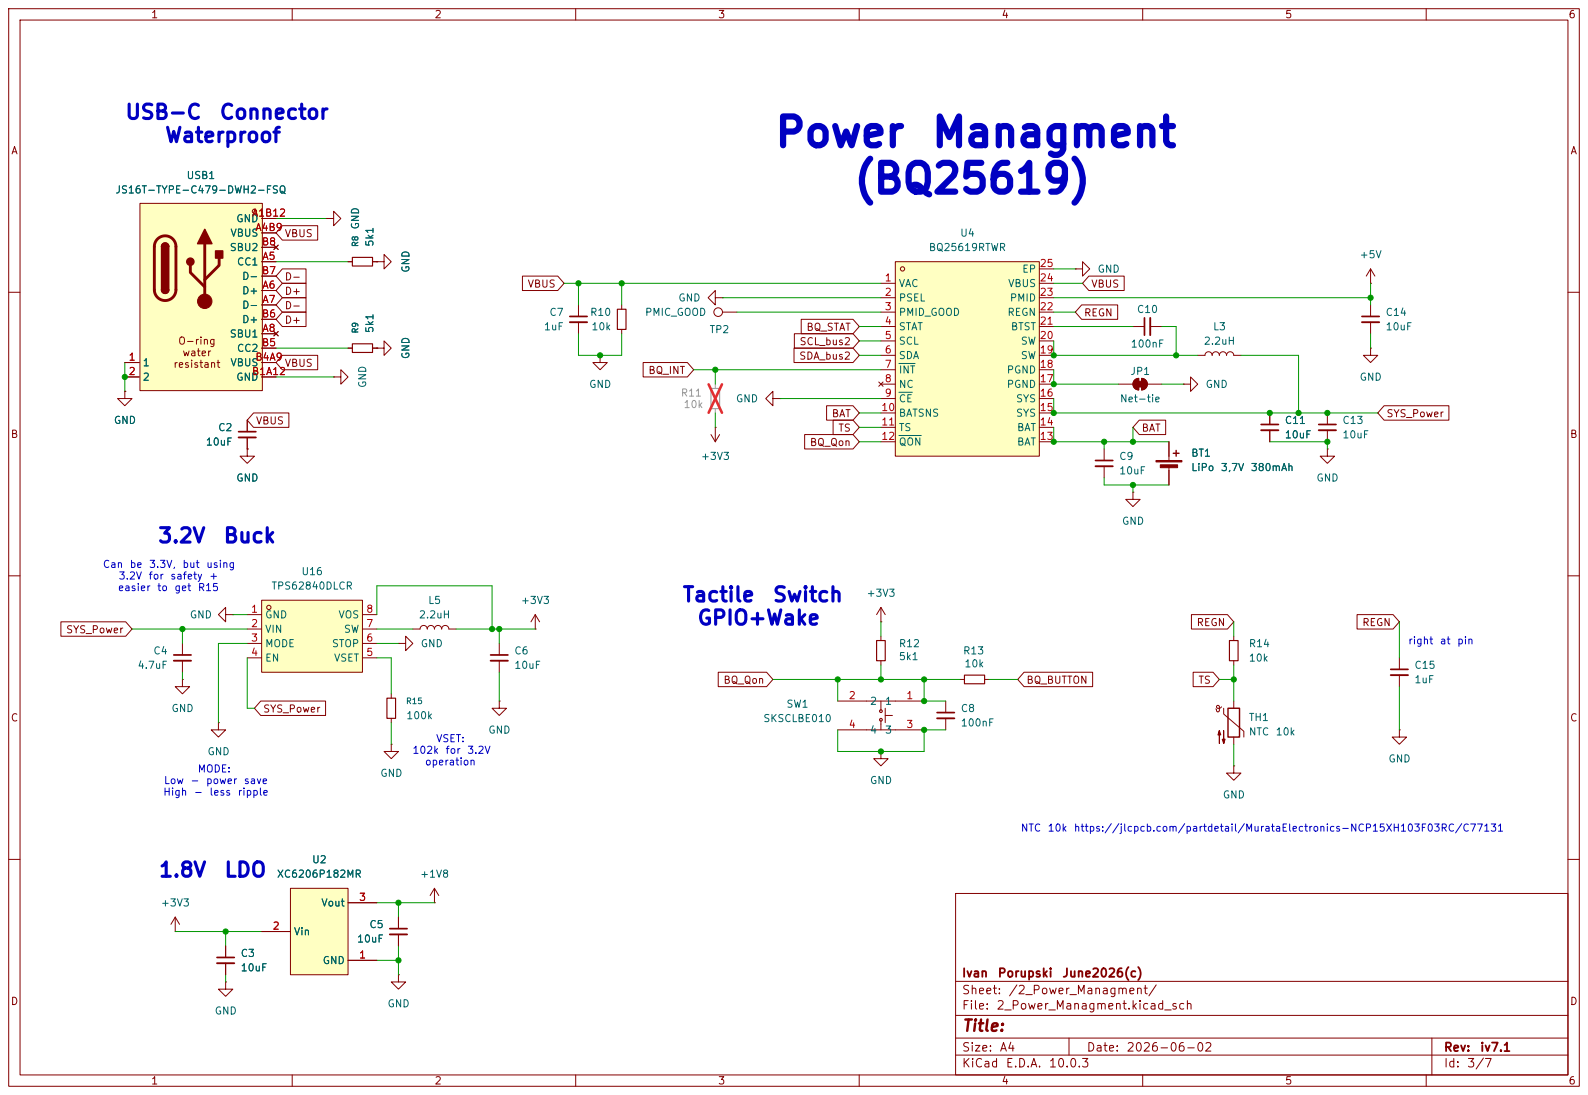
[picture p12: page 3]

Can be 3.3V, but using 3.2V for safety +
4.7uF GND +3V3

MODE: Low - power save High - less ripple

NTC 10k https://jlcpcb.com/partdetail/MurataElectronics-NCP15XH103F03RC/C77131

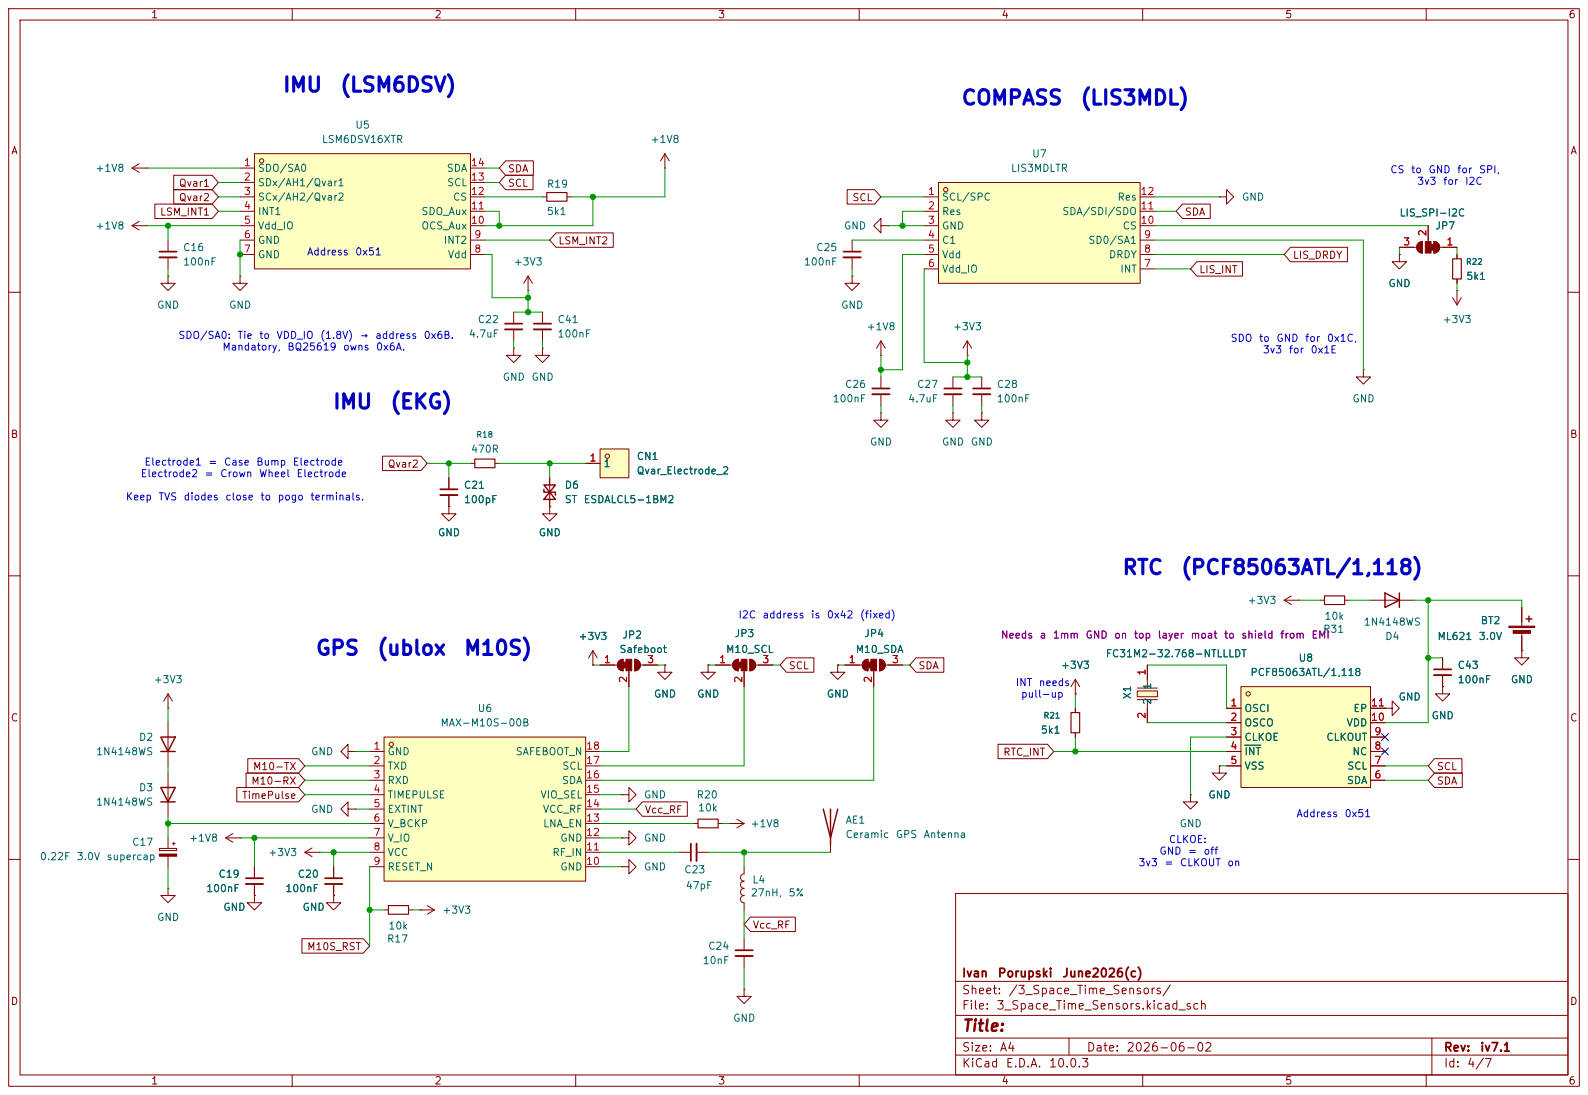
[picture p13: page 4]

CS to GND for SPI, 3v3 for I2C

FC31M2-32.768-NTLLLDT Needs a 1mm GND on top layer moat to shield from EMI C22

SDO to GND for 0x1C, 3v3 for 0x1E SDO/SA0: Tie to VDD_IO (1.8V) → address 0x6B. Mandatory, BQ25619 owns 0x6A. GPS (ublox M10S)

I2C address is 0x42 (fixed) Electrode1 = Case Bump Electrode Electrode2 = Crown Wheel Electrode Keep TVS diodes close to pogo terminals. IMU (EKG)
100nF GND

FC31M2-32.768-NTLLLDT Needs a 1mm GND on top layer moat to shield from EMI 1

INT needs pull-up

CLKOE: GND = off 3v3 = CLKOUT on

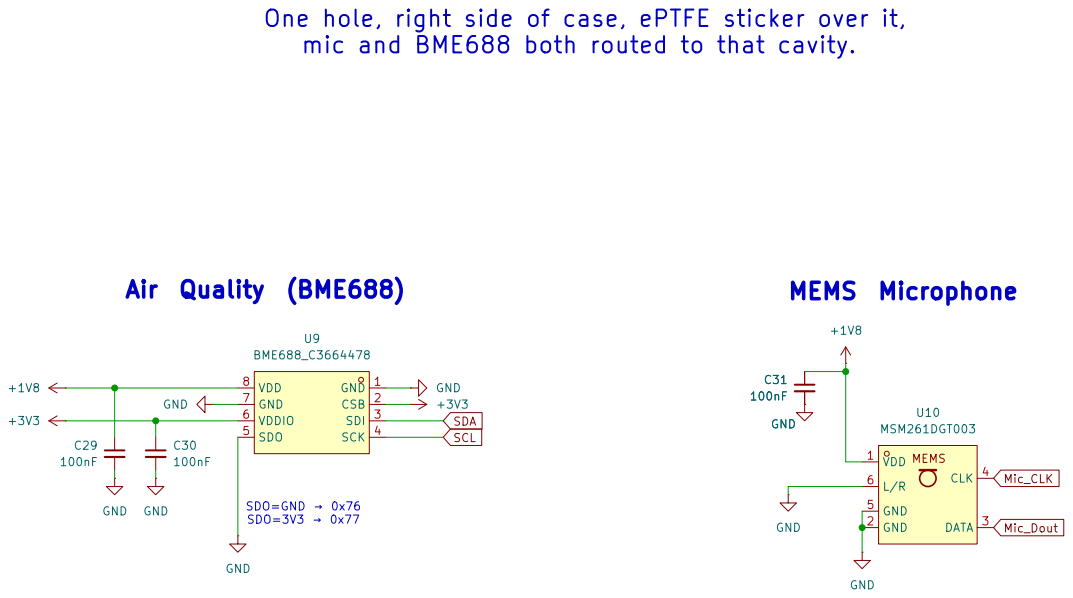
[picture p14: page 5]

SDO=3V3 → 0x77 One hole, right side of case, ePTFE sticker over it,
mic and BME688 both routed to that cavity.

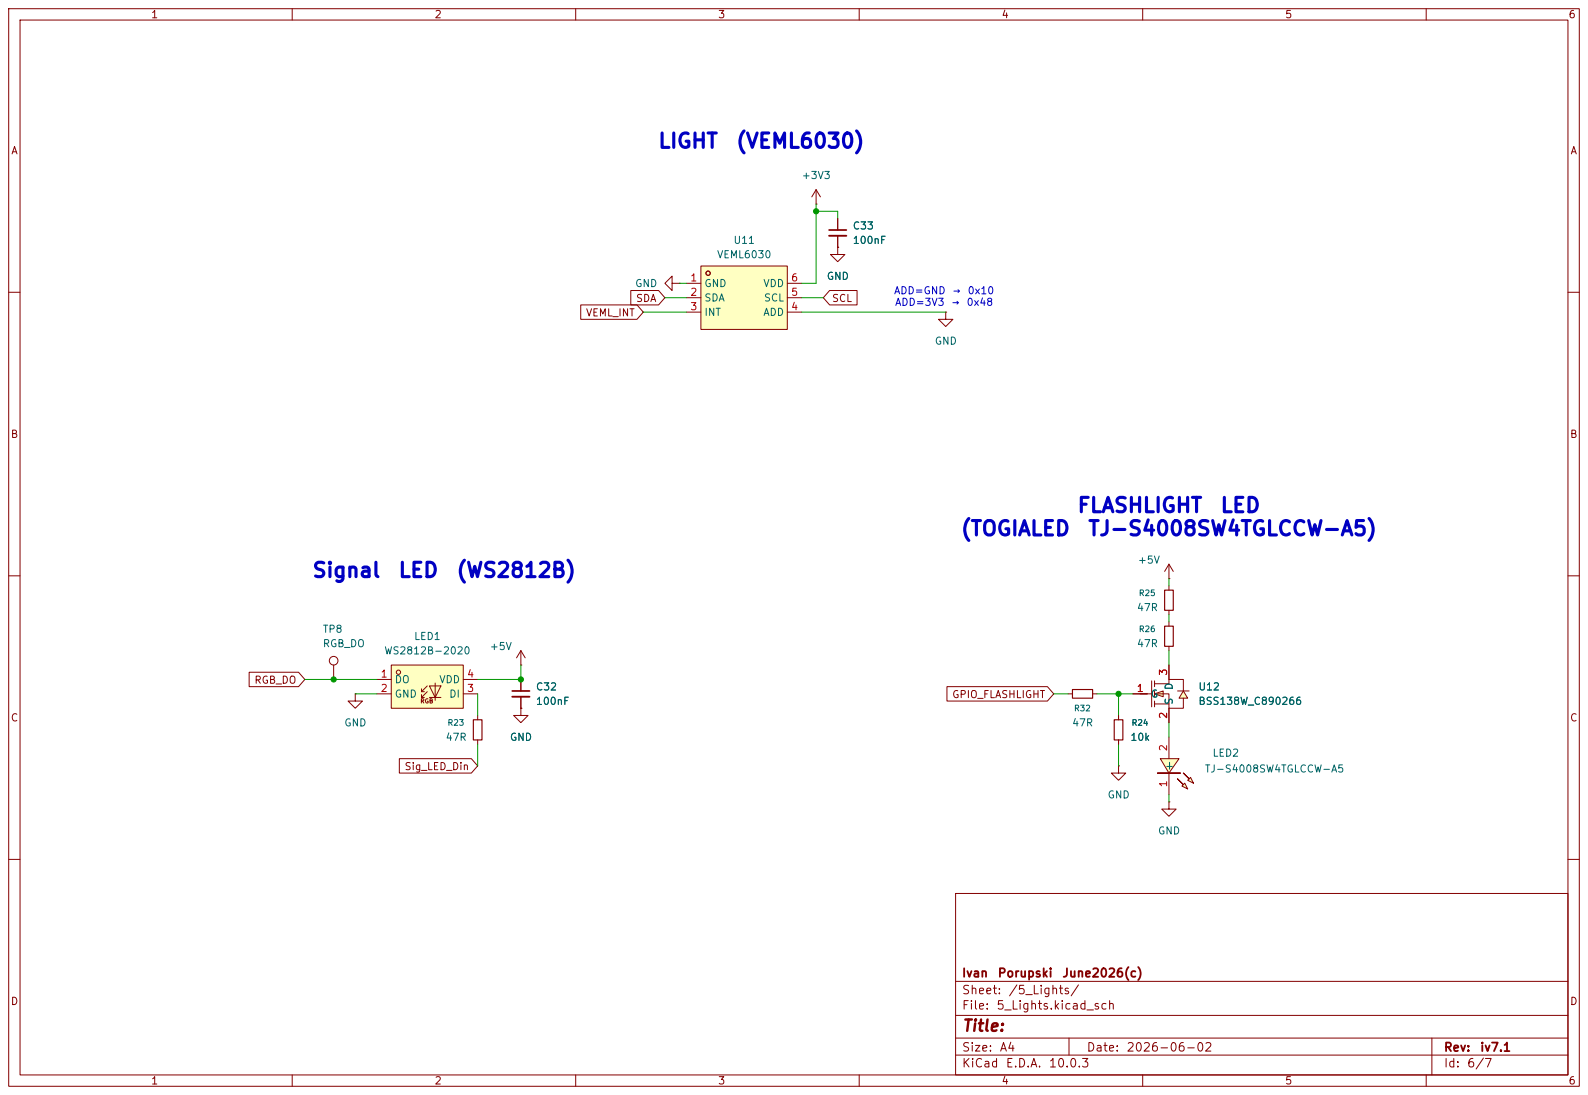
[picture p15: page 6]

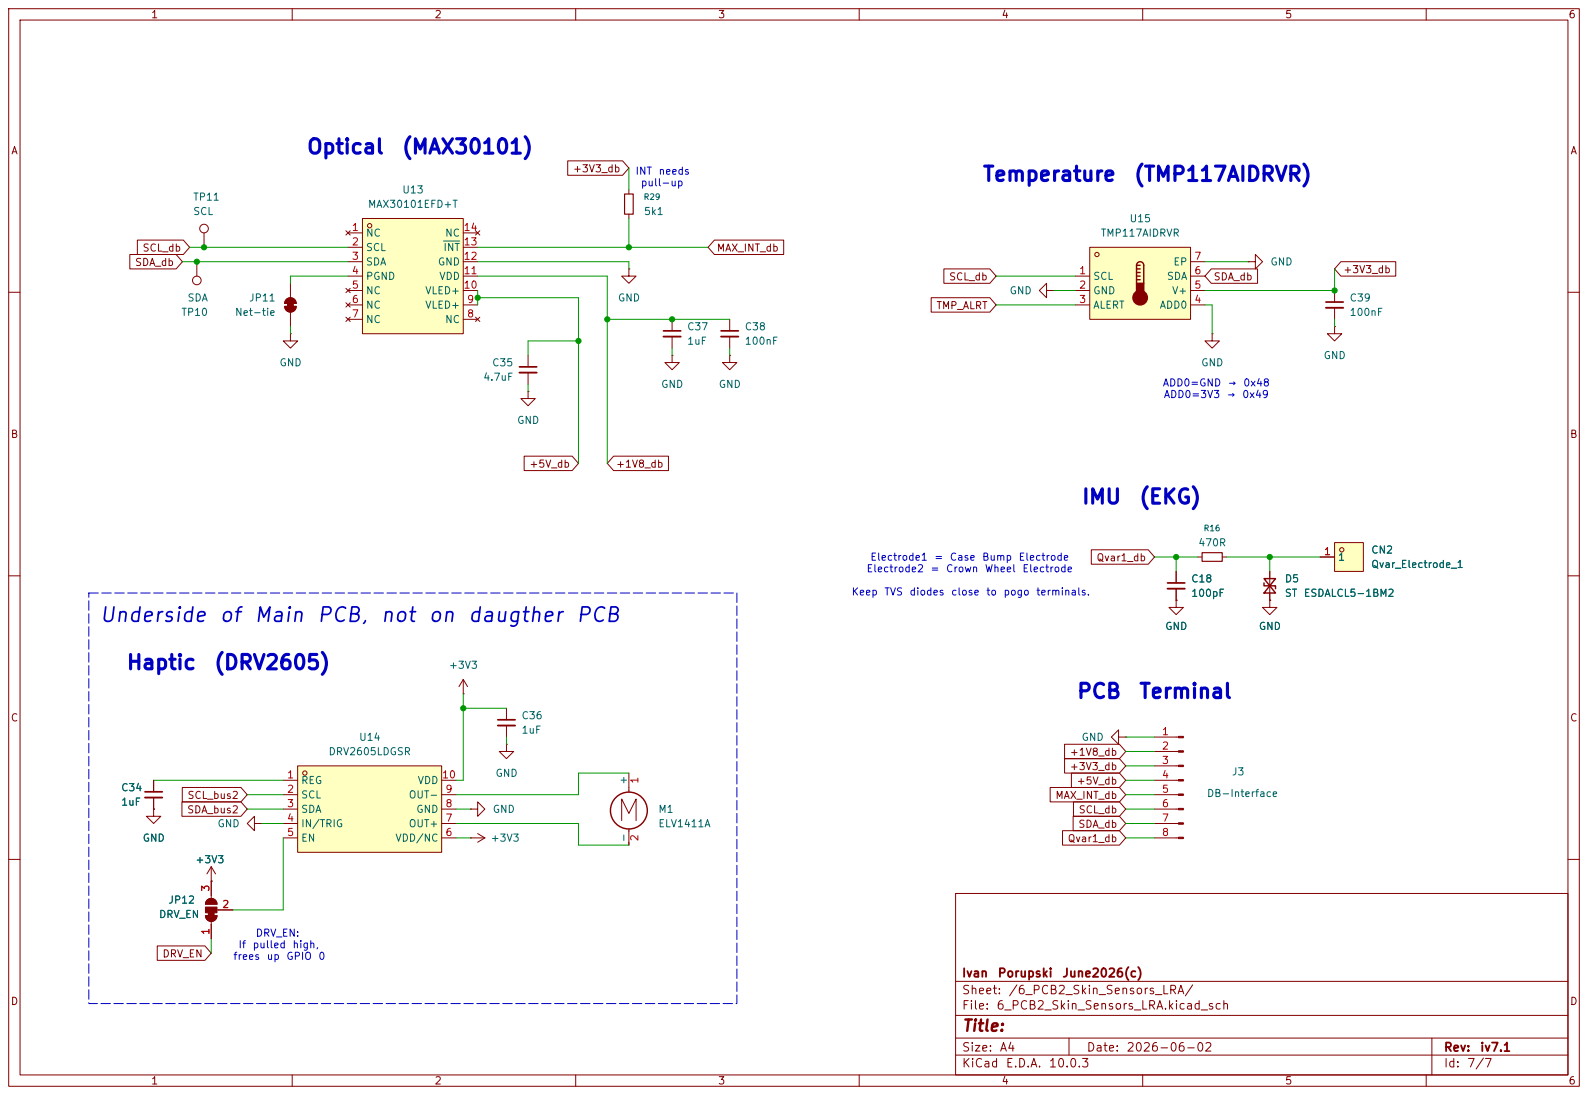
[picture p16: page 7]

INT needs pull-up

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

Underside of Main PCB, not on daugther PCB

If pulled high, frees up GPIO 0 GND

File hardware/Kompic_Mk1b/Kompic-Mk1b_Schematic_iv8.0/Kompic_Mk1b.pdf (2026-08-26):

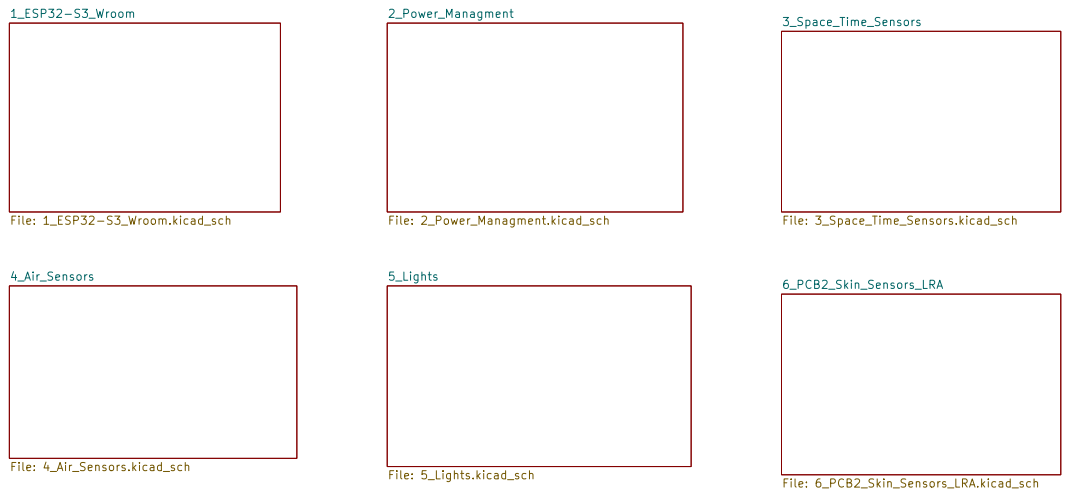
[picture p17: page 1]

Size: A4 | Rev: iv8.0
KiCad E.D.A. 10.0.5 | Id: 1/7

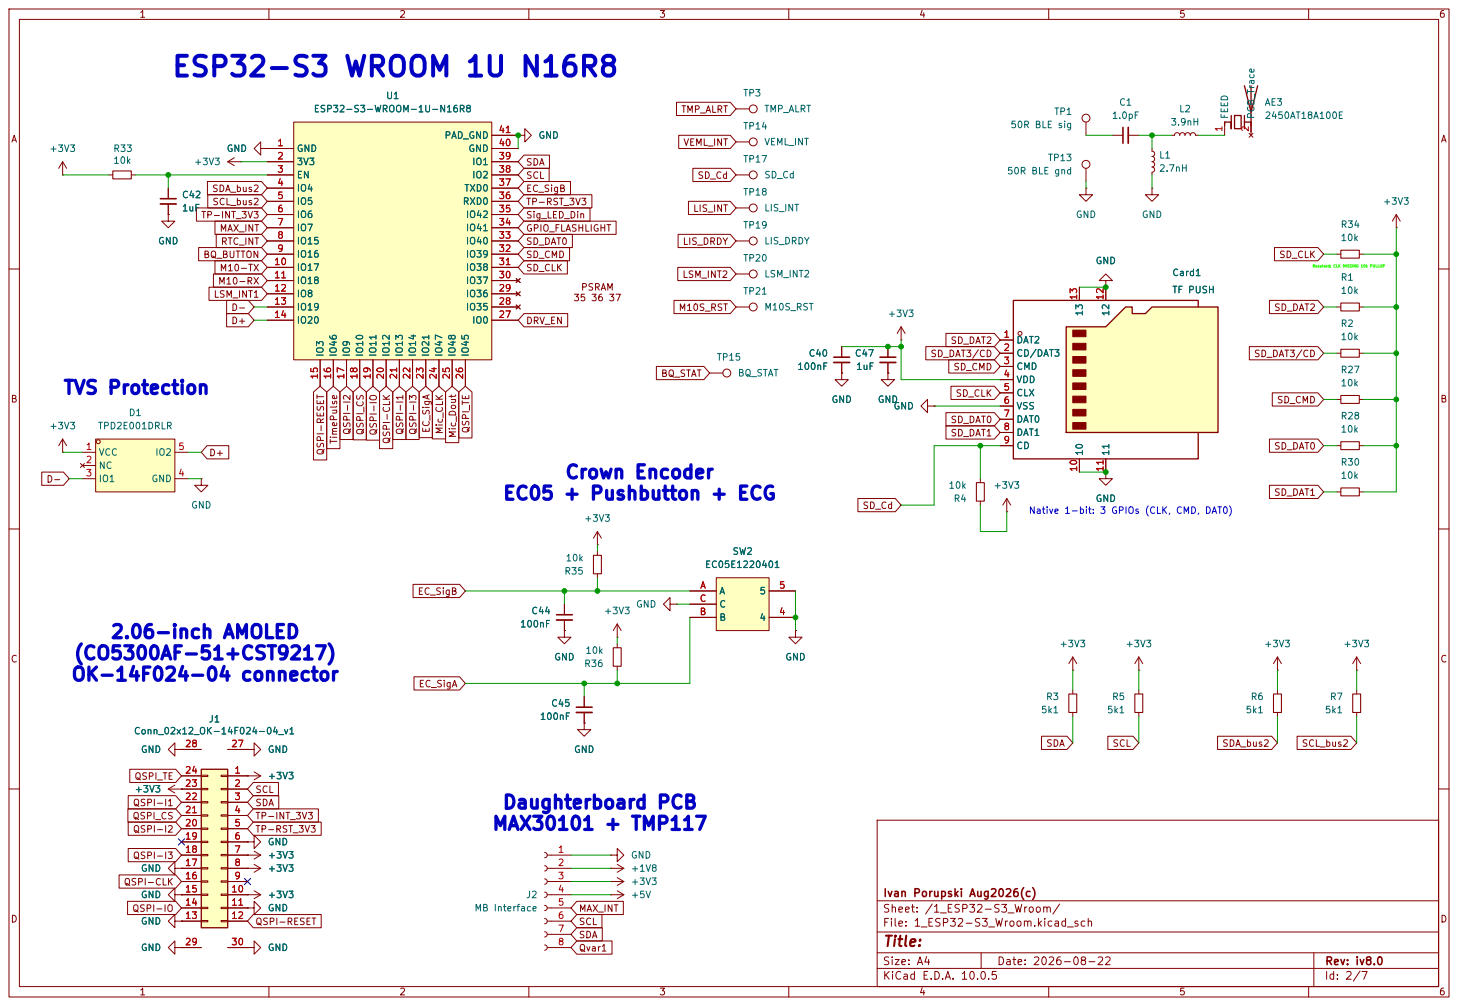
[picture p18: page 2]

Resolved: CLK MISSING 10k PULLUP 2.06-inch AMOLED

SD_DAT3/CD QSPI-I3 QSPI-CLK QSPI-IO
TVS Protection

Native 1-bit: 3 GPIOs (CLK, CMD, DAT0)

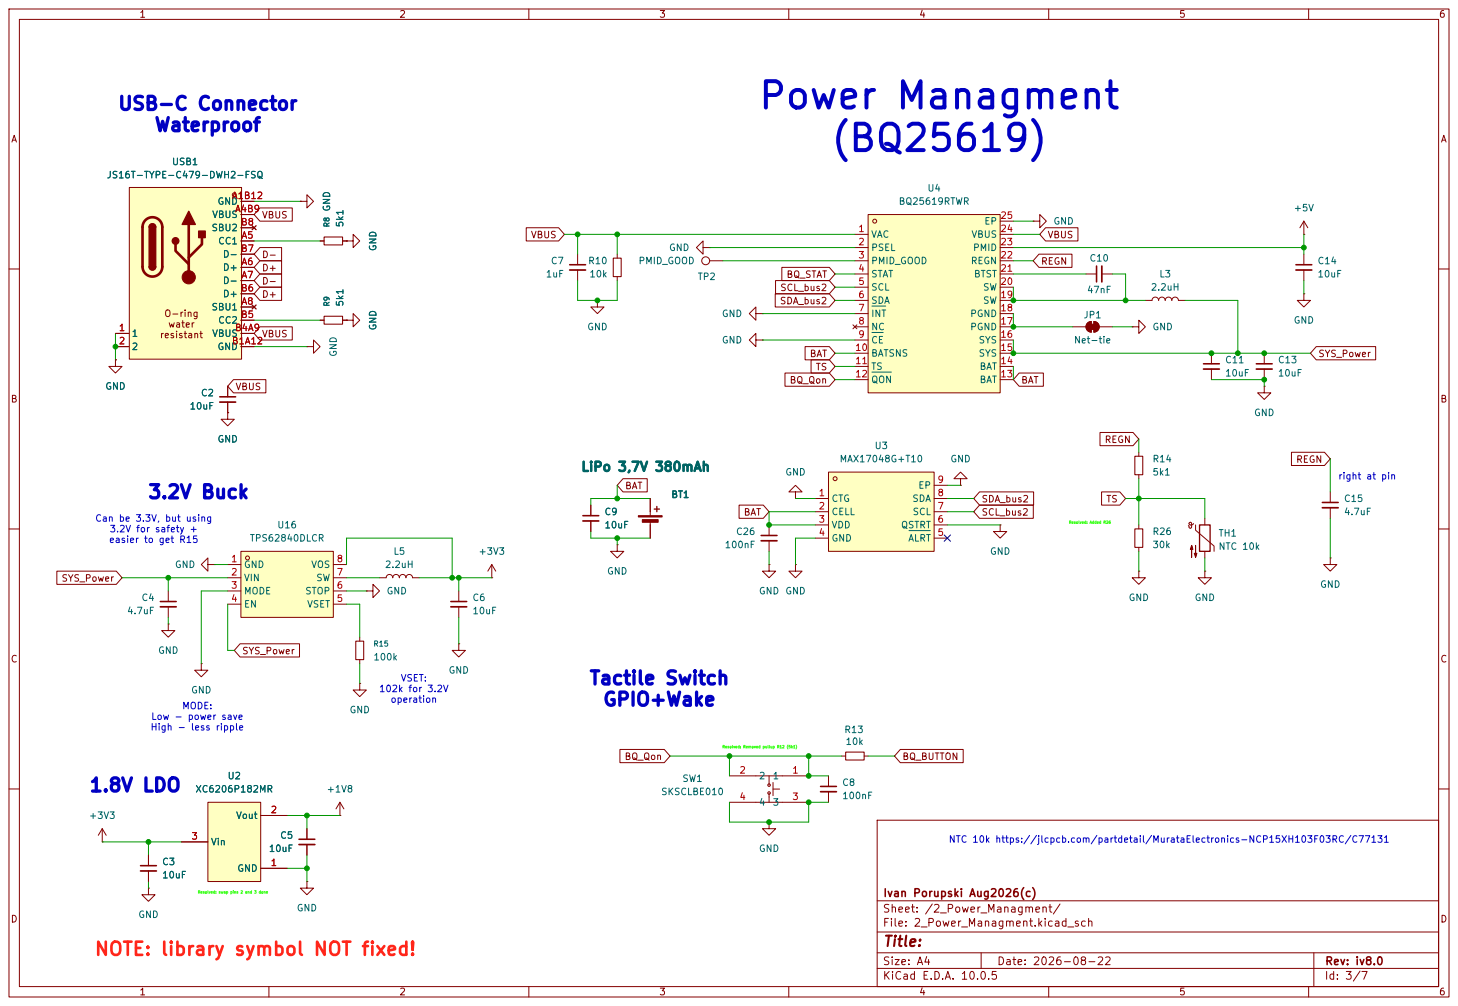
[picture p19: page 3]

easier to get R15 3.2V Buck

NTC 10k https://jlcpcb.com/partdetail/MurataElectronics-NCP15XH103F03RC/C77131

NOTE: library symbol NOT fixed!

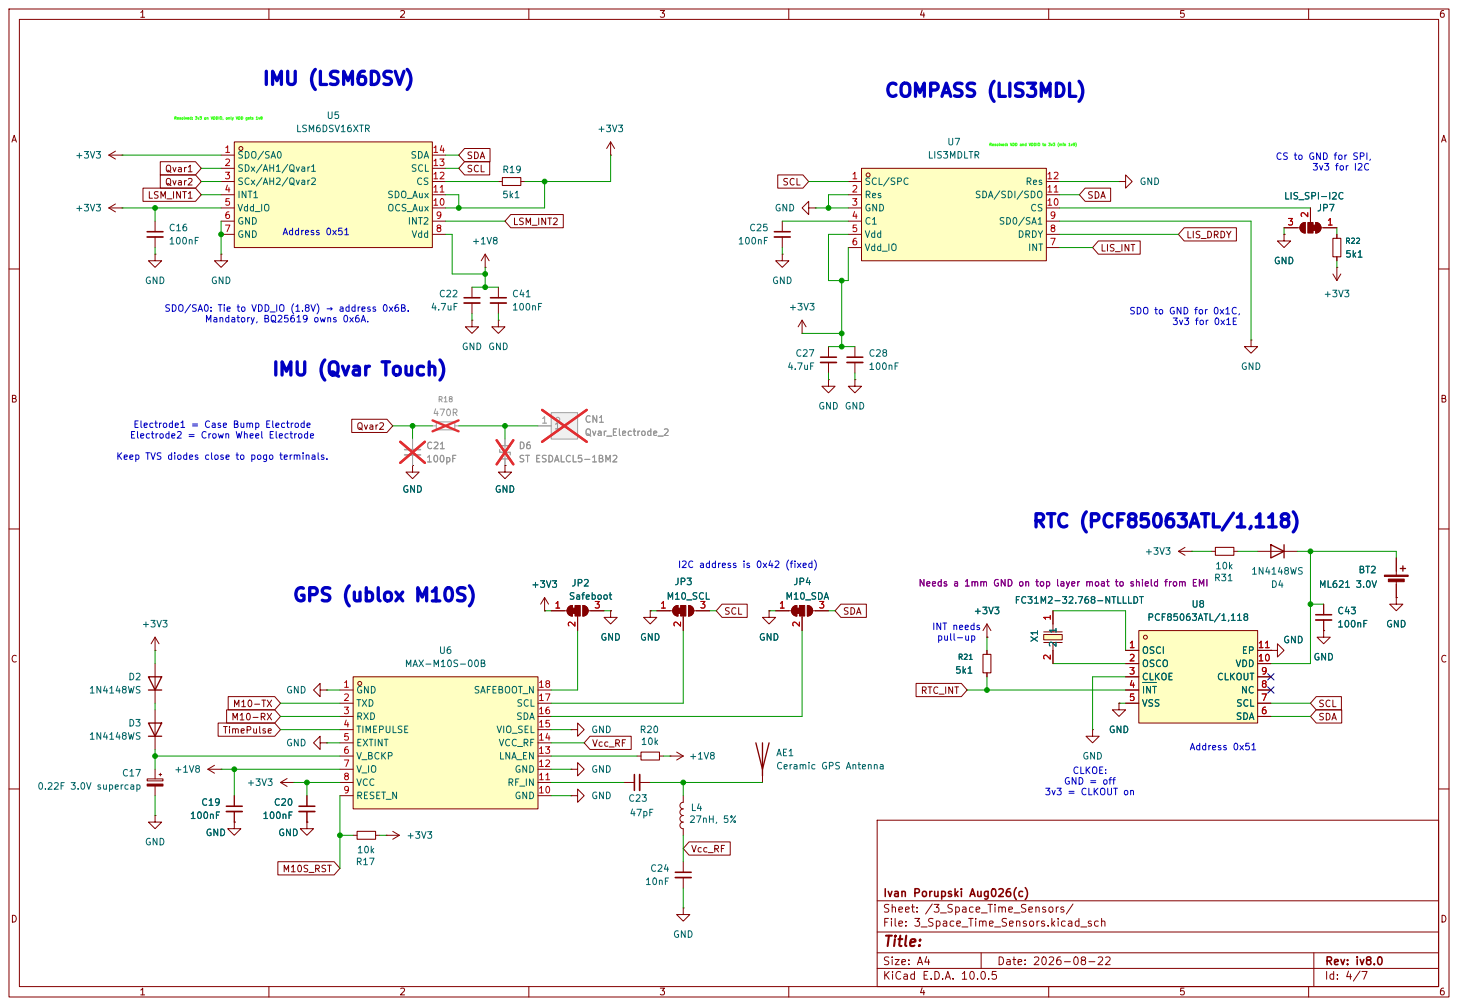
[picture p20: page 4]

SDO/SA0: Tie to VDD_IO (1.8V) → address 0x6B. Mandatory, BQ25619 owns 0x6A.

I2C address is 0x42 (fixed) Electrode1 = Case Bump Electrode Electrode2 = Crown Wheel Electrode Keep TVS diodes close to pogo terminals. IMU (Qvar Touch)

JP3 M10_SCL 1
FC31M2-32.768-NTLLLDT Needs a 1mm GND on top layer moat to shield from EMI GND

FC31M2-32.768-NTLLLDT Needs a 1mm GND on top layer moat to shield from EMI 1

INT needs pull-up

CLKOE: GND = off 3v3 = CLKOUT on

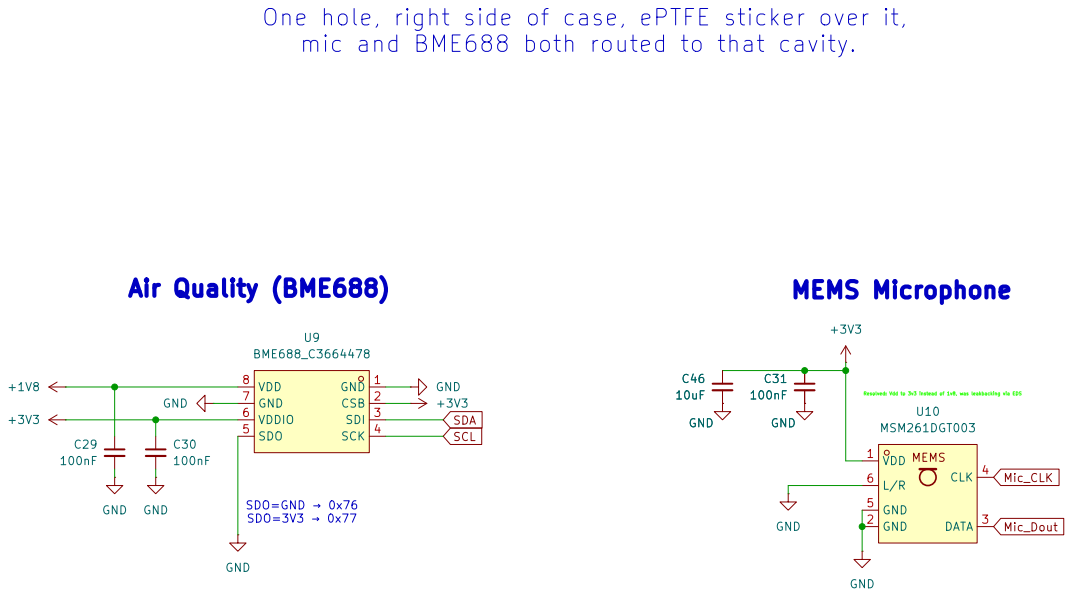
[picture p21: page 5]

One hole, right side of case, ePTFE sticker over it,
mic and BME688 both routed to that cavity.

Resolved: Vdd to 3v3 instead of 1v8, was leakbacking via EDS MEMS Microphone


NOTE: BSS138 batch is dead USE: BC847C as temp drop-in replacement. R32 then needs to be 3k instead of 47 with FET LIGHT (VEML6030)

Resolved: Moved LED above Drain C32


INT needs pull-up

Electrode1 = Case Bump Electrode Electrode2 = Crown Wheel Electrode Keep TVS diodes close to pogo terminals. Temperature (TMP117AIDRVR)

Underside of Main PCB, not on daugther PCB
Haptic (DRV2605)

DRV_EN:
If pulled high, frees up GPIO 0

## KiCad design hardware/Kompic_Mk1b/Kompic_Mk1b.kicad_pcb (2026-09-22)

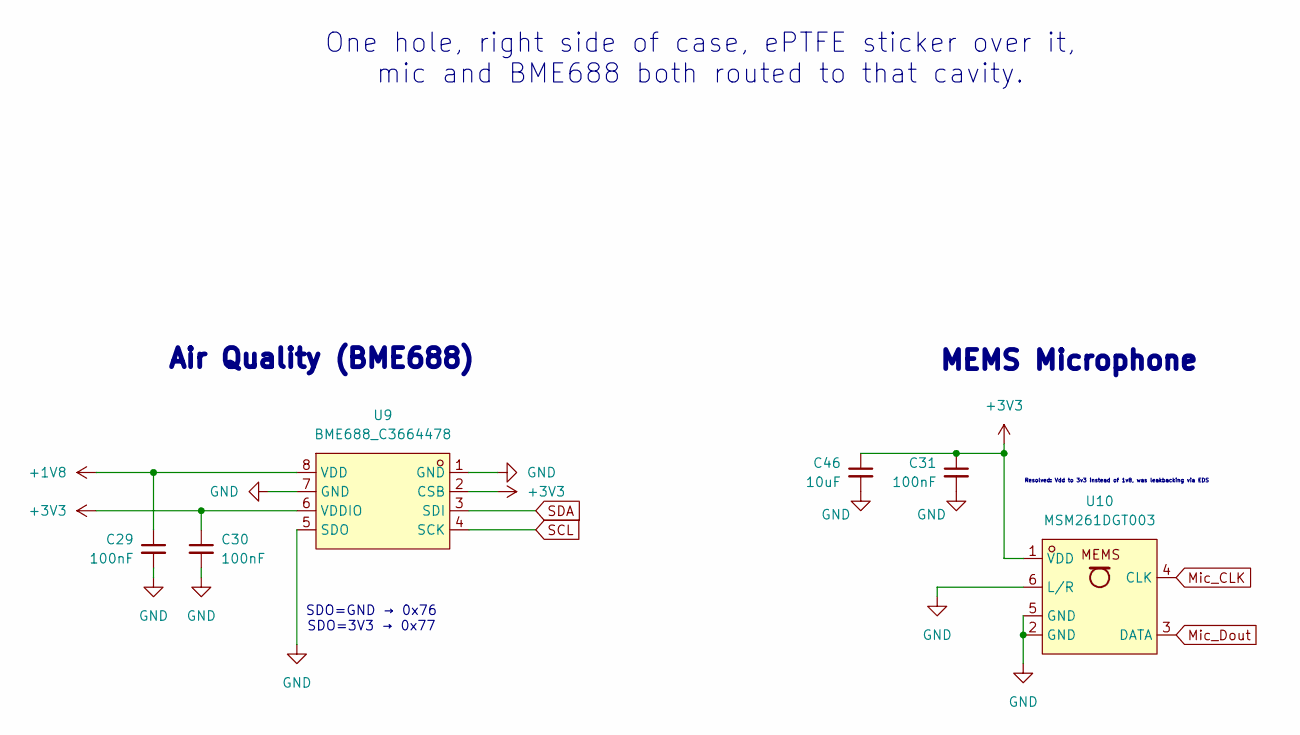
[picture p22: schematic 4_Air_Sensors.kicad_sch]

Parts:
C29, C30, C31: 100nF; C_0402_1005Metric_Pad0.74x0.62mm_HandSolder
C46: 10uF; C_0402_1005Metric_Pad0.74x0.62mm_HandSolder
U9: BME688_C3664478; LGA-8_L3.0-W3.0-P0.80_BME688; LCSC Part C3664478
U10: MSM261DGT003; MIC-SMD_6P-L4.0-W2.0_LMD4020T261-OC3; LCSC Part C48227730

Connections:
+1V8: C29.1, U9.8 (VDD); also elsewhere on the board
+3V3: C30.1, C31.1, C46.1, U9.2 (CSB), U9.6 (VDDIO), U10.1 (VDD); also elsewhere on the board
GND: C29.2, C30.2, C31.2, C46.2, U9.1 (GND), U9.5 (SDO), U9.7 (GND), U10.2 (GND), U10.5 (GND), U10.6 (L/R); also elsewhere on the board
Mic_CLK: U10.4 (CLK); also elsewhere on the board
Mic_Dout: U10.3 (DATA); also elsewhere on the board
SCL: U9.4 (SCK); also elsewhere on the board
SDA: U9.3 (SDI); also elsewhere on the board

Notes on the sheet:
Air Quality (BME688)
SDO=GND → 0x76 SDO=3V3 → 0x77
One hole, right side of case, ePTFE sticker over it, mic and BME688 both routed to that cavity.
MEMS Microphone
Resolved: Vdd to 3v3 instead of 1v8, was leakbacking via EDS

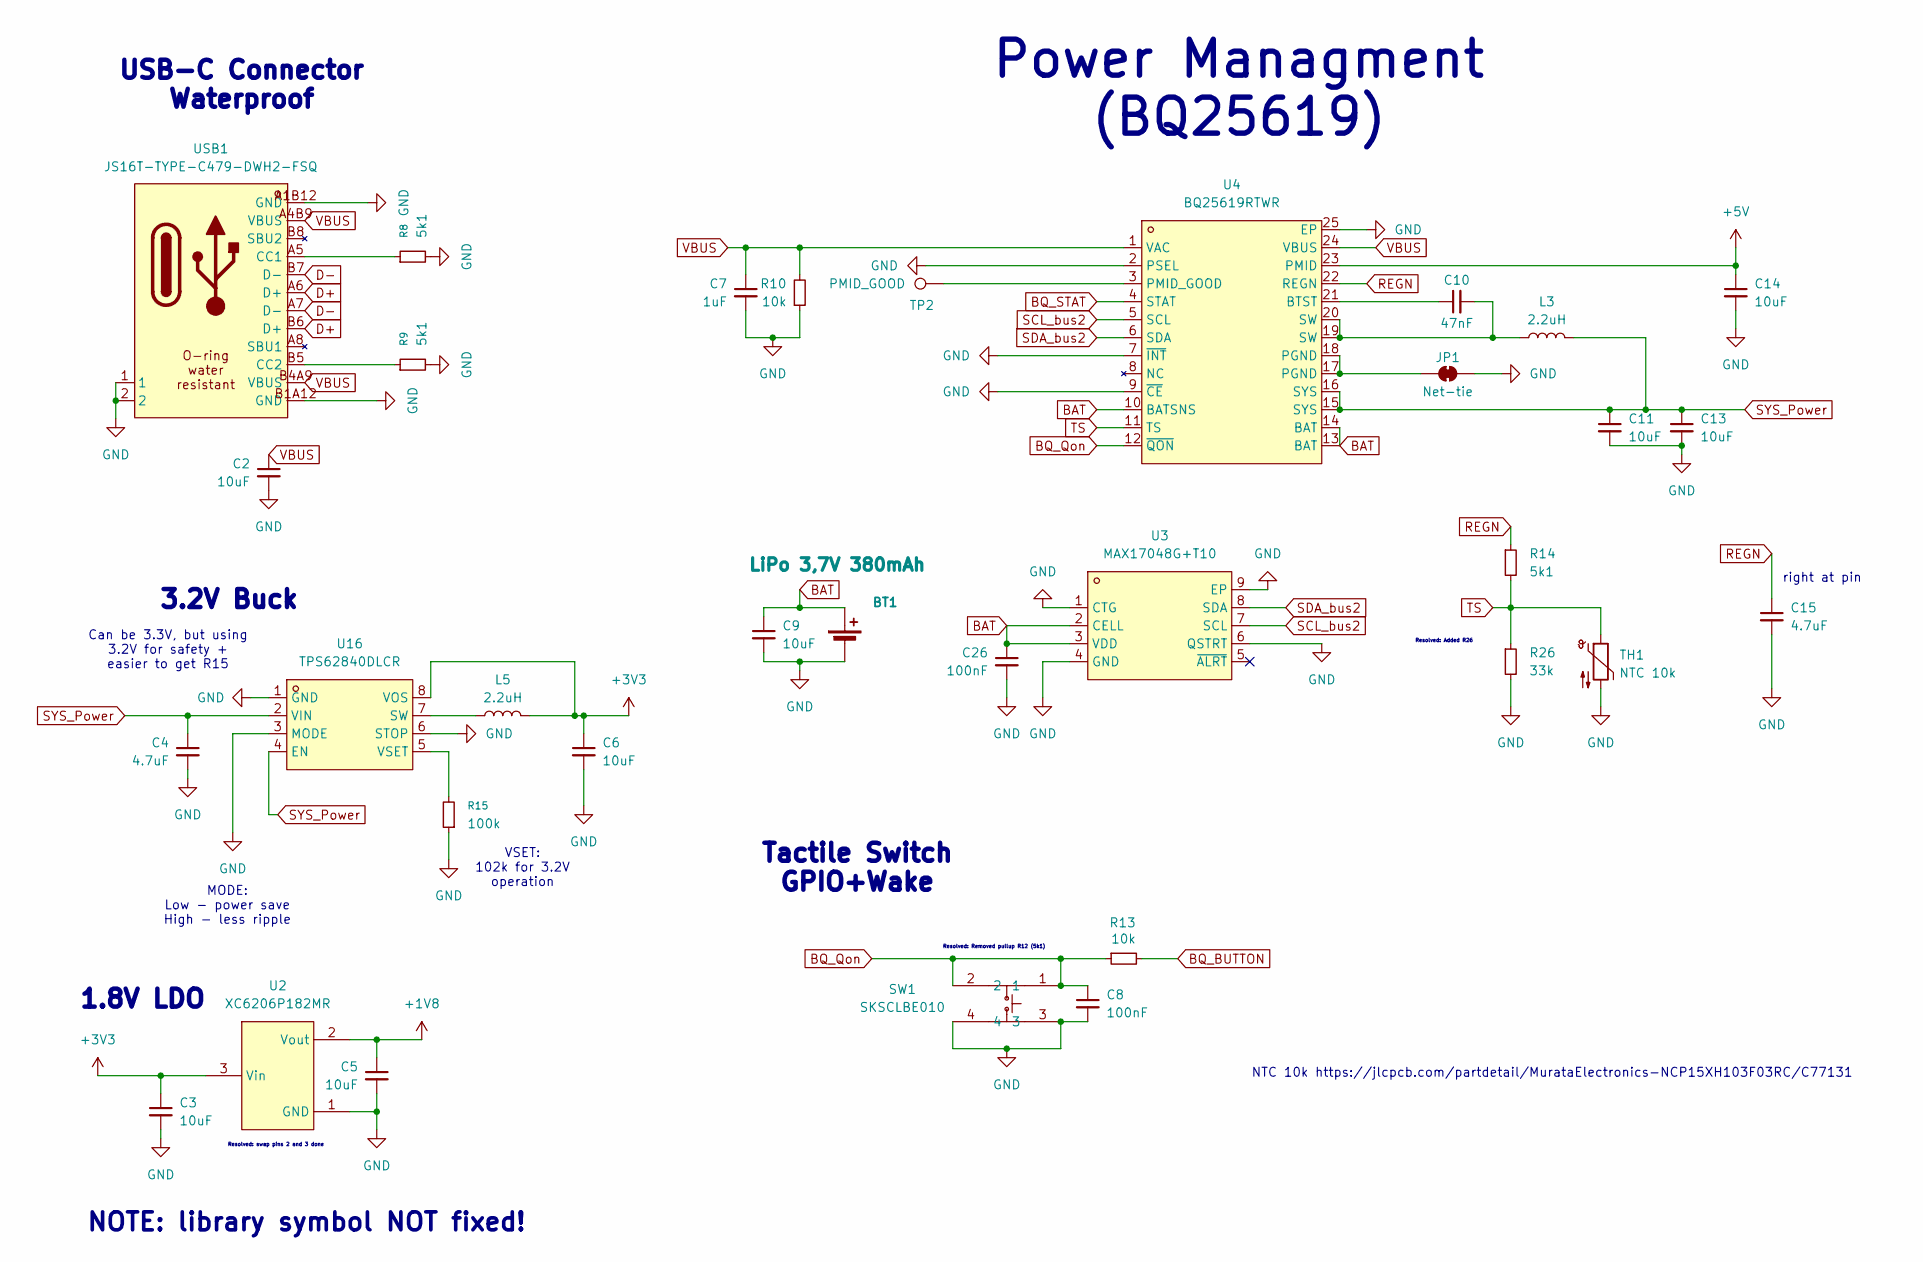
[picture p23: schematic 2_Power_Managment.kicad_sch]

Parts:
BT1: LiPo 3,7V 380mAh; Battery_solder_terminals_v1
C2, C3, C5, C6, C9, C11, C13, C14: 10uF; C_0402_1005Metric_Pad0.74x0.62mm_HandSolder
C4, C15: 4.7uF; C_0402_1005Metric_Pad0.74x0.62mm_HandSolder
C7: 1uF; C_0402_1005Metric_Pad0.74x0.62mm_HandSolder
C8, C26: 100nF; C_0402_1005Metric_Pad0.74x0.62mm_HandSolder
C10: 47nF; C_0603_1608Metric_Pad1.08x0.95mm_HandSolder
JP1: Net-tie; SolderJumper-2_P1.3mm_Bridged_RoundedPad1.0x1.5mm
L3, L5: 2.2uH; L_1008_2520Metric
R8, R9, R14: 5k1; R_0402_1005Metric_Pad0.72x0.64mm_HandSolder
R10, R13: 10k; R_0402_1005Metric_Pad0.72x0.64mm_HandSolder
R15: 100k; R_0402_1005Metric_Pad0.72x0.64mm_HandSolder
R26: 33k; R_0402_1005Metric_Pad0.72x0.64mm_HandSolder
SW1: SKSCLBE010; KEY-SMD_4P-SKSCLXX010; LCSC Part C115361
TH1: NTC 10k; R_0402_1005Metric_Pad0.72x0.64mm_HandSolder
TP2: PMID_GOOD; TestPoint_Pad_D1.0mm
U2: XC6206P182MR; SOT-23-3_L2.9-W1.6-P1.90-LS2.8-BR; LCSC Part C21659
U3: MAX17048G+T10; TDFN-8_L2.0-W2.0-P0.50-BL-EP1.2; MPN MAX17048G+T10; LCSC Part C2682616
U4: BQ25619RTWR; WQFN-24_L4.0-W4.0-P0.50-TL-EP2.7; LCSC Part C2864534
U16: TPS62840DLCR; VSON-8_L2.0-W1.5-P0.50-BL; LCSC Part C2071859
USB1: JS16T-TYPE-C479-DWH2-FSQ; USB-C-SMD_JS16T-TYPE-C479-DWH2-FSQ; LCSC Part C49118447

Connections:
+1V8: C5.1, U2.2 (Vout); also elsewhere on the board
+3V3: C3.1, C6.1, L5.2, U2.3 (Vin), U16.8 (VOS); also elsewhere on the board
+5V: C14.1, U4.23 (PMID); also elsewhere on the board
BAT: BT1.1 (+), C9.1, C26.1, U3.2 (CELL), U3.3 (VDD), U4.10 (BATSNS), U4.13 (BAT), U4.14 (BAT)
BQ_BUTTON: R13.2; also elsewhere on the board
BQ_Qon: C8.1, R13.1, SW1.1, SW1.2, U4.12 (~QON)
BQ_STAT: U4.4 (STAT); also elsewhere on the board
D+: USB1.A6 (D+), USB1.B6 (D+); also elsewhere on the board
D-: USB1.A7 (D-), USB1.B7 (D-); also elsewhere on the board
GND: BT1.2 (-), C2.2, C3.2, C4.2, C5.2, C6.2, C7.2, C8.2, C9.2, C11.2, C13.2, C14.2, C15.2, C26.2, JP1.2 (B), R8.2, R9.2, R10.1, R15.1, R26.2, SW1.3, SW1.4, TH1.2, U2.1 (GND), U3.1 (CTG), U3.4 (GND), U3.6 (QSTRT), U3.9 (EP), U4.2 (PSEL), U4.7 (~INT), U4.9 (~CE), U4.25 (EP), U16.1 (GND), U16.3 (MODE), U16.6 (STOP), USB1.1, USB1.2, USB1.A1B12 (GND), USB1.B1A12 (GND); also elsewhere on the board
unnamed: C10.2, L3.1, U4.19 (SW), U4.20 (SW)
unnamed: JP1.1 (A), U4.17 (PGND), U4.18 (PGND)
unnamed: C10.1, U4.21 (BTST)
unnamed: TP2.1 (1_1), U4.3 (PMID_GOOD)
unnamed: L5.1, U16.7 (SW)
unnamed: R15.2, U16.5 (VSET)
unnamed: R8.1, USB1.A5 (CC1)
unnamed: R9.1, USB1.B5 (CC2)
REGN: C15.1, R14.1, U4.22 (REGN)
SCL_bus2: U3.7 (SCL), U4.5 (SCL); also elsewhere on the board
SDA_bus2: U3.8 (SDA), U4.6 (SDA); also elsewhere on the board
SYS_Power: C4.1, C11.1, C13.1, L3.2, U4.15 (SYS), U4.16 (SYS), U16.2 (VIN), U16.4 (EN)
TS: R14.2, R26.1, TH1.1, U4.11 (TS)
VBUS: C2.1, C7.1, R10.2, U4.1 (VAC), U4.24 (VBUS), USB1.A4B9 (VBUS), USB1.B4A9 (VBUS)

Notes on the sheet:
right at pin
Tactile Switch GPIO+Wake
3.2V Buck
Resolved: swap pins 2 and 3 done
Power Managment (BQ25619)
NTC 10k https://jlcpcb.com/partdetail/MurataElectronics-NCP15XH103F03RC/C77131
NOTE: library symbol NOT fixed!
USB-C Connector Waterproof
Resolved: Removed pullup R12 (5k1)
VSET: 102k for 3.2V operation
MODE: Low - power save High - less ripple
Can be 3.3V, but using 3.2V for safety + easier to get R15
Resolved: Added R26
1.8V LDO

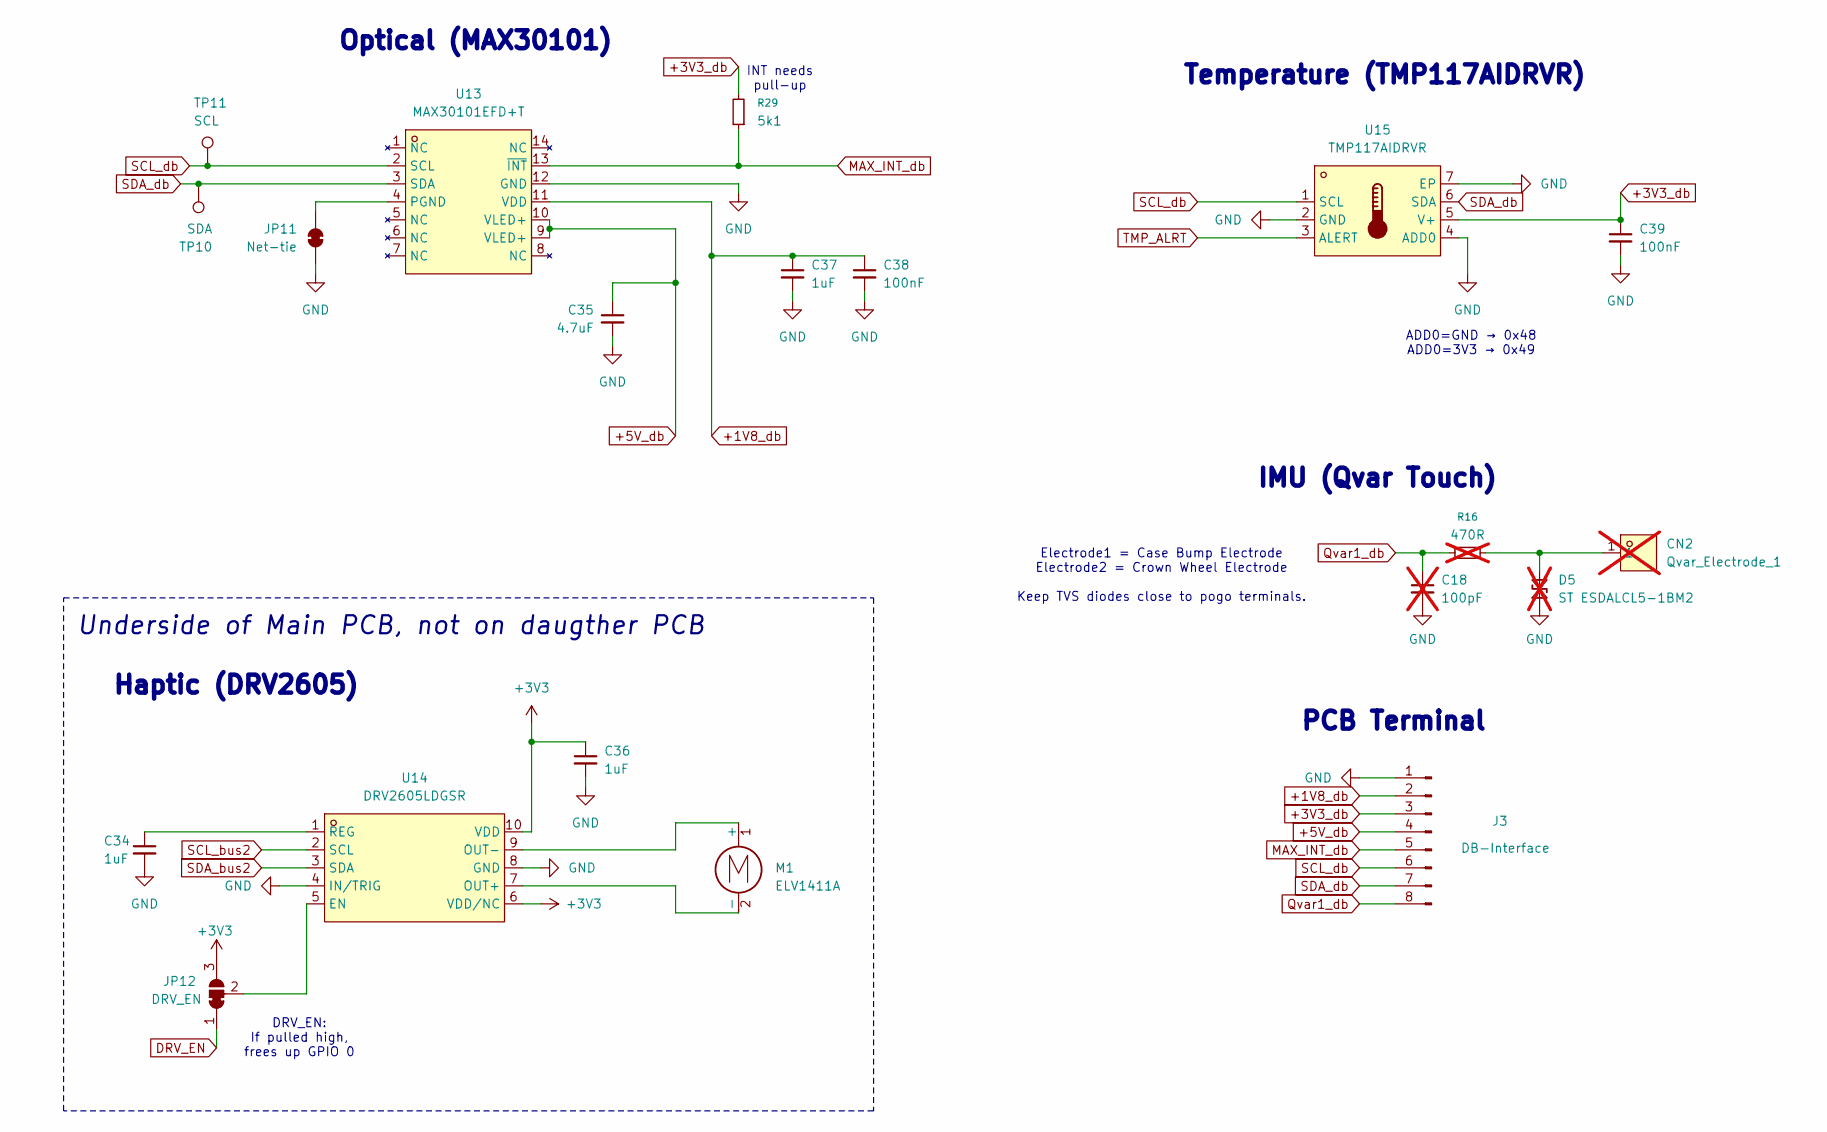
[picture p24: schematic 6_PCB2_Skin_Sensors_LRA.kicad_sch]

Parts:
C18: 100pF; C_0402_1005Metric_Pad0.74x0.62mm_HandSolder; not fitted
C34, C36, C37: 1uF; C_0402_1005Metric_Pad0.74x0.62mm_HandSolder
C35: 4.7uF; C_0402_1005Metric_Pad0.74x0.62mm_HandSolder
C38, C39: 100nF; C_0402_1005Metric_Pad0.74x0.62mm_HandSolder
CN2: Qvar_Electrode_1; TestPoint_Pad_D3.0mm; MPN YZR0028-15020-01; LCSC Part C7429439; not fitted
D5: ST ESDALCL5-1BM2; D_SOD-882; not fitted
J3: DB-Interface; Custom_8_pin_for_SmartWatch_v4-DB-semicircle
JP11: Net-tie; SolderJumper-2_P1.3mm_Bridged_RoundedPad1.0x1.5mm
JP12: DRV_EN; SolderJumper-3_P1.3mm_Bridged2Bar12_RoundedPad1.0x1.5mm
M1: ELV1411A; Battery_solder_terminals_v1
R16: 470R; R_0402_1005Metric_Pad0.72x0.64mm_HandSolder; not fitted
R29: 5k1; R_0402_1005Metric_Pad0.72x0.64mm_HandSolder
TP10: SDA; TestPoint_Pad_1.0x1.0mm
TP11: SCL; TestPoint_Pad_1.0x1.0mm
U13: MAX30101EFD+T; OESIP-14_L5.6-W3.3-P0.80-TL; LCSC Part C2859066
U14: DRV2605LDGSR; VSSOP-10_L3.0-W3.0-P0.50-LS4.9-BL; LCSC Part C527464
U15: TMP117AIDRVR; WSON-6_L2.0-W2.0-P0.65-TL-EP; LCSC Part C699536

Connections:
+1V8_db: C37.1, C38.1, J3.2, U13.11 (VDD)
+3V3: C36.1, JP12.3 (B), U14.6 (VDD/NC), U14.10 (VDD); also elsewhere on the board
+3V3_db: C39.1, J3.3, R29.2, U15.5 (V+)
+5V_db: C35.1, J3.4, U13.9 (VLED+), U13.10 (VLED+)
DRV_EN: JP12.1 (A); also elsewhere on the board
GND: C18.2, C34.2, C35.2, C36.2, C37.2, C38.2, C39.2, D5.1 (A1), J3.1, JP11.1 (A), U13.12 (GND), U14.4 (IN/TRIG), U14.8 (GND), U15.2 (GND), U15.4 (ADD0), U15.7 (EP); also elsewhere on the board
MAX_INT_db: J3.5, R29.1, U13.13 (~INT)
unnamed: CN2.1 (1_1), D5.2 (A2), R16.2
unnamed: JP11.2 (B), U13.4 (PGND)
unnamed: JP12.2 (C), U14.5 (EN)
unnamed: M1.1 (+), U14.9 (OUT-)
unnamed: M1.2 (-), U14.7 (OUT+)
unnamed: C34.1, U14.1 (REG)
Qvar1_db: C18.1, J3.8, R16.1
SCL_bus2: U14.2 (SCL); also elsewhere on the board
SCL_db: J3.6, TP11.1 (1_1), U13.2 (SCL), U15.1 (SCL)
SDA_bus2: U14.3 (SDA); also elsewhere on the board
SDA_db: J3.7, TP10.1 (1_1), U13.3 (SDA), U15.6 (SDA)
TMP_ALRT: U15.3 (ALERT); also elsewhere on the board

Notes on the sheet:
Underside of Main PCB, not on daugther PCB
IMU (Qvar Touch)
INT needs pull-up
PCB Terminal
Haptic (DRV2605)
Electrode1 = Case Bump Electrode Electrode2 = Crown Wheel Electrode Keep TVS diodes close to pogo terminals.
Optical (MAX30101)
DRV_EN: If pulled high, frees up GPIO 0
ADD0=GND → 0x48 ADD0=3V3 → 0x49
Temperature (TMP117AIDRVR)

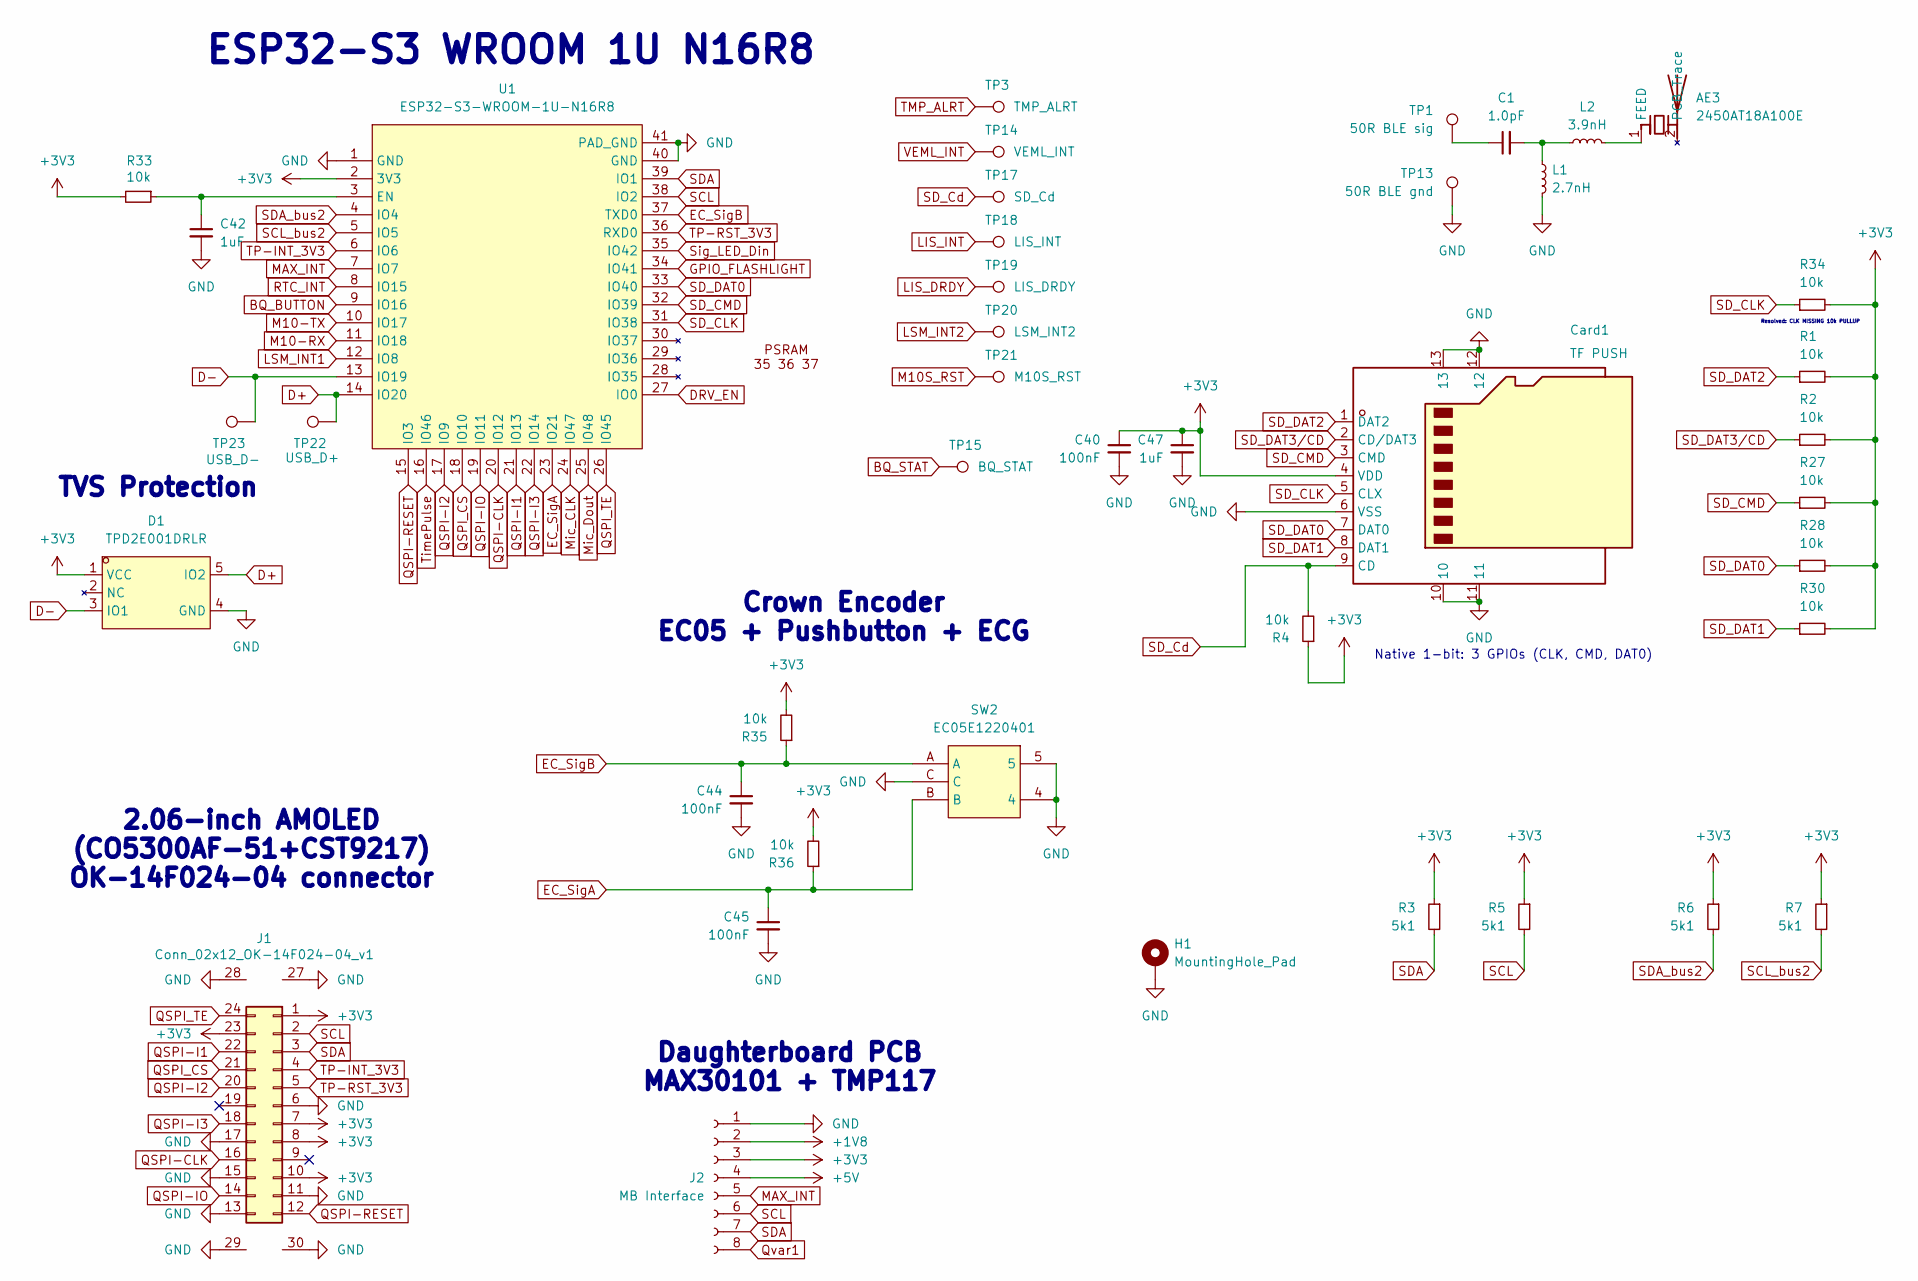
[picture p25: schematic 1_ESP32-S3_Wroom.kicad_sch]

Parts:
AE3: 2450AT18A100E; ANT-SMD_L3.2-W1.6; LCSC Part C89334
C1: 1.0pF; C_0402_1005Metric_Pad0.74x0.62mm_HandSolder
C40, C44, C45: 100nF; C_0402_1005Metric_Pad0.74x0.62mm_HandSolder
C42, C47: 1uF; C_0402_1005Metric_Pad0.74x0.62mm_HandSolder
Card1: TF PUSH; TF-SMD_TF-PUSH; LCSC Part C393941
D1: TPD2E001DRLR; SOT-553-5_L1.6-W1.2-P0.50-LS1.6-BR; LCSC Part C150526
H1: MountingHole_Pad; MountingHole_2.2mm_M2_DIN965_Pad_TopOnly
J1: Conn_02x12_OK-14F024-04_v1; Connector_b2b_OK-F024-04_v1
J2: MB Interface; Custom_8_pin_for_SmartWatch_v4-MB-straightline
L1: 2.7nH; L_0402_1005Metric
L2: 3.9nH; L_0402_1005Metric
R1, R2, R4, R27, R28, R30, R33, R34, R35, R36: 10k; R_0402_1005Metric_Pad0.72x0.64mm_HandSolder
R3, R5, R6, R7: 5k1; R_0402_1005Metric_Pad0.72x0.64mm_HandSolder
SW2: EC05E1220401; SW-SMD_EC05E1220401-CUSTOM-ORIENT_v1; MPN EC05E1220401; LCSC Part C116648
TP1: 50R BLE sig; TestPoint_Pad_D1.0mm
TP3: TMP_ALRT; TestPoint_Pad_D1.0mm
TP13: 50R BLE gnd; TestPoint_Pad_D1.0mm
TP14: VEML_INT; TestPoint_Pad_D1.0mm
TP15: BQ_STAT; TestPoint_Pad_D1.0mm
TP17: SD_Cd; TestPoint_Pad_D1.0mm
TP18: LIS_INT; TestPoint_Pad_D1.0mm
TP19: LIS_DRDY; TestPoint_Pad_D1.0mm
TP20: LSM_INT2; TestPoint_Pad_D1.0mm
TP21: M10S_RST; TestPoint_Pad_D1.0mm
TP22: USB_D+; TestPoint_Pad_D1.0mm
TP23: USB_D-; TestPoint_Pad_D1.0mm
U1: ESP32-S3-WROOM-1U-N16R8; WIRELM-SMD_ESP32-S3-WROOM-1U; LCSC Part C3013946

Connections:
+1V8: J2.2; also elsewhere on the board
+3V3: C40.1, C47.1, Card1.4 (VDD), D1.1 (VCC), J1.1, J1.7, J1.8, J1.10, J1.23, J2.3, R1.2, R2.2, R3.1, R4.1, R5.1, R6.1, R7.1, R27.2, R28.2, R30.2, R33.2, R34.2, R35.2, R36.2, U1.2 (3V3); also elsewhere on the board
+5V: J2.4; also elsewhere on the board
BQ_BUTTON: U1.9 (IO16); also elsewhere on the board
BQ_STAT: TP15.1 (1_1); also elsewhere on the board
D+: D1.5 (IO2), TP22.1 (1_1), U1.14 (IO20); also elsewhere on the board
D-: D1.3 (IO1), TP23.1 (1_1), U1.13 (IO19); also elsewhere on the board
DRV_EN: U1.27 (IO0); also elsewhere on the board
EC_SigA: C45.1, R36.1, SW2.B, U1.23 (IO21)
EC_SigB: C44.1, R35.1, SW2.A, U1.37 (TXD0)
GND: C40.2, C42.2, C44.2, C45.2, C47.2, Card1.6 (VSS), Card1.10, Card1.11, Card1.12, Card1.13, D1.4 (GND), H1.1 (1_1), J1.6, J1.11, J1.13, J1.15, J1.17, J1.27, J1.28, J1.29, J1.30, J2.1, L1.2, SW2.4, SW2.5, SW2.C, TP13.1 (1_1), U1.1 (GND), U1.40 (GND), U1.41 (PAD_GND); also elsewhere on the board
GPIO_FLASHLIGHT: U1.34 (IO41); also elsewhere on the board
LIS_DRDY: TP19.1 (1_1); also elsewhere on the board
LIS_INT: TP18.1 (1_1); also elsewhere on the board
LSM_INT1: U1.12 (IO8); also elsewhere on the board
LSM_INT2: TP20.1 (1_1); also elsewhere on the board
M10-RX: U1.11 (IO18); also elsewhere on the board
M10-TX: U1.10 (IO17); also elsewhere on the board
M10S_RST: TP21.1 (1_1); also elsewhere on the board
MAX_INT: J2.5, U1.7 (IO7)
Mic_CLK: U1.24 (IO47); also elsewhere on the board
Mic_Dout: U1.25 (IO48); also elsewhere on the board
unnamed: AE3.1 (FEED_1), L2.2
unnamed: C1.1, TP1.1 (1_1)
unnamed: C1.2, L1.1, L2.1
unnamed: C42.1, R33.1, U1.3 (EN)
QSPI-CLK: J1.16, U1.20 (IO12)
QSPI-I1: J1.22, U1.21 (IO13)
QSPI-I2: J1.20, U1.17 (IO9)
QSPI-I3: J1.18, U1.22 (IO14)
QSPI-IO: J1.14, U1.19 (IO11)
QSPI-RESET: J1.12, U1.15 (IO3)
QSPI_CS: J1.21, U1.18 (IO10)
QSPI_TE: J1.24, U1.26 (IO45)
Qvar1: J2.8; also elsewhere on the board
RTC_INT: U1.8 (IO15); also elsewhere on the board
SCL: J1.2, J2.6, R5.2, U1.38 (IO2); also elsewhere on the board
SCL_bus2: R7.2, U1.5 (IO5); also elsewhere on the board
SDA: J1.3, J2.7, R3.2, U1.39 (IO1); also elsewhere on the board
SDA_bus2: R6.2, U1.4 (IO4); also elsewhere on the board
SD_CLK: Card1.5 (CLX), R34.1, U1.31 (IO38)
SD_CMD: Card1.3 (CMD), R27.1, U1.32 (IO39)
SD_Cd: Card1.9 (CD), R4.2, TP17.1 (1_1)
SD_DAT0: Card1.7 (DAT0), R28.1, U1.33 (IO40)
SD_DAT1: Card1.8 (DAT1), R30.1
SD_DAT2: Card1.1 (DAT2), R1.1
SD_DAT3/CD: Card1.2 (CD/DAT3), R2.1
Sig_LED_Din: U1.35 (IO42); also elsewhere on the board
TMP_ALRT: TP3.1 (1_1); also elsewhere on the board
TP-INT_3V3: J1.4, U1.6 (IO6)
TP-RST_3V3: J1.5, U1.36 (RXD0)
TimePulse: U1.16 (IO46); also elsewhere on the board
VEML_INT: TP14.1 (1_1); also elsewhere on the board

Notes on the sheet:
Crown Encoder EC05 + Pushbutton + ECG
TVS Protection
Resolved: CLK MISSING 10k PULLUP
ESP32-S3 WROOM 1U N16R8
2.06-inch AMOLED (CO5300AF-51+CST9217) OK-14F024-04 connector
Daughterboard PCB MAX30101 + TMP117
Native 1-bit: 3 GPIOs (CLK, CMD, DAT0)

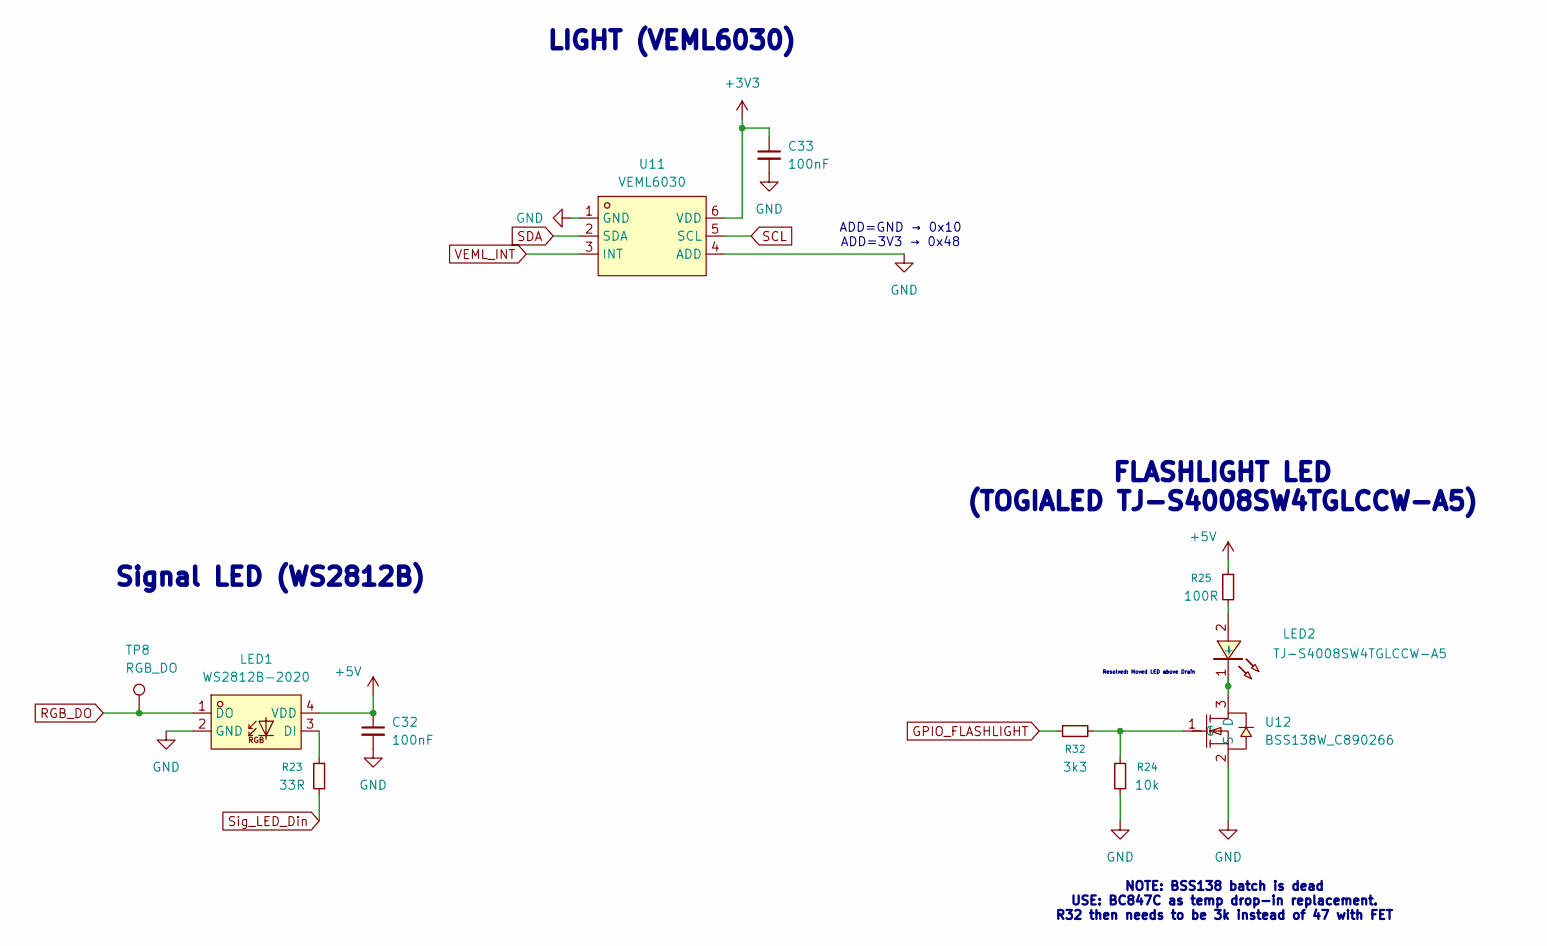
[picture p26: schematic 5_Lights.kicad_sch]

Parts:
C32, C33: 100nF; C_0402_1005Metric_Pad0.74x0.62mm_HandSolder
LED1: WS2812B-2020; LED-SMD_4P-L2.0-W2.0-TL_WS2812B-2020; LCSC Part C965555
LED2: TJ-S4008SW4TGLCCW-A5; LED-SMD_TJ-S4008SW4TGLCCW-A5; LCSC Part C601698
R23: 33R; R_0402_1005Metric_Pad0.72x0.64mm_HandSolder
R24: 10k; R_0402_1005Metric_Pad0.72x0.64mm_HandSolder
R25: 100R; R_0402_1005Metric_Pad0.72x0.64mm_HandSolder
R32: 3k3; R_0402_1005Metric_Pad0.72x0.64mm_HandSolder
TP8: RGB_DO; TestPoint_Pad_1.0x1.0mm
U11: VEML6030; SENSORS-SMD_VEML6030; LCSC Part C132182
U12: BSS138W_C890266; SC-70-3_L2.0-W1.3-P0.65-LS2.1-BL; LCSC Part C890266

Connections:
+3V3: C33.1, U11.6 (VDD); also elsewhere on the board
+5V: C32.1, LED1.4 (VDD), R25.1; also elsewhere on the board
GND: C32.2, C33.2, LED1.2 (GND), R24.2, U11.1 (GND), U11.4 (ADD), U12.2 (S); also elsewhere on the board
GPIO_FLASHLIGHT: R32.1; also elsewhere on the board
unnamed: LED1.3 (DI), R23.1
unnamed: LED2.2 (+), R25.2
unnamed: LED2.1 (-), U12.3 (D)
unnamed: R24.1, R32.2, U12.1 (G)
RGB_DO: LED1.1 (DO), TP8.1 (1_1)
SCL: U11.5 (SCL); also elsewhere on the board
SDA: U11.2 (SDA); also elsewhere on the board
Sig_LED_Din: R23.2; also elsewhere on the board
VEML_INT: U11.3 (INT); also elsewhere on the board

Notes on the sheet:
Signal LED (WS2812B)
LIGHT (VEML6030)
ADD=GND → 0x10 ADD=3V3 → 0x48
FLASHLIGHT LED (TOGIALED TJ-S4008SW4TGLCCW-A5)
Resolved: Moved LED above Drain
NOTE: BSS138 batch is dead USE: BC847C as temp drop-in replacement. R32 then needs to be 3k instead of 47 with FET

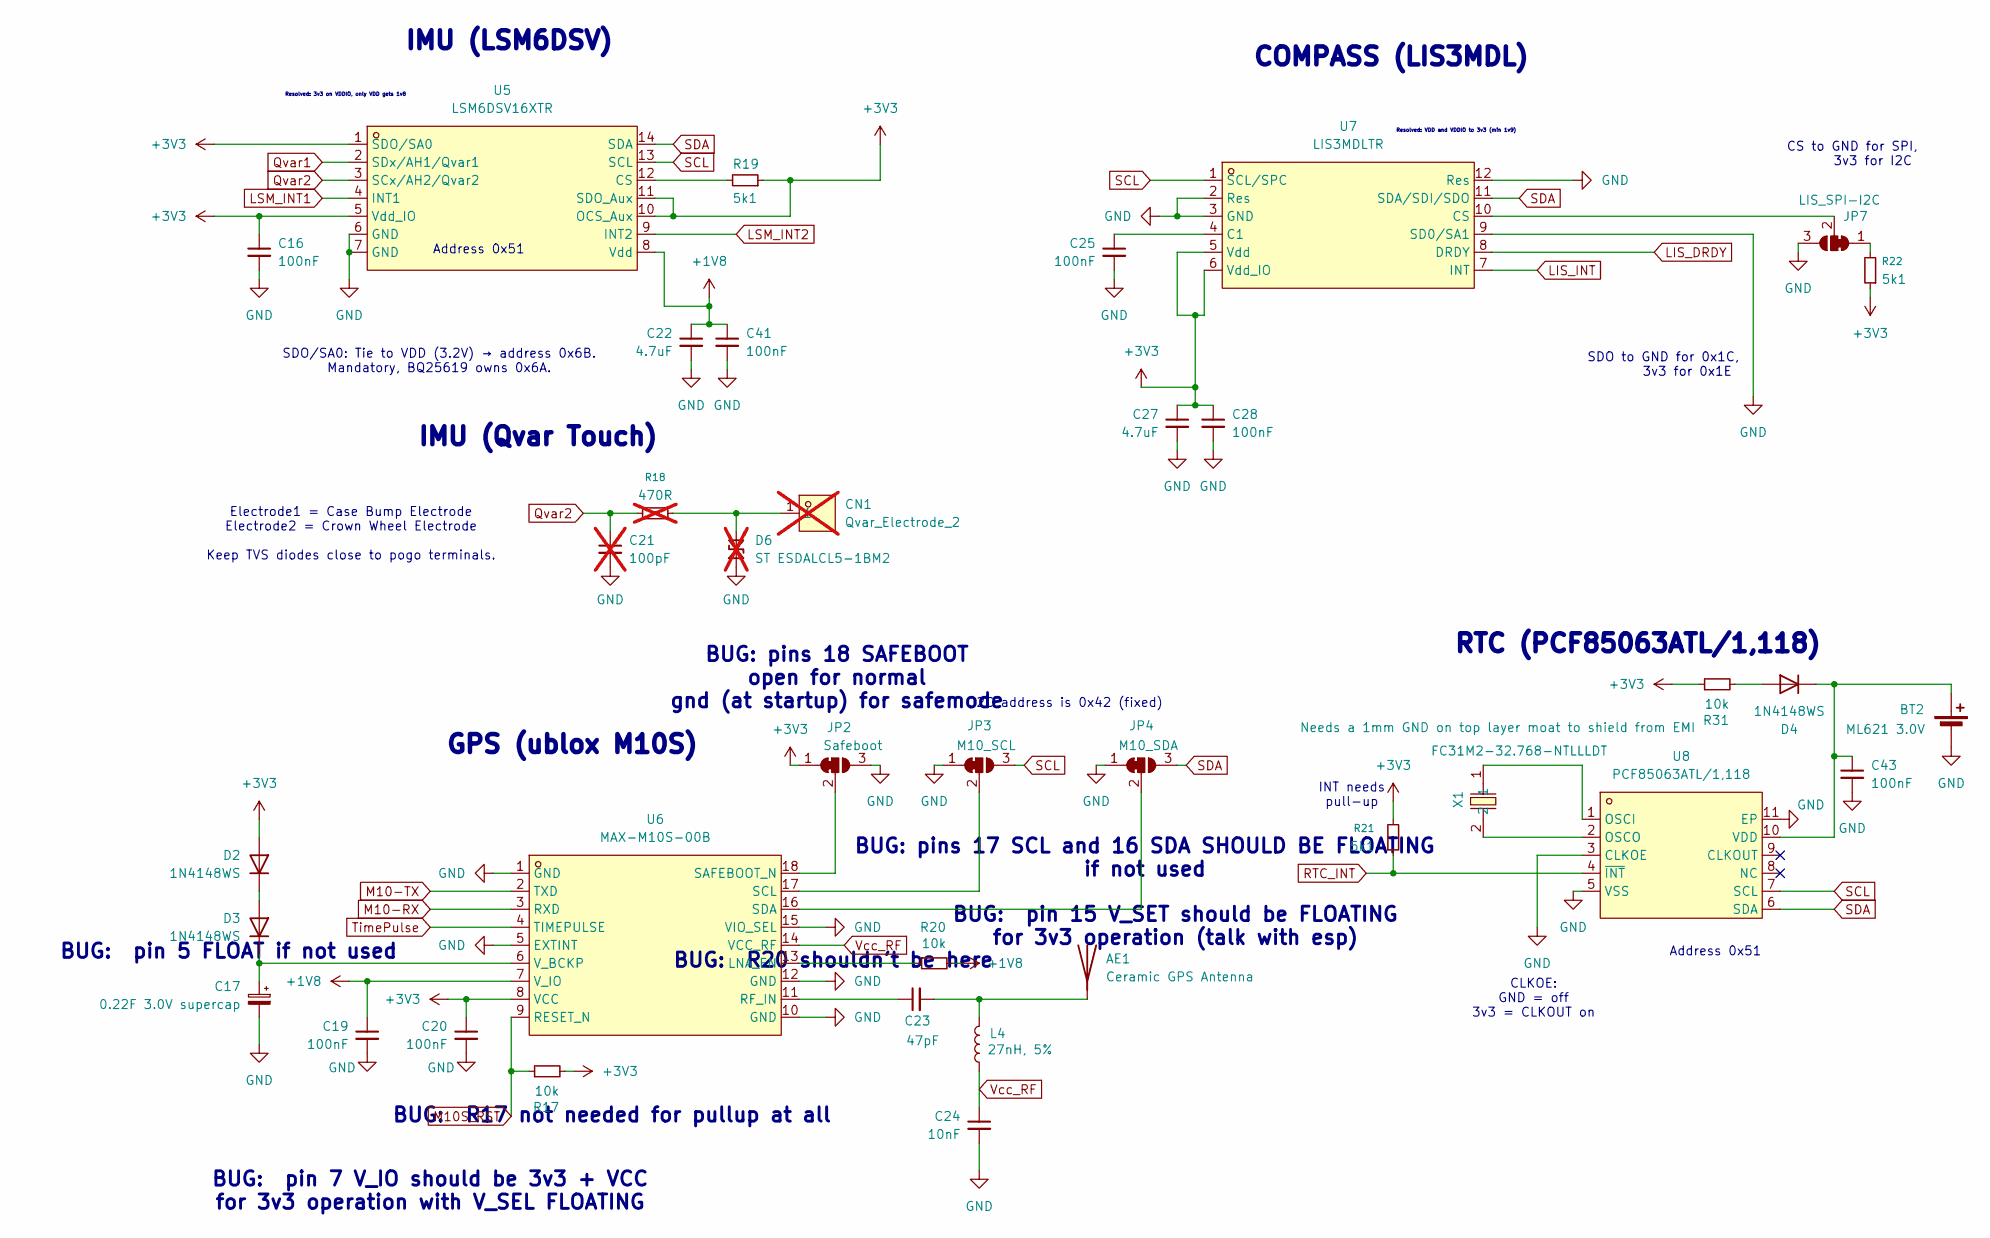
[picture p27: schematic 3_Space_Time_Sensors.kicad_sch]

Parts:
AE1: Ceramic GPS Antenna; GPS_Ceramic_Antenna_8x8mm_v1.0
BT2: ML621 3.0V; DMS_3R3_224_supercap_feets_v1
C16, C19, C20, C25, C28, C41, C43: 100nF; C_0402_1005Metric_Pad0.74x0.62mm_HandSolder
C17: 0.22F 3.0V supercap; DMS_3R3_224_supercap_feets_v1
C21: 100pF; C_0402_1005Metric_Pad0.74x0.62mm_HandSolder; not fitted
C22, C27: 4.7uF; C_0402_1005Metric_Pad0.74x0.62mm_HandSolder
C23: 47pF; C_0402_1005Metric_Pad0.74x0.62mm_HandSolder
C24: 10nF; C_0402_1005Metric_Pad0.74x0.62mm_HandSolder
CN1: Qvar_Electrode_2; TestPoint_Pad_D1.5mm; MPN YZR0028-15020-01; LCSC Part C7429439; not fitted
D2, D3, D4: 1N4148WS; D_SOD-323
D6: ST ESDALCL5-1BM2; D_SOD-882; not fitted
JP2: Safeboot; SolderJumper-3_P1.3mm_Bridged2Bar12_RoundedPad1.0x1.5mm
JP3: M10_SCL; SolderJumper-3_P1.3mm_Bridged2Bar12_RoundedPad1.0x1.5mm
JP4: M10_SDA; SolderJumper-3_P1.3mm_Bridged2Bar12_RoundedPad1.0x1.5mm
JP7: LIS_SPI-I2C; SolderJumper-3_P1.3mm_Bridged2Bar12_RoundedPad1.0x1.5mm
L4: 27nH, 5%; C_0402_1005Metric_Pad0.74x0.62mm_HandSolder
R17, R20, R31: 10k; R_0402_1005Metric_Pad0.72x0.64mm_HandSolder
R18: 470R; R_0402_1005Metric_Pad0.72x0.64mm_HandSolder; not fitted
R19, R21, R22: 5k1; R_0402_1005Metric_Pad0.72x0.64mm_HandSolder
U5: LSM6DSV16XTR; LGA-14_L3.0-W2.5-P0.50-BR; LCSC Part C5267406
U6: MAX-M10S-00B; SMD-18_L10.1-W9.7-P1.10-TL_SKG09F; LCSC Part C4153167
U7: LIS3MDLTR; LGA-12_L2.0-W2.0-P0.50-BL; LCSC Part C478483
U8: PCF85063ATL/1,118; DFN-10_L2.6-W2.6-P0.50-BL-EP; LCSC Part C404360
X1: FC31M2-32.768-NTLLLDT; CRYSTAL-SMD_L3.2-W1.5-1; LCSC Part C2842180

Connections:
+1V8: C19.1, C22.1, C41.1, R20.2, U5.8 (Vdd), U6.7 (V_IO); also elsewhere on the board
+3V3: C16.1, C20.1, C27.1, C28.1, D2.2 (A), JP2.1 (A), R17.2, R19.1, R21.2, R22.1, R31.1, U5.1 (SDO/SA0), U5.5 (Vdd_IO), U5.10 (OCS_Aux), U5.11 (SDO_Aux), U6.8 (VCC), U7.5 (Vdd), U7.6 (Vdd_IO); also elsewhere on the board
GND: BT2.2 (-), C16.2, C17.2, C19.2, C20.2, C21.2, C22.2, C24.2, C25.2, C27.2, C28.2, C41.2, C43.2, D6.1 (A1), JP2.3 (B), JP3.1 (A), JP4.1 (A), JP7.3 (B), U5.6 (GND), U5.7 (GND), U6.1 (GND), U6.5 (EXTINT), U6.10 (GND), U6.12 (GND), U6.15 (VIO_SEL), U7.2 (Res), U7.3 (GND), U7.9 (SD0/SA1), U7.12 (Res), U8.3 (CLKOE), U8.5 (VSS), U8.11 (EP); also elsewhere on the board
LIS_DRDY: U7.8 (DRDY); also elsewhere on the board
LIS_INT: U7.7 (INT); also elsewhere on the board
LSM_INT1: U5.4 (INT1); also elsewhere on the board
LSM_INT2: U5.9 (INT2); also elsewhere on the board
M10-RX: U6.3 (RXD); also elsewhere on the board
M10-TX: U6.2 (TXD); also elsewhere on the board
M10S_RST: R17.1, U6.9 (RESET_N); also elsewhere on the board
unnamed: AE1.1 (A_1), C23.2, L4.1
unnamed: BT2.1 (+), C43.1, D4.1 (K), U8.10 (VDD)
unnamed: D2.1 (K), D3.2 (A)
unnamed: C17.1, D3.1 (K), U6.6 (V_BCKP)
unnamed: D4.2 (A), R31.2
unnamed: CN1.1 (1_1), D6.2 (A2), R18.2
unnamed: JP2.2 (C), U6.18 (SAFEBOOT_N)
unnamed: JP3.2 (C), U6.17 (SCL)
unnamed: JP4.2 (C), U6.16 (SDA)
unnamed: JP7.1 (A), R22.2
unnamed: JP7.2 (C), U7.10 (CS)
unnamed: R19.2, U5.12 (CS)
unnamed: R20.1, U6.13 (LNA_EN)
unnamed: C23.1, U6.11 (RF_IN)
unnamed: C25.1, U7.4 (C1)
unnamed: U8.1 (OSCI), X1.1
unnamed: U8.2 (OSCO), X1.2
Qvar1: U5.2 (SDx/AH1/Qvar1); also elsewhere on the board
Qvar2: C21.1, R18.1, U5.3 (SCx/AH2/Qvar2)
RTC_INT: R21.1, U8.4 (~INT); also elsewhere on the board
SCL: JP3.3 (B), U5.13 (SCL), U7.1 (SCL/SPC), U8.7 (SCL); also elsewhere on the board
SDA: JP4.3 (B), U5.14 (SDA), U7.11 (SDA/SDI/SDO), U8.6 (SDA); also elsewhere on the board
TimePulse: U6.4 (TIMEPULSE); also elsewhere on the board
Vcc_RF: C24.1, L4.2, U6.14 (VCC_RF)

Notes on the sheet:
SDO/SA0: Tie to VDD (3.2V) → address 0x6B. Mandatory, BQ25619 owns 0x6A.
Address 0x51
COMPASS (LIS3MDL)
CLKOE: GND = off 3v3 = CLKOUT on
BUG: pin 7 V_IO should be 3v3 + VCC for 3v3 operation with V_SEL FLOATING
Electrode1 = Case Bump Electrode Electrode2 = Crown Wheel Electrode Keep TVS diodes close to pogo terminals.
BUG: R20 shouldn't be here
IMU (Qvar Touch)
BUG: pin 15 V_SET should be FLOATING for 3v3 operation (talk with esp)
INT needs pull-up
I2C address is 0x42 (fixed)
Resolved: VDD and VDDIO to 3v3 (min 1v9)
BUG: R17 not needed for pullup at all
BUG: pins 17 SCL and 16 SDA SHOULD BE FLOATING if not used
Resolved: 3v3 on VDDIO, only VDD gets 1v8
CS to GND for SPI, 3v3 for I2C
IMU (LSM6DSV)
GPS (ublox M10S)
SDO to GND for 0x1C, 3v3 for 0x1E
BUG: pin 5 FLOAT if not used
BUG: pins 18 SAFEBOOT open for normal gnd (at startup) for safemode
RTC (PCF85063ATL/1,118)

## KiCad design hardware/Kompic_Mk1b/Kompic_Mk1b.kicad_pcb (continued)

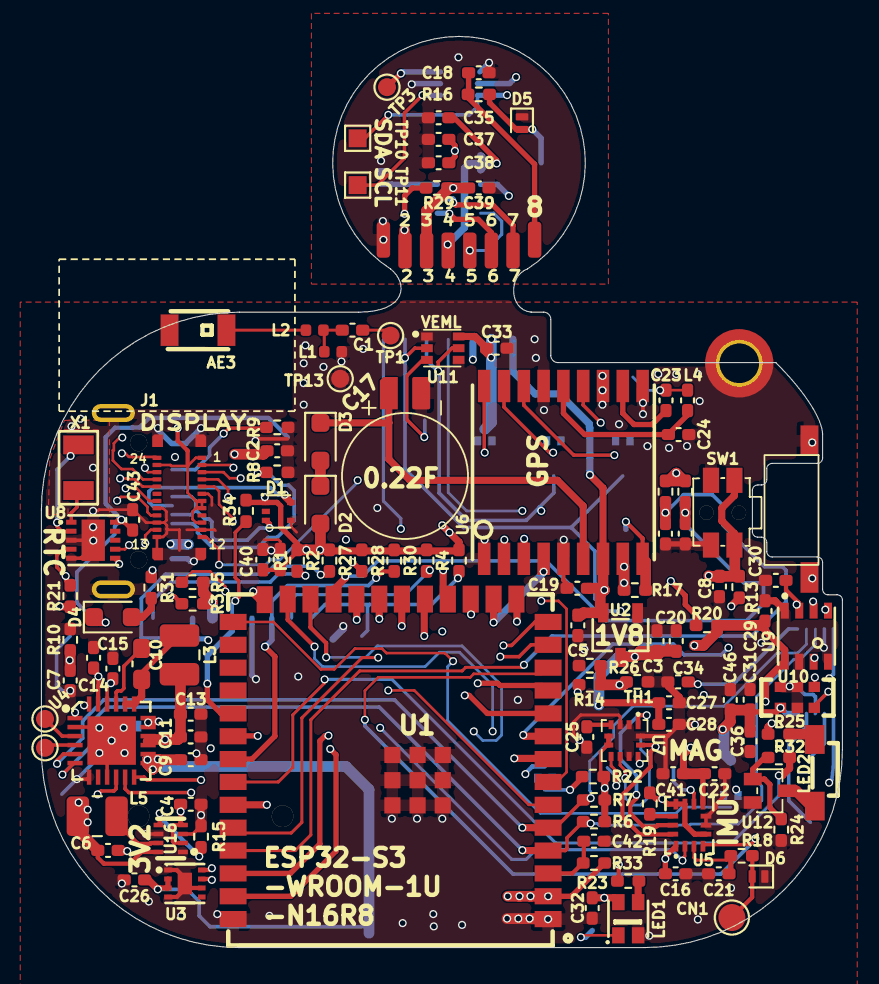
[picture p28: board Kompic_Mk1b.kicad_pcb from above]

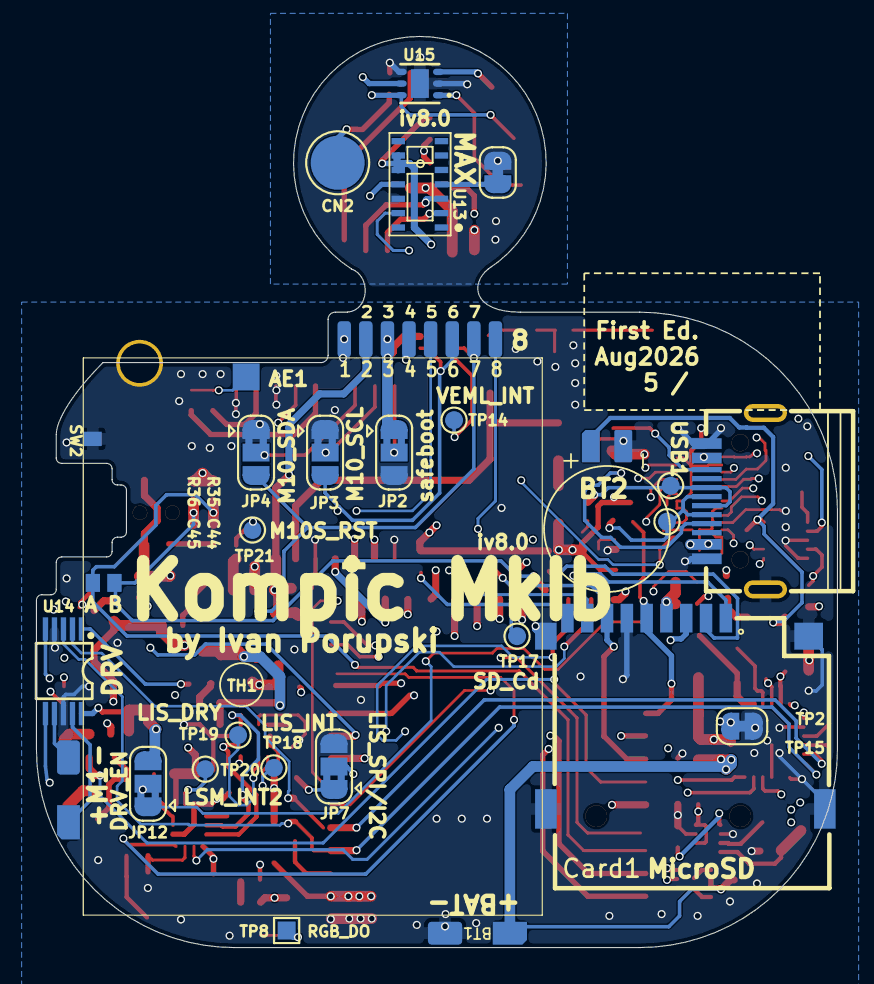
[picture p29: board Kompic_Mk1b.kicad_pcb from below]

Board: 4 copper layers, 44.5 x 50.6 mm, 149 parts (27 on the bottom side), 104 nets.

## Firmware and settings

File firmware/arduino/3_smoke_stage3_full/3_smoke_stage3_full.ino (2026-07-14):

/**
 * 3_smoke_stage3_full.ino — Kompic Mk I, full-board smoke test
 *
 * Refactored 2026-07-05 as part of the Stage 5 close-out. Renamed from
 * 3_smoke_test_mk1_hotair in the pre-refactor legacy set. Additions since
 * the original 2026-06-20 write-up:
 *   - Ship-mode double-click handler (2026-07-05 port from 4_demo_mk1).
 *   - Summary print reordered to run AFTER SD init (Stage 3 § 4.6 mitigation
 *     no longer needed now that SD is reliable per Stage 4).
 * See hardware/Reflow_info/Stage_5_Build_Report.md for context.
 *
 * Build progression on this board:
 *   Stage 1 (reflow, verified by 1_smoke_stage1_reflow1):
 *     ESP32-S3-WROOM-1U, BQ25619, TPS62840 3.2 V, XC6206 1.8 V,
 *     flashlight LED (GPIO41), button (BQ QON / GPIO16),
 *     PCF85063A RTC + crystal.
 *   Stage 2 (hot air, 2_smoke_stage2_hotair):
 *     + USB-C JS16T, VEML6030, LIS3MDLTR, LSM6DSV16X, BME688,
 *     + MSM261DGT003 PDM mic, WS2812B-2020 RGB.
 *   Stage 3 (this sketch -- full board incl. daughter):
 *     + microSD push-push socket    (SDMMC 1-bit: CLK=38 CMD=39 DAT0=40)
 *     + DRV2605L LRA haptic driver  (bus 2 @ 0x5A, EN=GPIO0)
 *     + ALPS EC05E rotary encoder   (A=GPIO21, B=GPIO43)
 *     + MAX30101 PPG  (daughterboard U13, bus 1 @ 0x57, INT=GPIO7)
 *     + TMP117 temp   (daughterboard U15, bus 1 @ 0x48 or 0x49 — probed at boot)
 *   Physical placement (PCB is canonical, schematic hierarchy disagrees):
 *     Bus 1 (east, sensors)  = VEML, LIS, RTC, LSM, BME, MAX, TMP
 *     Bus 2 (west, power)    = BQ (top main), DRV (underside main)
 *   QVAR/ECG electrodes on daughterboard not yet tested; GPS module not fitted.
 *
 * Sequence:
 *   1. Banner, LEDC/button/encoder init, boot flash.
 *   2. Drive DRV_EN (GPIO0) HIGH so the haptic chip leaves shutdown
 *      before any bus 2 traffic. Internal boot pull-up alone does
 *      NOT hold it after the ROM bootloader releases the strap.
 *   3. Full I2C scan on both buses.
 *   4. Per-chip identity probe (stage-2 sensors + DRV2605L).
 *   5. WS2812 colour walk.
 *   6. PDM mic init + variation check.
 *   7. SD card mount (1-bit, GPIO38/39/40). On success:
 *        - append one line to /smoke_log.txt with the boot summary,
 *        - count *.txt and *.TXT files in the root directory.
 *   8. PASS/FAIL summary.
 *   9. Loop: dwell on each device for 3 s, printing one line every
 *      0.5 s. DRV trigger fires once per dwell tick (6 buzzes per
 *      visit). Encoder + button are always responsive (ISR-driven).
 *
 * Encoder notes (datasheet 20.16):
 *   - 6 ms mechanical bounce -> software debounce, 8 ms guard window.
 *   - GPIO43 is also U0TXD: one ~3 ms boot-log blip before user code
 *     runs. We attach the interrupt only after setup() prints its
 *     banner, so the blip is harmless.
 *   - A/B state at detent is undefined; decode on A-edge by sampling
 *     B level.  CW/CCW polarity is a bench guess -- flip
 *     ENC_INVERT below if the printout has the directions swapped.
 *
 * DRV2605L notes (datasheet 20.14):
 *   - Auto-cal at boot with the ELV1411A profile (RATED=0x49, OD_CLAMP=0x60).
 *     Post-Stage-5 chip swap: cal PASSes in ~1.1 s (STATUS=0xE0,
 *     COMP=0x07, BEMF=0x8F, no OC_DETECT). Effects play with a firm
 *     tactile click at each encoder detent.
 *
 * Arduino-ESP32 v3.x API (ledcAttach, neopixelWrite, ESP_I2S, SD_MMC).
 * Board: "ESP32S3 Dev Module", USB CDC On Boot: Enabled.
 * Pins from: hardware/Kompic_Mk1/0_Kompic_Pinout_MASTER_v20_iv7.1.md
 */

#include <Wire.h>
#include <math.h>
#include "ESP_I2S.h"
#include "FS.h"
#include "SD_MMC.h"

// ── Pins ─────────────────────────────────────────────────────────────────────
#define PIN_FLASHLIGHT    41
#define PIN_BUTTON        16
#define PIN_SDA_BUS1       1    // east edge — RTC + ALS/IMU/mag/env
#define PIN_SCL_BUS1       2
#define PIN_SDA_BUS2       4    // west edge — BQ charger + DRV2605L
#define PIN_SCL_BUS2       5
#define PIN_RTC_INT       15
#define PIN_LSM_INT1       8
#define PIN_WS2812_DIN    42
#define PIN_MIC_CLK       47
#define PIN_MIC_DATA      48
#define PIN_SD_CLK        38
#define PIN_SD_CMD        39
#define PIN_SD_D0         40
#define PIN_DRV_EN         0    // strap (boot-only pull-up); FW must drive HIGH
#define PIN_ENC_A         21    // RTC wake-capable
#define PIN_ENC_B         43    // U0TXD — boot-log blip before user code runs

// ── I2C addresses ─────────────────────────────────────────────────────────────
#define VEML6030_ADDR     0x10
#define LIS3MDL_ADDR      0x1C
#define PCF85063A_ADDR    0x51
#define LSM6DSV_ADDR      0x6B
#define BME688_ADDR       0x76
#define BQ25619_ADDR      0x6A
#define DRV2605_ADDR      0x5A   // bus 2 — main board UNDERSIDE
#define MAX30101_ADDR     0x57   // bus 1 — daughterboard U13
#define TMP117_ADDR_LO    0x48   // bus 1 — daughterboard U15 if ADD0=GND
#define TMP117_ADDR_HI    0x49   //         if ADD0=3V3 (probe both at startup)
// Physical layout (per Ivan, schematic hierarchy disagrees but PCB is canonical):
//   Bus 1 (east, GPIO1/2):  VEML, LIS, RTC, LSM, BME, MAX, TMP  — sensors
//   Bus 2 (west, GPIO4/5):  BQ (top main), DRV (underside main) — power + haptic

// ── BQ25619 ───────────────────────────────────────────────────────────────────
#define BQ_REG_INPUT_SRC  0x00
#define BQ_REG_CTRL1      0x05
#define BQ_REG_STATUS     0x08
#define BQ_REG_FAULT      0x09
#define BQ_REG_PART       0x0A
#define BQ_STATUS_PG      (1 << 2)
#define BQ_TS_IGNORE_BIT  (1 << 6)
#define BQ_WD_MASK        (0x03 << 4)
#define BQ_REG_MISC_OP        0x07
#define BQ_BATFET_DIS         (1 << 5)
#define BQ_BATFET_RST_WVBUS   (1 << 4)
#define BQ_BATFET_DLY         (1 << 3)
#define BQ_BATFET_RST_EN      (1 << 2)

static const char *bq_ntc_name(uint8_t f) {
    switch (f & 0x07) {
        case 0b000: return "normal";
        case 0b010: return "warm";
        case 0b011: return "cool";
        case 0b101: return "cold";
        case 0b110: return "hot";
        default:    return "?";
    }
}

// ── PCF85063A ─────────────────────────────────────────────────────────────────
#define RTC_REG_CTRL1     0x00
#define RTC_REG_SECONDS   0x04
#define RTC_OS_BIT        0x80

// ── VEML6030 ──────────────────────────────────────────────────────────────────
#define VEML_REG_CONF     0x00
#define VEML_REG_ALS      0x04
#define VEML_REG_WHITE    0x05
#define VEML_CONF_RUN     ((uint16_t)((0x03 << 11) | (0x00 << 6)))
#define VEML_LX_PER_CT_QUARTER_100MS  0.2304f

// ── LIS3MDLTR ─────────────────────────────────────────────────────────────────
#define LIS_REG_WHO       0x0F
#define LIS_WHO_VAL       0x3D
#define LIS_REG_CTRL1     0x20
#define LIS_REG_CTRL2     0x21
#define LIS_REG_CTRL3     0x22
#define LIS_REG_CTRL4     0x23
#define LIS_REG_CTRL5     0x24
#define LIS_REG_OUT_X_L   0x28
#define LIS_AUTO_INC      0x80
#define LIS_LSB_PER_GAUSS_4G  6842.0f

// ── LSM6DSV16X ────────────────────────────────────────────────────────────────
#define LSM_REG_WHO       0x0F
#define LSM_WHO_VAL       0x70
#define LSM_REG_CTRL1     0x10
#define LSM_REG_CTRL2     0x11
#define LSM_REG_CTRL3     0x12
#define LSM_REG_OUT_TEMP  0x20

// ── BME688 ────────────────────────────────────────────────────────────────────
#define BME_REG_CHIP_ID      0xD0
#define BME_REG_VARIANT_ID   0xF0
#define BME_REG_RESET        0xE0
#define BME_REG_CTRL_HUM     0x72
#define BME_REG_CTRL_GAS1    0x71
#define BME_REG_CTRL_MEAS    0x74
#define BME_REG_PRESS_ADC    0x1F
#define BME_REG_CAL_BLK1     0x8A
#define BME_REG_CAL_BLK2     0xE1
#define BME_CHIP_ID_VAL      0x61

// ── DRV2605L ──────────────────────────────────────────────────────────────────
#define DRV_REG_STATUS       0x00
#define DRV_REG_MODE         0x01
#define DRV_REG_LIBRARY      0x03
#define DRV_REG_WAVSEQ1      0x04
#define DRV_REG_WAVSEQ2      0x05
#define DRV_REG_GO           0x0C
#define DRV_REG_RATED_VOLT   0x16
#define DRV_REG_OD_CLAMP     0x17
#define DRV_REG_A_CAL_COMP   0x18
#define DRV_REG_A_CAL_BEMF   0x19
#define DRV_REG_FEEDBACK     0x1A
#define DRV_REG_CTRL1        0x1B   // DRIVE_TIME (initial f_LRA guess)
#define DRV_REG_CTRL4        0x1E   // AUTO_CAL_TIME
#define DRV_DEVICE_ID_VAL    0x07   // top 3 bits of STATUS
#define DRV_MODE_INTERNAL    0x00   // STANDBY=0, MODE=000 (internal trigger / GO)
#define DRV_MODE_AUTO_CAL    0x07   // STANDBY=0, MODE=111 (auto-cal)
#define DRV_LIB_LRA          0x06

// ── ELV1411A LRA motor specs (per Ivan, no datasheet on file yet) ────────────
//   V_rated  = 2.0 V_RMS       (max steady drive)
//   f_LRA    = 150 ± 5 Hz      (mechanical resonance)
//   I_max    = 150 mA          (absolute current limit)
// User wants this to rattle hard — drive at rated voltage. Auto-cal will
// confirm back-EMF is in range; if it fails the chip falls back to open-loop
// and effects still play (per 20.14 datasheet note).
#define DRV_V_RATED_RMS      2.0f
#define DRV_F_LRA_HZ         150
#define DRV_I_MAX_MA         150

// RATED_VOLTAGE = V_rated_RMS / 20.58e-3                 (simplified, p.44)
// Spec is 2.0 V_RMS but auto-cal tripped OC_DETECT at 0x61/0x8D — the chip's
// open-loop probe pulses near OD_CLAMP into ~10 Ω DCR exceed the OC threshold.
// Step the targets down so cal can complete: 1.5 V_RMS / 2.0 V peak.
//   1.5 V_RMS / 0.02058 ≈ 73 → 0x49
#define DRV_RATED_VOLTAGE    0x49

// OD_CLAMP_V = 21.22e-3 × OD_CLAMP                       (peak, p.44)
// Must remain > RATED_VOLTAGE register-wise.
//   2.0 V peak / 0.02122 ≈ 94 → 0x60
#define DRV_OD_CLAMP         0x60

// CTRL1 bit7=STARTUP_BOOST (default keep), bits4:0=DRIVE_TIME.
// t_drive(ms) ≈ 0.5/f_LRA → 0.5/150 = 3.33 ms → DRIVE_TIME = (3.33-0.5)/0.1 = 28 = 0x1C.
// CTRL1 = STARTUP_BOOST | DRIVE_TIME = 0x80 | 0x1C = 0x9C.
#define DRV_CTRL1_DRIVE_TIME 0x9C

// FEEDBACK_CTRL (datasheet auto-cal example value).
//   bit7   N_ERM_LRA      = 1  (LRA)
//   6:4    FB_BRAKE_FACTOR= 3  (4×)
//   3:2    LOOP_GAIN      = 1  (medium)
//   1:0    BEMF_GAIN      = 2  (15× LRA, recommended)
#define DRV_FEEDBACK_LRA     0xB6

// CTRL4: AUTO_CAL_TIME = 3 (1000–1200 ms, most accurate). Other fields = 0.
#define DRV_AUTO_CAL_TIME    0x30

// ── MAX30101 (PPG, daughterboard U13) ────────────────────────────────────────
#define MAX_REG_INT_STATUS_1  0x00
#define MAX_REG_FIFO_WR_PTR   0x04
#define MAX_REG_OVERFLOW_CTR  0x05
#define MAX_REG_FIFO_RD_PTR   0x06
#define MAX_REG_FIFO_DATA     0x07
#define MAX_REG_MODE_CONFIG   0x09
#define MAX_REG_LED1_PA       0x0C  // Red LED
#define MAX_REG_REV_ID        0xFE
#define MAX_REG_PART_ID       0xFF
#define MAX_PART_ID_VAL       0x15
#define MAX_MODE_RESET        0x40
#define MAX_MODE_HR           0x02  // heart-rate, Red LED only
#define MAX_LED_PA_SMOKE      0x1F  // ~6.2 mA per LED — modest, no skin needed

// ── TMP117 (precision temperature, daughterboard U15) ────────────────────────
#define TMP_REG_TEMP_RESULT   0x00  // 16-bit signed, 7.8125 m°C / LSB
#define TMP_REG_CONFIG        0x01
#define TMP_REG_DEVICE_ID     0x0F  // bottom 12 bits == 0x117
#define TMP_DEVICE_ID_LOW12   0x0117
#define TMP_LSB_C             (7.8125e-3f)

// LRA effect IDs to play during the DRV dwell (one per 500-ms tick, 6 total).
static const uint8_t drv_effects[6] = {
    1,    // Strong Click 100 %
    4,    // Sharp Click 100 %
    10,   // Double Click 100 %
    14,   // Strong Buzz 100 %
    47,   // Pulse 100 %
    16,   // 750 ms Alert 100 %
};

// ── PDM mic ──────────────────────────────────────────────────────────────────
#define MIC_SAMPLE_RATE_HZ   48000

// ── LED PWM ───────────────────────────────────────────────────────────────────
#define LED_FREQ_HZ          1000
#define LED_RES_BITS         8

// Flashlight current cap. The iv7.1 PCB has 2 × 47 Ω in series with the LED
// (R25 + R26 = 94 Ω). R26 was lost during bench rework, so only R25 (47 Ω)
// is in circuit — doubling the LED current at full duty (~36 mA, over the
// 30 mA abs-max). Clamp the LEDC duty to 25 % (= 64 / 255) until R26 is
// back in place. Keeps the LED at ~9 mA average / 18 mA peak — well cool.
#define LED_MAX_DUTY         64

// ── WS2812 levels ────────────────────────────────────────────────────────────
#define WS_BOOT_LEVEL        26
#define WS_LOOP_LEVEL        19
#define WS_BLIP_LEVEL        26   // ship-mode 2 s red countdown peak

// ── Button timing (ship-mode capable) ────────────────────────────────────────
#define BTN_DEBOUNCE_MS      30
#define BTN_DOUBLE_GAP_MS    350

// ── Loop dwell ───────────────────────────────────────────────────────────────
#define SENSOR_DWELL_MS      3000
#define SENSOR_PRINT_MS      500
#define DWELL_PRINTS         (SENSOR_DWELL_MS / SENSOR_PRINT_MS)   // 6
#define N_SENSORS            12                                    // + SD + DRV + MAX + TMP

// ── Encoder ──────────────────────────────────────────────────────────────────
#define ENC_DEBOUNCE_MS      8        // 6 ms bounce + 2 ms margin (20.16 W-01)
#define ENC_INVERT           0        // flip if printed direction is wrong

// ── BME688 calibration (filled at boot) ──────────────────────────────────────
typedef struct {
    uint16_t par_t1;
    int16_t  par_t2;
    int8_t   par_t3;
    uint16_t par_p1;
    int16_t  par_p2;
    int8_t   par_p3;
    int16_t  par_p4;
    int16_t  par_p5;
    int8_t   par_p6;
    int8_t   par_p7;
    int16_t  par_p8;
    int16_t  par_p9;
    uint8_t  par_p10;
    uint16_t par_h1;
    uint16_t par_h2;
    int8_t   par_h3;
    int8_t   par_h4;
    int8_t   par_h5;
    uint8_t  par_h6;
    int8_t   par_h7;
} bme_cal_t;

// ── State ─────────────────────────────────────────────────────────────────────
static bool bq_ok = false, rtc_ok = false, veml_ok = false, lis_ok = false,
            lsm_ok = false, bme_ok = false, mic_ok = false,
            drv_ok = false, sd_ok = false, max_ok = false, tmp_ok = false;
static bool drv_cal_ok = false;
static bool led_on = true;
static uint8_t bme_chip_id = 0, bme_variant = 0;
static bme_cal_t bme_cal = {0};
static uint8_t drv_device_id_raw = 0;
static uint8_t drv_cal_status = 0, drv_cal_comp = 0, drv_cal_bemf = 0;
static uint32_t drv_cal_ms = 0;
static uint64_t sd_card_size_mb = 0;
static int sd_txt_count = -1;
static const char *sd_card_kind = "?";
static uint8_t  max_part_id = 0, max_rev_id = 0;
static uint8_t  tmp_addr_used = 0;
static uint16_t tmp_device_id_raw = 0;

static I2SClass i2s_mic;

// Encoder ISR scratch (ints are 32-bit atomic on ESP32-S3).
static volatile int32_t enc_delta   = 0;   // accumulated +CW / -CCW
static volatile uint32_t enc_last_us = 0;

// ── LED helpers ───────────────────────────────────────────────────────────────
static void led_duty(uint8_t d) { ledcWrite(PIN_FLASHLIGHT, d); }

// ── I2C helpers ───────────────────────────────────────────────────────────────
static bool i2c_ping(TwoWire &bus, uint8_t addr) {
    bus.beginTransmission(addr);
    return bus.endTransmission() == 0;
}
static uint8_t i2c_read_reg(TwoWire &bus, uint8_t addr, uint8_t reg) {
    bus.beginTransmission(addr);
    bus.write(reg);
    if (bus.endTransmission(false) != 0) return 0xFF;
    bus.requestFrom(addr, (uint8_t)1);
    return bus.available() ? bus.read() : 0xFF;
}
static bool i2c_read_buf(TwoWire &bus, uint8_t addr, uint8_t reg,
                         uint8_t *buf, size_t n) {
    bus.beginTransmission(addr);
    bus.write(reg);
    if (bus.endTransmission(false) != 0) return false;
    bus.requestFrom(addr, (uint8_t)n);
    for (size_t i = 0; i < n; i++) {
        if (!bus.available()) return false;
        buf[i] = bus.read();
    }
    return true;
}
static bool i2c_write_reg(TwoWire &bus, uint8_t addr, uint8_t reg, uint8_t val) {
    bus.beginTransmission(addr);
    bus.write(reg);
    bus.write(val);
    return bus.endTransmission() == 0;
}

// TMP117 word read (big-endian on the wire: high byte first). Bus 1.
static bool tmp_read_word(uint8_t addr, uint8_t reg, uint16_t *val) {
    uint8_t b[2];
    if (!i2c_read_buf(Wire, addr, reg, b, 2)) return false;
    *val = ((uint16_t)b[0] << 8) | b[1];
    return true;
}

// VEML6030 word access
static bool veml_read_word(uint8_t reg, uint16_t *val) {
    Wire.beginTransmission(VEML6030_ADDR);
    Wire.write(reg);
    if (Wire.endTransmission(false) != 0) return false;
    if (Wire.requestFrom((int)VEML6030_ADDR, 2) != 2) return false;
    uint8_t lo = Wire.read();
    uint8_t hi = Wire.read();
    *val = ((uint16_t)hi << 8) | lo;
    return true;
}
static bool veml_write_word(uint8_t reg, uint16_t val) {
    Wire.beginTransmission(VEML6030_ADDR);
    Wire.write(reg);
    Wire.write(val & 0xFF);
    Wire.write(val >> 8);
    return Wire.endTransmission() == 0;
}

// ── BME688 cal parse ─────────────────────────────────────────────────────────
static bool bme_read_calibration(void) {
    uint8_t b1[23] = {0};
    uint8_t b2[10] = {0};
    if (!i2c_read_buf(Wire, BME688_ADDR, BME_REG_CAL_BLK1, b1, sizeof(b1))) return false;
    if (!i2c_read_buf(Wire, BME688_ADDR, BME_REG_CAL_BLK2, b2, sizeof(b2))) return false;

    bme_cal.par_t2  = (int16_t)((uint16_t)b1[1]  << 8 | b1[0]);
    bme_cal.par_t3  = (int8_t)b1[2];
    bme_cal.par_p1  = (uint16_t)((uint16_t)b1[5]  << 8 | b1[4]);
    bme_cal.par_p2  = (int16_t)((uint16_t)b1[7]  << 8 | b1[6]);
    bme_cal.par_p3  = (int8_t)b1[8];
    bme_cal.par_p4  = (int16_t)((uint16_t)b1[11] << 8 | b1[10]);
    bme_cal.par_p5  = (int16_t)((uint16_t)b1[13] << 8 | b1[12]);
    bme_cal.par_p7  = (int8_t)b1[14];
    bme_cal.par_p6  = (int8_t)b1[15];
    bme_cal.par_p8  = (int16_t)((uint16_t)b1[19] << 8 | b1[18]);
    bme_cal.par_p9  = (int16_t)((uint16_t)b1[21] << 8 | b1[20]);
    bme_cal.par_p10 = b1[22];

    bme_cal.par_h2  = ((uint16_t)b2[0] << 4) | (b2[1] >> 4);
    bme_cal.par_h1  = ((uint16_t)b2[2] << 4) | (b2[1] & 0x0F);
    bme_cal.par_h3  = (int8_t)b2[3];
    bme_cal.par_h4  = (int8_t)b2[4];
    bme_cal.par_h5  = (int8_t)b2[5];
    bme_cal.par_h6  = b2[6];
    bme_cal.par_h7  = (int8_t)b2[7];
    bme_cal.par_t1  = (uint16_t)((uint16_t)b2[9] << 8 | b2[8]);
    return true;
}

// ── DRV2605L helpers ─────────────────────────────────────────────────────────
static bool drv_trigger(uint8_t effect_id) {
    if (!drv_ok) return false;
    if (!i2c_write_reg(Wire1, DRV2605_ADDR, DRV_REG_WAVSEQ1, effect_id)) return false;
    if (!i2c_write_reg(Wire1, DRV2605_ADDR, DRV_REG_WAVSEQ2, 0x00))      return false;
    return i2c_write_reg(Wire1, DRV2605_ADDR, DRV_REG_GO, 0x01);
}

// ── Encoder ISR ──────────────────────────────────────────────────────────────
// A-edge sample of B: at rest A/B are unspecified, but during a transition
// the sign of (A XOR B_prev) reflects rotation direction. With pure rising-A
// triggering, "B==LOW means CW" or "B==HIGH means CW" depends on body
// orientation -- flip ENC_INVERT if wrong on bench.
static void IRAM_ATTR enc_isr_a(void) {
    uint32_t now = micros();
    if ((now - enc_last_us) < (uint32_t)ENC_DEBOUNCE_MS * 1000u) return;
    enc_last_us = now;
    int dir = (digitalRead(PIN_ENC_B) == LOW) ? +1 : -1;
    if (ENC_INVERT) dir = -dir;
    enc_delta += dir;
}

// ── Bus scan ──────────────────────────────────────────────────────────────────
static void scan_bus(TwoWire &bus, const char *name) {
    Serial.printf("[SCAN] %s: ", name);
    int count = 0;
    for (uint8_t a = 0x08; a < 0x78; a++) {
        if (i2c_ping(bus, a)) {
            Serial.printf("0x%02X ", a);
            count++;
        }
    }
    if (count == 0) Serial.print("(no devices)");
    Serial.printf(" -> %d device(s)\n", count);
}

// ── SD helpers ───────────────────────────────────────────────────────────────
static int sd_count_txt_files(void) {
    File root = SD_MMC.open("/");
    if (!root || !root.isDirectory()) return -1;
    int n = 0;
    for (File f = root.openNextFile(); f; f = root.openNextFile()) {
        if (!f.isDirectory()) {
            const char *name = f.name();
            size_t len = strlen(name);
            if (len >= 4) {
                const char *ext = name + len - 4;
                if ((ext[0] == '.') &&
                    (ext[1] == 't' || ext[1] == 'T') &&
                    (ext[2] == 'x' || ext[2] == 'X') &&
                    (ext[3] == 't' || ext[3] == 'T')) {
                    n++;
                }
            }
        }
        f.close();
    }
    root.close();
    return n;
}
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
void loop() {
    handle_button();

    // Encoder: drain accumulated delta from ISR, print one line per detent.
    int32_t d = enc_delta;
    if (d != 0) {
        enc_delta = 0;          // race-OK: any new ticks come right back next loop
        while (d > 0) { Serial.println("[ENC ] CW  ->"); d--; }
        while (d < 0) { Serial.println("[ENC ] CCW <-"); d++; }
    }

    // Dwell-based per-device streaming
    static uint8_t  active     = 0;
    static uint8_t  print_idx  = 0;
    static uint32_t next_ms    = 0;
    if ((int32_t)(millis() - next_ms) >= 0) {
        next_ms = millis() + SENSOR_PRINT_MS;
        if (print_idx == 0)
            Serial.printf("\n--- %s dwell (%u s) ---\n",
                          sensor_name(active), (unsigned)(SENSOR_DWELL_MS / 1000));
        sensor_dispatch(active, print_idx);
        if (++print_idx >= DWELL_PRINTS) {
            print_idx = 0;
            active = (active + 1) % N_SENSORS;
            if (active != 7) neopixelWrite(PIN_WS2812_DIN, 0, 0, 0);
        }
    }

    // Sine breathe on flashlight, clamped to LED_MAX_DUTY (current cap until
    // R26 is back in place — see top-of-file note).
    if (!led_on) { delay(10); return; }
    static float phase = 0.0f;
    phase += 0.03f;
    if (phase >= 2.0f * (float)M_PI) phase -= 2.0f * (float)M_PI;
    float s = (sinf(phase) + 1.0f) * 0.5f;                       // 0.0 .. 1.0
    uint8_t duty = (uint8_t)(s * (float)(LED_MAX_DUTY - 4) + 4); // 4 .. LED_MAX_DUTY
    led_duty(duty);
    delay(10);
}

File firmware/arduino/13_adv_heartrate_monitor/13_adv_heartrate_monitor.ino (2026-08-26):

/*
 * 13_adv_heartrate_monitor.ino  --  Kompic Mk I dual-channel HR (PPG + BCG)
 *
 * Successor to sketch 10 (MAX30101 wrist-PPG diagnostic) that runs the
 * MAX30101 (green PPG) and the LSM6DSV16X (BCG via accel magnitude) in
 * parallel and applies the *same* signal-processing pipeline to both
 * channels ("twins"). One session = one button press = a continuous
 * LED_PA sweep across the MAX30101 green LED, with everything streamed
 * to SD as an interleaved CSV plus a per-session JSON summary that
 * picks the winning LED_PA by composite quality.
 *
 * WHY: sketch 10 confirmed that on the wrist the raw green PPG on a
 * MAX30101 sits at DC counts ~900..9k across the LED_PA ladder (well
 * clear of the 18-bit ADC ceiling of 262k), so the ceiling here is
 * *noise floor* not *DC clip* -- the "squeeze" campaign wants a
 * quantitative sweep of AC/DC (perfusion index) vs LED current at
 * rest, then per-user selection of "best current for still wrist".
 * The BCG channel comes along for free: it's a fully independent
 * heartbeat estimate, and lets us cross-check PPG at rest. Same
 * pipeline for both makes them directly comparable.
 *
 * ── Session flow ────────────────────────────────────────────────────────
 *   idle       : RGB slow cyan breathe, waits for button
 *   single-click: PINK 3 s countdown ("get still"), then sweep begins
 *   sweep      : LED_PA ramps linearly from LED_PA_MIN..LED_PA_MAX over
 *                SWEEP_DURATION_S seconds in SWEEP_STEPS discrete steps.
 *                Signal-chain state is NOT reset between steps -- both
 *                channels roll forward so you see a *gradual hill* of
 *                amplitude vs LED current instead of hard jumps.
 *   end        : winner LED_PA (best composite quality) printed + written
 *                to JSON; RGB latches to winner color; back to idle
 *   long-hold  : ship mode (BQ25619 BATFET off) -- always available
 *
 * ── Signal chain (identical for MAX-green and LSM-BCG) ─────────────────
 *   1. Baseline EMA  : dc estimate, fast 0.10 for first 3 s, slow 0.02 after
 *   2. Bandpass IIR  : 2-pole Butterworth
 *                        MAX: 0.5..4 Hz (30..240 BPM cardiac fundamental)
 *                        LSM: 0.8..15 Hz (BCG fundamental + harmonics)
 *   3. Motion flag   : |dAC/dt| > k * running envelope -> mark motion,
 *                      drop beats within motion window
 *   4. Peak detect   : adaptive threshold = k * leaky-max(|bp|),
 *                      refractory 250 ms
 *   5. Autocorr      : every 2 s over last 5 s of bp signal -> independent
 *                      BPM estimate for cross-check (peak-detect vs autocorr)
 *   6. Quality       : geometric mean of (PI_norm * IBI_regularity *
 *                      motion_cleanliness * autocorr_agreement) in [0..100]
 *
 * ── Output modes (set OUT_MODE at top) ─────────────────────────────────
 *   OUT_MODE_PLOTTER  : 8 tab-separated traces per line for Serial Plotter
 *                        max_raw, max_baseline, max_ac, max_bp,
 *                        max_motion*1000, lsm_bcg_raw*1e5, lsm_bp*1e5,
 *                        lsm_motion*1000
 *   OUT_MODE_SERIAL   : 1 Hz human-readable status block
 *
 * ── Files (under /data/sk13_data/) ─────────────────────────────────────
 *   sk13_NNNN_YYYYMMDD_HHMMSS.csv   per-sample interleaved log, both channels
 *   sk13_NNNN_YYYYMMDD_HHMMSS.json  session metadata + per-step summary + winner
 *   NNNN  = session index scanned from SD at boot (1 + max existing on card).
 *          Monotonic across reboots so filenames sort by run order.
 *   YYYYMMDD_HHMMSS = PCF85063A RTC (OS bit is ignored; year-sanity check
 *          gates use of the value).
 *   If RTC is dead / not sane: falls back to sk13_NNNN_bootMsXXXXXXX.csv
 *
 * Board: ESP32-S3, Arduino IDE, USB Mode = "Hardware CDC and JTAG".
 */

#include <Arduino.h>
#include <Wire.h>
#include <SD_MMC.h>
#include <math.h>
#include "types.h"     // chan_t, step_summary_t -- MUST be a header, not
                       // inline typedef, so Arduino IDE's auto-prototype
                       // pass sees the types before it hoists prototypes

// ═════════════════════════════════════════════════════════════════════════════
// Compile-time knobs
// ═════════════════════════════════════════════════════════════════════════════
#define OUT_MODE_PLOTTER   0
#define OUT_MODE_SERIAL    1
#define OUT_MODE           OUT_MODE_PLOTTER

#define SWEEP_DURATION_S    120      // 4 x 20 s -- long enough per PA for
                                    // biquad settle + real autocorr window
#define SWEEP_STEPS         4       // discrete PA levels across LED_PA range
#define LED_PA_MIN          0x0F    // ~4 mA typ
#define LED_PA_MAX          0xFF    // ~51 mA typ
#define PRE_STILL_MS        3000    // pink countdown before sweep starts

// Serial-plotter trace clipping (Plotter auto-scales; clipping keeps traces sane)
#define MAX_AC_CLIP         3000
#define MAX_BP_CLIP         3000
#define LSM_BP_CLIP_G       0.03f   // ~30 mg display clip

// ═════════════════════════════════════════════════════════════════════════════
// Pin map (identical to sketches 7-12 on iv7.1)
// ═════════════════════════════════════════════════════════════════════════════
#define PIN_BUTTON        16
#define PIN_SDA_BUS1       1     // Wire  -> MAX30101, LSM6DSV16X, PCF85063A
#define PIN_SCL_BUS1       2
#define PIN_SDA_BUS2       4     // Wire1 -> BQ25619
#define PIN_SCL_BUS2       5
#define PIN_WS2812_DIN    42
#define PIN_SD_CLK        38
#define PIN_SD_CMD        39
#define PIN_SD_D0         40

// ═════════════════════════════════════════════════════════════════════════════
// I2C addresses
// ═════════════════════════════════════════════════════════════════════════════
#define MAX30101_ADDR     0x57
#define LSM6DSV_ADDR      0x6B
#define PCF85063A_ADDR    0x51
#define BQ25619_ADDR      0x6A

// ═════════════════════════════════════════════════════════════════════════════
// MAX30101 registers (from sketch 10 + datasheet extract 20.11)
// ═════════════════════════════════════════════════════════════════════════════
#define M_REG_FIFO_WR_PTR     0x04
#define M_REG_OVF_CTR         0x05
#define M_REG_FIFO_RD_PTR     0x06
#define M_REG_FIFO_DATA       0x07
#define M_REG_FIFO_CONFIG     0x08
#define M_REG_MODE_CONFIG     0x09
#define M_REG_SPO2_CONFIG     0x0A
#define M_REG_LED1_PA         0x0C
#define M_REG_LED2_PA         0x0D
#define M_REG_LED3_PA         0x0E
#define M_REG_MULTI_LED_1     0x11
#define M_REG_MULTI_LED_2     0x12
#define M_REG_PART_ID         0xFF
#define M_PART_ID_VAL         0x15
#define M_MODE_RESET          0x40
#define M_MODE_MULTI_LED      0x07
#define M_ADC_16384           0x03
#define M_SR_100              0x01
#define M_PW_411              0x03
#define M_SMP_AVE_8           0x03
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

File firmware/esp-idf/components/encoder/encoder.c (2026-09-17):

/**
 * @file encoder.c
 * @brief Crown rotary encoder driver -- PCNT-based, Core 0.
 *
 * Why PCNT (Pulse Counter)?
 *   - Quadrature decoding in hardware (no per-edge ISR overhead).
 *   - Built-in glitch filter (programmable threshold in APB cycles).
 *   - Watchpoint events for over/underflow handled by the IDF.
 *   - Free CPU: a quadrature detent at 200 RPM is one read every 5 ms;
 *     decoding it in software via GPIO ISRs would burn an ISR + a couple
 *     of memory accesses per edge. PCNT is one read per drain tick.
 *
 * Drain strategy:
 *   A periodic esp_timer (5 ms) reads the PCNT counter, computes the delta
 *   since the previous read, divides by ENCODER_STEPS_PER_DETENT (default 4
 *   for x4 quadrature decoding), and fires CW/CCW events into g_ui_event_q
 *   for each detent crossed. Sub-detent motion is preserved in a residue
 *   accumulator so partial rotations don't lose information.
 *
 * Debounce + boot guard:
 *   The PCNT hardware glitch filter eats sub-12.5-us pulses (default 1000
 *   APB cycles @ 80 MHz). A software debounce window (default 2 ms) gates
 *   subsequent detent events; mechanical bounce within 2 ms is suppressed
 *   and counted in s_glitch_count for diagnostics.
 *
 *   For the first ENCODER_BOOT_GUARD_MS after init, all drained detents
 *   are silently discarded -- this absorbs the v7.2-documented "GPIO43
 *   boot-log TX ~3 ms spurious activity".
 *
 * Architecture: Blueprint 1 §3, Blueprint 5 §2, Blueprint 11
 */

#include "encoder.h"
#include "driver/pulse_cnt.h"
#include "esp_log.h"
#include "esp_timer.h"
#include "freertos/FreeRTOS.h"
#include "freertos/queue.h"
#include "freertos/task.h"
#include <stdlib.h>

static const char *TAG = "ENCODER";

const char *encoder_get_chip_name(void) { return "CrownEnc";                    }
const char *encoder_get_chip_desc(void) { return "Rotary encoder (quadrature)"; }

// ────────────────────────────────────────────────────────────────────────────
// Forward extern: the UI event queue + ui_event_t enum live in lvgl_ui's
// ui_event.h which has not landed yet (DEFECT-002). We declare what we need
// here so the chip-layer driver compiles in isolation; the queue identity
// must match what lvgl_ui creates at boot.
//
// Once ui_event.h exists, swap this block for `#include "ui_event.h"`.
// ────────────────────────────────────────────────────────────────────────────

typedef enum {
    UI_EVENT_CROWN_CW  = 1,
    UI_EVENT_CROWN_CCW = 2,
    // Additional UI events (touch, button) belong in ui_event.h, not here.
} ui_event_t;

extern QueueHandle_t g_ui_event_q;   // depth/payload owned by lvgl_ui

// ────────────────────────────────────────────────────────────────────────────
// Internal state
// ────────────────────────────────────────────────────────────────────────────

static pcnt_unit_handle_t    s_pcnt_unit    = NULL;
static pcnt_channel_handle_t s_pcnt_chan    = NULL;
static esp_timer_handle_t    s_drain_timer  = NULL;

static int  s_residue = 0;   // sub-detent accumulator (signed)
static int32_t  s_total_detents = 0;
static uint32_t s_cw_count      = 0;
static uint32_t s_ccw_count     = 0;
static uint32_t s_glitch_count  = 0;

static int64_t s_last_event_us  = 0;
static int64_t s_boot_guard_us  = 0;   // events suppressed until esp_timer_get_time() > this
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

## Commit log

2026-05-30 Big Kompic Mk1 release! First KiCad 10 SCH and PCB files available. Including production files, information about parts and placement, as well as a Reflow guide.
    [1_ESP32-S3_Wroom.kicad_sch, 2_Power_Managment.kicad_sch, 3_Space_Time_Sensors.kicad_sch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]
2026-06-01 BIG CHANGE: Had bad wiring for the AMOLED, had to redo the schematic and complete routing of PCB (iv7.1). Added Arduino sketch for verifying AMOLED. Added newly redone pinout for both ESP32-S3 and th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
    [1_ESP32-S3_Wroom.kicad_sch, 6_PCB2_Skin_Sensors_LRA.kicad_sch]
2026-06-01 Fabrication page live! Updated all KiCad 10 files to final form. First fabrication+aseembly is on the way!
    [Kompic_Mk1_iv7.0_bom.csv, Kompic_Mk1_iv7.0_designators.csv, Kompic_Mk1_iv7.0_positions.csv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]
2026-06-02 Added Circuit page! Minor touchups to schematic + Schematic PDF.
    [1_ESP32-S3_Wroom.kicad_sch, 2_Power_Managment.kicad_sch, 3_Space_Time_Sensors.kicad_sch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]
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2026-06-03 Fixed ML651 -> ML621 battery name.
    [Kompic_Mk1_iv7.1_bom.csv]
2026-06-10 [CO5300] Porting: AMOLED display driver, iv7.2.f0.0, 5 issues noted
    - Hardware spec extracted from v7.2 (DISPLAY section + GPIO quick pinout)
    - Driver skeleton: full register map, SPI framing for both 0x02 (1-wire
    instruction) and 0x32 (QIO pixel) paths, init sequence, sleep/wake.
    - Test harness: chip identity, init, status read, DISPON, brightness 50/100,
    sleep/wake, single-pixel QIO push, heap accounting, all timed via
    esp_timer_get_time().
    - Profiling: TBD pending hardware. Wire-time floor at 40 MHz QSPI is ~123 ms
    per full frame -- documented as the load-bearing perf number.
    - [DEFECT-001] WHO_AM_I semantics unverified; co5300_get_status stubbed.
    - [DEFECT-002] TE pin (GPIO45) fi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
2026-06-10 [CST9217] Porting: capacitive touch driver, iv7.2.f0.0, 5 issues noted
    - New custom component (no esp_lcd_touch_cst9217 managed package exists).
    - ISR-driven path: GPIO6 falling-edge -> task notify -> burst read at 0xD000
    under g_i2c_mutex -> xQueueOverwrite(g_touch_q, &point). No broker round-trip
    (Blueprint 4 §6 lock-free fast path).
    - Probe ACK 0xAB at 0xD000 doubles as WHO_AM_I.
    - 16-bit register address (MSB first) -- the protocol change vs CST816.
    - RST pulse on GPIO44 (5 ms low / 50 ms high, datasheet TBD).
    - Test harness: I2C bus init, sync probe + raw report dump, 30 s ISR loop
    with per-event task-to-queue dt, heap + stack accounting.
    - Profiling: TBD pending hardware. Wire-t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
    [cst9217.c]
2026-06-10 [PCF85063] Porting: RTC audit + alarm INT + tile resize, iv7.2.f0.0, 5 issues noted
    - Audited carried-forward driver against v7.2 + Blueprint 8 §2 (UTC-only).
    Time read/write/sync/broker paths unchanged. Sakamoto DoW kept in lieu of
    glibc timegm() (see [DEFECT-001] / Open Q1).
    - New hardware alarm path on GPIO15: pcf85063_set_alarm / clear_alarm /
    clear_alarm_flag / install_alarm_isr. AIE in CTRL_2 bit 7, AF in bit 6,
    per-field AEN masking for daily H/M/S alarms. ISR is IRAM, notify-only.
    Orthogonal to components/alarm/ (software alarm UX is unchanged).
    - rtc_tile.c resized from 240x240 to 410x502 (CO5300). Named constants at
    the top of rtc_tile_init for the next reshuffle.
    - Te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
    [pcf85063.c]
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2026-06-10 [BQ25619] Porting: charger + battery driver, iv7.2.f0.0, 6 issues noted
    - New custom component (no managed package). I2C bus 2 @ 0x6A.
    - Register map [DSV-tagged] follows BQ256xx family convention; bench
    bring-up confirms each address against TI SLUSDH8 / SLUSDS3.
    - broker_battery_data_t lives here (Blueprint 4 §2). Preserves
    voltage/percentage/charging field names so existing consumers
    (lvgl_ui/system_tile, ui_main_screen) build unchanged. Adds
    charge_state, fault, boost_enabled, power_good.
    - SoC: voltage LUT (11-point, concave LiPo discharge model) + a
    self-learning observation hook (stub today, ABI-stable; full
    algorithm deferred to a Phase 1.5 follow-up).
    - bq25619_set_boos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
    [bq25619.c]
2026-06-10 [BootPower] Porting: GPIO16 button + DRV_EN + ship-mode, iv7.2.f0.0, 5 issues noted
    - Rewrite of boot_power.{c,h} for v7.2 design. Old GPIO40 button + GPIO41
    latch are dead (those pins are flashlight + SD now). New design: GPIO16
    ISR-driven button + GPIO0 DRV_EN strap + BQ25619 BATFET_DIS for shutdown.
    - boot_power_init(): drives GPIO0 LOW, configures GPIO16 input + pull-up,
    PSRAM sanity check.
    - task_power_btn_fn (was task_power_monitor + task_boot_button, merged):
    - Falling-edge ISR -> task notify -> 15 ms debounce -> 50 ms poll loop.
    - Hold >= 2.5 s -> g_show_shutdown_overlay = true.
    - Hold >= 3.0 s -> bq25619_enter_ship_mode() + g_shutdown_latched.
    - Release < 800 m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
    [boot_power.c]
2026-06-11 [LSM6DSV16X] Porting: ST 6-axis IMU driver, iv7.2.f0.0, 6 issues noted
    - New lsm6dsv16x.{c,h} replaces qmi8658.{c,h} (DELETED).
    - WHO_AM_I = 0x70 at REG 0x0F (was QMI8658's 0x05).
    - Register map per ST DS13176 [DSV-tagged]; bench bring-up confirms.
    - Scaling: 8192 LSB/g accel (datasheet), 14.286 LSB/dps gyro
    (+/-2000 dps), 256 LSB/C temp + 25C offset.
    - Complementary filter math carries forward verbatim from qmi8658.c.
    - broker_imu_data_t shape preserved field-for-field -- haptic.c
    (accel_z resonance) and imu_tile.c build unchanged.
    - imu_tile.c: literal "QMI8658C" / "6-axis IMU" replaced with
    identity calls; layout rescaled from 240x280 to 410x502.
    - lsm6dsv16x_install_int1_isr(): GPI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
    [lsm6dsv16x.c]
2026-06-11 [LIS3MDLTR] Porting: ST magnetometer driver + LRA offset, iv7.2.f0.0, 6 issues noted
    - New lis3mdl.{c,h} replaces qmc5883p.{c,h} (DELETED).
    - WHO_AM_I = 0x3D at REG 0x0F.
    - Register map per ST DM00075867 [DSV]; auto-increment bit 0x80 ORed
    into sub-address for burst reads (most common LIS3MDL footgun).
    - Configured: continuous mode, 10 Hz, +/-4 G, UHP X/Y/Z, BDU.
    - Sensitivity 68.42 LSB/uT (= 6842 LSB/G at +/-4 G FS).
    - broker_mag_data_t shape preserved field-for-field; compass_tile.c
    builds with only an include + identity-call swap.
    - Hard-iron sweep calibration carried forward verbatim from qmc5883p.c.
    - NEW: lis3mdl_measure_lra_offset() -- 20 samples over ~1 s, average.
    Characterise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
    [lis3mdl.c]
2026-06-11 [VEML6030] Porting: Vishay ambient light driver, iv7.2.f0.0, 6 issues noted
    - New veml6030.{c,h} replaces bh1750.{c,h} (DELETED). I2C bus 1 @ 0x10.
    - 16-bit register protocol (LSB first); register addresses per Vishay
    84366 [DSV-tagged].
    - Auto-ranging state machine: starts at gain=1/4x IT=100 ms (max
    ~15.1 klux). Steps down to 1/8x on saturation, up to 1x / 2x on
    underflow. One sample skipped after each range change.
    - Resolution table veml6030_resolution_lx_per_count[4][6] from
    Vishay AN84367 Table 5.
    - broker_light_data_t shape preserved field-for-field; light_tile.c
    builds with only an include + 3 identity-call swaps.
    - New: veml6030_lux_to_brightness() -- clamped log10 mapping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
    [veml6030.c]
2026-06-11 [MAX-M10S] Porting: u-blox GNSS receiver, iv7.2.f0.0, 6 issues noted
    - New max_m10s.{c,h} replaces tu10f.{c,h} (DELETED). UART1 9600 baud,
    TX=17 RX=18, 1PPS=GPIO46.
    - UBX-NAV-TIMEUTC parser (class 0x01, id 0x21) -- atomic UTC time
    WITHOUT waiting for position fix. Validates chip-side validUTC flag
    before committing.
    - UART demux: byte-by-byte routing between NMEA line discipline and
    UBX state machine on the same UART stream.
    - 1PPS rising-edge IRAM ISR on GPIO46: count + esp_timer_get_time()
    timestamp. gpio_isr_service install is idempotent across siblings.
    - broker_gps_data_t shape preserved field-for-field; gps_tile.c builds
    with only include + 3 identity-call swaps.
    - RTC seed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
    [max_m10s.c]
2026-06-11 [BME688] Porting: Bosch env + gas sensor, iv7.2.f0.0, 6 issues noted
    - New bme688_drv.{c,h} replaces bme280_drv.{c,h} (DELETED). I2C bus 1
    @ 0x76, chip_id = 0x61.
    - Bosch BME68x sensor API pulled as managed component
    (boschsensortec/bme68x_sensor_api ^4.4.8 via idf_component.yml).
    - Heater profile: 320 C / 150 ms (single set-point, VOC sniffing).
    Full forced-mode cycle ~200 ms wall time -- mutex held for the whole
    duration (see [DEFECT-002]).
    - broker_env_data_t shape preserved field-for-field; gas_resistance_ohm
    + gas_valid now actually populated.
    - env_tile.c: include + identity-call swap.
    - CMakeLists drops phantom bme280.c reference.
    - Test harness: I2C init, chip-id probe, 5 f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
    [bme688_drv.c, env_tile.c]
2026-06-11 [MAX30101] Porting: Maxim HR/SpO2/PPG driver, iv7.2.f0.0, 6 issues noted
    - New max30101.{c,h} replaces max30102.{c,h} (DELETED). I2C bus 1
    @ 0x57, INT pin GPIO7.
    - Register-compatible swap: same Part ID (0x15), same FIFO layout,
    same SpO2 mode. All Phase 14/15 fixes from the legacy driver
    (empty-FIFO watchdog, FIFO settle delay, shutdown readback, P0
    read-before-write) carry forward verbatim.
    - New: LED3 (green) channel exposed at REG 0x0E. Phase 3 stays in
    SpO2 mode with Green PA=0; max30101_setup_multi_led_mode() is
    exposed for Phase 4+ PPG work.
    - New: INT ISR on GPIO7 -- falling-edge, IRAM, count + task notify.
    Plumbing for wake-on-FIFO during sleep is in place; sleep-mode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
    [max30101.c]
2026-06-11 [TMP117] Porting: TI skin-temp driver, iv7.2.f0.0, 6 issues noted
    - New components/tmp117/ component (new chip, no legacy carryforward).
    I2C bus 1 @ 0x48. DEVICE_ID low-12 = 0x117.
    - 16-bit register read, MSB first. Two's complement raw / 128.0 -> C.
    - 5 s polling task at low priority -- skin temp changes slowly.
    - New broker channel: broker_skin_data_t (skin_temp_c, valid, enabled,
    last_update_ms). BROKER_SKIN_TIMEOUT_MS = 15 s.
    - DEVICE_ID mismatch -> warning, not hard-fail (TMP117 is single-SKU
    family; mismatch usually means wrong I2C addr, not wrong chip).
    - broker_skin_* proxy API NOT yet declared in data_broker.{c,h};
    follow-up commit needed (see [DEFECT-002]).
    - Master prompt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
    [tmp117.c]
2026-06-12 [DRV2605] Porting: haptic driver bus-1 -> bus-2, iv7.2.f0.0, 6 issues noted
    - Chip-layer unchanged (same TI DRV2605 clone, same Apple Taptic LRA).
    - haptic.c: g_i2c_mutex -> g_i2c2_mutex (10 sites), I2C_NUM_0 ->
    I2C_NUM_1 (12 sites). Mk I puts haptic on its own I2C bus to keep
    100-200 ms sweep bursts off the sensor crowd on bus 1.
    - drv2605.c: zero edits; the chip layer is bus-agnostic.
    - drv2605.h: docstring interface line updated for bus 2.
    - haptic_tile.{c,h}: zero edits (Core 1 / LVGL only).
    - broker_haptic_data_t: unchanged.
    - DRV_EN (GPIO0) ownership stays with boot_power.c (not touched here).
    Test harness configures GPIO0 directly so bench-bring-up works
    before boot_power land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
    [drv2605.c]
2026-06-12 [CrownEncoder] Porting: PCNT quadrature input, iv7.2.f0.0, 6 issues noted
    - New components/encoder/ component (new input device, no carryforward).
    PCNT-based quadrature decode on GPIO21 (A) / GPIO43 (B).
    - Drain strategy: 5 ms esp_timer reads + clears PCNT, accumulates
    signed residue, divides by ENCODER_STEPS_PER_DETENT (4 for x4
    quadrature), emits one CW/CCW event per detent.
    - Glitch filter: 12.5 us hardware (1000 APB cycles @ 80 MHz).
    - Debounce: 2 ms software window after each fired event, suppressed
    events counted as glitches.
    - Boot guard: 200 ms after init swallow drained detents -- absorbs
    the v7.2 GPIO43 boot-log TX ~3 ms spurious activity.
    - Events go to g_ui_event_q (for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
    [encoder.c]
2026-06-12 [WS2812] Porting: single-pixel status LED, iv7.2.f0.0, 6 issues noted
    - New components/ws2812/ component (new output device).
    RMT TX on GPIO42 at 10 MHz; 0/1-bit symbols 4/8 ticks (0.4/0.8 us)
    inside WS2812B +/- 150 ns spec. GRB wire order, 1 pixel.
    - 5-state animation machine: OFF / IDLE (dim white) / CHARGING
    (sinusoidal blue 1 Hz) / CHARGED (steady green) / ALERT (red square
    2 Hz). 50 ms esp_timer tick drives the animations.
    - ws2812_set_color(r,g,b) sets manual override flag; the animation
    tick early-exits until ws2812_set_state() clears it.
    - WS2812_WHITE macro capped at half intensity (0x808080) -- full
    white on a 1-pixel status LED is genuinely blinding.
    - Color macros: RG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
    [ws2812.c]
2026-06-12 [Flashlight] Porting: LEDC PWM flashlight driver, iv7.2.f0.0, 6 issues noted
    - New components/flashlight/ component. LEDC timer 0 channel 0 on
    GPIO41, 1 kHz / 8-bit. 1 kHz is above flicker fusion and below
    audibility.
    - API: flashlight_init / set_brightness(0..100) / on / off / get_brightness.
    - Implicit init on first set_brightness call -- the flashlight tile
    doesn't need to coordinate init ordering.
    - Linear pct -> duty mapping (no gamma); LEDs in this regime are
    approximately linear in perception.
    - Migration note: v5 GPIO41 was the system power latch. On Mk I it
    is the flashlight. boot_power.c MUST be reviewed to ensure it no
    longer drives GPIO41 ([DEFECT-001]).
    - No FreeRTOS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
    [flashlight.c]
2026-06-12 [SDCard] Porting: SDMMC 1-bit + FatFS storage, iv7.2.f0.0, 7 issues noted
    - New components/sdcard/ component (no v5 carryforward). SDMMC host
    on GPIO38/39/40 (CLK/CMD/DAT0). 1-bit mode -- DAT1-3 unrouted
    per v7.2. FatFS mount at /sd, 16 KiB allocation unit.
    - On-demand mount: sdcard_init() does only the mutex; sdcard_mount()
    spins the host. sdcard_unmount() parks the host between sessions
    for the power budget.
    - Session API: open_session(name) -> "/sd/<name>_NNNN.csv" with
    lowest-unused suffix; write/flush/close; one-shot helper.
    - Path safety: name_is_safe() whitelist on [A-Za-z0-9_]; rejects
    traversal attempts even though callers are internal.
    - No auto-format (silent reformat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
    [sdcard.c]
2026-06-12 [PDM_Mic] Porting: I2S0 PDM RX audio capture, iv7.2.f0.0, 6 issues noted
    - New components/mic_pdm/ component (no v5 carryforward). IDF v5
    i2s_pdm RX channel on I2S0; CLK=GPIO47, DIN=GPIO48 per v7.2.
    - Capture: 16 kHz, 16-bit signed, mono, LEFT slot (matches JP9=GND
    per v7.2 §SOLDER JUMPERS). 20 ms frame = 320 samples = 640 bytes.
    6 DMA frames in PSRAM = 120 ms total buffer.
    - API: _init / _deinit / _start / _stop / _is_running / _read /
    _capture (convenience: start-if-needed + read N frames + restore).
    - Capture-only -- no VAD, no Speex, no SNR estimate, no compression
    in this driver. Preprocessing lives in Phase 2+ modules.
    - Test harness: 50-frame (1 s) DC+peak+RMS analysis loop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
    [mic_pdm.c]
2026-06-12 [QvarECG] Porting: LSM6DSV16X Qvar ECG channel, iv7.2.f0.0, 7 issues noted
    - New components/qvar_ecg/ component (no v5 carryforward).
    Single-lead ECG via the LSM6DSV16X embedded Analog-Hub / Qvar
    channel. Shares I2C bus 1 + g_i2c_mutex with the IMU driver.
    - Enables CTRL7.AH_QVAR_EN + selects ZIN=235 MOhm (lowest impedance,
    best for pogo-pin skin contact). Read-before-write preserves any
    bits the IMU driver may have set in CTRL7 (Blueprint 4 §3).
    - API: _init / _deinit / _read_sample / _capture / _has_contact.
    Capture is 240 Hz polled (vTaskDelayUntil), drift-free.
    - Contact heuristic: 200 ms window, "majority of samples railed"
    -> no contact. Floating high-impedance Qvar input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
2026-06-13 [DataBroker] Porting: v7.2 chip headers + TMP117 skin slot, iv7.2.f0.0, 3 issues noted - Swapped 7 chip headers: tu10f→max_m10s, qmc5883p→lis3mdl, app_battery→bq25619, bh1750→veml6030, qmi8658→lsm6ds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
2026-06-13 [CrossDriver] Porting: v7.2 event catalogue, iv7.2.f0.0, 2 issues noted - Refreshed three chip-name comments (BME688/MAX30101/VEML6030). - Appended seven new event ordinals at the tail of the enum: S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
2026-06-13 [AppNVS] Porting: drop app_battery, drop esp_adc, iv7.2.f0.0, 2 issues noted - CMakeLists: dropped app_battery.c from SRCS (file gone) and dropped driver + esp_adc from REQUIRES (BQ25619 reads batter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
2026-06-13 [Fusion] Porting: BME688 baro altitude wired, iv7.2.f0.0, 2 issues noted - Activated the BME688 read path in task_fusion_fn — broker now exposes broker_env_read, the v5 stub block can land. - Removed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
2026-06-13 [Alarm] Porting: buzzer field → WS2812 LED strobe, iv7.2.f0.0, 3 issues noted - Renamed alarm_slot_t.buzzer → led_strobe. v7.2 GPIO42 is the WS2812 status LED (no piezo as in v5). NVS key "buzz" pres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
2026-06-13 [LvglUI] Porting: v7.2 tile registry + ECG stub tile, iv7.2.f0.0, 3 issues noted - tile_registry.c: header comment retargeted to the v7.2 part list (LIS3MDLTR, LSM6DSV16X, VEML6030, MAX-M10S, BME688,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
2026-06-13 [Phase6] Add trailing v7.2-compatible files missed in module commits The six Phase 6 module commits staged only files I had edited. These 29 remaining files are unchanged-from-v5-cp content that's al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
2026-06-13 [Build] Firmware scaffolding — project root, main task, partition table - firmware/CMakeLists.txt — top-level ESP-IDF project, name = smartwatch. - firmware/main/CMakeLists.txt + main.c + idf_compone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
    [partitions.csv]
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2026-06-14 [Docs] Phase 1 datasheet extracts (20.01–20.05) — Display + Touch + Core Five chip extracts complete: CO5300 AMOLED, CST9217 touch, ESP32-S3 MCU, PCF85063A RTC, TPS62840 buck. Each file follows the m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
2026-06-18 [Docs] Phase 2 datasheet extracts (20.06-20.10) — Sensors Bus 1 Part A Five chip extracts complete (VEML6030, LIS3MDLTR, MAX-M10S, TMP117, LSM6DSV16X) plus a companion file (20.10b) covering the LSM6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
2026-06-21 MASSIVE UPDATE: Built a working prototype with most systems go! iv7.1 requires about half a dozen surgical hacks on the PCB itself - it is suggested you wait for iv7.2+ - but otherwise, a massive suc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
    Stage 1-3 documents how the parts were added, in what fashion and then tested both electrically and with the scripts in test/ for each stage. SD Card may be unfixable in iv7.1.
    Added notes where the bugs are in the schematic, but haven't updated it.
    [1_ESP32-S3_Wroom.kicad_sch, 2_Power_Managment.kicad_sch, 3_Space_Time_Sensors.kicad_sch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]
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2026-07-14 Massive progress: Folder restructuring of firmware/ to harbor arduino sketches and the esp-idf main project. Working demos. Building notes in the 5-6 Stage reports.
    [Kompic_Mk1.kicad_pcb, partitions.csv]
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2026-08-26 hardware: Kompic Mk1 schematic edits + TDFN-8 footprint; Mk1b PCB start
    Mk1: LCSC parts refresh, ESP32-S3 sheet edits, project file bump,
    symbol library tweak, new TDFN-8 (2.0x2.0 P0.50 EP1.2) footprint +
    STEP + WRL for the sensor package used on Mk1b.
    Mk1b: fresh PCB project seeded from Mk1 with the AMOLED receptacle
    footprint mirror fix from Stage 16.
    [1_ESP32-S3_Wroom.kicad_sch, 2_Power_Managment.kicad_sch, 3_Space_Time_Sensors.kicad_sch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]
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2026-08-26 firmware: Stage 17 boot polish -- DRV last, cold-boot delay, boot buzz
    Reorder boot_hw_init so haptic_init() is the very last step, then
    queue two haptic_play_forced(DRV_STRONG_CLICK) as the "boot passed"
    signal. If the LRA fires, every step above ran clean.
    Cold-boot fix: DRV2605 auto-cal reports STATUS=0xEC (DIAG=FAIL,
    OVER_TEMP=1) at ~50 ms after DRV_EN goes high because the BEMF loop
    has not settled. Warm reboots pass because VDD never dropped. Add a
    2 s vTaskDelay before haptic_init() so cold boots settle before we
    poke GO=1.
    Eager telemetry init in main.c: call vbat_adc_ensure_init() and
    esp_ts_ensure_init() right after boot_hw_init() so their log lines
    land in the correct boot-order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
    [boot_hw_init.c, main.c]
2026-09-08 docs: Stage 18-21 build reports + battery aux + Mk1b imgs
    Stage 17 addendum, Stage 18 (log audit + PCF fix + LVGL tile spec + wrist
    gesture + Mk1b delta), Stage 19 (power refinement, deferred pre-trip),
    Stage 20 (button responsiveness + BQ ship-mode timing), Stage 21 (screen
    bring-up prep for Mk1b arrival). Battery analyser groups by fw= tag;
    frozen profile at fw=0.4.24. ECG-sync notebooks + Mk1b PCB imagery.
2026-09-08 firmware: Stage 18-20 polish -- RGB policy, log audit, wrist gesture, ship-mode timing
    Accumulated across three stages while I skipped commits:
    - rgb_policy new component (background LED ladder; pause/resume for modes)
    - Log-level audit: per-tick statuses -> DEBUG, milestones stay INFO
    - PCF85063 mutex 50->300 ms; expected-contention log demoted to DEBUG
    - LSM6DSV wrist-gesture LPF on accel-Z + hysteresis + broker publish
    (polarity flipped for bench prototype in 0.4.24)
    - ws2812 tx mutex fix (RMT race: rgb_policy vs field_capture)
    - ws2812 skip-repeat colour cache (rgb_policy paints once, stays silent)
    - Stage 20: press-edge haptic in button_poll (fc_common.c)
    - Stage 20: shutdown watcher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
    [bq25619.c, drv2605.c, field_capture.c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]
2026-09-08 firmware: uptime cap keeps charging + activity kick + provenance banners (fw 0.4.18)
    Shutdown watcher (fc_shutdown.c + fc_internal.h + fc_common.c):
    - Uptime cap no longer stops charging while USB is plugged.
    watcher_ship_mode() is skipped when broker_battery_read().power_good
    is true. Any live recording is still aborted and the deadline
    re-arms; BATFET stays enabled, charging continues until unplug.
    - New shutdown_watcher_kick() public function. button_poll() calls
    it on the fresh-press edge; encoder_delta() calls it on a confirmed
    detent emit. Any confirmed user input postpones the 15-min uptime
    cap by one full window, so the cap only fires on true idle.
    Boot-time provenance b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
    [bme688_drv.c, boot_hw_init.c, boot_power.c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]
2026-09-08 firmware: Stage 21 §4.1a redo + silent-probe log lines (fw 0.4.19)
    Stage 21 §4.1a redo (restored from reset-away commit 4f78a24):
    - co5300.c: real QSPI plumbing per 15_amoled_touch_test.ino (manual CS,
    half-duplex, 40 MHz, instruction frame 0x02, pixel frame 0x32,
    reset 50/200/300 ms, full init sequence). set_brightness / set_window
    do real work. Plus 'driver v0.2.0' banner.
    - boot_display.{c,h} (new): CST9217 I2C probe as presence proxy
    (0xAB @ 0xD000 on bus 0). On iv7.1 the probe NAKs, panel init is
    skipped, boot continues headless. On Mk1b the probe succeeds and
    co5300_init runs. backlight_set_brightness() migrates here from
    boot_hw_init.c and forwards to real WRDISBV regi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
    [boot_display.c, boot_hw_init.c, main.c]
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2026-09-17 firmware: Stage 30 close + Stage 31 plan checkpoint (fw 0.4.75)
    Stage 30 shipped: esp_lvgl_port + PARTIAL refresh restored, sleep-race
    mutex, AUTOSHDN CLI+NVS, NVS dump verb, FLASH bypass verb, landscape
    + Mode HUD deferred to Stage 31 per foundations-rebuild plan.
    Stage docs 24-30 landed (Mk1b bring-up through display port migration),
    Stage 31 (LVGL foundations rebuild plan) and Stage 34 (naming + CLI
    restructure) opened. LOG.md + LOG_TAGS.md loose-ends surfaces added.
    Component surgery in this checkpoint:
    - co5300 split: co5300.c -> co5300_panel.{c,h} + co5300_panel_io.{c,h}
    - qvar_ecg deleted (NO ECG on Kompic)
    - max17048 new component (fuel gauge on Mk1b)
    - *_cmd.c extracts lan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
    [3_Space_Time_Sensors.kicad_sch, Kompic_Mk1b.kicad_pcb]
2026-09-22 Final firmware changes; GPS hardware fixing and arduino sketches (18, 19); Started progress on migrating to LVGL 9 optimized architecture.
    [3_Space_Time_Sensors.kicad_sch, Kompic_Mk1b.kicad_pcb, Kompic_Mk1b_PCB_ONLY.stl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]
2026-09-26 Sort of fixed GPS, but we need a whole new refactoring run.
    [max_m10s.c]
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2026-09-27 Stage 35 close + Stage 36 GPS debug prompt
    Fill §9 bench log (0.4.89 / 0.4.90 / 0.4.91), flip status to CLOSED.
    Open Stage_36_Mk1b_GPS_Signal_Debug_PROMPT.md with symptoms +
    analysis + fresh-session copy-paste prompt for the follow-up
    GPS_PING + low-SNR investigation.
